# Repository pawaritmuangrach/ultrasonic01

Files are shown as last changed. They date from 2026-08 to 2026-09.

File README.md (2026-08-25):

# Ultrasonic 40 kHz TDOA — จากต้นแบบ 1 TX + 2 RX สู่ Array แทน LiDAR

หลักการและที่มาของสูตรทั้งหมดอยู่ใน [`US015_TDOA_Codex_Spec.md`](US015_TDOA_Codex_Spec.md) เอกสารนี้สรุปเฉพาะสิ่งที่จำเป็นต่อการต่อวงจร รัน และตีความผลลัพธ์

หัวข้อ 1-6 คือต้นแบบเริ่มต้น (1 TX + 2 RX บน Arduino Nano) ที่ build/upload/ทดสอบจริงแล้ว — ถ้าต้องการภาพรวม
การออกแบบขั้นสูงขึ้น (Y-array, MIMO, ทำไม phased array ใช้ไม่ได้, เปรียบเทียบ Nano/ESP32) ข้ามไปหัวข้อ
**[7. จากต้นแบบ TDOA สู่การออกแบบ Ultrasonic Array เต็มรูปแบบ](#7-จากต้นแบบ-tdoa-สู่การออกแบบ-ultrasonic-array-เต็มรูปแบบ-y-array--mimo)** ได้เลย

## 1. Wiring

```
US-015 board 1 (มีตัวส่ง T และตัวรับ R1)
  VCC  -> 5V
  GND  -> GND
  TRIG -> Nano A2
  ECHO -> Nano A0

US-015 board 2 (ถอด/ปิดหัวส่ง ใช้เฉพาะตัวรับ R2)
  VCC  -> 5V
  GND  -> GND
  TRIG -> Nano A2   (สาย TRIG ต่อร่วมกับบอร์ด 1)
  ECHO -> Nano A1
```

A0/A1/A2 ถูกใช้เป็นขา **digital** ล้วน (PC0/PC1/PC2) ไม่มีการเรียก `analogRead()` กับ ECHO เพราะ ECHO เป็นสัญญาณ LOW/HIGH ไม่ใช่ waveform 40 kHz จริง

### 1.1 กรณีใช้ทรานสดิวเซอร์ดิบ (ไม่มี comparator ในตัว)

ถ้าฮาร์ดแวร์ของคุณเป็นทรานสดิวเซอร์ดิบต่อตรงเข้า A0/A1 (ไม่ใช่โมดูล US-015/HC-SR04 สำเร็จรูปที่มีวงจรขยาย+comparator ในตัว) **จะใช้งานไม่ได้** เพราะสัญญาณจาก piezo รับเป็น AC ระดับ mV เท่านั้น ขา digital input จะไม่เห็น echo จริง ต้องเพิ่มวงจร analog front-end ต่อหน้า A0/A1 แต่ละช่อง ประกอบด้วย 4 สเตจ (ทรานซิสเตอร์ NPN ทั่วไป 4 ตัว/ช่อง):

1. ขยายสัญญาณ 2 สเตจ (common-emitter amplifier, AC-coupled)
2. Envelope detector (ใช้ขา Base-Emitter ของทรานซิสเตอร์อีกตัวแทนไดโอด + ตัวเก็บประจุ)
3. Threshold switch (ทรานซิสเตอร์อีกตัวทำหน้าที่เทียบระดับแทน comparator IC)

วงจรนี้ **output จะ idle ที่ HIGH แล้วลง LOW เมื่อพบสัญญาณ** (กลับด้านกับโมดูลสำเร็จรูป) โค้ดมี flag `ECHO_ACTIVE_LOW` (ตั้งเป็น 1 ไว้แล้วในไฟล์ .ino) เพื่อรองรับ polarity แบบนี้ — ถ้าเปลี่ยนไปใช้โมดูลสำเร็จรูปจริงในอนาคต ให้ตั้งกลับเป็น 0

แนะนำจัดวางแบบสมมาตรสำหรับ calibrate:

```
R1        T        R2
|---------|---------|
      แผ่นสะท้อนเรียบ 30-50 cm ด้านหน้า
```

## 2. Flash และเปิด Serial

1. เปิด `ultrasonic_tdoa_nano/ultrasonic_tdoa_nano.ino` ด้วย Arduino IDE, เลือกบอร์ด "Arduino Nano" / processor ATmega328P (เก่า ถ้า upload ไม่ผ่านให้ลอง "ATmega328P (Old Bootloader)")
2. Upload
3. เปิด Serial Monitor/Serial Plotter ที่ **115200 baud** — หรือใช้หน้าเว็บ simulation ใน `simulation/index.html` แทน (ดูหัวข้อ 6)

ค่าเริ่มต้นของ output คือ **CSV** (ส่ง `s` ทาง Serial เพื่อสลับเป็น human-readable)

Header ของ CSV:

```
timestamp_ms,r1_pulse_us,r2_pulse_us,r1_cm,r2_cm,raw_dt_us,calibrated_dt_us,path_diff_cm,angle_deg,confidence,status,cycle_shift
```

ตัวอย่างบรรทัดข้อมูล:

```
1250,212.5,230.5,3.64,3.95,18.0,18.0,0.617,7.10,91,VALID,0
```

Human-readable (หลังส่ง `s`):

```
R1=212.5us 3.64cm | R2=230.5us 3.95cm | raw_dt=18.0us | calibrated_dt=18.0us | path=0.617cm | angle=7.10deg | confidence=91 | status=VALID | cycle_shift=0
```

## 3. Serial Commands

| คำสั่ง | ผลลัพธ์ |
|---|---|
| `c` | เริ่ม calibration (เก็บ ~200 samples แล้วหา median offset ของ raw dt) — **ต้องวางอุปกรณ์สมมาตรตามรูปด้านบนก่อนส่งคำสั่งนี้** |
| `p` | พิมพ์ parameters ปัจจุบัน (sound speed, spacing, offset, output mode) |
| `r` | ล้าง median-filter / cycle-slip history |
| `s` | สลับ CSV <-> human-readable |
| `t25` | ตั้งอุณหภูมิ 25 °C แล้วคำนวณความเร็วเสียงใหม่ |
| `d5.0` | ตั้ง receiver spacing เป็น 5.0 cm |

## 4. สมการหลัก

```
pulse_us          = fall_tick - rise_tick   (Timer1, 0.5 us/tick)
distance_cm       = pulse_us * c / 2                      (ระยะแบบ pulse-echo ปกติ)
raw_dt_us         = pulse2_us - pulse1_us
calibrated_dt_us  = raw_dt_us - calibration_offset_us      (+ cycle-slip correction)
path_diff_cm      = calibrated_dt_us * c                   (ไม่หาร 2 เพราะเทียบเส้นทางถึงตัวรับสองตัว)
max_dt_us         = receiver_spacing_cm / c                 (ขอบเขตทางฟิสิกส์)
angle_deg         = asin(path_diff_cm / receiver_spacing_cm) * 180/pi   (เฉพาะเมื่อ status == VALID)
```

`c = 0.0343 cm/us` ที่อุณหภูมิห้อง (ปรับได้ด้วยคำสั่ง `t<celsius>`)

## 5. ข้อจำกัดสำคัญ (อ่านก่อนเชื่อผลลัพธ์)

1. US-015 เป็น black-box — ECHO ที่เห็นคือผลหลัง comparator/threshold ภายในโมดูล ไม่ใช่ raw 40 kHz waveform
2. `raw_dt_us` **ไม่รับประกัน** ว่าเท่ากับส่วนต่างเวลาที่คลื่นมาถึงจริง เพราะแต่ละบอร์ดมี internal delay/threshold ไม่เท่ากัน — ต้อง calibrate (`c`) ก่อนเสมอ
3. Calibration ลบ static offset ได้ แต่ลบ dynamic jitter ไม่ได้ทั้งหมด
4. `cycle_shift != 0` แปลว่าเกิด cycle-slip correction (ค่ากระโดดเป็นทวีคูณของ 25 us) — เป็น heuristic ไม่ใช่การพิสูจน์
5. `angle_deg` ใช้สมมติฐาน far-field / plane-wave ถ้าวัตถุอยู่ใกล้มาก มุมนี้จะไม่แม่น
6. ผลลัพธ์ทั้งหมดควรเรียกว่า **pseudo-TDOA** ไม่ใช่ true TDOA จนกว่าจะเข้าถึง raw receiver signal ได้จริง (ดูหัวข้อ 27 ในสเปก)
7. ไม่ควรใช้ระบบนี้ในงาน safety-critical

## 6. Real-time 2D wave simulation

`simulation/index.html` เป็นหน้าเว็บ (self-contained, ไม่ต้องติดตั้งอะไร) ที่:

- ต่อกับ Arduino ผ่าน **Web Serial API** (Chrome/Edge เท่านั้น) ที่ 115200 baud
- อ่านบรรทัด CSV ทีละแถว แล้ววาดภาพ 2D: ตำแหน่ง T/R1/R2, คลื่นวงกลมที่ขยายตัวออกจาก T ไปกระทบวัตถุ (คำนวณตำแหน่งวัตถุจาก r1_cm และระยะ target->R2 ที่แปลงจาก r2_pulse_us) แล้วมีคลื่นสะท้อนกลับไปหา R1 และ R2 พร้อม timing สัมพัทธ์ตามข้อมูลจริง (สโลว์โมชันเพื่อให้ตามองเห็น)
- มีปุ่ม **Demo mode** สำหรับดูตัวอย่างการทำงานโดยไม่ต้องต่อ Arduino จริง
- **สะสมจุดสะท้อนทุกจุดที่ตรวจพบ** (ไม่ใช่แค่ ping ล่าสุด) เป็นแผนที่จุดสีชมพูบานเย็น (magenta point cloud) คล้าย
  scatter plot ของ SLAM map — จุดที่วัดได้ต่อเนื่องกันและอยู่ใกล้กัน (<15 cm) จะมีเส้นเชื่อมให้ดูเป็นขอบวัตถุ/กำแพงคร่าวๆ
  เอาเมาส์ชี้จุดใดก็ได้เพื่อดูระยะ/มุม/confidence ของจุดนั้น มีปุ่ม "Clear Map" และ "Export Map (CSV)"
  หมายเหตุ: เซนเซอร์ชุดนี้ไม่ได้หมุนสแกนแบบ lidar การจะได้แผนที่ห้องเต็มรูปแบบต้องเลื่อน/หมุนวัตถุหรือตัวเซนเซอร์เอง
  แล้วเก็บผลสะสมไว้ (เหมาะกับ Experiment 4 ในสเปก)

วิธีใช้:

1. อัปโหลดโค้ดลง Arduino Nano และปิด Serial Monitor ใน Arduino IDE ก่อน (พอร์ตใช้ได้ทีละโปรแกรม)
2. เปิด `simulation/index.html` ด้วย **Chrome หรือ Edge** (ดับเบิลคลิกเปิดไฟล์ได้เลย ไม่ต้องมี server)
3. กดปุ่ม "Connect Arduino" แล้วเลือกพอร์ต COM ของ Nano
4. ดูคลื่นวิ่งแบบ real-time ทุกครั้งที่ Arduino ยิงคลื่นออกไป

ถ้าต้องการดูตัวอย่างก่อนต่อฮาร์ดแวร์จริง ให้กด "Demo mode (no hardware)" แทน

---

## 7. จากต้นแบบ TDOA สู่การออกแบบ Ultrasonic Array เต็มรูปแบบ (Y-array + MIMO)

หัวข้อ 1-6 ด้านบนคือต้นแบบเริ่มต้น (1 TX + 2 RX, US-015/front-end แบบ discrete transistor) ต่อมาโปรเจกต์ขยายเป้าหมาย
เป็น **ใช้ ultrasonic array แทน LiDAR** สำหรับ obstacle avoidance ระยะใกล้ (เทรน NN โดยใช้กล้องเป็น ground truth)
หัวข้อนี้สรุปข้อค้นพบและการออกแบบที่ได้จากการสำรวจแนวทางต่างๆ

### 7.1 ทำไมตัวส่งหลายตัว + ตัวรับตัวเดียว (phased array) ใช้ไม่ได้

แนวคิดแรกที่พิจารณาคือใช้ตัวส่งหลายตัวรวมคลื่นเป็นลำแคบแล้วกวาดทิศทาง (transmit beam steering) แต่พบข้อจำกัดทาง
ฟิสิกส์ที่แก้ไม่ได้:

- ที่ 40kHz, c=343 m/s → ความยาวคลื่น **λ ≈ 8.575mm** → ต้องวางตัวส่งห่างกันไม่เกิน **λ/2 ≈ 4.3mm** ถึงจะไม่เกิด
  ลำคลื่นหลอก (grating lobe)
- ทรานสดิวเซอร์ TCT40-16 มีตัวถังจริง **16mm** — ใหญ่กว่าที่ต้องการเกือบ 4 เท่า และไม่มีทางวางให้ใกล้กว่านี้ได้
  เพราะเป็นขนาดจริงของอุปกรณ์ในอากาศ
- ทดสอบด้วยการจำลอง (`simulation/beamforming_compare.html`) ยืนยันว่าที่ระยะ 16mm ยิงพร้อมกันเกิดลำคลื่นแรง
  พร้อมกัน **3 ทิศ** (-32°, 0°, 32°) และถ้าพยายาม steer ไป 20° ด้วยการหน่วงเวลา จะยิ่งแย่ลงเป็น **4 ทิศ**
  (-47°, -11°, 20°, 61°)
- **ปัญหานี้แก้ด้วยซอฟต์แวร์ไม่ได้เลย** เพราะพลังงานเสียงกระจายผิดทิศไปแล้วตั้งแต่ในอากาศ ไม่ใช่ความผิดพลาดของ
  การประมวลผลสัญญาณ

สรุป: ตัวส่งหลายตัวยิงพร้อมกันเพื่อเล็งลำคลื่นไม่ใช่ทางที่ไปได้กับทรานสดิวเซอร์ขนาดนี้

### 7.2 ทางที่เลือกแทน: TDOA (วัดเวลา ไม่ใช่วัดเฟส)

แทนที่จะเล็งลำคลื่นตอนส่ง เปลี่ยนมายิงคลื่นกระจายกว้างครั้งเดียว แล้วใช้ **ตัวรับหลายตัว** ฟังพร้อมกัน คำนวณทิศทาง
จากผลต่างเวลาที่เสียงมาถึงแต่ละตัว (`sinθ = c·Δt/d`) สมการนี้มีคำตอบเดียวเสมอ (วัดเวลา ไม่ใช่เฟสที่วนซ้ำทุกคาบ)
จึง**ไม่มี grating lobe** — เป็นเหตุผลที่ต้นแบบในหัวข้อ 1-6 ใช้สถาปัตยกรรมนี้มาตั้งแต่แรก

กฎของ aperture ก็กลับด้านจาก phased array: ความละเอียดเชิงมุม `θ_res ≈ λ/D` → **ยิ่งตัวรับกระจายกว้าง (D ใหญ่)
ยิ่งแยกมุมได้ละเอียด** ตรงข้ามกับ phased array ที่ต้องการให้ชิดกัน

### 7.3 ขยายเพิ่มด้วย MIMO (coded TX หลายตัว)

ยิงตัวส่งหลายตัว**พร้อมกัน**โดยแต่ละตัวใช้ code ต่างกัน (แยกด้วย matched filter ฝั่งรับ) จะได้เส้นทางข้อมูล
(TX→วัตถุ→RX) แยกกันได้ = จำนวน TX × จำนวน RX (virtual array, ตำแหน่งเสมือน = ตำแหน่ง TXi + RXj) — ได้ข้อมูล
เพิ่มแบบ**ทวีคูณ**จากอุปกรณ์ที่เพิ่มแบบบวก และยังยิงครั้งเดียวจบเหมือนเดิม (ไม่ช้าลง เพราะยิงพร้อมกัน) ต่างจาก
การยิงตัวส่งทีละตัว (reciprocity ให้ข้อมูลเท่ากันแต่ช้ากว่า 6 เท่าและวงจรซับซ้อนกว่า จึงไม่คุ้ม)

### 7.4 ผังที่แนะนำ: Scaled Array — 3 TX + 9 RX (12 อุปกรณ์จริง, 27 เส้นทางเสมือน)

- **TX1-TX3**: กลุ่มสามเหลี่ยมเล็กกึ่งกลางแผง (รัศมี 14mm จากศูนย์กลาง — ห่างพอให้ตัวถัง 16mm ไม่ชนกัน)
- **RX1-RX9**: 3 แขนมุม 120° (แบบเดียวกับผัง VLA radio telescope เพื่อ sampling มุมสม่ำเสมอทุกทิศ) แขนละ 3 ตัว
  ที่ระยะ **40 / 80 / 140mm** (140mm คือตัวขยายใหม่จากเดิม 40/80mm)
- แต่ละแขนให้ทั้งข้อมูล azimuth (ซ้าย-ขวา) และ elevation (บน-ล่าง) พร้อมกัน
- Diminishing returns: ขยายรัศมี 40→60mm ได้ θ_res ดีขึ้น 2.05° แต่ขยาย 140→160mm ได้แค่ 0.22° (จึงหยุดที่ 140mm)
- Circuit BOM เต็มระบบ: TX driver (TC4427A) 3 ชุด, MCP6024 (quad op-amp, 2 RX/ชิป) 5 ชิป, วงจร VREF 2.5V 1 ชุด
  (ใช้ร่วมกันได้ทุกช่อง)

### 7.5 ข้อจำกัดของแพลตฟอร์มควบคุม (Nano / ESP32 / ESP32+ADS1115)

| แพลตฟอร์ม | RX สูงสุดที่ใส่ได้จริง | จับ raw chirp 40kHz ได้ไหม | MIMO coded TX |
|---|---|---|---|
| Arduino Nano | ≤6-7 (จาก 8 ขา A0-A7) | ไม่ได้ (ADC มัลติเพล็กซ์ช้าเกิน) → ใช้ envelope+threshold แทน | ไม่ไหว |
| ESP32 เดี่ยว | 8 (ADC1) | ได้ (DMA ~100-500kS/s) | ได้ 3 ตัวเต็มรูปแบบ |
| ESP32 + ADS1115 | 8 + 4 (I2C) | เฉพาะช่อง ESP32; ADS1115 ช้าเกิน (860 SPS) ใช้ได้แค่ envelope | ได้ 3 ตัว |

**สรุป**: ผัง 3TX+9RX เต็มรูปแบบต้องใช้ ESP32+ADS1115 แบบ hybrid (RX 8 ช่องแรกจับ raw waveform ผ่าน ESP32,
RX "far" 140mm ที่เหลือจับแค่ envelope ผ่าน ADS1115) — Nano ทำได้แค่ 1TX+6RX แบบ envelope เท่านั้น

### 7.6 เครื่องมือ visualization ทั้งหมด (self-contained, เปิดตรงจากไฟล์ได้)

| ไฟล์ | ใช้ทำอะไร |
|---|---|
| `simulation/index.html` | Real-time 2D wave + point-cloud map จากข้อมูล serial จริง (หัวข้อ 6) |
| `simulation/beamforming_compare.html` | เปรียบเทียบ interference pattern 2-TX ที่ระยะห่างต่างกัน (λ/2 vs 16mm vs steered) — ที่มาของข้อสรุปข้อ 7.1 |
| `simulation/sparse_array_layout.html` | ผัง L-shape sparse receiver บนโต๊ะ (สำหรับทดลองเก็บข้อมูล + กล้องเป็น ground truth) |
| `simulation/front_array_plate_layout.html` | ผังหน้าแผง Y-array รุ่นแรก (1 TX + 6 RX) พร้อม difference co-array |
| `simulation/mimo_virtual_array_layout.html` | สาธิต MIMO virtual array (3 TX + 4 RX ตัวอย่าง) เทียบกับผัง 1TX+6RX |
| `simulation/scaled_array_layout.html` | ผังสุดท้าย 3TX+9RX เต็มรูปแบบ + diminishing returns + เทียบ 3 แพลตฟอร์ม (7.4-7.5) |
| `diagnostics/r1_basic_test/r1_basic_test.ino` | สเก็ตช์ทดสอบเปล่า (`pulseIn()`) ใช้แยกว่าปัญหา R1 ค้างที่ 4.6cm เป็นที่ฮาร์ดแวร์ ไม่ใช่เฟิร์มแวร์ |

### 7.7 ข้อจำกัดที่ยังเหลืออยู่

**Cycle slip**: คลื่น 40kHz คาบ 25µs ถ้าวัดเวลาไม่แม่นพอ ระบบอาจสับสนว่าจับคลื่นลูกไหน (ค่ากระโดดเป็นก้อนละ ~25µs
— ปรากฏการณ์เดียวกับที่เจอจริงตอน calibrate ฮาร์ดแวร์ในหัวข้อ 2-3) ต่างจาก grating lobe ตรงที่**แก้ได้** ด้วย:

1. Chirp + Pulse Compression (แผนระยะยาว) — กวาดความถี่แทนโทนเดียว ทำให้วัดเวลาคมขึ้นมาก
2. วางตัวรับแบบ sparse/non-redundant — ความกำกวมของแต่ละคู่ตกคนละมุม ไม่ทับกัน
3. Neural Network + กล้องเป็น ground truth — เรียนรู้ล้างส่วนที่เหลือจากข้อมูลจริง

**ข้อจำกัดที่ต้องยอมรับ**: อัลตราโซนิกในอากาศไม่มีวันเทียบ LiDAR ได้ในเรื่องระยะไกล (สิบ-ร้อยเมตร) และความละเอียด
ระดับ mm — เป้าหมายที่สมจริงคือใช้แทนได้เฉพาะบริบท obstacle avoidance ระยะใกล้ (<5-10m) เท่านั้น

---

## 8. ESP32 build log — Stage 1

บันทึกสิ่งที่**วัดได้จริง**บนฮาร์ดแวร์ ไม่ใช่ค่าออกแบบ ทุกตัวเลขในหัวข้อนี้มาจากการวัดด้วย
`esp32_selftest.ino` + `tools/scope_view.py` บนบอร์ด ESP32-D0WD-V3 rev 301 ที่ COM5

### 8.1 สถานะ

| งาน | สถานะ |
|---|---|
| เครื่องมือ (arduino-cli, Python, scope_view) | ✅ |
| พิสูจน์ ADC ต่อเนื่อง 2 MS/s | ✅ |
| ภาคส่ง TX driver Version A | ✅ |
| **ภาครับ RX front-end 1 ช่อง** | ✅ |
| `esp32_scope.ino` (ยิง burst + เก็บคลื่น) | ✅ |
| เห็น echo หลายก้อนในหนึ่งช็อต | ✅ |
| ระยะเลื่อนตาม `t = 2d/c` เมื่อขยับแผ่นสะท้อน | ⬜ |

### 8.2 ADC ต่อเนื่อง — สมมติฐานที่เสี่ยงที่สุดของโปรเจกต์

ทั้งโครงการตั้งอยู่บนข้อสมมติว่า ESP32 สตรีม ADC1 ได้ระดับ MS/s ผลจริง:

| ขอ | ได้จริง | % |
|---|---|---|
| 1,000,000 S/s | 976,400 | 97.6% |
| 1,500,000 S/s | 1,464,200 | 97.6% |
| 2,000,000 S/s | 1,951,900 | 97.6% |

เปอร์เซ็นต์คงที่ทั้งสามค่า แปลว่าเป็น**ค่าโสหุ้ยคงที่ ไม่ใช่เพดาน** — แผน Stage 3
(6 ช่อง × 325 kS/s) จึงใช้ได้จริง

### 8.3 RX front-end — ผลวัดหลังแก้จนนิ่ง

โครงสร้าง: `TCT40-16R → Cin 100nF → 2 สเตจ non-inverting เกน 10.3/สเตจ → R 2.2k + C 1nF → GPIO34`
ไฟเลี้ยง 3.3V, VREF 1.65V จากตัวแบ่ง 10k/10k + บัฟเฟอร์

| ตัวชี้วัด | ค่าที่วัดได้ |
|---|---|
| จุดปฏิบัติการ DC ที่ขาออก | 1.521-1.523 V นิ่งทุกเฟรม |
| ฮัม 50 Hz ที่ขาออก | 3.5 mV |
| พื้นเสียงรบกวน 30-50 kHz | 3.2 mV ที่ขาออก = **30 µV ที่ขาเข้า** |
| จุดอิ่มตัว | 1167 mV rms = 11 mV ที่ขาเข้า |
| ช่วงไดนามิก | **51 dB** |
| ตัวอย่างที่ชนราง (16,000 ตัวอย่าง) | 0 |

> DC 1.52 V ไม่ใช่ความผิดพลาด — ADC ของ ESP32 อ่านต่ำกว่าจริงราว 7% ที่ช่วงกลางสเกล
> `1.65 × 0.923 = 1.523` ตรงกับที่วัดได้ ต้องคาลิเบรตก่อนใช้ค่าสัมบูรณ์

**ทดสอบตอบสนองอัลตราโซนิก** (เขย่าพวงกุญแจห่าง ~10 cm):

| | พลังงานย่าน 30-50 kHz |
|---|---|
| ห้องเงียบ | 3.2 mV |
| เขย่ากุญแจ | 337.4 mV (**105 เท่า**) |

หลักฐานที่หนักแน่นกว่าความแรงคือ**ความถี่**: กุญแจให้เสียงกว้าง แต่ยอดที่จับได้ทุกเฟรมตกอยู่ที่
36.07 / 37.31 / 37.33 / 37.35 / 38.00 / 38.04 / 38.07 / 40.70 kHz — เกาะกลุ่มในย่านเรโซแนนซ์
ของ TCT40 ทั้งหมด ถ้าเป็นเพียงสัญญาณรบกวน ยอดจะกระจายแบบสุ่มทั่วย่าน

### 8.4 ปัญหาที่เจอจริงและวิธีวินิจฉัย

บันทึกไว้เพราะทั้งสี่ข้อจะกลับมาอีกตอนขยายเป็น 6 ช่อง

| อาการ | สาเหตุจริง | วิธีที่ชี้ตัวได้ |
|---|---|---|
| ขาออกแกว่งเต็มราง 3.3 Vpp ที่ 50 Hz | **รางไฟบนบอร์ดทดลองถูกตัดขาดกลางแผ่น** ครึ่งล่าง (ตัวแบ่ง VREF, C 10µF, Cg, C_out, คาปาบายพาส) ไม่มีทั้งไฟและกราวด์ กลายเป็นเสาอากาศรับไฟบ้าน แล้ว C 10µF ป้อนเข้า VREF ตรงๆ | ย้ายสายวัดไปที่รางกราวด์เอง — อ่านได้ 0.556 V แกว่ง 3.3 Vpp ซึ่งเป็นไปไม่ได้ถ้าต่อถึงกราวด์จริง |
| แยกไม่ออกว่าวงจรเสียหรือสายวัดลอย | — | อ่านขาที่**ไม่ได้ต่ออะไรเลย** (GPIO36/39) เทียบ ได้ 22 mV เทียบกับ 2093 mV จึงยืนยันว่าวงจรสร้างสัญญาณจริง |
| ไม่รู้ว่าเป็นการแกว่งเองหรือรับจากภายนอก | ฮัมจากภายนอก | ดูค่าดิบ: 98.5% ของตัวอย่างเป็น 0 หรือ 4095 เป๊ะ ฮาร์มอนิก 49/146/244/342 Hz อัตราส่วน 1 : ⅓ : ⅕ : ⅐ = คลื่นสี่เหลี่ยมที่ถูกตัดยอด ไม่ใช่การแกว่งของ op-amp |
| ออปแอมป์ตัวที่ 4 ที่ไม่ได้ใช้ | ขา 12 (ขาออก) ต่อลงกราวด์ = ลัดวงจร ส่วนขา 13/14 ลอย | อินพุต CMOS ที่ลอยจะทำตัวเป็นตัวเปรียบเทียบรับไฟบ้าน — **ออปแอมป์ที่ไม่ได้ใช้ต้องต่อเป็นวงจรตามแรงดัน**: ขาออก↔อินพุต− และอินพุต+ ลงกราวด์ |

**บทเรียนที่ใช้ซ้ำได้**: ตอนที่ `Cg` เปลี่ยนเป็น 1nF เกนที่ 50 Hz เหลือ 1.03/สเตจ ทำให้ขาออกของ
สเตจ 1 กับสเตจ 2 ให้ค่า**เท่ากันเป๊ะทุกหลัก** (2093.5 กับ 2093.7 mV) ทั้งที่สเตจ 2 ควรขยาย
สเตจ 1 อีก 10 เท่า — ความผิดปกตินี้เองที่ชี้ว่าปัญหาอยู่**เหนือ**ทางขยายขึ้นไป คือที่ VREF
การเปลี่ยนอะไหล่ครั้งนั้นไม่ได้แค่แก้ฮัม แต่เปลี่ยนวงจรให้กลายเป็นเครื่องมือวินิจฉัยด้วย

### 8.5 คำสั่งที่ใช้วัดซ้ำได้

```bash
python tools/scope_view.py --port COM5 --dc --probe 34 --rate 200000 --samples 8000
```

### 8.6 ผลยิงจริงครั้งแรก — ภาคส่ง + ภาครับ ครบวงจร

เฟิร์มแวร์ `esp32_array/esp32_scope/esp32_scope.ino` ยิง burst 8 รอบที่ 40 kHz ออก GPIO25
แล้วเก็บคลื่นจาก GPIO34 ที่ 500 kS/s หน้าต่าง 48 ms (= ระยะ 8.2 m)

**หนึ่งช็อตเห็นวัตถุ 8 ก้อน** (แปลงเป็นระยะจากผลต่างกับพัลส์ตรง):

| t (ms) | ห่างจากพัลส์ตรง | ระยะ | ยอด |
|---|---|---|---|
| 1.436 | — | พัลส์ตรง (t=0) | 49.0 mV |
| 3.789 | 2.352 ms | 40.3 cm | 74.3 mV |
| 4.394 | 2.957 ms | 50.7 cm | 26.0 mV |
| 6.155 | 4.718 ms | 80.9 cm | 81.9 mV |
| 7.709 | 6.273 ms | 107.6 cm | 35.8 mV |
| 8.300 | 6.864 ms | 117.7 cm | 41.9 mV |
| 8.925 | 7.489 ms | 128.4 cm | 29.3 mV |

**ความถี่พาหะที่วัดได้** (พารามิเตอร์บิน 61 Hz จากการประมาณค่าพาราโบลา): พัลส์ตรง 40.94 kHz,
เอคโค่ 41.03 / 41.83 kHz — อยู่ในกรอบ 40 ±1 kHz ตามเกณฑ์ และบอกด้วยว่า**เรโซแนนซ์จริงของคู่
ทรานสดิวเซอร์นี้อยู่ที่ ~41 kHz ไม่ใช่ 40 kHz พอดี** ลองสั่ง `s 41000` ดูอาจได้แรงขึ้นฟรีๆ

**SNR ของเอคโค่ที่ 40 cm = 29.5 dB** (พื้นหลัง 2.82 mV) เกณฑ์ Stage 1 ต้องการ ≥10 dB ที่ 50 cm

### 8.7 ทำไม t = 0 ต้องอ่านจากพัลส์ตรง ไม่ใช่จากเวลาที่ซอฟต์แวร์สั่งยิง

ยิงซ้ำ 8 ครั้งติดกัน วัดเวลามาถึงของพัลส์ตรง (ระยะทางคงที่ ไม่ควรขยับเลย):

| | ค่า |
|---|---|
| ตำแหน่งที่เฟิร์มแวร์ตั้งใจให้ยิง (`p 200`) | 0.200 ms |
| ตำแหน่งจริงเฉลี่ย | **1.454 ms** |
| ความคลาดเคลื่อนคงที่ | **1.25 ms = ระยะผิด 21 cm** |
| การกระจายรอบค่าเฉลี่ย | 24.3 µs (ช่วง 74 µs) |

ความคลาดเคลื่อนคงที่ 1.25 ms เกิดจาก DMA ของ ADC วิ่งอิสระ — ตอนที่เฟิร์มแวร์ล้างบัฟเฟอร์แล้ว
เริ่มนับ ตัวอย่างแรกที่ได้จริงไม่ได้เกิดขึ้น ณ วินาทีนั้น **ถ้าเชื่อเวลาของซอฟต์แวร์ ทุกระยะจะเพี้ยนไป
21 cm** แต่พอวัดเทียบกับพัลส์ตรงในข้อมูลเอง ความคลาดเคลื่อนนี้หักล้างหมดเกลี้ยง เพราะมันเข้าไป
อยู่ในทั้งสองพจน์เท่ากัน

วัดระยะซ้ำ 8 ครั้งกับวัตถุเดียวกันได้ **40.6 cm ± 7.3 mm**

> ข้อสังเกตที่สำคัญต่อ Stage 2: การกระจายของ**ผลต่าง** (42.4 µs) แย่กว่าการกระจายของ
> **เวลาสัมบูรณ์ของเอคโค่** (37.5 µs) ทั้งที่การลบควรหักสิ่งที่ร่วมกันออก แปลว่าตัวจำกัดความแม่น
> ตอนนี้**ไม่ใช่**การสั่นของทริกเกอร์ แต่เป็นการหายอดของเอนเวโลปซึ่งหยาบเกินไป —
> เอนเวโลปของพัลส์ที่ผ่านทรานสดิวเซอร์ Q สูงกว้างเป็นมิลลิวินาที ยอดจึงเลื่อนไปมาได้เอง
> Stage 2 ที่ใช้ cross-correlation บนเฟสจะแก้ตรงนี้ ไม่ใช่การไปไล่แก้ทริกเกอร์ให้นิ่งขึ้น

### 8.8 โซนบอด — ความยาว burst เปลี่ยนระยะที่อ่านได้

วางแผ่นสะท้อนที่ 20 cm นิ่งๆ แล้วเปลี่ยนเฉพาะความยาว burst อย่างเดียว:

| รอบ | ยอดพัลส์ตรง | เวลาไต่ขึ้น | ระยะที่อ่านได้ | SNR |
|---|---|---|---|---|
| 1 | 676 mV | 43 µs | 5.1 cm | 15.7 dB |
| 2 | 627 mV | 160 µs | 6.0 cm | 22.3 dB |
| 3 | 987 mV | 210 µs | 10.5 cm | 28.7 dB |
| **4** | 907 mV | 229 µs | **19.5 cm** | 29.6 dB |
| 6 | 1373 mV | 295 µs | 22.5 cm | 34.4 dB |
| 8 | 1575 mV | 377 µs | 23.9 cm | 37.7 dB |

**แผ่นไม่ได้ขยับ สิ่งที่ขยับคือหางเสียงของตัวส่ง** TCT40 เป็นเรโซเนเตอร์ Q สูง ยิงยาวขึ้น
หางก็ยาวขึ้น อะไรที่มาถึงใต้หางนั้นจะถูกอ่านช้ากว่าจริงหรือหายไปเลย

นี่คือ **โซนบอด (blind zone)** ซึ่งเป็นข้อจำกัดเชิงกายภาพ ไม่ใช่บั๊ก:

```
โซนบอด ≈ (ความยาว burst + เวลาหางลง) × c / 2
4 รอบ → เคลียร์ที่ ~15 cm     8 รอบ → เคลียร์ที่ ~24 cm
```

แลกกันตรงๆ: **burst สั้น = เห็นของใกล้ได้ · burst ยาว = SNR ดีกว่า ~8 dB**
คำสั่ง `b <cycles>` เปลี่ยนได้ตอนรัน ไม่ต้องแฟลชใหม่

> ข้อนี้กระทบการออกแบบแผงใน Stage 4 โดยตรง: ยิ่งหัวส่งกับหัวรับอยู่ใกล้กันและยึดบนวัสดุแข็ง
> เดียวกัน พัลส์ตรงยิ่งแรงและหางยิ่งยาว โซนบอดก็ยิ่งกว้าง — เป็นเหตุผลเชิงตัวเลขที่ต้องใส่
> ยางรองแยกทรานสดิวเซอร์ออกจากแผง ไม่ใช่แค่ "ทำแล้วดี"

### 8.9 ประกอบใหม่บนผัง ESP32 คร่อมกลางสองบอร์ด — ผลวัดภาครับ

ย้ายจากผังเดิม (ESP32 ต่อด้วยสายจั๊ม ~40 เส้น รางไฟสองฝั่ง) มาเป็น **ESP32 เสียบขาตรงคร่อม
กลางบอร์ดสองอันบนแผ่นฐานเดียว** บอร์ดซ้าย = RX (ฝั่งขา ADC) บอร์ดขวา = TX (ฝั่งดิจิทัล)
ผังต่อสายชุดใหม่อยู่ที่ `hardware/diagrams/rxv2_*.svg` สร้างจาก `hardware/rx_layout_v2.py`

| | บอร์ดเดิม | บอร์ดใหม่ | |
|---|---|---|---|
| ไบแอสขาออก | 1521 mV | **1521.4 mV** | ADC อ่านต่ำกว่าจริง 7.7% จาก 1650 |
| ฮัม 50 Hz | 3.5 mV | **2.11 mV** | ดีขึ้น 40% |
| ตัดยอด | 0 | **0** | |
| พื้นเสียงรบกวน 30-50 kHz | 3.2 mV | **2.84 mV** | ห้องเงียบ |

ฮัมที่ลดลงสอดคล้องกับการที่กราวด์กลายเป็น star ground ที่ตัว DevKit จริงๆ — RX กับ TX
ใช้ขา GND คนละขา กระแสพุ่งของ TX จึงไม่วิ่งผ่านรางกราวด์ของ RX
(เลขที่เกี่ยวข้อง: กระแสพุ่ง TX 53 mA × ความต้านทานรางร่วม ~30 mΩ = 1.6 mV อนุกรมกับ
ขาเข้า RX ซึ่งเสียงสะท้อนที่ 50 cm อยู่ที่ 0.24 mV ที่ขาเข้า — แรงกว่าสัญญาณ 7 เท่า)

**ทดสอบว่าได้ยินจริง** (เขย่าพวงกุญแจ 6 ช็อตติดกัน):

| ย่าน | เงียบ | เขย่ากุญแจ | เท่า |
|---|---|---|---|
| 1-10 kHz | — | 2.15 mV | |
| 10-25 kHz | — | 2.59 mV | |
| **30-50 kHz** | **2.84 mV** | **111.9 mV** | **39×** |
| 50-80 kHz | — | 12.9 mV | |

ยอดเด่นล็อกอยู่ที่ **38.2 / 40.4 / 41.6 kHz** ตรงย่านเรโซแนนซ์ของ TCT40 พอดี และ
**ในย่านแรงกว่านอกย่าน 43 เท่า** — ตัวกรองนี้มาจากตัวทรานสดิวเซอร์เอง ไม่ใช่จากวงจร

> ⚠️ แอมพลิจูดของการเขย่ากุญแจ**ไม่ซ้ำรอย** หกช็อตในการเขย่าครั้งเดียวได้ 48-112 mV
> (ต่างกัน 2.3 เท่า) จึงใช้เทียบ "มี/ไม่มีสัญญาณ" ได้ แต่**ใช้วัดเกนไม่ได้** ตัวเลข 337 mV
> ของบอร์ดเดิมกับ 112 mV ของบอร์ดใหม่ไม่ได้บอกว่าเกนต่างกัน — บอกแค่ว่าเขย่าคนละแรง

### 8.10 Stage 1 ปิดจบ — ภาคส่งบนบอร์ดขวา และการวัดระยะที่ตามสูตรจริง

ผังใหม่: บอร์ดซ้าย = RX · บอร์ดขวา = TX · ESP32 เสียบคร่อมกลาง · ขาขับย้ายไป **GPIO18**
เซ็นเซอร์อยู่บนแผงพิมพ์ 3D: **หัวส่งที่รู A40 หัวรับที่รู A140 ห่างกัน 100 มม.**
(เดิมแผนคือ T1 แต่สายไฟยาวไม่ถึง — ร่องตัดเสียงที่รัศมี 110 มม. เลยอยู่คั่นกลางพอดี)

#### ความผิดพลาดที่ทำให้เสียเวลาไปหนึ่งชั่วโมง

ต่อบอร์ด TX เสร็จแล้ว **ESP32 เงียบสนิท** ไม่ตอบอะไรเลย แม้แต่ข้อความบูตของ ROM

วิธีที่ใช้ไล่: ถอดสายที่เชื่อม ESP32 ออกทั้งหมด → กลับมาทำงาน → เสียบกลับทีละชุด
เจอว่า**สาย 5V คือตัวปัญหา** — ผังภาคส่งเป็นภาพของบอร์ดขวา แต่เขียนกำกับว่า
"5V มาจากบอร์ดซ้าย แถว 60 รู H" ซึ่งอ่านแล้วไปหยิบแถว 60 ของ**บอร์ดที่กำลังดูอยู่**
และแถว 60 ของบอร์ดขวาคือ **CLK — สายนาฬิกาของแฟลชในตัวชิป**

> **บทเรียน**: เลขแถวเดียวกันมีอยู่บนบอร์ดทั้งสองอันและหมายถึงคนละขา ผังที่แสดงบอร์ดเดียว
> จึงห้ามอ้างอิงรูบนอีกบอร์ดด้วยข้อความ — ต้องมีผังที่เห็นทั้งสองบอร์ดพร้อมกัน
> จึงทำ `diagrams/rig_2_esp32_pinmap.svg` ขึ้นมา

อาการ "ศูนย์ไบต์" ยังใช้ตัดสาเหตุได้ด้วย: ถ้า TX0 โดนกดลงกราวด์ ตัวรับจะพ่นไบต์ 0x00 รัวๆ
ไม่ใช่เงียบ — เงียบสนิทแปลว่าสายอยู่ในสถานะพัก คือตัวชิปไม่ทำงานเลย

#### ผลวัด

| | ค่า |
|---|---|
| พื้นเสียงรบกวน | 0.9-1.1 mV |
| ความถี่พาหะของเสียงสะท้อน | **41.72 kHz** |
| พัลส์ตรง TX→RX (100 มม.) | 258 ± 23 µs · 6.4 mV |
| ความเสถียรของขอบขึ้น | **± 6.8 µs = ± 1.2 มม.** |
| SNR ที่ 53 ซม. | **45.6 dB** (เกณฑ์ต้องการ 10 dB) |

**พัลส์ตรงเบากว่าเสียงสะท้อน 59 เท่า และนั่นถูกต้อง** — หัวส่งกับหัวรับหันหน้าไปทางเดียวกัน
เส้นทางตรงจึงอยู่ที่ 90° นอกแกนของทั้งคู่ (≈ −60 dB) ส่วนเสียงสะท้อนอยู่บนแกนทั้งไปและกลับ
เสียแค่การกระจาย 1/r² กับการสะท้อน (≈ −22 dB) ผลต่างที่คำนวณได้ 38 dB = 79 เท่า

#### ระยะเลื่อนตามสูตรจริง

เรขาคณิตเป็นแบบ bistatic (หัวส่ง-หัวรับห่างกัน B = 100 มม.) ระยะทางเดินคือ `√((2d)² + B²)`

| ระยะไม้บรรทัด | ขอบขึ้นที่ควรได้ | วัดได้ | ต่าง |
|---|---|---|---|
| 20 ซม. | 1538 µs | 1522 µs | −2.8 มม. |
| 30 ซม. | 2110 µs | 2036 µs | −12.6 มม. |
| 53 ซม. | 3440 µs | 3531 µs | +15.5 มม. |

`c = 343 m/s` ตายตัว · ค่าคลาดคงที่ **τ₀ = 336 µs** · **rms 11.7 มม. บนช่วง 33 ซม.**

**การทดสอบที่สำคัญที่สุดคือการทำนายล่วงหน้า**: หลังวัดที่ 20 กับ 53 ซม. เสร็จ ล็อกค่า τ₀
แล้วประกาศไว้ก่อนว่าถ้าวางที่ 30 ซม. ขอบขึ้นต้องอยู่ที่ **2093 µs** — วัดจริงได้ **2036 µs**
**พลาดไป 9.8 มม.**

ค่าคลาดเคลื่อน 11.7 มม. ใหญ่กว่าความเสถียร (1.2 มม.) สิบเท่า จึงเป็นความคลาดเชิงระบบ
ไม่ใช่สัญญาณรบกวน — แผ่นสะท้อนยังไม่มีที่ยึด วางแล้วเอียงได้ และวัดด้วยไม้บรรทัดมือถือ
(ผู้ใช้วัดใหม่พบว่าตำแหน่ง "50 ซม." จริงๆ คือ 53 ซม. ตรงกับที่โมเดลทำนายไว้ว่า ~55 ซม.)

> τ₀ = 336 µs มาจากสองส่วน: เวลาไต่ขึ้นของ TCT40 ที่วัดได้เอง 230-240 µs (ระยะจากขอบถึงยอด)
> บวกความคลาดของจังหวะยิงเทียบกับ DMA ที่วิ่งอิสระ ซึ่งเป็นเหตุผลที่หัวไฟล์ `esp32_scope.ino`
> เขียนไว้ตั้งแต่แรกว่า t=0 ที่แท้จริงต้องอ่านจากพัลส์ตรงในข้อมูล ไม่ใช่จากจังหวะที่ซอฟต์แวร์สั่ง

#### เกณฑ์ Stage 1 ครบทั้งสี่ข้อ

| # | เกณฑ์ | ผล |
|---|---|---|
| 1 | เห็นคลื่น 40 kHz ชัด FFT มียอดที่ 40k ±1k | ✅ 41.72 kHz |
| 2 | แยกหางเสียงตัวส่งออกจากเสียงสะท้อนได้ | ✅ พัลส์ตรง 258 µs · สะท้อน 1522+ µs |
| 3 | ขยับแผ่น 20→50 ซม. แล้วตำแหน่งเลื่อนตาม t = 2d/c | ✅ rms 11.7 มม. · ทำนายล่วงหน้าพลาด 9.8 มม. |
| 4 | SNR ที่ 50 ซม. ≥ 10 dB | ✅ 45.6 dB |

### 8.11 ช่องรับที่ 2 — ทำงาน แต่เสียงรบกวนสูงกว่า 3 เท่า

ต่อช่องที่ 2 บนบอร์ดที่สาม ป้อน VREF และกราวด์ข้ามมาจากบอร์ด RX ขาออกเข้า GPIO35

**สิ่งที่ผ่าน**

| | ช่อง 1 (GPIO34) | ช่อง 2 (GPIO35) |
|---|---|---|
| ไบแอส | 1519.9 mV | 1521.5 mV |
| ชนราง | 0 / 0 | 0 / 0 |
| 50 Hz | 0.31 mV | 1.74 mV |
| เห็นเอคโค่ | ใช่ ที่ +2147 µs | ใช่ ที่ +2240 µs |

ไบแอสสองช่องต่างกัน **1.6 mV** พิสูจน์ว่าสาย VREF ข้ามบอร์ดทำงาน และช่องที่ 2 เห็นเอคโค่
ที่เวลาถูกต้อง วงจรใช้ได้

**สิ่งที่ไม่ผ่าน** — วัดเสียงรบกวนของวงจรล้วนๆ (`q` ไม่ยิงเบิร์สต์) ที่ 1 MS/s เฉลี่ย 6 เฟรม

| ย่าน | 10-20k | 30-50k | 60-90k | 90-130k | 130-200k |
|---|---|---|---|---|---|
| ช่อง2/ช่อง1 | 2.95 | 3.61 | 2.64 | 2.88 | 2.76 |

และเอคโค่ของช่อง 2 แรงกว่า **4.04 เท่า** (1359 mV ต่อ 336 mV)

**การวินิจฉัยที่ผิดรอบแรก และวิธีที่จับได้ว่าผิด**

รอบแรกสรุปว่า Rf เป็น 180k แทน 100k เพราะเกนสูงขึ้น 3 เท่า — **ผิด** จับได้ตอนใส่ขั้วของ
ออปแอมป์เข้าไปในโมเดล เกนกับแบนด์วิดท์แลกกันเสมอ ถ้าเกนสูงขึ้น 3 เท่า แบนด์วิดท์ต้องแคบลง
3 เท่า อัตราส่วนจึงต้อง**ตกลงตามความถี่** (โมเดลทำนาย 4.16 ที่ 15 kHz ลงเหลือ 1.22 ที่ 165 kHz)
แต่ที่วัดได้**แบนราบ** ทุกสมมติฐานที่แตะเกนให้ค่าคลาดอย่างน้อย 1.17 ทั้งหมด

> บทเรียน: ฟิตตัวเลขเดียว (อัตราส่วนที่ 40 kHz) ได้คำตอบสวยเสมอ **รูปทรงเทียบความถี่**
> ต่างหากที่แยกสมมติฐานออกจากกัน ถ้ารอบแรกผมพล็อตทั้งแถบก่อนสรุปก็คงไม่พลาด

**คำอธิบายที่เข้ากับข้อมูลทุกตัว: R ไบแอส เป็น 100 kΩ แทนที่จะเป็น 10 kΩ**

| หลักฐาน | R ไบแอส 100k ทำนายว่า | วัดได้ |
|---|---|---|
| เสียงรบกวน | √(100/10) = **3.16 เท่า** | 2.97 เท่า |
| รูปทรงเทียบความถี่ | **แบนราบ** (เสียงความร้อน ไม่เกี่ยวแบนด์วิดท์) | แบนราบ |
| เกน / แบนด์วิดท์ | **ไม่เปลี่ยน** (เกน = 1 + Rf/Zg ไม่มี R ไบแอส) | ไม่เปลี่ยน |
| ความแรงเอคโค่ | **~4 เท่า** ถ้าหัวรับมี Z ราว 50 kΩ | 4.04 เท่า |

หัวรับเป็นแหล่งจ่ายอิมพีแดนซ์สูง R ไบแอสจึงทำตัวเป็นตัวแบ่งแรงดันกับมัน
ค่า 10k ทิ้งสัญญาณไปมาก ค่า 100k ทิ้งน้อยกว่า — สัญญาณแรงขึ้นแต่เสียงรบกวนแรงขึ้นพอกัน
จึงไม่ได้ SNR ดีขึ้นเลย

**โปรเจกต์นี้เคยพลาดตรงนี้มาแล้วครั้งหนึ่ง** — `diagrams/README.md` บันทึกไว้ว่า R ไบแอส
เคยเป็น 100 kΩ แล้วแก้เป็น 10 kΩ ตอนไล่ฮัม 50 Hz ตัว 100k ที่หยิบมาใส่บอร์ดใหม่จึงน่าจะ
เป็นตัวเดิมที่ถอดออกมาแล้ววางปนอยู่

**ต้องแก้ ไม่ใช่คาลิเบรตออก** เพราะเครือข่ายอินพุตที่ต่างกันเปลี่ยน**เฟส**ที่ 40 kHz ด้วย
ไม่ใช่แค่ขนาด และเฟสที่ต่างกันคือ Δt ที่ผิดโดยตรง (1° ที่ 40 kHz = 0.069 µs)

**ผลจริง: R ไบแอสวัดด้วยมัลติมิเตอร์ได้ 10 kΩ — สมมติฐานนี้ก็ผิดอีก**

ตัวจริงอยู่ที่**หัวรับ** ไม่ใช่วงจร จับได้ด้วยการกวาดความถี่พาหะ (`s <hz>` 36-44 kHz)
แล้ววัดยอดเอคโค่ หัวส่งเป็นตัวเดียวกันทั้งสองช่อง ความต่างจึงเป็นของหัวรับล้วนๆ

| ยิงที่ (kHz) | 36 | 38 | 40 | 41 | 42 | 43 | 44 |
|---|---|---|---|---|---|---|---|
| ช่อง 1 (mV) | 63 | 151 | 334 | 380 | 366 | 332 | 263 |
| ช่อง 2 (mV) | 300 | 394 | 930 | 1173 | 1234 | 1200 | 1013 |

**ยอดของช่อง 1 อยู่ที่ 41.27 kHz · ช่อง 2 อยู่ที่ 42.14 kHz · ต่างกัน 874 Hz**

(เป็นค่าต่ำสุดที่เป็นไปได้ เพราะยอดที่วัดคือผลคูณของ TX กับ RX หัวส่งที่ใช้ร่วมกัน
ดึงยอดทั้งสองเข้าหากัน f0 ของหัวรับจริงจึงห่างกันมากกว่านี้)

**ทำไม 874 Hz ถึงเป็นเรื่องใหญ่** กระป๋องพวกนี้ Q สูง เฟสจึงกวาดเร็วรอบเรโซแนนซ์
ที่ Q=20 ความต่าง 874 Hz ให้เฟสต่างกัน 12.9° ที่ 40 kHz = **Δt 0.90 µs = 89% ของงบ Stage 2**
ใหญ่กว่าทุกเรื่องที่เราถกกันมาเรื่องออปแอมป์

**และห้ามย้ายไปยิงที่ความถี่ที่แรงที่สุด**

| ยิงที่ | เฟสต่าง | Δt | ความแรง ช.1 |
|---|---|---|---|
| 38k | −3.2° | 0.22 µs | 151 mV |
| **40k** | −12.9° | **0.89 µs** | 334 mV |
| 41k | −32.6° | **2.26 µs** | 380 mV ← แรงสุด |
| 42k | −42.9° | **2.98 µs** | 366 mV |

**ความถี่ที่ให้สัญญาณแรงที่สุดคือความถี่ที่เฟสเพี้ยนที่สุด** เพราะระหว่างเรโซแนนซ์สองตัว
เฟสของทั้งคู่วิ่งสวนทางกัน ย้ายไป 41.5 kHz เพื่อสัญญาณแรงขึ้น 14% แลกกับ Δt พังไป 2.5 เท่าของงบ
40 kHz ที่ใช้อยู่บังเอิญเป็นจุดที่ดีอยู่แล้ว **ห้ามย้าย**

**ทางแก้: คัดหัวรับ** ไม่ใช่ซ่อมวงจร มี `tools/match_transducers.py` วัด f0 ทีละตัว
บนช่องเดียวกัน บอร์ดเดียวกัน หัวส่งเดียวกัน แล้วจัดชุดที่ f0 ใกล้กันที่สุด

| f0 ต่างกัน | เฟสที่ 40 kHz | Δt |
|---|---|---|
| 874 Hz (ตอนนี้) | 12.9° | 0.90 µs |
| 400 Hz | 7.1° | 0.50 µs |
| 200 Hz | 3.9° | 0.27 µs |

**สามรอบที่เดาผิดติดกัน — Rf, R ไบแอส, แล้วถึงจะเจอหัวรับ** สองรอบแรกเป็นการอนุมาน
ย้อนกลับจากตัวเลขเดียว รอบที่สามเป็นการวัดตัวแปรนั้นตรงๆ ด้วยการกวาดความถี่
บทเรียนคือ เมื่อสมมติฐานเริ่มซับซ้อนขึ้นเรื่อยๆ ให้หยุดอนุมานแล้วไปวัดของจริง

**ยังเทียบเวลาสองช่องไม่ได้** เฟิร์มแวร์อ่านทีละช่อง เวลาที่ต่างกัน 93 µs อยู่ในพิสัย
ความไม่แน่นอนของทริกเกอร์ (±256 µs) ต้องรอเฟิร์มแวร์สองช่องพร้อมกันของ Stage 2

### 8.12 Stage 2 — เฟิร์มแวร์สองช่อง และการวัด Delta-t ครั้งแรก

ขยาย `esp32_scope` ให้อ่านสองช่องพร้อมกัน (`c 34,35`) แทนการเขียนสเก็ตช์ใหม่
เครื่องมือเดิมทุกตัวจึงยังใช้ได้ ผลที่ได้เปิดโปงพฤติกรรมของชิปที่ไม่มีในเอกสาร

**ADC เขียนค่าเดิมซ้ำ เมื่อสั่งเร็วเกินกว่าที่มันแปลงได้**

ดัมพ์คำดิบพร้อมแท็กช่อง (`x`) เห็นชัดว่าที่ 1 MHz ทุกค่าถูกเขียนออกมาสี่ครั้ง
เหมือนกันบิตต่อบิต ที่ 500 kHz สองครั้ง ค่าซ้ำพวกนี้ไม่ใช่ตัวอย่างเพิ่ม

| สั่ง | ซ้ำ | แปลงจริง |
|---|---|---|
| 250 kHz | 1 | 250 kHz |
| 500 kHz | 2 | 250 kHz |
| 1 MHz | 4 | 250 kHz |
| **800 kHz (2 ช่อง)** | **1** | **266 kHz ต่อช่อง** |

**ผลที่วัดมาก่อนหน้านี้ไม่ผิด** การเขียนค่าซ้ำคือ zero-order hold ซึ่งทำให้รูปคลื่น
เป็นขั้นบันได แต่**ไม่เลื่อนแกนเวลา** ระยะและความถี่ที่รายงานไว้ทั้งหมดยังถูกต้อง
สิ่งที่เสียไปคือความละเอียดเชิงเวลา และ `#FRAME` ตอนนี้รายงาน `skew_us` ที่
**วัดจากเวลาจริง** แทนที่จะคำนวณจากอัตราที่สั่ง เพราะชิปไม่ได้ให้ตามที่สั่งเสมอ

ตัวถอดช่องจึงต้องนับ**การเปลี่ยนแท็กช่อง** ไม่ใช่นับคำที่มาถึง และต้องล็อกกับ
ช่องแรกของแพตเทิร์นก่อนเก็บ ไม่งั้นเฟรมที่ DMA ส่งมากลางแพตเทิร์นจะสลับหัวรับ
สองตัวกัน = กลับเครื่องหมายของมุมแบบสุ่ม ซึ่งแย่กว่าพังไปเลย

**ผลวัด Delta-t ครั้งแรก** (`tools/tdoa.py` · 25 ช็อต · 266 kS/s/ช่อง · SNR 44 dB)

| | ค่า |
|---|---|
| Delta-t (เฟส) | 50.4 µs |
| σ ทั้งชุด | 2.52 µs |
| σ ระหว่างช็อตติดกัน | 1.38 µs |
| กระโดดข้ามคาบ | **0 จาก 25** |

**ศูนย์ cycle slip** คือสิ่งที่ต้นแบบ Nano ทำไม่ได้ตลอดทั้งโปรเจกต์ (มี 6 กลุ่ม
ห่างกันกลุ่มละ 25 µs) วิธีสองชั้น - เอนเวโลปหาคาบ เฟสหาตำแหน่งในคาบ - ได้ผล

**ยังไม่ผ่าน 1 µs แต่ตัวจำกัดไม่ใช่วงจร** หลักฐานสามข้อ

1. ค่ามีสหสัมพันธ์กับช็อตถัดไป **0.70** เสียงรบกวนขาวต้องได้ ~0 นี่คือการเลื่อนไหล
2. ระยะที่อ่านได้แกว่ง **10.3 mm** ตลอด 25 ช็อต Delta-t แกว่งตามกันเป็นล็อกสเต็ป
3. ที่ SNR 44 dB เสียงรบกวนความร้อนให้ σ ได้แค่ **0.025 µs** เล็กกว่าที่วัดได้ 100 เท่า

Delta-t ที่แกว่ง 9.1 µs = เป้าขยับข้าง **4.1 mm** ที่ระยะ 32 cm ซึ่งเป็นขนาดที่แผ่น
สะท้อนที่ไม่มีที่ยึดขยับได้สบายๆ **ต้องทำที่ยึดแผ่นสะท้อนก่อนจึงจะวัด σ ได้จริง**

### 8.13 Stage 2 ผ่านเกณฑ์แรก — sigma(Delta-t) = 0.37 us

ยึดแผ่นสะท้อนแล้ววัดใหม่ ผลเปลี่ยนทันที: 26 ใน 30 ช็อตกระจุกอยู่ที่ 7.3-9.1 us
ส่วนอีก 4 ช็อตไปอยู่ที่ -16 us **ห่างกันพอดีหนึ่งคาบพาหะ** การเลื่อนไหลที่เคยเห็น
หายไปหมด เหลือปัญหาเดียวคือ cycle slip

**ที่ยึดแผ่นแก้ปัญหาที่ใหญ่ที่สุดจริง** — สหสัมพันธ์กับช็อตถัดไปหายไป และการแกว่ง
ของระยะที่อ่านได้ยุบลง

**สาเหตุของ cycle slip อยู่ที่ตัวหาค่าหยาบ** เดิมเอาเอนเวโลปของ *สัญญาณ* สองเส้น
มาสหสัมพันธ์กัน ซึ่งแกว่ง sigma 4.5 us เพราะหัวรับสองตัวเรโซแนนซ์ห่างกัน 874 Hz
หางจึงลากไม่เท่ากัน พอค่าหยาบพลาดเกินครึ่งคาบ (12 us) ชั้นละเอียดก็เกาะคาบข้างเคียง
เปลี่ยนมาใช้เอนเวโลปของ **ตัวสหสัมพันธ์** แทน ซึ่งยุบพลังงานทั้งพัลส์มาเป็นยอดเดียว
ความไม่เหมือนกันของหางจึงเฉลี่ยหายแทนที่จะสะสม

**แต่การแก้นั้นยังไม่พอ และเกือบหลอกเราสำเร็จ** ที่หน้าต่าง 600 us ได้ sigma 0.38 us
กับ 0 slip ซึ่งดูเหมือนผ่านสวยงาม — แต่มันเกาะผิดคาบทั้ง 30 ช็อต ค่ากลางอยู่ที่
-16 us แทนที่จะเป็น +7 us

| หน้าต่าง | ค่าหยาบ sigma | ค่ากลาง (ละเอียด) | sigma |
|---|---|---|---|
| 400 us | 13.15 us | -16.47 us | 12.41 us |
| 600 us | - | **-16.10 us (ผิดคาบ)** | **0.38 us** |
| 1000 us | 9.26 us | -16.84 us | 11.70 us |
| **1600 us** | **1.87 us** | **+7.41 us** | **0.37 us** |
| 2400 us | 1.88 us | +6.92 us | 0.37 us |

> **sigma ต่ำไม่ได้แปลว่าถูก** ชุดที่ผิดทั้งชุดก็มี sigma ต่ำได้ สิ่งที่แยกถูกออกจากผิด
> คือการที่คำตอบ**ลู่เข้าหาค่าเดิมเมื่อเปลี่ยนพารามิเตอร์** 1600 กับ 2400 us ให้
> +7.41 และ +6.92 us ตรงกัน และตรงกับกลุ่มใหญ่ของอัลกอริทึมตัวเก่าด้วย

หน้าต่างที่ยาวขึ้นทำให้ค่าหยาบแม่นขึ้นเจ็ดเท่า (sigma 13.15 -> 1.87 us) เพราะจับ
พลังงานของพัลส์ได้ครบ ค่าตั้งต้นของ `tools/tdoa.py` จึงเป็น 1600 us

**ผลสุดท้าย 30 ช็อต ที่ 266 kS/s ต่อช่อง SNR 44 dB**

| | ค่า | เกณฑ์ |
|---|---|---|
| Delta-t | +7.41 us | - |
| **sigma(Delta-t)** | **0.37 us** | **< 1.00 us ผ่าน** |
| cycle slip | **0 จาก 30** | - |
| ความละเอียดเชิงมุมที่ได้ | 0.030 deg | - |

เทียบกับต้นแบบ Nano ที่กระโดดเป็นก้อนละ 25 us หกกลุ่ม ตอนนี้เหลือกลุ่มเดียว
กว้าง 0.37 us **นี่คือจุดที่โปรเจกต์เปลี่ยนจาก pseudo-TDOA เป็น TDOA จริง**

**ยังเหลือในเกณฑ์ Stage 2** ค่าสัมบูรณ์ยังมีออฟเซ็ตของสองช่องปนอยู่ ต้องคาลิเบรต
ด้วยเป้าที่อยู่ตรงหน้าพอดี (Delta-t เชิงเรขาคณิต = 0) แล้วจึงทดสอบซ้าย/กลาง/ขวา
เทียบกับไม้โปรแทรกเตอร์ให้ได้ +-3 deg

### 8.14 คาลิเบรตออฟเซ็ตของสองช่อง — และเหตุผลที่ต้องเลือกคาบจากทั้งชุด

**เป้าที่ลองแล้วไม่ผ่าน** ก่อนจะกลับมาที่แผ่นเรียบ ลองสองอย่างและได้ตัวเลขที่สอนอะไรเยอะ

| เป้า | แอมป์ | SNR | slip | sigma |
|---|---|---|---|---|
| แผ่นเรียบ ~42 cm | 199 mV | 41 dB | 0/30 | **0.38 us** |
| กระดานที่ 69 cm | 165 mV | 39 dB | 5/20 | 12.25 us |
| กระป๋อง d66 ~30 cm | 27 mV | 23.5 dB | 9/20 | 20.14 us |

**กระป๋องอ่อนเกินไป** หน้าตัดสะท้อนกลับของทรงกระบอกน้อยกว่าแผ่นเรียบ 160 เท่าในเชิงกำลัง
ทฤษฎีทำนายว่า 262 mV จะเหลือ 21 mV วัดได้ 18-26 mV ตรงกัน - เป็นการยืนยันสูตร
แต่ก็เป็นการยืนยันว่าคำแนะนำ "ใช้ทรงกระบอกเพราะไม่ต้องเล็ง" นั้นลืมดูงบสัญญาณ

**กระดานที่ 69 cm แรงพอแต่ยังพัง** เพราะมัน**แผ่ยาวในแนวระยะ** 64-80 cm = 930 us
เป้าที่แผ่ยาวทำให้ยอดสหสัมพันธ์กว้าง ค่าหยาบจึงแกว่ง 11 us ชนขอบครึ่งคาบพอดี
**SNR สูงอย่างเดียวไม่พอ เป้าต้องกระชับในแนวระยะด้วย**

จึงเพิ่ม `--gate-cm` เข้า `tools/tdoa.py` เป็นการถาวร ยอดที่แรงที่สุดในบันทึกไม่ใช่เป้าเสมอไป

**ปัญหาที่แท้จริงของ cycle slip: เอนเวโลปกับเฟสวัดคนละอย่าง**

พอกลับมาใช้แผ่นเรียบ SNR 41 dB แต่ยัง slip 11 จาก 30 ค่าหยาบอยู่ที่ 9.4 us
ส่วนค่าละเอียดอยู่ที่ -1.4 กับ +23 us **ค่าหยาบตกกลางระหว่างสองคาบพอดี** จึงโยนเหรียญ

ต้นเหตุคือหัวรับสองตัวที่ f0 ห่างกัน 874 Hz ที่ Q ~20 ยิงที่ 40 kHz

| | ช่อง 1 | ช่อง 2 | ต่างกัน |
|---|---|---|---|
| หน่วงเอนเวโลป (group) | 61.3 us | 29.5 us | **-31.9 us** |
| หน่วงเฟส | 3.54 us | 4.43 us | 0.89 us |

ก่อนหน้านี้เคยสรุปว่า 874 Hz เป็น "แค่ออฟเซ็ตคงที่ calibrate ออกได้" - **จริงสำหรับเฟส
แต่พลาดว่ามันพังการส่งต่อระหว่างชั้นหยาบกับชั้นละเอียด** เพราะ 32 us มากกว่าครึ่งคาบ 12.5 us
วัดจริงได้ 7.5-10.8 us (Q จริงต่ำกว่าที่สมมติ) ซึ่งก็ยังกินขอบเกือบหมด

**ทางแก้: เลือกคาบจากทั้งชุด ไม่ใช่ทีละช็อต** เป้าไม่ขยับระหว่างชุดวัด ทุกช็อตจึงต้อง
ตอบค่าเดียวกัน `resolve()` เริ่มจากค่าหยาบเป็นจุดตั้งต้นแล้ววนให้ทุกช็อตเกาะค่ากลางร่วมกัน
ผลคือ slip 11/30 -> **0/30** และ sigma 11.97 -> **0.38 us**

> ข้อจำกัดที่ต้องรู้: ใช้ได้เมื่อเป้านิ่งกว่าครึ่งคาบ (12.5 us = 7 mm ที่ 42 cm) ตลอดชุด
> ตอนกวาดมุมต้องแยกชุดวัดต่อหนึ่งตำแหน่ง ห้ามขยับกลางชุด

**ตรวจการลู่เข้าก่อนเชื่อ** (บทเรียนจาก 8.13 - sigma ต่ำไม่ได้แปลว่าถูก)

| หน้าต่าง | Delta-t | sigma |
|---|---|---|
| 1200 us | -2.17 us | 0.31 us |
| 1600 us | -1.83 us | 0.21 us |
| 2400 us | -2.31 us | 0.20 us |
| 3200 us | +24.20 us | 0.60 us (หน้าต่างยาวเกินบันทึก เหลือ 9 ช็อต - ทิ้ง) |

**ออฟเซ็ตของคู่ A140/C140 = -2.10 +-0.24 us** เก็บใน `hardware/tdoa_calibration.json`
และ `tools/tdoa.py` โหลดเองอัตโนมัติ ใส่ค่านี้แล้วมุมที่รายงานกับเป้าตรงกลางได้ **-0.03 deg**

ค่านี้รวมทุกอย่างที่ทำให้สองช่องไม่เหมือนกัน และรวมความคลาดของการวางเป้าด้วย
(-2.10 us = 0.17 deg = 1.2 mm ที่ 42 cm ซึ่งเล็กกว่าความแม่นในการวางแผ่นด้วยมือ)
แยกสองอย่างนี้ออกจากกันไม่ได้ที่ระดับนี้ และไม่จำเป็นต้องแยก เพราะเกณฑ์คือ +-3 deg

**สถานะ Stage 2**: เกณฑ์ที่ 1 sigma(Delta-t) < 1 us **ผ่าน** · คาลิเบรตศูนย์ **เสร็จ** ·
เหลือกวาดมุมเทียบไม้โปรแทรกเตอร์ให้ได้ +-3 deg

### 8.15 กล้อง ground truth คือ Orbbec Astra Pro — และมันมองไม่เห็นระยะที่เราวัดอยู่

รายละเอียดกล้องอยู่ในโปรเจกต์พี่น้อง `C:/Users/User/Desktop/claude code/webcam`
(session "ตรวจสอบความลึกกล้อง OpenCV") ซึ่งทำเสร็จไปแล้วและมีของพร้อมใช้

| | |
|---|---|
| ความละเอียด depth | 640x480 @ 30 fps |
| **ช่วงที่ใช้ได้จริง** | **0.6 - 8 m** |
| การเข้าถึง | depth **ไม่ใช่ UVC** (PID_0403) ต้องใช้ไดรเวอร์ + OpenNI2 ของ Orbbec |
| RGB | UVC ปกติ (PID_0501) เปิดด้วย `cv2.VideoCapture` ได้ |
| เครื่องมือที่มีแล้ว | `capture_pairs.py` เก็บคู่ RGB+depth ที่ align แล้ว · `inspect_data.py` |

**ปัญหาที่ต้องแก้ก่อนถึง Stage 7: ช่วงระยะแทบไม่ทับกัน**

ทุกการวัดของโปรเจกต์นี้จนถึงตอนนี้ - 20, 30, 42, 53 cm - **อยู่ในจุดบอดของกล้องทั้งหมด**
structured light อ่านอะไรที่ใกล้กว่า 0.6 m ไม่ได้เลย ได้ค่า 0 เป็นรูโหว่

| ระยะ | SNR อัลตราซาวด์ที่คาด | กล้องเห็นไหม |
|---|---|---|
| 0.42 m | 41 dB | **ไม่เห็น** |
| 0.60 m | 37.5 dB | เห็นพอดีขอบ |
| 1.00 m | 32.1 dB | เห็น |
| 1.50 m | 27.4 dB | เห็น |
| 2.00 m | 23.7 dB | เห็น |

(ประมาณจากแอมป์ ~1/r ของแผ่นเรียบ บวกการดูดกลืนในอากาศ ~1.2 dB/m ที่ 40 kHz ไป-กลับ)

**หน้าต่างที่ทั้งสองระบบเห็นพร้อมกันคือ ~0.6 - 2.0 m** ซึ่งแคบกว่าที่ตั้งใจไว้ใน
เป้าหมายเดิม (obstacle avoidance < 5-10 m) มาก

สิ่งที่ต้องทำก่อนเก็บ dataset

1. ย้ายการทดสอบออกไปที่ 0.6-2 m แล้ววัด SNR จริง ตัวเลขข้างบนเป็นการประมาณ
2. ถ้า SNR ที่ 2 m ไม่ถึง ~30 dB ตัวเลือกคือเพิ่มแรงส่ง (TC4428A ที่ 12V ตาม Stage 6)
   หรือยืดเบิร์สต์ให้ยาวขึ้น ซึ่งแลกกับโซนบอดที่ลึกขึ้น
3. เก็บ dataset เฉพาะช่วงที่ทั้งสองระบบเชื่อถือได้ และใช้ masked loss ข้ามพิกเซลที่
   กล้องอ่านไม่ได้ - บทเรียนนี้โปรเจกต์กล้องเจอมาแล้วและบันทึกไว้

**บทเรียนจากโปรเจกต์กล้องที่ใช้ซ้ำได้เลย**: ฉากที่เก็บมาสามฉากมีโครงสร้างความลึก
เหมือนกันหมด (ใกล้อยู่ซ้าย-ล่าง) โมเดลเลยเรียนทางลัดว่า "ซ้าย = ใกล้" แทนความลึกจริง
ตอนเก็บ dataset อัลตราซาวด์ต้องจงใจสลับตำแหน่งวัตถุให้ทั่ว ไม่งั้นจะเจอปัญหาเดียวกัน

### 8.16 Stage 2 ปิดจบ (ส่วนอิเล็กทรอนิกส์) — และเพดานของการวัดด้วยมือ

หลังคาลิเบรตศูนย์ ทดลองกวาดมุมด้วยการเลื่อนเป้า เจอว่าทุกความคลาดสืบกลับไปที่
**การวางเป้าด้วยมือ ไม่ใช่เซ็นเซอร์**

**บทเรียนใหญ่ที่สุดของ Stage 2: เป้าที่ต้องเล็งวัดมุมไม่ได้** แผ่นเรียบ/โค้งสะท้อนแบบ
กระจก จุดสะท้อนอยู่ที่มุมตกกระทบ = มุมสะท้อน พอเลื่อนแผ่นแล้วเอียงเล็งใหม่ เรากำหนด
จุดสะท้อนเองด้วยการเอียง การเลื่อนจึงไม่มีผล พิสูจน์ด้วยการแก้ย้อน: เลื่อนแผ่นซ้าย 100 mm
จุดสะท้อนจริงขยับแค่ 3 mm ส่วนเลื่อนขวา 100 mm จุดสะท้อนไป 85 mm - ไม่สมมาตรเพราะ
มันตามการเล็ง ทางแก้คือทรงกระบอกตั้งซึ่งสะท้อนรอบตัวจากแกน ไม่ต้องเล็ง เลื่อนแล้ว
จุดสะท้อนไปตามจริง

**แต่ถึงใช้ทรงกระบอก การวางด้วยมือบนโต๊ะก็ยังคลาด** เลื่อน "ขวา 100 mm" ระบบอ่านได้
ว่าข้าง 66 mm + ถอย 30 mm เพราะแกนโต๊ะไม่ตั้งฉากแนวมองพอดี ความคลาดนี้ ~2-3°
เทียบเท่างบทั้งงบ

| | ความแม่น |
|---|---|
| เซ็นเซอร์ (พิสูจน์ซ้ำ 5+ ครั้ง) | 0.05° (sigma 0.4-0.6 us) |
| วางเป้าด้วยมือ + ไม้บรรทัด | ~2-3° |

**เกณฑ์ที่ผ่านชัด** sigma(Delta-t) < 1 us (ได้ 0.36-0.63), ไม่มี cycle slip (0/20-0/30),
ทิศของมุมถูกเสมอ, ขนาดสมเหตุผล **ส่วนอิเล็กทรอนิกส์และอัลกอริทึม TDOA เสร็จสมบูรณ์**

**เกณฑ์ที่เลื่อนไปพิสูจน์ทีหลัง** ความแม่นมุมสัมบูรณ์ ±3° เทียบไม้โปรแทรกเตอร์ ติดที่
การวางเป้าด้วยมือ ไม่ใช่เซ็นเซอร์ - ควรพิสูจน์ด้วยกล้อง Astra (ground truth ระดับ mm)
ซึ่งเป็นเหตุผลที่แผนมีกล้องอยู่แต่แรก ไม่ใช่ด้วยไม้บรรทัด

พัลส์ตรงใช้เป็นศูนย์ไม่ได้ - อ่อนเกิน (SNR 14 dB) และปนเสียงที่เดินผ่านเนื้อ PLA
(เร็วกว่าอากาศ 6 เท่า เส้นทางในแขนสองข้างไม่เท่ากัน) ได้ 67 us แทนที่จะเป็น ~0

### 8.17 Stage 3 — ADC หลายช่องบน ESP32 ยุบแรงมาก แผนเดิมใช้ไม่ได้

ก่อนสร้างฮาร์ดแวร์ 6 ช่อง วัดอัตราแปลงจริงที่ตั้งได้หลายช่อง (ขาไม่ต่อก็สุ่มได้)

| ช่อง | อัตราแปลงรวมจริง | ต่อช่อง | ตัวอย่าง/คาบ 40 kHz |
|---|---|---|---|
| 1 | 1988 kHz | 1988 kHz | 49.7 |
| 2 | 533 kHz | 266 kHz | 6.66 |
| 3 | 267 kHz | 89 kHz | 2.22 |
| 4 | 267 kHz | 67 kHz | 1.67 |
| **6** | **267 kHz** | **44 kHz** | **1.11** |

**อัตรารวมยุบจาก ~2 MHz (1 ช่อง) เหลือ ~267 kHz (ตั้งแต่ 3 ช่อง)** เป็นข้อจำกัดของ
`adc_continuous` บน ESP32 - overhead ของการสลับแพตเทิร์นหลายช่องกินอัตราจนหมด
แผนเดิมเขียนว่า "2 MS/s / 6 = 333 kS/s/ช่อง" ซึ่งอิงอัตราที่สั่ง ไม่ใช่ที่ได้จริง
ที่ 6 ช่องได้แค่ 1.1 ตัวอย่างต่อคาบ วิธีเฟสต้องการ 6+ **สถาปัตยกรรม "6 ช่อง raw
บน ESP32 ตัวเดียว" เป็นไปไม่ได้**

ทางเลือกที่เหลือ (รอผู้ใช้ตัดสิน):

1. **จับคู่ตามลำดับ** อ้างอิง ch0 + หมุนช่องที่สอง ยิงเบิร์สต์ซ้ำต่อคู่ ได้ 266 kHz/ช่อง
   ที่พิสูจน์แล้ว 6 ช่อง = 5 คู่ x 25 ms = 125 ms/เฟรม (8 fps) · 9 ช่อง = 200 ms (5 fps)
   ต้องการฉากนิ่งช่วง 125-200 ms - ดีสำหรับเก็บ dataset วัตถุนิ่ง แต่วัตถุเคลื่อนที่จะเบลอ
2. **หลาย ESP32** 2 ช่อง/ตัว ที่ 266 kHz พร้อมกัน ซิงก์ด้วยสาย TX ร่วม มี ESP32 2 ตัว
   = 4 ช่องพร้อมกัน ครบ 6-9 ต้องซื้อเพิ่ม
3. **ADC ภายนอกแบบ simultaneous-sampling** เปลี่ยนฮาร์ดแวร์เยอะ

การจับคู่ตามลำดับ (ข้อ 1) ใช้ไปป์ไลน์ 2 ช่องที่พิสูจน์แล้วซ้ำได้เลย และเหมาะกับ
งานเก็บ dataset ที่ฉากนิ่ง จึงน่าจะเป็นก้าวแรกที่คุ้มที่สุดก่อนตัดสินใจซื้อ ESP32 เพิ่ม

### 8.18 Stage B — 4 ช่องทำงาน และ "มุม" เรียนได้เป็นครั้งแรก

จาก §8.17 เลือกทางที่ 1 (**จับคู่ตามลำดับ**) — ต่อ RX 4 ตัวเข้า ESP32 ตัวเดียว แล้วยิงสองครั้ง
อ่านทีละคู่ ได้ 266 kHz/ช่องที่พิสูจน์แล้ว โดยไม่ต้องซื้อ ESP32 เพิ่ม ใช้ได้เพราะฉากนิ่งตอนเก็บ
dataset (master/slave อ่านพร้อมกันจริง เลื่อนไปตอนรถวิ่ง)

| คู่ | หัวรับ | GPIO | เบสไลน์ |
|---|---|---|---|
| 1 | A140 / C140 | 35 / 34 | **242 mm** |
| 2 | A80 / C80 | 32 / 33 | **139 mm** |

ช่อง 3-4 ต่อบน MCP6004 ตัวที่สอง บนบอร์ดทดลองอีกแผ่น **ยืมไฟ 3.3V, GND และ VREF
(ที่บัฟเฟอร์แล้ว) ข้ามมาจากบอร์ดเดิม** ไม่ทำตัวแบ่ง VREF ใหม่ — ดู `hardware/rx_frontend.md` §4.2

#### ช่องหนึ่งอ่อนกว่าเพื่อน 3 เท่า — และวิธีไล่หาที่ชี้ตัวการได้จริง

วัดด้วย `collect.py --track` (อ่านระยะ+ความแรงเอคโค่สดทุกช่อง) เจอ g34 ให้ amp 17 ขณะที่
g35 ให้ 50 กับเป้าตัวเดียวกัน **แต่ระยะอ่านถูก (85 vs 82 cm) = สายไม่ขาด**

ไล่ผิดสองรอบก่อนเจอ: เดาว่าเป็นหัวรับ (เรโซแนนซ์ต่างกัน 874 Hz ตาม §8.11) —
**ลองเปลี่ยนหัว 3 ตัว amp ค้างที่ 17 เท่าเดิมทุกตัว** ถ้าเป็นหัวจริง amp ต้องเปลี่ยนตามหัว
จึงตัดออกได้ว่าเป็นวงจร

วิธีที่ชี้ตัวการได้ คือ **ฉีดสัญญาณรู้ค่าแล้ววัดทีละสเตจ** (ESP32 เป็นทั้งเครื่องกำเนิดและสโคป):

```
GPIO26 (DAC, คำสั่ง d 40000) --[100k]--+--> อินพุตช่อง g34   (ถอดหัวรับออกก่อน)
                                       |
                                     [1k]
                                       |
                                      GND          หัววัด = GPIO36 (ขา SP)
```

```bash
python tools/scope_view.py --port COM5 --probe 36 --tone 40000 --no-fire
```

| จุดวัด | ได้จริง | ควรได้ | สรุป |
|---|---|---|---|
| ขา 1 (ออกสเตจ 1) | 116 mVpp | ~116 | ✅ เกน ×11 ปกติ |
| ขา 7 (ออกสเตจ 2) | 262 mVpp | ~1270 | ❌ **เกน ×2.3 ควรเป็น ×11** |

ตัวการคือ **Rf2 เสียบผิดรู** แก้แล้วขา 7 ได้ 1271 mVpp และ **g34 amp 17 → 81**

> **บทเรียน**: อาการ "ช่องอ่อน" มีผู้ต้องสงสัยสามราย (หัวรับ / วงจร / สาย) การเดาแล้วเปลี่ยน
> ของเสียเวลาและเคยพาไปผิดทางสองรอบ **การฉีดสัญญาณที่รู้ค่าแล้ววัดทีละสเตจ ตัดผู้ต้องสงสัย
> ได้ทีละราย** และบอกตำแหน่งที่เกนหายได้ตรงๆ — เพิ่ม `--tone`/`--no-fire` ใน `scope_view.py`
> ไว้ทำซ้ำได้

#### สภาพแวดล้อมการวัด — สองเรื่องที่เปลี่ยนผลมากกว่าวงจร

1. **พื้นกระเบื้องคือกระจกสะท้อน 40 kHz** วางอาเรย์บนพื้นแล้วยิงเฉียดพื้น เอคโค่เป้าจมกับ
   เสียงเด้งพื้น (ยอดที่แรงสุดกระโดดมั่ว SD 34-50 cm ไม่ตามเป้าเลย) → **ยกอาเรย์และเป้า
   พ้นพื้น ~50 cm**
2. **เป้าแบนต้องเล็งทุกครั้ง เป้ากลมไม่ต้อง** ผิวเรียบสะท้อนแบบกระจก (มุมตกกระทบ =
   มุมสะท้อน) เลื่อนไปข้างแล้วไม่หันหน้าเข้าอาเรย์ = เสียงเด้งหลุด ไม่กลับมา ส่วน**ทรงกระบอก
   ตั้ง (ท่อ PVC) สะท้อนกลับได้จากทุกมุมแนวนอน** เลื่อนไปตำแหน่งไหนก็ผลักตรงๆ ได้ ไม่ต้องเล็ง

#### มุมเรียนได้ — และเบสไลน์ยาวคือตัวทำงาน

เก็บ dataset กวาดมุมด้วยท่อ PVC แล้วเทรน (แบ่ง train/val ตามฉาก คนละรอบเก็บ):

| ชุด | เบสไลน์ที่ใช้ | มุม MAE | เทียบ baseline |
|---|---|---|---|
| 2 ช่อง (ang80a/b) | 139 mm | 9.4° | **ชนะ 30%** |
| 4 ช่อง (ang4_a/b) | 139 + 242 mm | **7.3°** | **ชนะ 51%** |

ยืนยันว่าเป็นฟิสิกส์จริง ไม่ใช่บังเอิญ — TDOA เทียบมุมจากกล้อง:

| มุมกล้อง | −26° | −13° | **0°** | +13° | +26° |
|---|---|---|---|---|---|
| lag เบสไลน์ 242 mm | −129 µs | −175 µs | **−14 µs** | +63 µs | +206 µs |

กลาง ≈ 0 · ซ้ายลบ ขวาบวก · โตตามมุม **corr(มุม, TDOA) = +0.64 สำหรับ 242 mm แต่
−0.09 สำหรับ 139 mm** และ corr(มุม, อัตราส่วนแอมป์) = 0.02 → **มุมมาจากเวลาล้วน ไม่ใช่ความแรง**

> **เบสไลน์ยาวชนะขาด และไม่มีข้อเสียที่กลัวไว้** แผนเดิมคิดว่าต้องมีเบสไลน์สั้นมาแก้ความ
> กำกวมข้ามคาบ (coarse-to-fine) **แต่เราหา TDOA จากเอนเวโลป ไม่ใช่เฟสพาหะ จึงไม่มีคาบ
> ให้กำกวมตั้งแต่แรก** เบสไลน์ยาวให้ lag ต่อองศาใหญ่กว่า (±206 vs ±80 µs) = SNR เชิงมุมดีกว่าล้วน
> เบสไลน์สั้นจะมีประโยชน์ก็ต่อเมื่อเปลี่ยนไปใช้เฟสพาหะเพื่อความละเอียดระดับ sub-µs

#### T0 ผิดไป 785 µs — ตัวแก้ที่ให้ผลมากที่สุดของ "ระยะ"

เทียบระยะที่ US อ่านได้กับกล้อง 454 ตัวอย่าง 3 ระยะ พบ **bias คงที่ +13 cm ทุกระยะ**
(ไม่ใช่การกระจาย — เป็นค่าคงที่) แปลว่าเวลาศูนย์ที่ใช้อยู่ (435 µs) น้อยไป

| T0 | ตรงกับกล้อง ±20 cm | MAE |
|---|---|---|
| 435 µs (เดิม) | 78% | 20.0 cm |
| **1220 µs (คาลิเบรตแล้ว)** | **93%** | **9.7 cm** |

1220 µs = เวลาเบิร์สต์ (16 รอบ = 400 µs) + หน่วงเอนเวโลป/ฟิลเตอร์ + ออฟเซ็ตทริกเกอร์
**แยกวัดทีละส่วนยาก แต่คาลิเบรตกับ ground truth ได้ตรงๆ ในขั้นตอนเดียว**

เพิ่ม **range gate 40-250 cm** ตอนหายอดเอคโค่ด้วย — เพราะบางเฟรม argmax ไปเกาะเสียง
สะท้อนใกล้ (เคยอ่านได้ 26 cm ทั้งที่เป้าอยู่ 130 cm) **และมันทำให้มุมพังไปด้วย** เพราะ
หน้าต่างหา TDOA อิงตำแหน่งยอดนี้ ยอดผิด = หน้าต่างผิด

#### ข้อสรุปเชิงออกแบบ: ระยะคำนวณ มุมเรียน

| | ฟิสิกส์ตรงๆ | โมเดลที่เทรน |
|---|---|---|
| **ระยะ** | **9.7 cm** | 16.7 cm |
| **มุม** | (ต้องรวมหลายช่อง) | **7.3°** |

ระยะมาจากเวลาเอคโค่ตรงๆ คาลิเบรตครั้งเดียวจบ — เทรนแล้วแย่กว่าเพราะต้องเดาข้ามระยะ
ที่ไม่เคยเห็น **ML จึงควรมีไว้ทำสิ่งที่คำนวณตรงๆ ไม่ได้ คือมุมและการแยกวัตถุ**

บทเรียนโมเดลที่แลกมาด้วยผลติดลบ: feature 518 มิติ (เอนเวโลปเต็ม 128 จุด × 4 ช่อง)
ทำให้ทำนายแย่กว่าเดาค่าเฉลี่ย **−134%** แก้ด้วย **แยก feature ตามเป้า** (ระยะใช้เวลาเอคโค่
8 มิติ · มุมใช้ TDOA 6 มิติ) เพราะปนกันแล้วต่างฝ่ายกลายเป็น noise ของอีกฝ่าย

รายละเอียดเฟสรถและ dataset อยู่ที่ [`CAR_PLAN.md`](CAR_PLAN.md) และ [`car/README.md`](car/README.md)

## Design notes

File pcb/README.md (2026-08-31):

# pcb — ข้อมูลและลายสำหรับสั่งทำ PCB

ทั้ง TX และ RX สร้างจากวงจรที่ **ต่อบนแผ่นไข่ปลาแล้วใช้งานได้จริง**
ไม่ได้ออกแบบวงจรใหม่ ที่มา: [`../hardware/rx_frontend.md`](../hardware/rx_frontend.md) ·
[`../hardware/tx_driver.md`](../hardware/tx_driver.md) และผังไข่ปลาใน `../hardware/diagrams/`

```bash
python pcb/build.py       # สร้างไฟล์ทั้งหมดใหม่
python pcb/check_out.py   # ตรวจไฟล์ที่จะส่งโรงงาน
```

---

## บอร์ดทั้งสาม

| บอร์ด | ขนาด | ทำอะไร | สั่งกี่แผ่น |
|---|---|---|---|
| **`tx3`** | 66.8 × 38.3 mm | ภาคส่ง 3 หัว จาก 74HCT04 ตัวเดียว | 1 |
| **`rx2`** | 86.8 × 73.8 mm | ภาครับ 2 ช่อง จาก MCP6004 ตัวเดียว | **5** (ได้ 10 ช่อง ใช้ 9) |
| **`vref`** | 68.8 × 51.9 mm | สร้าง 1.65V ครั้งเดียว แจกทุกบอร์ด | 1 |

### ทำไมแยก VREF ออกมาเป็นบอร์ดที่สาม

MCP6004 มี 4 section พอดีกับ 2 ช่องรับ (ช่องละ 2 สเตจ) **ไม่เหลือให้ทำบัฟเฟอร์ VREF**
ผังไข่ปลาเดิมแก้ด้วยการให้ชิปแรกทำแค่ 1 ช่อง แล้วเอา section ที่เหลือไปทำ VREF
ซึ่งทำให้บอร์ดสองแบบไม่เหมือนกัน สั่งทำแล้วยุ่ง

แยกออกมาได้บอร์ดรับที่ **เหมือนกันทุกแผ่น ปั๊มซ้ำได้** และได้ผลพลอยได้ที่สำคัญกว่า:
VREF เป็นจุดเดียวกันจริงทั้งระบบ ถ้าแต่ละบอร์ดสร้างเอง ค่าจะต่างกันตามความคลาด
ของตัวต้านทาน แล้วช่องต่าง ๆ จะมีจุดศูนย์ไม่ตรงกัน — เวลาเทียบความแรงระหว่างช่อง
(ซึ่งคือที่มาของมุม) จะเพี้ยน

---

## ไฟล์ในแต่ละโฟลเดอร์ `out/<บอร์ด>/`

| ไฟล์ | คืออะไร |
|---|---|
| `*-F_Cu.gbr` `*-B_Cu.gbr` | ลายทองแดงด้านบน / ด้านล่าง |
| `*-F_Mask.gbr` `*-B_Mask.gbr` | หน้ากากประสาน (เปิดเฉพาะตรงแป้น) |
| `*-F_Silkscreen.gbr` | ตัวหนังสือและกรอบชิ้นส่วนด้านบน |
| `*-Edge_Cuts.gbr` | เส้นตัดขอบบอร์ด |
| `*.drl` | ตำแหน่งและขนาดรูเจาะ |
| `preview.png` | ภาพตรวจด้วยตา — ม่วง/เขียวเข้ม = แผ่นกราวด์ · เขียวสด = ลายด้านล่าง |
| `assembly.png` | **ผังลงชิ้นส่วน ถือไว้ตอนบัดกรี** |
| `BOM.md` | รายการชิ้นส่วนของบอร์ดนั้น |
| `nets.md` | ตารางว่าขาไหนต้องปี๊บถึงขาไหน ไว้ไล่วัดด้วยมิเตอร์ |

---

## สั่งทำยังไง

zip ไฟล์ `.gbr` กับ `.drl` ของบอร์ดหนึ่งรวมกัน แล้วอัปโหลดที่ JLCPCB / PCBWay / Elecrow

ตั้งค่า: **2 ชั้น · หนา 1.6 mm · ทองแดง 1 oz** — ค่าเริ่มต้นของทุกเจ้าใช้ได้หมด
ไม่มีอะไรพิเศษ ราคาปกติ 5 แผ่นแรกไม่กี่สิบบาท

**ก่อนจ่ายเงิน ให้เปิดดูในตัวดู Gerber ของเว็บนั้นก่อนเสมอ** แล้วเทียบกับ `preview.png`
ถ้าสองภาพไม่เหมือนกัน อย่าสั่ง

### กติกาที่ใช้ออกแบบ (เผื่อไว้เยอะกว่าที่โรงงานทำได้)

| | ค่าที่ใช้ | โรงงานทั่วไปทำได้ |
|---|---|---|
| ลายสัญญาณ | 0.4 mm | 0.13 mm |
| ลายไฟ | 0.8 mm | |
| ระยะห่างขั้นต่ำ | 0.4 mm | 0.13 mm |
| รูเล็กสุด | 0.9 mm | 0.3 mm |
| ทองแดงรอบรู | 0.4 mm | 0.13 mm |

เผื่อเยอะขนาดนี้เพราะสองเหตุผล: สั่งเจ้าไหนก็ผ่านแน่ และถ้าจะกัดเองที่บ้านก็ยังทำได้

---

## ถ้าจะทำเอง (รีดลายลงแผ่นทองแดง)

`tx3` และ `vref` เดินลายอยู่ **ด้านล่างล้วน** (ลายด้านบน 0 เส้น) ทำหน้าเดียวได้เลย
`rx2` มีลายด้านบน 6 เส้น ต้องแทนด้วยสายจัมป์ 6 เส้นบนด้านชิ้นส่วน

พิมพ์ `*-B_Cu.gbr` แบบ **กลับซ้ายขวา** ที่ 1:1 (เปิดด้วย gerbv หรือ KiCad ฟรี)
ข้อแลกเปลี่ยน: ทำเองจะไม่มีแผ่นกราวด์ด้านบน ซึ่งเป็นตัวที่ช่วยเรื่อง noise มากที่สุด

---

## แผ่นกราวด์ — จุดที่ตั้งใจทำเป็นพิเศษ

กราวด์ไม่ได้ลากเป็นเส้น แต่**เททองแดงเต็มทั้งสองด้าน**

วงจรรับขยาย 34 เท่าสองสเตจ = **1,156 เท่า** กระแสกลับของช่องหนึ่งที่วิ่งผ่าน
ลายกราวด์ยาว ๆ จะสร้างแรงดันตกคร่อมที่ช่องอื่นอ่านเป็นสัญญาณ = ครอสทอล์ก
แผ่นกราวด์ให้กระแสกลับวิ่งใต้ลายสัญญาณตรง ๆ วงจึงเล็กที่สุดเท่าที่เป็นไปได้

โปรเจกต์นี้เคยวัดแล้วว่า**เพิ่มสายกราวด์สั้นเส้นเดียวลด noise ได้ 3.3 เท่า** —
นี่คือเหตุผลที่ยอมออกแบบให้ยากขึ้นเพื่อได้แผ่นกราวด์

รอบขากราวด์ทุกขาเว้น **คูกันความร้อน** เหลือซี่เชื่อมสี่ทิศ ถ้าเชื่อมเต็มหน้า
แผ่นทองแดงจะดูดความร้อนจนหัวแร้งธรรมดาบัดกรีขาไม่ติด

---

## การต่อระหว่างบอร์ด

```
        ESP32                      vref
     GPIO18/19/21 ──┐         ┌── 3V3 ──┐
          GND ──────┼─→ tx3   │         ├─→ rx2 (5 แผ่น) J1: 3V3 · GND · VREF
                    │         └── GND ──┘
        +5V ────────┴─→ tx3 JP          rx2 J2: OUT1 · OUT2 · GND ─→ ADC ของ ESP32
```

**ห้ามต่อขาออกของ 74HCT04 (5V) กลับเข้า GPIO ของ ESP32** — พังถาวร ทิศทางมีทางเดียว
ESP32 (3.3V) → อินพุตชิป เท่านั้น

ขา ADC ที่ใช้ได้มีแค่ **ADC1**: GPIO 32, 33, 34, 35, 36, 39 (6 ขา)
ครบ 9 ช่องต้องมัลติเพล็กซ์หรือเพิ่ม ADC ภายนอก — **ยังไม่ได้แก้ในบอร์ดชุดนี้**

---

## วิธีตรวจ

มีตัวตรวจสองชั้น คนละหน้าที่ เพราะพลาดกันคนละแบบ:

1. **`router.verify`** ดู *ลายที่คิดได้* — ขาของเน็ตเดียวกันต่อถึงกันจริงไหม
   และทองแดงคนละเน็ตเข้าใกล้กันเกิน 0.4 mm ไหม โดยอ่านจากทองแดงที่ได้จริง
   ไม่ใช่จากที่ตั้งใจเดิน

2. **`check_out.py`** ดู *ไฟล์ที่จะส่งโรงงาน* — ครบไฟล์ไหม ไวยากรณ์ถูกไหม
   ของอยู่ในขอบบอร์ดไหม

ชั้นที่สองไม่ใช่ของเกิน — **เคยพลาดจริง** ตอนแรกแผ่นกราวด์ถูกต้องในหน่วยความจำ
และตัวตรวจชั้นแรกบอกว่าผ่าน แต่ยังไม่ได้เขียนลงไฟล์ Gerber เลย
บอร์ดที่ผลิตจะไม่มีกราวด์ทั้งที่ทุกอย่าง "ผ่าน"

---

## ข้อจำกัดที่ต้องรู้ก่อนสั่ง

- **ยังไม่เคยผลิตจริง** ไฟล์ผ่านตัวตรวจที่ผมเขียนเอง ยังไม่เคยผ่านโรงงาน
  หรือโปรแกรมดู Gerber ของคนอื่น **เปิดดูในเว็บโรงงานก่อนจ่ายเงินเสมอ**
- **ระยะขาชิ้นส่วนเป็นค่ามาตรฐาน ไม่ได้วัดจากของจริงที่คุณมี**
  โดยเฉพาะคาปาอิเล็กโทรไลต์ 10µF (ใช้ 2.54 mm) และหัวต่อทรานสดิวเซอร์
  ควรวัดของจริงเทียบก่อน
- **ไม่มีผังวงจรแบบรูปวาด** ในโฟลเดอร์นี้ — ผังวงจรอยู่ที่ `hardware/rx_frontend.md`
  และ `hardware/tx_driver.md` ส่วนที่นี่มี `nets.md` (ตารางการต่อ ตรงไปตรงมากว่า)
  กับ `assembly.png` (ผังลงชิ้นส่วน)
- **หัวรับ/หัวส่งต่อผ่านหัวต่อ 2 ขา** ไม่ได้บัดกรีลงบอร์ดตรง ๆ
  เพราะทรานสดิวเซอร์ต้องไปติดบนแผ่นหน้า (`plate_mini`) ไม่ได้อยู่บนบอร์ด
- **ยังไม่แก้เรื่อง ADC ไม่พอ** — ESP32 มี ADC1 แค่ 6 ขา แต่แผนคือ 9 ช่องรับ

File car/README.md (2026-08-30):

# car/ — เก็บ dataset และเทรน

## ระบบปัจจุบัน (ส.ค. 2026)

```
4 ช่องพร้อมกันในการยิงครั้งเดียว · 66 kHz/ช่อง (bandpass sampling)
ระยะ 200 cm · คาบคงที่ 50 ms = 20 fps · เฟรมเสีย 0
กล้อง depth 320x240 · เก็บ 15 fps · ความเหลื่อมกับเซ็นเซอร์ 33 ms
ไม่กรองอะไรตอนเก็บ — บันทึกทุกเฟรมพร้อมค่าคุณภาพติดไปในไฟล์
```

| ใช้เมื่อไหร่ | คำสั่ง |
|---|---|
| **ตรวจระบบก่อนอัด** | `python car/check.py --port COM5` |
| **วัดความเร็ว/คุณภาพเซ็นเซอร์อย่างเดียว** | `python car/sync4.py --port COM5` |
| **อัด dataset ทีละช่วง** | `python car/record.py --port COM5 --name walk --sections 1 --start 1 --minutes 5` |
| **เทรน** | `python car/train_sections.py --name walk --keep-multi` |
| **กฎ rule base (ไม่ใช้ ML)** | `python car/rules.py --name walk --test 1` |
| **โมเดล ML ล้วนจากคลื่นดิบ** | `python car/train_nn.py --test 1` |
| **รันไขว้ทุกช่วง** | `python car/cv_nn.py` |
| **ยืนทดสอบผลสด ๆ (กฎ)** | `python car/predict.py --port COM5` |
| **ยืนทดสอบผลสด ๆ (โมเดล ML)** | `python car/predict.py --port COM5 --model nn` |
| **เล่นย้อน (กฎ)** | `python car/replay.py --section 1` |
| **เล่นย้อน (โมเดล ML)** | `python car/replay.py --section 5 --model nn` |
| **สร้างแคชภาพ depth (ทำครั้งเดียว)** | `python car/mapdata.py` |
| **เทรนโมเดลภาพ depth** | `python car/train_map.py --test 1` |
| **ตรวจว่าโมเดลภาพ depth เห็นอะไรจริง** | `python car/check_map.py` |
| **ดูภาพ depth จากเสียงสด ๆ** | `python car/live_map.py --port COM5` |
| **ดูภาพ depth เล่นย้อน** | `python car/live_map.py --name walk2 --section 1` |
| **แผนที่เรดาร์สด 13 ช่อง (PolarScan)** — อธิบายการเทรนที่ [`explain_polar_model.md`](../explain_polar_model.md) | `python car/live_polar.py --port COM5` |
| **แผนที่เรดาร์ จากข้อมูลที่อัดไว้** | `python car/live_polar.py --replay walk_s5` |
| **อัดเป็นวิดีโอ** | `python car/replay.py --section 1 --save out.mp4` |
| **ดูสด (แผนที่ 2D)** | `python car/live.py --port COM5` |
| **ดูสด (กลุ่มจุดทุกเอคโค่)** | `python car/live2.py --port COM5` |

> **พอร์ตอนุกรมเปิดซ้อนกันไม่ได้** ปิด `check.py` ก่อนรันตัวอื่นเสมอ

### สิ่งที่บันทึกต่อเฟรม

| ไฟล์ | เนื้อหา |
|---|---|
| `us_NNNNNN.npz` | `counts[4 x ~870]` ดิบ 0-4095 · `rate` · `skew_us` · `pins` · `t` · `sync_ms` · **`cam_near_cm`** · **`depth_valid`** |
| `depth_NNNNNN.png` | uint16 มิลลิเมตร 320x240 (0 = อ่านไม่ได้) |

`cam_near_cm` กับ `depth_valid` มีไว้ **คัดกรองตอนเทรน** — ตอนเก็บไม่กรองอะไรเลย
เพราะคัดตอนเก็บคือทิ้งแล้วทิ้งเลย ส่วนคัดตอนเทรนเปลี่ยนใจได้ตลอด

---

## สถานะ (อัปเดตล่าสุด)

| | สถานะ |
|---|---|
| ไปป์ไลน์ เก็บ→feature→เทรน→วัดผล | ✅ ครบเส้น |
| **ระยะ** | ✅ **7.3 cm** จากฟิสิกส์ตรงๆ (T0 คาลิเบรต + ยอดร่วม) — แม่นกว่าเทรน (13.6 cm) |
| **ทิศ (rule base, walk 5 ช่วง)** | ✅ **MAE 4.5-6.2 องศา · ทายโซนถูก 73-88% · ไม่เคยสลับซ้ายเป็นขวา** |
| **ระยะบนชุด walk** | ⏳ ประเมินไม่ได้ — ยืนระยะเดียวตลอด (sd 5.8 cm) ต้องเก็บชุดคาลิเบรตระยะแยก |
| **มุม (TDOA)** | ✅ **11.8°** เฉลี่ยทุกระยะ (baseline 14.8°) · **8.1° ที่ 53 cm** แย่ลงตามระยะเป็น 13.8° ที่ 154 cm |
| **Stage B** (4 ช่อง) | ✅ **ครบ 4 ช่องแข็งแรง** (g34 81·g35 50·g32 89·g33 107) · แก้ 2 เหตุแล้ว: พื้นกระเบื้องสะท้อน (ยกพ้นพื้น+ท่อ PVC) และ g34 เกนตก (**Rf2 เสียบผิดรู** — ไม่ใช่หัวรับ) · เบสไลน์ 242mm+139mm พร้อมเก็บ dataset เต็ม |

**4 ช่องที่ต่อ** — สองบอร์ด สอง MCP6004 (บอร์ดที่สองยืมไฟ+VREF ข้ามมา ดู
`../hardware/rx_frontend.md` §4.2 · ผัง `../hardware/diagrams/rx34_*.svg`):

| GPIO | หัวรับ | บอร์ด | เบสไลน์ |
|---|---|---|---|
| 35 | A140 | 1 | คู่ 1 = **242 mm** ← ตัวทำงานหลักของมุม (corr +0.64) |
| 34 | C140 | 1 | |
| 32 | A80 | 2 | คู่ 2 = **139 mm** (corr −0.09 ในชุดล่าสุด) |
| 33 | C80 | 2 | |

> mapping นี้ไล่สายจริงแล้ว (**GPIO34 = C140 ไม่ใช่ A140** ตามที่เคยจดไว้)

## ไฟล์

| ไฟล์ | หน้าที่ |
|---|---|
| `ultrasonic.py` | เปิด ESP32 ยิงปิงคืนคลื่นดิบ — 2 ช่อง (คู่เดียว) หรือ 4 ช่อง (ยิงสองครั้งทีละคู่) |
| `astra.py` | เปิดกล้อง Astra คืนความลึก (+ ภาพสีถ้าขอ) ยกจาก `../../webcam/` |
| `collect.py` | จับคู่คลื่น+ความลึก เก็บลง `data/<scene>/` |
| `labels.py` | แปลงความลึก → โปรไฟล์เชิงมุม ("อะไรอยู่ตรงไหนข้างหน้า") |
| `features.py` | คลื่นดิบ → เวกเตอร์ feature (เอนเวโลปย่อ + TDOA/อัตราส่วนต่อคู่เบสไลน์) |
| `inspect_data.py` | ตรวจ dataset ก่อนเทรน — สัญญาณระยะ/มุมมีจริงไหม |
| `train.py` | เทรน + เทียบ baseline · แบ่ง train/val ตามฉาก (ซื่อสัตย์) |

## ก่อนเริ่ม

- เสียบ ESP32 (พอร์ต COM) และกล้อง Astra **ตรงเข้าคอม ไม่ผ่านฮับ** (กล้องกินแบนด์วิดท์เยอะ)
- ปิด Serial Monitor / โปรแกรมกล้องอื่นที่จับพอร์ตค้างไว้
- ต้องมี `primesense`, `cv2`, และ redist ของ OpenNI ในโปรเจกต์ `../../webcam` (มีแล้ว)

## ใช้ยังไง

**1. เช็คเซ็นเซอร์** (ไม่เขียนไฟล์):

```bash
python car/collect.py --check --pins 34,35,32,33
```

**2. เช็คว่าวัตถุเป็นเสียงเด่น** (สำคัญ — us range ต้องตรงกับกล้อง ไม่งั้นไปล็อกผนัง):

```bash
python car/collect.py --track --pins 34,35,32,33
```

ต้องขึ้น "ตรง ✓" ถ้า "ผิด ✗ ล็อกฉากหลัง" ให้เล็งอาเรย์ไปที่โล่ง วัตถุหน้าแบนหันเข้า

**3. เก็บ** (โหมด `--shots` ไม่มีหน้าต่าง กันปัญหา GUI ทั้งหมด):

```bash
python car/collect.py --scene c4_d80 --pins 34,35,32,33 --shots 40
```

- `--shots N` เก็บ N ตัวอย่างแล้วออก · `--period 2` วินาทีต่อภาพ (ให้เวลากวาดวัตถุ)
- จอบอก "กวาดไป: ซ้าย/กลาง/ขวา" — เริ่มกล่องซ้ายสุด เลื่อนไปขวาให้พอดีหมดเวลา
- **ภาพสีปิดโดยปริยาย** (DSHOW มักค้าง เราใช้ depth เป็น label) เติม `--rgb` ถ้าอยากได้

**ถ้าต้องเดินไปขยับวัตถุเอง — ใช้ `--auto-still` (แนะนำ เก็บชุดใหญ่)** ไม่ต้องกดปุ่มเลย:

```bash
python car/collect.py --scene d90 --pins 34,35,32,33 --auto-still --expect-cm 90 --min-valid 0.1
```

ไหลงาน: **ขยับวัตถุ → เดินออกจากเฟรม → ยืนนิ่ง 1-2 วิ → มันเก็บเอง → ขยับต่อ** วนไปเรื่อยๆ
(Ctrl-C หยุด · ใส่ `--shots N` ให้หยุดเองเมื่อครบ)

- ตรวจ "ฉากนิ่งหลังมีการขยับ" จาก depth — จึงไม่เก็บตอนคุณยังอยู่ในเฟรม และไม่เก็บ
  ตำแหน่งเดิมซ้ำ (ต้องเห็นการขยับก่อนถึงเก็บรูปถัดไป)
- `--expect-cm 90` = รับเฉพาะเฟรมที่กล้องเห็นของใกล้สุดราว 90±30 cm — กันเฟรมที่ติดคน
  หรือกล้องไปล็อกฉากหลัง (`--tol-cm` ปรับความกว้างได้) · ในข้อมูลเก่ามีเฟรมแบบนี้ 7-9%

**ทุกครั้งที่เก็บ มันบอกตำแหน่งวัตถุ + ความครอบคลุม** เพื่อให้กวาดครบทุกทิศ ไม่กระจุกด้านเดียว:

```
  ✓ [23]   -19° ซ้าย     88cm   ซ้ายสุด:5 ซ้าย:6 กลาง:7 ขวา:3 ขวาสุด:2  ← ขาด ขวาสุด
  ✗ นอกระยะ: กล้องเห็น 197 cm (ซ้ายสุด) — ต้องการ 90±30 cm
```

- ตัวเลขหลังชื่อโซน = เก็บโซนนั้นไปกี่รูป · **`← ขาด` ชี้โซนที่ยังน้อยสุด ให้ย้ายท่อไปตรงนั้น**
- **ซ้าย/ขวาที่แสดง = มุมมองของคุณ (คนวางของ ยืนหน้ากล้อง)** ไม่ใช่มุมกล้อง — กลับด้านให้แล้ว
  เพราะยืนหน้ากล้องเห็นเป็นมิเรอร์ · โซน: ซ้ายสุด >18° · ซ้าย 7..18° · กลาง ±7° · ขวา -7..-18° · ขวาสุด <-18°
  (label ที่เทรนยังเป็นมุมกล้องจริง ไม่แตะ — กลับแค่ข้อความบนจอ)
- ขึ้น `✗ นอกระยะ` = กล้องไม่เห็นวัตถุที่ระยะที่ตั้งใจ (ไปล็อกฉากหลัง หรือคุณยังอยู่ในเฟรม)
  ไม่เก็บให้ ปรับตำแหน่งแล้วขยับใหม่

**หรือกดเองทีละรูปด้วย `--manual` (นิ่งสุด แนะนำถ้า auto-still ล้ม)**:

```bash
python car/collect.py --scene e80 --pins 34,35,32,33 --manual --expect-cm 80 --min-valid 0.1
```

ขยับวัตถุ → **เดินออกจากแนวเซนเซอร์ (ขาด้วย)** → กด ENTER (พิมพ์ q = ออก) · กด ENTER แล้ว
มันเช็คและบอกสถานะทันที:

```
  ✓ [12] ซ้ายสุด -26° 78cm   ซ้ายสุด:3 ซ้าย:2 กลาง:4 ขวา:1 ขวาสุด:2  ← ขาด ขวา
  ✗ นอกระยะ: ขวาสุด 45cm — ต้องการ 80±30 cm · ไม่เก็บ
  ✗ ติดขา/ของใกล้ 2 จุด (กลาง) — เดินออกให้พ้นแล้วกดใหม่
```

`--expect-cm 80` ทำให้เกิดสถานะ "นอกระยะ" (ถ้าไม่ใส่ จะบอกแค่โซน ไม่เช็คระยะ) · ทั้งสองโหมด
(manual/auto-still) จำเป็นเพราะ `--shots` อัตโนมัติตามเวลาจะจับ "ตัวคนเก็บ" = label เพี้ยน

> โหมดหน้าต่าง (SPACE เก็บ) ยังมี (`--scene X` เฉยๆ) แต่ **cv2 บน Windows ล้มบ่อย** (native crash)
> — แนะนำ `--manual` หรือ `--shots` แทน

**4. ตรวจก่อนเทรน · เทรน:**

```bash
python car/inspect_data.py --scene c4_d80
python car/train.py --scenes c4_d80 c4_d110 c4_d140
```

`train.py` แบ่ง val เป็นฉากระยะกลาง (interpolation ยุติธรรม) เมื่อมี ≥3 ระยะ

## รูปแบบไฟล์

- `us_000000.npz` — `counts[ch][sample]` (uint16 0..4095), `rate`, `skew_us`, `pins`, `t`
  (4 ช่อง: ch0,1 = คู่ 34,35 · ch2,3 = คู่ 32,33 — วัด TDOA ภายในคู่เท่านั้น)
- `depth_000000.png` — uint16 มิลลิเมตร, 0 = อ่านไม่ได้
- `meta.json` — สรุปฉาก

## กฎการเก็บที่ต้องจำ (บทเรียนสะสม)

1. **แบ่ง train/val ตามโฟลเดอร์ ไม่ใช่ตามเฟรม** เฟรมติดกันเกือบซ้ำ สุ่มแบ่งจะรั่ว
2. **จงใจสลับตำแหน่ง/ระยะ/ชนิดวัตถุ** ไม่งั้น NN เรียนทางลัด ("ซ้าย=ใกล้")
3. **หลายระยะ = หลายโฟลเดอร์** (d80/d110/d140) ไม่งั้นระยะไม่มีตัวแปรให้เรียน
4. **กวาดมุมให้ครบ ซ้าย-กลาง-ขวา** ในแต่ละระยะ (เคยพลาดเก็บแต่ซ้าย)
5. **วัตถุต้องเป็นเสียงเด่น** เช็ค `--track` ก่อน — อัลตราซาวด์เห็น "เสียงดังสุด" ไม่ใช่
   "ใกล้สุด" ผนังเรียบไกลดังกว่ากล่องเล็กใกล้ ต้องเก็บในที่โล่ง วัตถุหน้าแบน
6. **อาเรย์กับกล้องยึดติดกันแน่น ไม่ขยับระหว่างเก็บทั้งฉาก** ไม่งั้น label เลื่อน
7. **วัตถุต้องเป็นของใกล้จุดเดียว — เดินออกให้พ้น (ขาด้วย!)** ถ้าขาคุณอยู่ในเฟรมที่ระยะ
   พอๆ กับท่อ กล้องจะเลเบล "ขา" แทน "ท่อ" · `--auto-still`/`--manual` เช็ค `near_object_count`
   แล้ว ข้ามเฟรมที่มีของใกล้ 2 จุด และ `train.py` ก็กรองซ้ำอีกชั้น

## บทเรียนฮาร์ดแวร์/ซอฟต์แวร์ที่เจอจริง

**หัวรับหลุด → ช่องดังขึ้น ไม่ใช่เงียบลง** อินพุตออปแอมป์ลอยกลายเป็นเสาอากาศ รับคลื่น
จากตัวส่งแล้วถูกขยาย เห็นเป็นพัลส์ใหญ่ตรงจังหวะยิง แต่ไม่มีเอคโค่ตาม แยกด้วยการเพิ่ม
ความยาวเบิร์สต์ (`b 16`→`b 32`): เสียงจริงแรงขึ้น ไฟฟ้าเหนี่ยวนำนิ่งสนิท · ป้องกันด้วย
strain relief ทุกสายหัวรับ

**อัลตราซาวด์ล็อกฉากหลัง** วัตถุอ่อน (ขวด/ถังโค้ง) แพ้ผนังเรียบไกล → เพิ่มโหมด `--track`

**ขาคนเก็บติดเฟรม = label กำกวม** ถ้าขาอยู่ที่ระยะพอๆ กับเป้า `--expect-cm` (กรองแค่ระยะ)
จับไม่ได้ · เจอ e60 ติด 32% d130 ติด 27% (แต่ d70/d100 ที่เดินออกสุดติดแค่ 1-2%) → เพิ่ม
`near_object_count` นับ 'ก้อนของใกล้ที่แยกกัน' >1 = ข้าม (ทั้งตอนเก็บและตอนเทรน)

**พื้นกระเบื้อง = กระจกสะท้อน 40kHz** วางอาเรย์บนพื้นแล้วยิงเฉียดพื้น เอคโค่เป้าจมกับเสียง
เด้งพื้น (เอคโค่แรงสุดกระโดดมั่ว ไม่ตามเป้า) → **ยกอาเรย์+เป้าพ้นพื้น ~50 cm** และใช้
**ท่อ/ทรงกระบอกตั้ง** เป็นเป้า (สะท้อนกลับทุกมุมแนวนอน ผลักตรงๆ ได้ ไม่ต้องเอียงหาเซนเซอร์
แบบแผ่นเรียบที่เด้งหลุดถ้าไม่ตั้งฉากเป๊ะ)

**ช่องอ่อน: แยก "หัว" กับ "วงจร" ด้วยการลองหัวหลายตัว** เจอช่อง g34 amp ต่ำกว่า g35 ~3 เท่า
ตอนแรกสรุปผิดว่าเป็นหัว/เรโซแนนซ์ (จาก swap test ที่ไม่สะอาด) พอ**ลองหัว 3 ตัว amp ค้าง 17
เท่าเดิมทั้งหมด = ไม่ใช่หัว เป็นวงจรช่องเกนต่ำ** (ถ้าเป็นหัว amp ต้องเปลี่ยนตามหัว) · **อย่าด่วน
โทษหัว ลองหัวหลายตัวก่อน** · ปิดเคส: **ยิงโทน 40kHz (GPIO26 DAC → ÷100 → อินพุต) แล้ววัดทีละ
สเตจด้วย GPIO36** — สเตจ1 ×11 ดี แต่สเตจ2 ×2.3 (ควร ×11) → **ตัวการคือ Rf2 เสียบผิดรู** g34 amp
17→81 · วิธีไล่วัดทีละสเตจนี้ชี้ตัวการได้แม่นกว่าเดา (ดู `tools/scope_view.py --tone --probe`)

**calibrate ซอฟต์แวร์แก้ SNR ไม่ได้** ไม่ว่าต้นเหตุเป็นหัวหรือวงจร การคูณ gain ชดเชยขยาย
noise ขึ้นเท่ากัน SNR เท่าเดิม เอคโค่ที่จมอยู่ก็ยังจม → ต้องแก้ฮาร์ดแวร์ที่ต้นเหตุจริง

**คาลิเบรต T0 กับกล้อง = ตัวแก้ที่ให้ผลมากที่สุดของระยะ** ค่าเดิม 435 µs ทำให้ US อ่านเกินจริง
**+13 cm ทุกระยะ** (bias คงที่ เห็นชัดเมื่อเทียบกับกล้อง 3 ระยะ) แก้เป็น **1220 µs** แล้ว US ตรงกับ
กล้องภายใน 20 cm จาก **78% → 93%** · MAE **20 → 9.7 cm** — ค่านี้คือเวลายิง (เบิร์สต์ 400 µs) +
หน่วงเอนเวโลป/ฟิลเตอร์ + ออฟเซ็ตทริกเกอร์ วัดเองยาก **แต่คาลิเบรตกับ ground truth ได้ตรงๆ**

**range gate ช่วย "มุม" ด้วย ไม่ใช่แค่ระยะ** บางเฟรม argmax ไปเกาะเสียงสะท้อนใกล้ (เคยอ่านได้
26 cm ทั้งที่เป้าอยู่ 130) พอยอดผิด **หน้าต่างหา TDOA ก็ผิดตาม = มุมพัง** จำกัดช่วงค้นหาเป็น
40-250 cm แล้วทั้งระยะและมุมดีขึ้น (18% / 16%)

**ฟิสิกส์ตรงๆ แม่นกว่าโมเดลสำหรับ "ระยะ"** (9.7 cm เทียบโมเดล 16.7 cm ตอนข้ามระยะ) →
ระยะควรคำนวณจากเวลาเอคโค่ ไม่ใช่เรียน · **มุมคือเป้าหมายจริงของ ML** (ต้องรวมหลายช่อง)

**แยก feature ตามเป้า** ระยะใช้เวลาเอคโค่ (8 มิติ) · มุมใช้ TDOA (6 มิติ) — เดิมรวมกัน 518 มิติ
overfit หนัก (−134%) เพราะ envelope เต็มเป็น noise ของมุม และ direction feature กวนระยะ

**`--track` แครช native ตอนอ่านกล้องสด** live `cam.read()` ในลูปเร็วๆ ล้มระดับ native
(try/except Python จับไม่ได้ เด้งกลับ prompt เงียบ) → track ตัดกล้องออก ใช้ US อย่างเดียว
เทียบระยะกับที่วางเป้าจริงเอา (คนรู้อยู่แล้วว่าวางกี่ cm)

**สายจั๊มยาวไม่กระทบ Δt** สัญญาณไฟฟ้าช้าลง ~1 ns/20cm เทียบ Δt เสียงเป็น µs = 1000 เท่า

**กล้องสี DSHOW ค้าง/หลุดเงียบ** → ปิดภาพสีโดยปริยาย ใช้แค่ depth (ซึ่งเป็น label จริง)

**OpenMP ซ้อนกัน (cv2+numpy+OpenNI) crash เงียบบน Windows** → ตั้ง `KMP_DUPLICATE_LIB_OK=TRUE`
ที่หัวไฟล์ก่อน import

**การ import โมดูลกลางคันขณะ OpenNI ทำงาน = ล้ม native** อาการ: กด ENTER แล้วโปรแกรมปิดเอง
· **`faulthandler.enable()` ชี้จุดตายได้ทันที** (ใส่ไว้ที่หัว `collect.py` แล้ว) เจอสองรอบ
คนละโมดูล: `np.percentile` ลาก **`numpy.ma`** มา · `np.savez_compressed` ลาก **`zipfile`** มา
ทั้งคู่ตายที่ `_compile_bytecode` (heap พัง `0xc0000374`)

**ไล่ปิดทีละโมดูลไม่จบ → ใช้ `_warmup()` แทน**: ซ้อมรันเส้นทางจริง (save_sample +
scene_position + near_object_count) ด้วยข้อมูลปลอมหนึ่งรอบ **ก่อนเปิดกล้อง** เพื่อให้ lazy
import ทุกตัวเกิดตอนที่ยังปลอดภัย · วัดแล้วดึงมา 22 โมดูล (zipfile, lzma, bz2, tempfile,
shutil, threading, ...) และหลังจากนั้น **เส้นทางเก็บจริงไม่โหลดโมดูลใหม่อีกเลย** ตามด้วย
`gc.freeze()` ลดงาน GC · เสริมด้วย `labels._percentile5` ที่ใช้ `np.partition` แทน
`np.percentile` (ค่าตรงเป๊ะ — ยืนยันกับ label จริง 211 ช่อง ต่าง 0.0)

> **หลักที่ได้: โค้ดที่รันคู่กับไลบรารี native ต้องโหลดโมดูลให้ครบก่อนเริ่มงานจริง**
> อย่าเชื่อว่า import ครบแล้วเพราะ numpy/cv2 มี lazy import ซ่อนอยู่เยอะ — **ซ้อมรัน
> เส้นทางจริงหนึ่งรอบ** ชัวร์กว่าไล่เดาชื่อโมดูล

**Ctrl-C ระหว่างเก็บ = กล้องค้าง** ถ้าออกโดยไม่ปิดกล้อง รอบหน้าจะล้มเป็น `access violation`
ตอน `create_depth_stream` (ต้องถอด-เสียบสาย USB ถึงหาย) → `main()` ห่อด้วย `try/finally`
ปิด ESP32+กล้องเสมอ และ manual mode จับ `KeyboardInterrupt` แล้ว

**GUI ปุ่ม a/q ไม่ทำงานกับคีย์บอร์ดไทย** (keycode เพี้ยน) → ใช้โหมด `--shots` ไม่มีหน้าต่าง

## อัดต่อเนื่อง (record.py) — วิธีเก็บ dataset แบบใหม่

`collect.py` เก็บทีละช็อตตอนกดปุ่ม (ฉากต้องนิ่ง) · `record.py` **อัดไม่หยุด** คนเลื่อนวัตถุ
ไปมาได้ตลอด กล้อง depth เป็นเฉลยทุกเฟรม แบ่งเก็บเป็นช่วง ๆ เพื่อใช้แบ่ง train/test

```
python car/record.py --port COM5 --name rec       # 4 ช่วง ช่วงละ 5 นาที
python car/train_sections.py --name rec           # เทรน 3 ช่วง ทดสอบ 1 ช่วง
```

### ความเร็วจริง (วัด ส.ค. 2026 — อย่าเชื่อตัวเลขที่คาดเดา)

| ตั้งค่า | 921600 baud | **2 Mbaud (ตอนนี้)** |
|---|---|---|
| 4 ช่อง · 4000 ตัวอย่าง (258 cm) | 2.6 | **5.1** |
| 2 ช่อง · 4000 ตัวอย่าง | 5.2 | **10.3** |
| 4 ช่อง · 2600 ตัวอย่าง (168 cm) | 4.0 | ~7.8 |

**คอขวดคือเวลาส่งข้อมูล ไม่ใช่เซ็นเซอร์**: คลื่นดิบ 4000 ตัวอย่าง x 4 ช่อง x 2 ไบต์ = 16 KB
เฟรมส่งเป็นไบนารีอยู่แล้ว (ไม่ได้เสียกับข้อความ) จึงเหลือทางเดียวคือเพิ่มความเร็วสาย

**แก้แล้ว ส.ค. 2026: เปลี่ยน `Serial.begin` จาก 921600 เป็น 2000000** ในเฟิร์มแวร์
`esp32_scope.ino` และตั้ง `car/ultrasonic.py: BAUD` ให้ตรงกัน -> เร็วขึ้น ~2 เท่า
**โดยเฟรมเสีย 0 เฟรม** และข้อมูลเหมือนเดิมทุกอย่าง (ตรวจแล้ว: อัตราสุ่ม 266 kHz/ช่องเท่าเดิม,
skew 1.877 us เท่าเดิม, ค่าเฉลี่ยดิบ ~1890 counts เท่าเดิม — เทียบกับ npz ที่อัดก่อนเปลี่ยน)
ไฟล์เดิมสำรองไว้ที่ `esp32_array/esp32_scope/esp32_scope.ino.bak921600`

**สองค่านี้ต้องตรงกันเสมอ** ถ้าแฟลชเฟิร์มแวร์เก่ากลับ ต้องแก้ `BAUD` กลับด้วย ไม่งั้นอ่านไม่ออก
ถ้าเจอเฟรมเสียบ่อยให้ลดทั้งคู่เป็น 1500000

เร็วกว่านี้ต้องให้ ESP32 คำนวณเอนเวโลปเองแล้วส่งเฉพาะผลลัพธ์ (~200 จุดแทน 4000)
ซึ่งจะเสียคลื่นดิบไปวิเคราะห์ย้อนหลังไม่ได้ จึงยังไม่ทำ

**ดีเลย์ที่ตัดทิ้งได้ฟรี**: เดิมหน่วง 0.2 วิหลังสั่ง ADC สลับคู่ช่อง วัดที่ 0.20/0.08/0.03/0.00
ได้ 1.3/1.8/2.2/**2.6** fps โดย**เฟรมเสีย 0 ทุกค่า** -> ตั้ง `SWITCH_SETTLE = 0.0` แล้ว

### กล้อง depth
รองรับ **160x120 / 320x240 / 640x480 ที่ 30 fps** และ 1280x1024 ที่ 7 fps เท่านั้น
**ไม่มีโหมด 15 fps** — `--cam-fps 15` จึงเป็นการอ่าน 30 fps แล้วเก็บเว้นเฟรม
depth อ่านในเธรดแยกตลอดเวลา ทุกปิงจึงได้เฟรมสด ๆ (วัดจริง: เหลื่อมเวลาเฉลี่ย **33 ms**)

### ทำไมต้องแบ่ง train/test ตาม "ช่วง" ไม่ใช่สุ่มทีละเฟรม
เฟรมที่ติดกันในเวลาแทบเหมือนกันทุกอย่าง ถ้าสุ่มแบ่ง เฟรมข้างเคียงของเฟรมทดสอบจะไปอยู่ใน
ชุดเทรน = โมเดลเคยเห็นคำตอบมาแล้ว ตัวเลขจะสวยเกินจริง (เคยเจอมาแล้วตอน baseline 1.4 cm)

### เป้าที่ **เคลื่อนที่** (เช่นคนเดิน) — ต้องระวังเรื่องยิงสองรอบ

4 ช่องอ่านพร้อมกันไม่ได้ ต้องยิงสองรอบห่างกัน ~190 ms ซึ่งออกแบบไว้ตอน "ฉากนิ่ง"
ถ้าเป้าเดินอยู่ ระหว่างสองรอบมันขยับไปแล้ว:

| ความเร็ว | ขยับระหว่างสองรอบ | ผล |
|---|---|---|
| 0.25 m/s | 4.7 cm | พอไหว |
| 0.5 m/s (เดินปกติ) | 9.5 cm | **เกินหน้าต่างวิเคราะห์ (±5 cm) -> คู่ที่สองพลาดเอคโค่** |

แก้ด้วย `features.PER_PAIR = True` หรือ `angle_features(..., per_pair=True)` ให้แต่ละคู่
หายอดของตัวเอง (ภายในคู่ ADC สุ่มพร้อมกัน ห่างแค่ 1.25 us จึงไม่มีปัญหาเรื่องเวลาเลย)
`train_sections.py` เทียบทั้งสองโหมดให้อัตโนมัติ จะได้ตัดสินจากข้อมูลจริง ไม่ใช่เดา

`--keep-multi` ปิดตัวกรอง "มีของใกล้หลายจุด" — ตัวกรองนั้นทำไว้ตอนเป้าเป็นท่อ PVC
แล้วขาคนเก็บติดเข้ามาในภาพ ถ้า**คนคือเป้าเอง** ไม่ต้องกรอง

## โหมดใหม่: 4 ช่องพร้อมกัน (`car/sync4.py`) — ใช้ตั้งแต่ ส.ค. 2026

`ultrasonic.Ultrasonic` ยิง 2 รอบ อ่านทีละคู่ · `sync4.Sync4` ยิง **รอบเดียวได้ครบ 4 ช่อง**

| | ยิง 2 รอบ (เดิม) | **4 ช่องพร้อมกัน (ใหม่)** |
|---|---|---|
| ระยะที่เก็บ | 258 cm | **150 cm** |
| อัตราสุ่ม | 266 kHz/ช่อง | 66 kHz/ช่อง |
| ตัวอย่าง/ช่อง | 4000 | **677** |
| ข้อมูล/ปิง | 16 KB | **5.4 KB** |
| **fps (วัดจริง)** | 2.6 -> 5.1 | **23-24** |
| คู่เบสไลน์ที่ใช้ได้ | 2 | **6** |
| เป้าเคลื่อนที่ | คู่ที่สองเพี้ยน | ไม่มีปัญหา |

### ทำไม 66 kHz ถึงใช้ได้ทั้งที่ต่ำกว่า Nyquist ของ 40 kHz
ADC ของ ESP32 มีตัวแปลงตัวเดียว อัตรารวมตันที่ ~266 kHz **ไม่ว่าจะขอเท่าไหร่**
(วัดแล้วที่ f = 500k/800k/1M/1.2M/1.6M/2M ได้ 62-66 kHz/ช่องเท่ากันหมด)
-> ใช้ **bandpass sampling**: 40 kHz พับลงมาที่ 26.4 kHz ซึ่งอยู่ใต้ Nyquist 33.2 kHz
สัญญาณเราเป็นแถบแคบ การพับจึงเป็นแค่การเลื่อนย่าน **เปลือกคลื่นและ TDOA ยังอยู่ครบ**
`features.signal_band(rate)` เลือกย่านกรองให้อัตโนมัติ (ถ้ายังกรอง 25-60 kHz จะได้แต่ศูนย์)

ราคาที่จ่าย: ความละเอียดเวลา 3.76 -> 15 us (~2.1 องศา ซึ่งยังต่ำกว่าความผิดพลาดจริง 11.8 องศา)

### จังหวะยิงคงที่
`Sync4.ping()` **รอให้ครบคาบเสมอ** แม้รอบก่อนเสร็จเร็ว คาบคำนวณจาก
`max(เวลาเสียงไปกลับ x 1.3, เวลาเก็บ + เวลาส่ง) + 3 ms` = **40.3 ms ที่ 150 cm**
เพื่อรับประกันว่าเอคโค่รอบเก่าตายสนิทก่อนรอบใหม่ (ถ้าทับกัน เอคโค่เก่าจะโผล่เป็น
"วัตถุใกล้ปลอม" ตามสูตร ระยะที่ไม่กำกวม = c x คาบ / 2)

### กรองเฉลยที่อยู่นอกระยะ
`record.py` **ข้ามเฟรมที่กล้องเห็นวัตถุใกล้สุดนอกช่วง 40-150 cm** เพราะคลื่นไม่มีข้อมูล
ระยะนั้นเลย (เช่นกล้องเห็นผนังที่ 230 cm) การเก็บไว้เท่ากับสอนโมเดลด้วยคำตอบที่ไม่มีอยู่จริง

## กฎแบบเขียนมือ (`car/rules.py`) — บอกทิศโดยไม่ใช้ ML

ใช้กับข้อมูลที่ **เดินกวาดซ้าย-กลาง-ขวาในช่วงเดียวกัน** เฉลยมาจากกล้องทีละเฟรม
ไม่ใช่จากชื่อช่วง จึงไม่ต้องยืนนิ่งทีละตำแหน่ง

```
python car/record.py --port COM5 --name walk --sections 1 --start 1 --minutes 1   # x5
python car/rules.py --name walk
```

**หลักการ**: `asym = (ฝั่งหนึ่ง - อีกฝั่ง) / (ผลรวม)` จากความแรงเอคโค่ที่ยอดเดียวกัน
หารด้วยผลรวมเพื่อให้ค่าไม่ขึ้นกับระยะ

**ใช้ความแรง ไม่ใช่ TDOA** เพราะที่ 66 kHz ความละเอียดเวลา 15 us และ TDOA พังเมื่อ
หายอดไม่ตรงกัน ส่วนความแรงใช้ได้แม้ยอดเบลอ

**ไม่ล็อกทิศทางไว้ล่วงหน้า** — เครื่องหมายของ asym เทียบกับมุมกล้องหาจากข้อมูลเอง
และรายงาน "ช่องที่แรงสุดในแต่ละโซนมุม" ให้ตรวจว่าสายต่อถูกด้าน ถ้าสลับจะเห็นทันที

ให้ผลสองแบบ: **กฎ 1** แปลง asym เป็นองศาด้วยเส้นตรง · **กฎ 2** แบ่งเป็น 5 โซน
แบ่ง train/test ตามช่วง (กันช่วงสุดท้ายไว้ทดสอบ)

> **หมายเหตุเรื่องเครื่องหมาย** (วัดแล้ว): `cam_deg` เป็น **บวกเมื่อวัตถุอยู่ครึ่งซ้ายของภาพกล้อง**
> อย่าเดาเอง — ให้ดูตาราง "ช่องที่แรงสุดแยกตามโซน" ที่ `rules.py` พิมพ์ออกมาเสมอ

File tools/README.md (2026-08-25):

# เครื่องมือวัดฝั่งคอมพิวเตอร์

ทุกตัวคุยกับเฟิร์มแวร์ `esp32_array/esp32_scope/` ผ่านสายอนุกรม 921600 บอด
**ห้ามเปิด Serial Monitor ของ Arduino IDE ค้างไว้** เพราะมันจับพอร์ตไว้คนเดียว
สคริปต์จะเปิดไม่ได้ทันที

ติดตั้งครั้งแรก:

```bash
pip install -r tools/requirements.txt
```

หาว่าพอร์ตชื่ออะไร:

```bash
python -c "from serial.tools import list_ports; [print(p.device, p.description) for p in list_ports.comports()]"
```

## สคริปต์ทั้งสี่ตัว ใช้ตอนไหน

| ตัว | ยิงคลื่นไหม | ตอบคำถามว่า |
|---|---|---|
| `rx_check.py` | ไม่ | วงจรภาครับปกติดีไหม ไบแอสถูกไหม มีฮัมไหม |
| `echo_profile.py` | ยิง | เสียงสะท้อนกลับมาตอนไหนบ้าง มีกี่ก้อน |
| `echo_range.py` | ยิง | ระยะเท่าไหร่กันแน่ แม่นแค่ไหน |
| `scope_view.py` | ยิง | ขอดูรูปคลื่นจริงๆ เป็นกราฟ (ต้องมีจอ) |

### 1. `rx_check.py` — เช็ควงจรก่อน ไม่ยิงคลื่น

```bash
python tools/rx_check.py --port COM5
```

ตัวแรกที่ควรรันทุกครั้งหลังต่อวงจรเสร็จ ดูสามอย่าง

| บรรทัด | ค่าที่ดี | ถ้าผิดแปลว่า |
|---|---|---|
| ไฟตรง (ไบแอส) | ~1520-1650 mV | ต่ำหรือสูงกว่านี้มาก = VREF หรือ R ไบแอสต่อผิด |
| 50 Hz | < 10 mV | เป็นร้อย mV = กราวด์ขาด หรือ Cg ค่าผิด |
| ชนราง ล่าง/บน | 0 / 0 | ไม่ใช่ 0 = สัญญาณล้น ตัดยอดไปแล้ว |

เช็คช่องที่ 2 ก็เปลี่ยนขา:

```bash
python tools/rx_check.py --port COM5 --pin 35
```

### 2. `echo_profile.py` — ดูภาพรวมว่าเอคโค่อยู่ตรงไหน

```bash
python tools/echo_profile.py --port COM5 --expect-cm 20
```

ยิง 5 ครั้ง เฉลี่ย แล้ววาดกราฟแท่งตามระยะ ผลจะออกมาหน้าตาแบบนี้

```
 ระยะ (cm)   t (µs)        mV  โปรไฟล์
       0.0        0    112.34  ##############################################
       1.7      100     48.21  ####################
      ...
      19.8     1156     11.87  #####
```

แท่งแรกคือ**พัลส์ตรง** ที่วิ่งลัดจากหัวส่งไปหัวรับบนแผ่นเดียวกัน ไม่ใช่เอคโค่
แท่งที่โผล่ขึ้นมาอีกทีตรงระยะที่วางแผ่นสะท้อนไว้ นั่นแหละคือเอคโค่

ท้ายผลจะมี "ยอดเฉพาะที่แรงสุด 5 อันดับ" พร้อม SNR เป็น dB ให้ด้วย

### 3. `echo_range.py` — เอาตัวเลขระยะจริงๆ

```bash
python tools/echo_range.py --port COM5 --expect-cm 20
```

ตัวนี้แหละที่ให้ตัวเลข "วัดได้ 20 cm" ยิง 10 ครั้ง แต่ละครั้งได้ระยะหนึ่งค่า
แล้วรายงานค่าเฉลี่ยกับค่ากระจาย

```
  ยิงที่  1: หน่วงเวลา   1198.3 µs = ระยะ   20.55 cm
  ...
ระยะเฉลี่ย  20.41 cm
กระจาย     1.20 mm  (เวลา 0.07 µs)
```

**"กระจาย" คือตัวเลขที่สำคัญที่สุด** มันบอกว่าถ้ายิงซ้ำโดยไม่ขยับอะไรเลย
คำตอบจะเด้งไปมาเท่าไหร่ ถ้ากระจายไม่กี่ mm แต่ค่าเฉลี่ยเพี้ยนไปเป็น cm
แปลว่าไม่ใช่ปัญหาสัญญาณรบกวน แต่เป็นความคลาดเคลื่อนเชิงระบบ (เช่นแผ่นเอียง)

ถ้าวัดระยะไกลกว่า 40 cm ให้เลื่อนจุดเริ่มค้นหาขึ้นด้วย ไม่งั้นมันอาจไปเจอ
หางของพัลส์ตรง:

```bash
python tools/echo_range.py --port COM5 --shots 20 --min-cm 40 --expect-cm 53
```

### 4. `scope_view.py` — ดูรูปคลื่นเป็นกราฟ

```bash
python tools/scope_view.py --port COM5
```

เปิดหน้าต่าง matplotlib สามแผง: รูปคลื่นดิบ / เอนเวโลป / FFT
ถ้าไม่มี ESP32 อยู่ตรงหน้าก็ลองของปลอมได้:

```bash
python tools/scope_view.py --simulate --distance-cm 30
```

## คำสั่งที่ส่งให้เฟิร์มแวร์ตรงๆ ได้

```bash
python tools/esp32_cmd.py --port COM5 i
```

| คำสั่ง | ทำอะไร |
|---|---|
| `i` | พิมพ์ค่าตั้งทั้งหมดที่ใช้อยู่ |
| `?` | รายการคำสั่ง |
| `r` | ยิงเบิร์สต์แล้วส่งข้อมูลกลับ |
| `q` | เก็บข้อมูลเงียบๆ ไม่ยิง |
| `f 500000` | ตั้งอัตราสุ่มเป็น 500 kS/s |
| `n 24000` | ตั้งจำนวนแซมเปิล |
| `b 8` | ตั้งความยาวเบิร์สต์เป็น 8 รอบ |
| `c 34` | เลือกขา ADC |
| `d 40000` | ปล่อยโทน 40 kHz ออก DAC (GPIO26) ไว้ทดสอบเกน |

## หมายเหตุเรื่อง t = 0

ทั้ง `echo_profile.py` และ `echo_range.py` **ไม่ได้นับเวลาจากตอนสั่งยิง**
แต่นับจากพัลส์ตรงที่อยู่ในข้อมูลเอง

เพราะ ADC ทำงานแบบวิ่งอิสระ (DMA) เฟรมที่ได้จึงเริ่มที่ไหนก็ได้ภายในหนึ่งบล็อก
256 แซมเปิล = คลาดได้ถึง ~256 µs = **4.4 cm** ถ้าใช้เวลาที่สั่งยิงเป็น t=0
ระยะจะเพี้ยนขนาดนั้นทุกครั้งแบบสุ่ม

และเหตุผลที่จัด **ยอดกับยอด** ไม่ใช่ขอบกับยอด: ทั้งพัลส์ตรงและเอคโค่ผ่าน
ทรานสดิวเซอร์ตัวเดียวกัน เวลาไต่ขึ้นราว 230-240 µs จึงเท่ากันทั้งคู่และหักล้าง
กันหมดในผลต่าง ถ้าจับขอบเทียบยอด ระยะจะเกินไปประมาณ 4 cm ทุกครั้ง

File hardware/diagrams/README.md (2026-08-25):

# ผังต่อวงจรบนบอร์ดทดลอง

> ⚠️ **มีผังภาครับสองชุด** ชุด `rxv2_*` คือชุดที่ใช้กับผัง ESP32 เสียบคร่อมกลางสองบอร์ด
> **ให้ยึดชุด `rxv2_*` เป็นหลัก** ส่วนชุด `rx_1..rx_4` เก็บไว้เป็นบันทึกของวงจรที่วัดผลไว้
> ใน README §8.3 — ค่าอุปกรณ์เหมือนกันทุกตัว ต่างกันแค่เลขแถวและตำแหน่งราง

ไฟล์ในโฟลเดอร์นี้คือผังการต่อสายจริงของภาครับ 1 ช่องและภาคส่ง ที่**วัดแล้วว่าทำงานได้**
(ผลวัดอยู่ใน [`../../README.md`](../../README.md) หัวข้อ 8.3) เหตุผลเชิงวงจรว่าทำไมถึงเลือก
ค่าแต่ละตัว อยู่ใน [`../rx_frontend.md`](../rx_frontend.md)

## ไฟล์

| ไฟล์ | ครอบคลุม |
|---|---|
| `rx_1_power_chip_vref.svg` | ไฟเลี้ยงเข้าชิป · สายเชื่อมรางซ้าย-ขวา · ตัวแบ่ง VREF 10k/10k ที่แถว 44 · บัฟเฟอร์ VREF · การจัดการออปแอมป์ตัวที่ไม่ได้ใช้ |
| `rx_2_input_stage1.svg` | ทรานสดิวเซอร์ · Cin · R ไบแอส · สเตจขยายที่ 1 (Rf1 / Rg1 / Cg1) |
| `rx_3_stage2_output.svg` | สเตจขยายที่ 2 (Rf2 / Rg2 / Cg2) · R 2.2k + C 1nF · ขาออกไป GPIO34 |
| `rx_4_rail_bridges.svg` | สะพานข้ามช่องว่างกลางราง — สิ่งที่ผังสามแผ่นแรกไม่ได้แสดง และเป็นต้นเหตุของฮัม 50 Hz |
| `rxv2_1_power_chip_vref.svg` | **เวอร์ชันใหม่** ไฟเลี้ยง · ชิปแถว 12-18 · VREF แถว 9 |
| `rxv2_2_input_stage1.svg` | **เวอร์ชันใหม่** ทรานสดิวเซอร์แถว 5 · Cin · R ไบแอส · สเตจ 1 |
| `rxv2_3a_stage2.svg` | **เวอร์ชันใหม่** สเตจขยายที่ 2 |
| `rxv2_3b_output.svg` | **เวอร์ชันใหม่** R_out · C_out · สายไป GPIO34 แถว 46 |
| `rx2ch_1_power_chip.svg` | **ช่องรับที่ 2** ไฟเลี้ยง · MCP6004 ตัวที่สอง · ออปแอมป์ที่ไม่ใช้ |
| `rx2ch_2_input_stage1.svg` | **ช่องรับที่ 2** อินพุต · สเตจ 1 · VREF ที่รับมาจากบอร์ด RX |
| `rx2ch_3a_stage2.svg` | **ช่องรับที่ 2** สเตจ 2 |
| `rx2ch_3b_output.svg` | **ช่องรับที่ 2** ขาออกไป GPIO35 |
| `rig_2_esp32_pinmap.svg` | **ขา ESP32 ทั้ง 19 คู่ บนบอร์ดทั้งสองอัน** — รูไหนต่อได้ รูไหนห้ามแตะ และสาย 5V ที่ข้ามบอร์ด |
| `rig_1_baseplate_layout.svg` | **ผังจัดวางบนแผ่นฐาน** — ESP32 เสียบคร่อมกลางสองบอร์ด บอร์ด RX ฝั่ง ADC บอร์ด TX ฝั่งดิจิทัล |

### เมื่อย้ายมาเสียบ ESP32 คร่อมกลาง — ผังเดิมยังใช้ได้ แต่เปลี่ยน 4 อย่าง

วงจรไม่เปลี่ยนเลย ค่า R/C ทุกตัวและลำดับการต่อเหมือนเดิมทั้งหมด **สิ่งที่เปลี่ยนคือตำแหน่ง**

| เรื่อง | เดิม | เมื่อเสียบคร่อม |
|---|---|---|
| ขาขับ TX | GPIO25 | **GPIO18** — ย้ายไปหัวต่ออีกฝั่งให้ห่างขา ADC (แก้ใน `esp32_scope.ino` แล้ว) |
| แถวที่ใช้ | RX 14→45 · TX 20→32 | ESP32 กิน 19 แถวติดกันที่ปลายบอร์ด **เลื่อนทั้งวงจรเป็นก้อน** ระยะระหว่างแถวคงเดิม |
| คำว่า "ราง +/−" | มีสองฝั่งให้เลือก | เหลือ**รางขอบนอก**ฝั่งเดียวต่อบอร์ด สายยาวขึ้น แต่ 100nF บายพาสยังต้องอยู่ติดขาชิป |
| กราวด์ | รวมที่จุดเดียว | ใช้ขา GND **คนละขา**สำหรับ RX และ TX — จุดรวมย้ายไปอยู่ในทองแดงของ DevKit |

ไฟ 5V ของบอร์ด TX ยังต้องข้ามมาจากขา 5V ซึ่งอยู่บนหัวต่อฝั่ง ADC — ยอมรับได้เพราะเป็นไฟ DC
และมี 100µF + 100nF รับอยู่ที่ตัว 74HCT04 ปลายทางแล้ว

### แผงอาเรย์

| ไฟล์ | ครอบคลุม |
|---|---|
| `plate_2_mount_section.svg` | รูยึดเซ็นเซอร์แบบแยกการสั่นสะเทือน — โอริง 2 วงในรู ⌀19.5 |
| `plate_3_joint_section.svg` | ข้อต่อดุม–แขน — รูผ่านไม่มีเกลียว สกรู M3 + นอต |
| `plate_5_sensor_map.svg` | **ใส่เซ็นเซอร์ตัวไหนลงรูไหน** — ผังด้านบนพร้อมชื่อรูทุกรู ตัวส่ง/ตัวรับ ทิศ +Y และคู่ที่ต่อสายอยู่ตอนนี้ |
| `print_settings_explained.svg` | ความหมายของ ชั้น 0.2 มม. / ผนัง 4 เส้น / อินฟิล 25% gyroid |

`plate_5_sensor_map.svg` ไม่ได้วาดมือ — `python hardware/plate_sensor_map.py` อ่าน
`plate_coords.csv` ไฟล์เดียวกับที่โค้ดวิเคราะห์ใช้ ภาพกับพิกัดจึงเพี้ยนกันไม่ได้

ผังด้านบนของแผงไม่ได้วาดมือ แต่**เรนเดอร์จาก STL ตัวที่จะพิมพ์จริง** อยู่ที่
[`../cad/plate_preview.png`](../cad/plate_preview.png) สร้างใหม่ทุกครั้งที่รัน
`python hardware/plate_model.py` จึงไม่มีทางไม่ตรงกับไฟล์ที่ส่งไปพิมพ์

### ภาคส่ง

| ไฟล์ | ครอบคลุม |
|---|---|
| `txv2_1_power_chip.svg` | **เวอร์ชันใหม่** ไฟเลี้ยง 5V · 74HCT04 แถว 28-34 · ขาอินพุตที่ไม่ใช้ |
| `txv2_2_gates.svg` | **เวอร์ชันใหม่** GPIO18 → ขา 1 · เกต 3 ตัวต่อขนาน |
| `txv2_3_output.svg` | **เวอร์ชันใหม่** R 47Ω × 2 อนุกรม · หัวส่ง TCT40-16T |
| `tx_1_driver_version_a.svg` | SN74HCT04N แถว 20-26 · เกต 4 ตัวต่อขนาน · ขาที่ไม่ใช้ลงกราวด์ · R อนุกรม · TCT40-16T |

ผังใช้ **R 47Ω สองตัวต่ออนุกรม** (`26i → 29i` และ `29j → 32j`, หัวส่งที่ `32i`) ถ้ามี R 100Ω
ตัวเดียวให้ใช้แทนได้เลยที่ `26i → 30i` แล้วหัวส่งไปที่ `30j`

> ⚠️ ห้ามต่อ 47Ω **ขนาน** (ได้ 23.5Ω) — กระแสพุ่งจะเป็น 130 mA เกินพิกัดของ 74HCT04
> ที่รับได้ 50 mA ต่อตัวถัง เหตุผลเต็มอยู่ใน [`../tx_driver.md`](../tx_driver.md)

> ⚠️ ผังภาคส่งใช้ถึงแถว 32 ซึ่งอยู่ใต้ช่องว่างกลางรางของบอร์ด 60 แถว ถ้าย้ายไปบอร์ดใหม่
> ต้องต่อสะพานข้ามช่องว่างเหมือน `rx_4_rail_bridges.svg` ด้วย

เปิดด้วยเบราว์เซอร์ได้ทันที เป็น SVG จึงซูมได้ไม่แตกและสั่งพิมพ์ขนาดเท่าไหร่ก็คมชัด

## ผังชุดนี้เป็นเวอร์ชันหลังแก้แล้ว

ระหว่างต่อจริงเจอปัญหา 4 จุด ผังในโฟลเดอร์นี้แก้ครบแล้วทั้งหมด ถ้าเทียบกับผังที่เคยส่งใน
บทสนทนาช่วงแรกจะไม่ตรงกัน — **ให้ยึดไฟล์ในโฟลเดอร์นี้เป็นหลัก**

| จุดที่แก้ | เดิม | ปัจจุบัน |
|---|---|---|
| R ไบแอส (`18c → 14c`) | 100 kΩ | **10 kΩ** |
| Cg1 (`31d → 33d`) | 100 nF | **1 nF** |
| Cg2 (`43a → 45a`) | 100 nF | **1 nF** |
| ออปแอมป์ตัวที่ 4 ที่ไม่ได้ใช้ | จัมเปอร์ `20j → 21j` และสาย `22j → ราง −` ทำให้ขา 12 ซึ่งเป็น**ขาออก**ลัดลงกราวด์ | สาย `20j → ราง −` และจัมเปอร์ `21i → 22i` (ขาออกต่อกลับเข้าอินพุต− = วงจรตามแรงดัน) |

สามข้อแรกลดฮัม 50 Hz ที่ขาออกจาก 2093 mV เหลือ 3.5 mV ข้อสุดท้ายกันไม่ให้อินพุต CMOS
ที่ลอยทำตัวเป็นตัวเปรียบเทียบรับไฟบ้าน และกันไม่ให้ชิปกินกระแสลัดวงจรตลอดเวลา

## จุดที่พลาดง่ายที่สุด

**แถว 43 มีของสองตัวคนละคอลัมน์** — `43a` คือ Cg2 (1 nF) ส่วน `43e` คือ Rg2 (10 kΩ) คนละตัวกัน

**รางไฟบนบอร์ด 60 แถวถูกตัดขาดกลางแผ่น** — ผังสามแผ่นแรกวาดรางเป็นแถบยาวต่อเนื่อง ซึ่งไม่ตรงกับ
บอร์ดจริง ต้องดู `rx_4_rail_bridges.svg` ประกอบเสมอ ไม่งั้นของทุกชิ้นที่อยู่ใต้แถว 30
(ตัวแบ่ง VREF, C 10µF, Cg1, Cg2, C_out, คาปาบายพาส) จะไม่มีทั้งไฟและกราวด์

## ภาคส่งบนแผ่นไข่ปลา (3 TX จาก 74HCT04 ตัวเดียว)

| ไฟล์ | เนื้อหา |
|---|---|
| `perf_tx_1_power_chip.svg` | บัส +5V/GND · ซ็อกเก็ต DIP-14 · คาปาบายพาส · TB1 ไฟเข้า |
| `perf_tx_2_gates.svg` | หัวต่อ GPIO · สายเข้าชิป · เชื่อมเกตสองชั้น 3 ชุด |
| `perf_tx_3_outputs.svg` | R อนุกรม 100Ω ×3 · TB2/TB3/TB4 หัวส่ง |

สร้างจาก `hardware/perf_tx_layout.py` · ตรวจวงจรด้วย `hardware/check_tx_netlist.py`
**แผ่นนี้ใช้ไฟ 5V** ต่างจากแผ่นภาครับที่ใช้ 3V3 — ติดป้ายที่ TB1 ให้ชัด

### หมายเหตุ: ช่อง 1 กับช่อง 2 ต่างกันหนึ่งจุด (ส.ค. 2026)

| | ช่อง 1 (`perf_3`) | ช่อง 2 เป็นต้นไป (`perf_6`) |
|---|---|---|
| ขา Cin ด้านหัวรับ | **รู F44 เดียวกับขาสกรู KF301** | **แยก** — โดดสาย F44 → H44 แล้ว Cin ลงคอลัมน์ H |
| โหนด IN | F42-F41 | H42-H41 |
| Rb ไบแอส | F41 → I41 | H41 → K41 |

ช่อง 1 บัดกรีไปแล้วแบบรูรวม (พันขา Cin กับขาสกรูเข้าด้วยกันก่อนเสียบ) **ผังจึงคงไว้
ตามแผ่นจริง** ไม่แก้ย้อนหลัง — ผังที่ไม่ตรงกับแผ่นอันตรายกว่าผังที่ไม่สวย

ช่องใหม่ใช้แบบแยกรู เพราะรูเดียวรับสองขาทำให้รอยบัดกรีนูนจนตัวเทอร์มินอลวางไม่สนิท
และถอดเทอร์มินอลทีต้องรื้อ Cin ด้วย · ทางเดินไฟฟ้าทั้งสองแบบ**เหมือนกันทุกประการ**
(ตรวจแล้วด้วยการไล่โหนด)

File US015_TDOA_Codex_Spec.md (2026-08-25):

# ข้อกำหนดสำหรับพัฒนาโค้ด Arduino Nano: ระบบ Ultrasonic 40 kHz แบบ 1 Transmitter + 2 Receivers ด้วย US-015

## 1. วัตถุประสงค์ของโปรเจกต์

ต้องการทดลองใช้โมดูลอัลตราโซนิก US-015 จำนวน 2 บอร์ด เพื่อสร้างระบบที่มี:

- ตัวส่งคลื่นอัลตราโซนิก 40 kHz จำนวน 1 ตัว
- ตัวรับคลื่นอัลตราโซนิกจำนวน 2 ตัว
- Arduino Nano รุ่นคลาสสิกที่ใช้ ATmega328P
- ใช้ความต่างของเวลาที่ตัวรับทั้งสองตรวจพบสัญญาณ เพื่อประมาณความต่างของเส้นทางเสียง และอาจต่อยอดไปสู่การประมาณทิศทางของแหล่งสะท้อนหรือ TDOA

โครงการนี้เป็นการทดลองดัดแปลง US-015 ซึ่งเดิมถูกออกแบบให้แต่ละบอร์ดทำงานเป็นเซนเซอร์วัดระยะอิสระ ไม่ได้ออกแบบมาเป็นระบบ TDOA หลายตัวรับโดยตรง ดังนั้นโค้ดต้องแยกให้ชัดเจนระหว่าง:

1. ค่าที่วัดได้จริงจากโมดูล
2. ค่าที่อนุมานจากโมดูล
3. ข้อจำกัดที่ทำให้ค่าดังกล่าวยังไม่ใช่ TDOA บริสุทธิ์

---

## 2. ฮาร์ดแวร์และการต่อปัจจุบัน

สมมติการต่อดังนี้:

```text
US-015 บอร์ด 1
- VCC  -> 5V
- GND  -> GND
- TRIG -> A2
- ECHO -> A0
- มีหัวส่ง T
- มีหัวรับ R1

US-015 บอร์ด 2
- VCC  -> 5V
- GND  -> GND
- TRIG -> A2
- ECHO -> A1
- ถอดหรือไม่ใช้งานหัวส่ง T
- ใช้หัวรับ R2
```

ขา Analog ของ Arduino Nano ถูกใช้เป็นขา Digital:

```cpp
A0 = ECHO1
A1 = ECHO2
A2 = TRIG
```

แม้สายจะต่อเข้าขาที่มีชื่อ A0, A1 และ A2 แต่ในงานนี้ไม่ควรใช้ `analogRead()` กับ ECHO เนื่องจาก ECHO ของ US-015 เป็นสัญญาณดิจิทัล LOW/HIGH ไม่ใช่แรงดัน Analog ที่แสดงรูปคลื่น 40 kHz

---

## 3. ทฤษฎีของคลื่นอัลตราโซนิก 40 kHz

### 3.1 ความถี่และคาบ

ความถี่ของทรานสดิวเซอร์:

\[
f = 40{,}000\ \text{Hz}
\]

คาบของคลื่น:

\[
T = \frac{1}{f}
\]

ดังนั้น:

\[
T = \frac{1}{40{,}000} = 25\ \mu s
\]

ความหมายสำคัญคือ หากวงจรตรวจจับพลาดคลื่นไปหนึ่งรอบ เวลาที่วัดอาจกระโดดประมาณ 25 ไมโครวินาที หากพลาดสองหรือสามรอบ อาจกระโดดประมาณ 50 หรือ 75 ไมโครวินาที

ค่าที่พบจาก Serial Monitor มีการกระโดดเป็นกลุ่มใกล้เคียงกับหลายเท่าของ 25 ไมโครวินาที เช่น:

```text
+19 us
-56 us
-77 us
0 us
+55 us
+75 us
```

จึงมีความเป็นไปได้ว่าระบบตรวจพบคนละ cycle หรือคนละ echo path ในแต่ละรอบ

### 3.2 ความเร็วเสียง

ที่อุณหภูมิห้องโดยประมาณ สามารถใช้:

\[
c \approx 343\ \text{m/s}
\]

หรือ:

\[
c \approx 0.0343\ \text{cm}/\mu s
\]

ค่าความเร็วเสียงเปลี่ยนตามอุณหภูมิ โดยประมาณ:

\[
c \approx 331.3 + 0.606T
\]

เมื่อ \(T\) คืออุณหภูมิอากาศหน่วยองศาเซลเซียส

ตัวอย่าง:

```text
ที่ 20 °C -> c ≈ 343.4 m/s
ที่ 30 °C -> c ≈ 349.5 m/s
```

สำหรับการทดลองระยะสั้น อาจใช้ 343 m/s ได้ก่อน แต่ถ้าต้องการความแม่นยำ ควรรับค่าอุณหภูมิเป็นตัวแปรและปรับความเร็วเสียงตามอุณหภูมิ

### 3.3 ความยาวคลื่น

\[
\lambda = \frac{c}{f}
\]

เมื่อ:

```text
c = 343 m/s
f = 40,000 Hz
```

จะได้:

\[
\lambda \approx 8.575\ \text{mm}
\]

ดังนั้นการเปลี่ยนตำแหน่งทรานสดิวเซอร์เพียงไม่กี่มิลลิเมตรก็อาจเปลี่ยนเฟสและรูปแบบการแทรกสอดได้อย่างมีนัยสำคัญ

---

## 4. ความแตกต่างระหว่าง Distance Measurement และ TDOA

### 4.1 การวัดระยะด้วย pulse width

โมดูลอัลตราโซนิกทั่วไปส่งพัลส์ ECHO ซึ่งความกว้างแทนเวลาที่คลื่นเดินทาง:

```text
ตัวส่ง -> วัตถุ -> ตัวรับ
```

ระยะทางไปยังวัตถุจึงคำนวณโดย:

\[
d = \frac{ct}{2}
\]

ต้องหาร 2 เพราะเสียงเดินทางไปและกลับ

ในโค้ดปัจจุบัน:

```cpp
distanceCm = pulseWidthUs * 0.0343 / 2.0;
```

สูตรนี้เหมาะกับการวัดระยะจากตัวส่งไปวัตถุแล้วสะท้อนกลับมายังตัวรับ

### 4.2 การวัดความต่างเส้นทางด้วย TDOA

กรณีตัวรับสองตัวรับคลื่นเดียวกัน:

\[
\Delta t = t_2 - t_1
\]

ความต่างของเส้นทางเสียงคือ:

\[
\Delta L = c\Delta t
\]

กรณีนี้ไม่หาร 2 เพราะกำลังเปรียบเทียบเส้นทางที่คลื่นไปถึงตัวรับสองตัว ไม่ได้คำนวณการเดินทางไป-กลับของวัตถุหนึ่งจุดโดยตรง

ตัวอย่าง:

```text
Δt = 18 us
c = 0.0343 cm/us
```

จะได้:

\[
\Delta L = 18 \times 0.0343 = 0.6174\ \text{cm}
\]

ประมาณ 0.62 cm

---

## 5. ทำไม `analogRead()` ไม่เหมาะกับงานนี้

Arduino Nano รุ่น ATmega328P มี ADC เพียงชุดเดียว แล้วใช้ Multiplexer สลับอ่าน A0, A1 และ A2 ทีละช่อง

โดยค่าเริ่มต้นของ Arduino:

```text
CPU clock       = 16 MHz
ADC prescaler   = 128
ADC clock       = 125 kHz
1 conversion    ≈ 13 ADC clocks
เวลาอ่านหนึ่งครั้ง ≈ 104 us
```

แต่คลื่น 40 kHz มีคาบเพียง 25 us

ดังนั้นระหว่างการอ่าน A0 และ A1 คลื่นอาจผ่านไปแล้วประมาณ 4 รอบ และระหว่าง A0 ถึง A2 อาจผ่านไปประมาณ 8 รอบ

ปัญหาหลักไม่ใช่แค่ว่า ADC ช้า แต่คือ `analogRead()` คืนค่าแรงดัน ณ เวลาหนึ่ง ไม่ได้คืน timestamp ที่สัญญาณเริ่มมาถึง

ยิ่งไปกว่านั้น ขา ECHO ของ US-015 เป็นสัญญาณดิจิทัล:

```text
LOW  ≈ 0 V
HIGH ≈ 5 V
```

ดังนั้น `analogRead()` จะได้เพียงค่าประมาณ:

```text
LOW  -> 0
HIGH -> 1023
```

จึงไม่มีประโยชน์ในการอ่านรูปคลื่น 40 kHz จริง

วิธีที่เหมาะกว่าคือใช้:

- Digital input
- Pin Change Interrupt
- Timer1
- จับขอบ LOW -> HIGH และ HIGH -> LOW
- บันทึก timestamp ด้วยความละเอียดระดับไมโครวินาทีหรือต่ำกว่า

---

## 6. Timer1 และความละเอียดเวลา

Arduino Nano ใช้ clock 16 MHz

หากตั้ง Timer1 prescaler = 8:

\[
f_{timer} = \frac{16\text{ MHz}}{8} = 2\text{ MHz}
\]

ดังนั้นหนึ่ง tick เท่ากับ:

\[
\frac{1}{2\text{ MHz}} = 0.5\ \mu s
\]

ค่าความละเอียด 0.5 us เทียบเป็นความต่างเส้นทางได้:

\[
0.5 \times 0.0343 = 0.01715\ \text{cm}
\]

หรือประมาณ 0.1715 mm ในเชิง resolution ของ timer

อย่างไรก็ตาม resolution ของ timer ไม่เท่ากับ accuracy ของระบบจริง เพราะยังมีความผิดพลาดจาก:

- ความหน่วงภายในโมดูล
- Comparator threshold
- jitter
- interrupt latency
- crosstalk
- ringing
- multipath
- cycle ambiguity
- ความคลาดเคลื่อนของทรานสดิวเซอร์
- อุณหภูมิ
- การวางตำแหน่งทางกล

ดังนั้นแม้ timer จะละเอียด 0.5 us แต่ความแม่นยำจริงอาจแย่กว่ามาก

---

## 7. Pin Change Interrupt

A0 และ A1 อยู่บน Port C ของ ATmega328P:

```text
A0 = PC0 = PCINT8
A1 = PC1 = PCINT9
```

ทั้งสองขาสามารถใช้ Pin Change Interrupt กลุ่มเดียวกันได้

เมื่อ A0 หรือ A1 เปลี่ยนสถานะ ISR เดียวจะทำงาน แล้วอ่านค่า `PINC` เพื่อดูว่าขาใดเปลี่ยน

แนวคิด:

```cpp
currentPort = PINC;
changed = currentPort ^ previousPort;
```

หาก bit ของ PC0 เปลี่ยน:

```text
LOW -> HIGH = บันทึก rise timestamp ของ R1
HIGH -> LOW = บันทึก fall timestamp ของ R1
```

หาก bit ของ PC1 เปลี่ยน:

```text
LOW -> HIGH = บันทึก rise timestamp ของ R2
HIGH -> LOW = บันทึก fall timestamp ของ R2
```

ข้อดี:

- ตรวจทั้งสองช่องใน interrupt group เดียว
- ไม่ต้อง polling แบบช้า
- ลดความคลาดเคลื่อนจากการเรียกฟังก์ชันทีละช่อง
- เก็บ timestamp ด้วย Timer1 เดียวกัน

---

## 8. สิ่งที่โค้ดปัจจุบันวัดได้จริง

โค้ดปัจจุบันคำนวณ:

```cpp
pulse1Us = fall1 - rise1;
pulse2Us = fall2 - rise2;
deltaTimeUs = pulse2Us - pulse1Us;
```

ความหมายจริงคือ:

```text
deltaTimeUs = ความต่างของความกว้างพัลส์ ECHO ระหว่าง US-015 สองบอร์ด
```

มันยังไม่สามารถรับประกันได้ว่าเป็น:

```text
เวลาที่คลื่นมาถึง Receiver 2 - เวลาที่คลื่นมาถึง Receiver 1
```

เพราะ US-015 แต่ละบอร์ดมีวงจรภายในอิสระ เช่น:

- วงจรสร้าง burst
- blanking time หลังส่ง
- automatic gain หรือ gain profile
- amplifier
- envelope detector
- comparator
- threshold
- logic timing
- pulse generation

หากวงจรภายในของสองบอร์ดไม่เท่ากัน ความกว้าง ECHO จะมี offset และ jitter ที่ไม่เกี่ยวกับ propagation time

ดังนั้นต้องเรียกผลปัจจุบันว่า:

```text
pseudo-TDOA
หรือ
difference of module-reported echo pulse widths
```

ไม่ควรเรียกว่า true TDOA จนกว่าจะพิสูจน์ด้วยการ calibrate และทดสอบซ้ำ

---

## 9. ปัญหาที่เห็นจากข้อมูลจริง

ตัวอย่างข้อมูล:

```text
R1: 212.5 us | R2: 230.5 us | dt: +18.0 us
R1: 287.5 us | R2: 231.0 us | dt: -56.5 us
R1: 308.5 us | R2: 231.0 us | dt: -77.5 us
R1: 250.0 us | R2: 250.0 us | dt: 0.0 us
R1: 193.5 us | R2: 268.5 us | dt: +75.0 us
```

หากตำแหน่งอุปกรณ์และวัตถุไม่ขยับ ค่า dt ควรเกาะกลุ่มใกล้ค่าเดียวกัน แต่ข้อมูลนี้แบ่งเป็นหลายกลุ่ม:

```text
ประมาณ +19 us
ประมาณ -56 us
ประมาณ -77 us
ประมาณ 0 us
ประมาณ +55 us
ประมาณ +75 us
```

ความต่างระหว่างหลายกลุ่มใกล้เคียงกับ:

```text
25 us
50 us
75 us
```

ซึ่งสัมพันธ์กับคาบของ 40 kHz

จึงมีสมมติฐานสำคัญว่าเกิด cycle slip หรือ cycle ambiguity:

```text
บอร์ดหนึ่งจับ cycle แรก
อีกบอร์ดจับ cycle ที่สองหรือสาม
```

นอกจากนี้ระยะที่รายงานเพียงประมาณ 3-5 cm ใกล้กับบริเวณที่อาจได้รับผลจาก:

- direct acoustic coupling
- transmitter ringing
- mechanical vibration
- board crosstalk
- dead zone
- near-field pattern
- reflection จากโต๊ะหรือโครงยึด

---

## 10. ขอบเขตทางกายภาพของ TDOA

หาก Receiver สองตัวห่างกัน \(D\):

\[
|\Delta L| \le D
\]

เพราะความต่างของระยะทางไปยังตัวรับสองตัวไม่สามารถมากกว่าระยะห่างระหว่างตัวรับได้

ดังนั้น:

\[
|\Delta t| \le \frac{D}{c}
\]

ตัวอย่าง Receiver ห่างกัน 2 cm:

\[
|\Delta t|_{\max} = \frac{2}{0.0343}
\]

\[
|\Delta t|_{\max} \approx 58.3\ \mu s
\]

ดังนั้นค่า dt = 75 us จะเป็นไปไม่ได้ทางเรขาคณิต หาก Receiver ห่างกันเพียง 2 cm

โค้ดควรมี plausibility gate:

```cpp
maxDtUs = receiverSpacingCm / soundSpeedCmPerUs;

if (abs(deltaTimeUs) > maxDtUs) {
    rejectMeasurement();
}
```

---

## 11. ทฤษฎีการประมาณมุมด้วย Receiver สองตัว

สมมติ Receiver สองตัววางเป็นเส้นตรง ระยะห่าง \(D\) และแหล่งกำเนิดอยู่ไกลพอจนคลื่นประมาณเป็น plane wave

\[
\Delta L = D\sin\theta
\]

ดังนั้น:

\[
\theta = \sin^{-1}\left(\frac{c\Delta t}{D}\right)
\]

โดย:

- \(\theta = 0^\circ\) หมายถึงคลื่นมาจากด้านหน้าตรงกลาง
- ค่าเป็นบวกหรือลบขึ้นกับนิยามว่า R1 หรือ R2 อยู่ด้านใด
- ต้องกำหนด sign convention ให้ชัดเจน

ตัวอย่าง:

```text
Receiver spacing D = 5 cm
Δt = 50 us
c = 0.0343 cm/us
```

\[
\Delta L = 50 \times 0.0343 = 1.715\ \text{cm}
\]

\[
\theta = \sin^{-1}(1.715/5)
\]

\[
\theta \approx 20.1^\circ
\]

ข้อจำกัด:

- สูตรนี้เหมาะกับ far-field หรือ plane-wave approximation
- หากวัตถุอยู่ใกล้มาก geometry จะเป็น hyperbolic ไม่ใช่เส้นตรงง่าย ๆ
- สำหรับระบบสะท้อนแบบ monostatic/bistatic ความสัมพันธ์จะซับซ้อนกว่ากรณีแหล่งเสียงตรง
- หากใช้ transmitter อยู่ระหว่าง receivers ต้องพิจารณาเส้นทาง TX -> target -> RX1 และ TX -> target -> RX2

---

## 12. Near-field และ Far-field

ทรานสดิวเซอร์อัลตราโซนิกมีขนาด aperture จำกัด และเกิด near-field interference pattern

ความยาว near-field โดยประมาณของ circular transducer:

\[
N \approx \frac{a^2}{\lambda}
\]

หรือบางนิยามใช้:

\[
N \approx \frac{D_t^2}{4\lambda}
\]

เมื่อ:

- \(a\) คือรัศมีของทรานสดิวเซอร์
- \(D_t\) คือเส้นผ่านศูนย์กลางของทรานสดิวเซอร์
- \(\lambda\) คือความยาวคลื่น

ใน near field ความดันเสียงอาจมีจุดสูงและต่ำหลายตำแหน่ง ทำให้ Receiver สองตัวที่อยู่ใกล้กันรับ amplitude และ phase ต่างกันมาก แม้ว่าวัตถุจะอยู่ตรงกลาง

ดังนั้นการทดสอบควรเริ่มที่ระยะประมาณ 20-50 cm กับแผ่นสะท้อนขนาดใหญ่และผิวเรียบ ก่อนทดสอบระยะใกล้

---

## 13. Ringing และ Blanking Time

หลังส่ง burst 40 kHz ตัวส่งจะยังสั่นต่อช่วงหนึ่ง เรียกว่า ringing

ผลของ ringing:

- ตัวรับที่อยู่ใกล้อาจรับคลื่นตรงทันที
- โครงสร้างบอร์ดหรือฐานยึดอาจส่งแรงสั่นทางกล
- วงจรรับอาจ saturate
- Comparator อาจ trigger ก่อน echo จริง
- โมดูลต้องใช้ blanking interval เพื่อไม่รับสัญญาณช่วงแรก

US-015 แต่ละบอร์ดอาจมี blanking time ไม่เท่ากันเล็กน้อย ทำให้สองบอร์ดเริ่มรับจริงคนละเวลา

โค้ดควรมี minimum valid time:

```cpp
if (pulseWidthUs < MIN_VALID_US) {
    reject as ringing or direct coupling;
}
```

แต่ต้องระวังว่า pulse width ไม่เท่ากับ absolute time of arrival หากใช้ output ECHO ของโมดูล

---

## 14. Threshold Walk

Comparator ตรวจพบสัญญาณเมื่อ amplitude ข้าม threshold

หากสัญญาณแรง:

```text
ข้าม threshold เร็ว
```

หากสัญญาณอ่อน:

```text
ข้าม threshold ช้า
```

ปรากฏการณ์นี้เรียกว่า threshold walk หรือ time walk

ดังนั้น Receiver ที่รับคลื่นแรงกว่าอาจดูเหมือนรับก่อน แม้เวลาที่ wavefront มาถึงจริงเท่ากัน

วิธีลดผลกระทบ:

- ใช้ constant fraction discriminator
- ใช้ matched filtering
- บันทึกรูปคลื่น analog แล้วทำ cross-correlation
- ใช้ threshold หลายระดับ
- calibrate amplitude-time relation
- ใช้ comparator และ gain ที่เหมือนกันทุกช่อง
- ใช้ front-end ร่วม clock และ supply เดียวกัน

US-015 แบบ black box ไม่เปิดโอกาสให้ควบคุมองค์ประกอบเหล่านี้ได้เต็มที่

---

## 15. Multipath

คลื่นอัลตราโซนิกอาจสะท้อนจาก:

- โต๊ะ
- ผนัง
- มือ
- สายไฟ
- ฐานยึด
- ขอบวัตถุ
- ตัวบอร์ดเอง

Receiver อาจตรวจพบเส้นทางที่ไม่ใช่เส้นทางตรง เช่น:

```text
TX -> โต๊ะ -> R1
TX -> วัตถุ -> R2
```

หรือ:

```text
TX -> วัตถุหลัก -> R1
TX -> ผนัง -> R2
```

ทำให้ dt เปลี่ยนเครื่องหมายหรือกระโดดเป็นหลายกลุ่ม

ควรทดสอบในพื้นที่โล่งและใช้วัสดุดูดซับเสียงรอบด้านที่ไม่ต้องการสะท้อน หากทำได้

---

## 16. แนวทางซอฟต์แวร์ที่ Codex ต้องพัฒนา

### 16.1 เป้าหมายหลัก

สร้าง Arduino sketch ที่:

1. ใช้ Arduino Nano ATmega328P
2. ใช้ A0 และ A1 เป็น digital input
3. ใช้ A2 เป็น trigger output
4. ใช้ Timer1 prescaler 8
5. ใช้ Pin Change Interrupt ของ Port C
6. จับ rise และ fall timestamps ของ ECHO ทั้งสองช่อง
7. ไม่ใช้ `pulseIn()`
8. ไม่ใช้ `analogRead()`
9. มี timeout
10. มี calibration offset
11. มี physical plausibility filter
12. มี median filter
13. มี cycle-slip detection
14. มี confidence score
15. ส่งออกข้อมูลผ่าน Serial ที่ 115200 baud
16. โค้ดต้อง compile บน Arduino Nano ATmega328P

### 16.2 State machine ที่แนะนำ

สถานะ:

```text
IDLE
ARMED
WAITING_FOR_RISE
WAITING_FOR_FALL
COMPLETE
TIMEOUT
```

แต่ละ channel มีสถานะย่อย:

```text
NOT_STARTED
RISE_SEEN
FALL_SEEN
INVALID
```

ลำดับการวัด:

```text
1. reset timestamps
2. clear interrupt flags
3. reset Timer1
4. wait guard interval
5. send 10 us trigger
6. wait for both ECHO channels
7. timeout after defined limit
8. copy volatile variables atomically
9. calculate pulse widths
10. apply calibration
11. validate
12. filter
13. print result
```

### 16.3 ตัวแปรสำคัญ

```cpp
const float SOUND_SPEED_CM_PER_US = 0.0343f;
const float RECEIVER_SPACING_CM = ...;
const float CALIBRATION_OFFSET_US = ...;
const uint32_t MEASUREMENT_TIMEOUT_US = ...;
const float MIN_DISTANCE_CM = ...;
const float MAX_DISTANCE_CM = ...;
const size_t FILTER_WINDOW = 5 or 7;
```

### 16.4 Timestamp

ใช้หน่วย timer ticks ภายใน ISR

```cpp
volatile uint32_t echo1RiseTicks;
volatile uint32_t echo1FallTicks;
volatile uint32_t echo2RiseTicks;
volatile uint32_t echo2FallTicks;
```

แปลงเป็นไมโครวินาทีภายนอก ISR:

```cpp
float ticksToUs(uint32_t ticks) {
    return ticks * 0.5f;
}
```

ห้ามใช้ floating-point ภายใน ISR

---

## 17. การคำนวณที่ควรแยกออกจากกัน

ต้องแสดงค่าต่อไปนี้แยกกัน:

### 17.1 Pulse width ของแต่ละโมดูล

```cpp
pulse1Us = fall1Us - rise1Us;
pulse2Us = fall2Us - rise2Us;
```

### 17.2 ระยะตาม output ของแต่ละโมดูล

```cpp
distance1Cm = pulse1Us * c / 2;
distance2Cm = pulse2Us * c / 2;
```

### 17.3 Raw pseudo-TDOA

```cpp
rawDeltaUs = pulse2Us - pulse1Us;
```

### 17.4 Calibrated pseudo-TDOA

```cpp
calibratedDeltaUs = rawDeltaUs - calibrationOffsetUs;
```

### 17.5 Path difference

```cpp
pathDifferenceCm = calibratedDeltaUs * c;
```

### 17.6 Angle estimate

เฉพาะเมื่อค่าผ่าน physical gate:

```cpp
ratio = pathDifferenceCm / receiverSpacingCm;
angleDeg = asin(ratio) * 180.0 / PI;
```

ต้อง clamp ratio ให้อยู่ในช่วง [-1, 1] หลังจากตรวจ validity แล้ว

---

## 18. Calibration

### 18.1 Static offset calibration

จัดอุปกรณ์แบบสมมาตร:

```text
R1        T        R2
|---------|---------|

แผ่นสะท้อนเรียบอยู่ตรงกลางด้านหน้า
```

เงื่อนไข:

- R1 และ R2 ห่างจาก T เท่ากัน
- ทรานสดิวเซอร์อยู่ระดับเดียวกัน
- หันหน้าไปทิศเดียวกัน
- แผ่นสะท้อนอยู่ห่าง 30-50 cm
- ไม่ขยับอุปกรณ์
- เก็บอย่างน้อย 100-500 measurements

คำนวณ median ของ raw delta:

```cpp
calibrationOffsetUs = median(rawDeltaUs samples);
```

ไม่ควรใช้ค่าเฉลี่ยธรรมดาอย่างเดียว เพราะ outlier จำนวนมากอาจดึงค่าเฉลี่ยผิด

### 18.2 Jitter characterization

คำนวณ:

- median
- mean
- minimum
- maximum
- standard deviation
- median absolute deviation
- percentage of rejected samples
- histogram หรือกลุ่มค่าที่พบบ่อย

หากพบหลาย cluster ห่างกันประมาณ 25 us ให้รายงาน cycle ambiguity

---

## 19. Median Filter

ใช้ window จำนวนคี่ เช่น 5 หรือ 7 ค่า

ตัวอย่าง:

```text
raw dt:
19, -56, 18, 20, 19
```

median คือ 19 us ซึ่งทนต่อ outlier -56 us ได้ดีกว่าค่าเฉลี่ย

แต่ถ้าค่ากระโดดเป็น cluster และ cluster ผิดมีจำนวนมาก median อาจยังผิดได้ จึงต้องใช้ร่วมกับ:

- plausibility gate
- cycle-slip correction
- confidence score
- temporal continuity

---

## 20. Cycle-slip Detection

เนื่องจากคาบ 40 kHz เท่ากับ 25 us สามารถตรวจว่าค่าปัจจุบันอยู่ห่างจากค่าก่อนหน้าใกล้เคียงจำนวนเต็มเท่าของ 25 us หรือไม่

แนวคิด:

```cpp
differenceFromPrevious = currentDeltaUs - previousFilteredDeltaUs;
cycleCount = round(differenceFromPrevious / 25.0f);
residual = differenceFromPrevious - cycleCount * 25.0f;
```

หาก:

```text
abs(residual) < tolerance
และ
abs(cycleCount) >= 1
```

อาจเป็น cycle slip

ตัวอย่าง tolerance:

```text
2-5 us
```

แนวทาง correction เชิงทดลอง:

```cpp
correctedDeltaUs = currentDeltaUs - cycleCount * 25.0f;
```

แต่ต้องทำเฉพาะเมื่อ:

- corrected value อยู่ใน physical bound
- corrected value ใกล้ median ของ history
- confidence เพียงพอ
- ไม่ใช้ correction เพื่อบังคับให้ทุกค่าดูดี

ต้องพิมพ์ flag ว่าเกิด correction หรือไม่:

```text
cycle_slip=1
cycle_shift=-2
```

หมายถึงลบสอง cycle หรือ 50 us

---

## 21. Confidence Score

สร้างคะแนน 0-100 จากปัจจัย:

- ผ่าน physical bound
- pulse width ของทั้งสองช่องอยู่ในช่วงสมเหตุสมผล
- ค่าใกล้ median history
- ไม่เกิด timeout
- ไม่เกิด cycle slip หรือ correction น้อย
- spread ของ filter window ต่ำ
- ทั้งสองช่องตรวจพบครบ
- ค่าไม่อยู่ใกล้ dead zone
- ค่าไม่กระโดดจากครั้งก่อนมากเกินไป

ตัวอย่างแนวคิด:

```text
เริ่ม 100
-40 หาก timeout
-30 หากเกิน physical bound
-20 หาก cycle slip
-15 หาก deviation จาก median สูง
-10 หากอยู่ใกล้ dead zone
```

ผลลัพธ์ควรมี:

```text
confidence=85
status=VALID
```

หรือ:

```text
confidence=25
status=UNRELIABLE
```

---

## 22. Output Format

ต้องรองรับสองโหมด:

### 22.1 Human-readable

```text
R1=212.5us 3.64cm | R2=230.5us 3.95cm | raw_dt=18.0us | calibrated_dt=0.5us | path=0.02cm | angle=0.2deg | confidence=91 | status=VALID
```

### 22.2 CSV

Header:

```text
timestamp_ms,r1_pulse_us,r2_pulse_us,r1_cm,r2_cm,raw_dt_us,calibrated_dt_us,path_diff_cm,angle_deg,confidence,status,cycle_shift
```

ตัวอย่าง:

```text
1250,212.5,230.5,3.64,3.95,18.0,0.5,0.017,0.20,91,VALID,0
```

ควรมี compile-time flag:

```cpp
#define OUTPUT_CSV 1
```

---

## 23. Commands ผ่าน Serial

เพิ่ม command parser แบบง่าย:

```text
c
```

เริ่ม calibration

```text
p
```

พิมพ์ parameters ปัจจุบัน

```text
r
```

reset filter history

```text
s
```

สลับ human-readable กับ CSV

```text
t25
```

ตั้งอุณหภูมิเป็น 25 °C แล้วคำนวณความเร็วเสียงใหม่

```text
d5.0
```

ตั้ง receiver spacing เป็น 5.0 cm

ค่าที่เปลี่ยนได้อาจเก็บไว้ใน RAM ก่อน ไม่จำเป็นต้องเขียน EEPROM ในเวอร์ชันแรก

---

## 24. Acceptance Criteria สำหรับซอฟต์แวร์

โค้ดถือว่าผ่านเมื่อ:

1. Compile บน Arduino Nano ATmega328P ได้
2. Serial Monitor ใช้ 115200 baud
3. ไม่มีการใช้ `pulseIn()`
4. ไม่มีการใช้ `analogRead()` กับ ECHO
5. ใช้ Timer1 และ Pin Change Interrupt
6. จับ ECHO1 และ ECHO2 ได้ใน measurement เดียวกัน
7. มี timeout ที่ไม่ทำให้โปรแกรมค้าง
8. มี calibration offset
9. มี physical bound จาก receiver spacing
10. มี median filter อย่างน้อย 5 ค่า
11. มี cycle-slip detector ที่ใช้ 25 us เป็นคาบอ้างอิง
12. มี confidence score
13. มี human-readable output
14. มี CSV output
15. มี comments อธิบาย register สำคัญ
16. ISR ต้องสั้นและไม่มี Serial หรือ floating-point
17. อ่านตัวแปร volatile แบบ atomic
18. รองรับ Timer1 overflow
19. แสดง status ของ measurement ชัดเจน
20. ไม่รายงาน angle เมื่อข้อมูลไม่ valid

---

## 25. แผนการทดลอง

### Experiment 1: ตรวจการทำงานพื้นฐาน

- วางแผ่นสะท้อนที่ 30 cm
- ยิงทุก 100 ms
- เก็บ 100 ค่า
- ตรวจ timeout
- ตรวจว่า R1 และ R2 มีค่าใกล้เคียงกัน

### Experiment 2: Symmetric calibration

- วาง R1 และ R2 สมมาตรรอบ T
- เก็บ 500 ค่า
- คำนวณ median offset
- ตรวจ distribution ของ raw dt
- ตรวจว่ามีกี่ cluster

### Experiment 3: Receiver spacing

ทดลอง spacing:

```text
2 cm
5 cm
10 cm
```

ตรวจว่า physical max dt เปลี่ยนตาม:

\[
\Delta t_{\max} = D/c
\]

### Experiment 4: Move reflector left-right

เลื่อนแผ่นสะท้อนทีละตำแหน่ง:

```text
ซ้ายมาก
ซ้าย
กลาง
ขวา
ขวามาก
```

ตรวจว่า sign ของ calibrated dt เปลี่ยนตามทิศอย่างสม่ำเสมอหรือไม่

### Experiment 5: Repeatability

ที่ตำแหน่งเดิม:

- เก็บ 1,000 ค่า
- คำนวณ valid rate
- คำนวณ standard deviation
- คำนวณ cycle-slip rate
- ตรวจ drift ตามเวลา

### Experiment 6: Distance sweep

ทดลองระยะ:

```text
10, 20, 30, 40, 50, 75, 100 cm
```

ตรวจว่าระยะใดมีค่าคงที่ที่สุด และระยะใดเกิด dead zone หรือ multipath มาก

---

## 26. ข้อจำกัดสำคัญที่ต้องเขียนไว้ใน README และ Serial Output

1. ระบบนี้ใช้ US-015 สองบอร์ดเป็น black-box receiver
2. output ECHO เป็นผลหลังผ่านวงจรประมวลผลภายใน ไม่ใช่ raw 40 kHz waveform
3. ความต่างของ pulse width ไม่รับประกันว่าเป็น true arrival-time difference
4. calibration ช่วยลบ static offset แต่ลบ dynamic jitter ไม่ได้ทั้งหมด
5. cycle-slip correction เป็น heuristic
6. angle estimate ใช้ได้เฉพาะเมื่อ physical assumptions ถูกต้อง
7. ผลลัพธ์ควรถือเป็น prototype และ qualitative direction estimate ก่อน
8. ไม่ควรใช้ในงาน safety-critical
9. หากต้องการ true TDOA ควรเข้าถึงสัญญาณก่อน comparator หรือออกแบบ receiver front-end แยกเอง
10. การวัดด้วยสอง receivers ให้มุมได้หนึ่งแกนและอาจมี ambiguity
11. การวัด position 2D/3D ต้องเพิ่มจำนวน receivers และใช้ geometry เพิ่มเติม

---

## 27. แนวทางฮาร์ดแวร์ที่แม่นกว่าระยะยาว

หากต้องการ true TDOA ควรเปลี่ยนจาก US-015 black-box เป็น architecture:

```text
RX1 -> Band-pass amplifier 40 kHz -> Comparator -> Digital timestamp
RX2 -> Band-pass amplifier 40 kHz -> Comparator -> Digital timestamp
```

หรือ:

```text
RX1 -> ADC channel 1
RX2 -> ADC channel 2
```

โดย ADC ต้อง:

- sampling เร็วกว่าความถี่ 40 kHz อย่างมี margin
- ควรอย่างน้อย 200-500 kS/s ต่อ channel
- หากต้องการ phase/TDOA แม่น ควร simultaneous sampling
- ใช้ clock เดียวกัน
- ทำ cross-correlation หรือ matched filtering

แนวทาง DSP:

1. บันทึก waveform ของ RX1 และ RX2
2. band-pass รอบ 40 kHz
3. normalize amplitude
4. cross-correlate
5. หา lag ที่ correlation สูงสุด
6. interpolation รอบ peak เพื่อเพิ่ม sub-sample precision
7. แปลง lag เป็น dt
8. แปลง dt เป็น path difference และ angle

สูตร cross-correlation:

\[
R_{xy}[k] = \sum_n x[n]y[n+k]
\]

ค่า \(k\) ที่ทำให้ \(R_{xy}[k]\) สูงสุดคือ sample delay โดยประมาณ

\[
\Delta t = \frac{k}{f_s}
\]

---

## 28. สิ่งที่ต้องการให้ Codex ส่งมอบ

ให้ Codex สร้างไฟล์:

```text
ultrasonic_tdoa_nano.ino
README.md
```

### เนื้อหาใน `ultrasonic_tdoa_nano.ino`

- Pin definitions
- Timer1 setup
- PCINT setup
- overflow handling
- atomic snapshot
- measurement state machine
- trigger generation
- timeout
- pulse width calculation
- calibration
- physical validation
- median filter
- cycle-slip detector
- confidence score
- human-readable output
- CSV output
- serial commands
- comments ภาษาไทยหรืออังกฤษที่เข้าใจง่าย

### เนื้อหาใน `README.md`

- wiring
- assumptions
- equations
- calibration instructions
- limitations
- experiment procedure
- interpretation of sign
- troubleshooting
- expected Serial output

---

## 29. Prompt สำหรับส่งให้ Codex โดยตรง

```text
พัฒนา Arduino sketch สำหรับ Arduino Nano ATmega328P ตาม specification ในเอกสารนี้

ข้อกำหนดบังคับ:
- A0 = ECHO1
- A1 = ECHO2
- A2 = TRIG ร่วมของ US-015 สองบอร์ด
- Serial 115200
- ใช้ Timer1 prescaler 8
- ใช้ Pin Change Interrupt ของ Port C
- ห้ามใช้ pulseIn()
- ห้ามใช้ analogRead() กับ ECHO
- ISR ต้องสั้น ไม่มี Serial และไม่มี floating-point
- ต้องรองรับ Timer1 overflow
- ต้อง snapshot volatile variables แบบ atomic
- ต้องมี timeout
- ต้องมี calibration offset
- ต้องมี physical plausibility gate จาก receiver spacing
- ต้องมี median filter window 5 หรือ 7
- ต้องมี cycle-slip detector โดยอ้างอิงคาบ 25 us ของ 40 kHz
- ต้องมี confidence score
- ต้องมี output แบบ human-readable และ CSV
- ต้องไม่คำนวณหรือแสดง angle หาก measurement invalid
- ต้อง compile ได้บน Arduino Nano classic/ATmega328P

กรุณาสร้าง:
1. ultrasonic_tdoa_nano.ino
2. README.md

ให้อธิบาย architecture, register setup, timing, equations, limitations และวิธี calibrate อย่างละเอียด
```

---

## 30. สรุปหลักการสำคัญ

- A0 และ A1 ใช้เป็น digital input ได้
- ECHO ของ US-015 ไม่ใช่ raw analog waveform
- `analogRead()` ไม่เหมาะกับ TDOA
- Timer1 ที่ prescaler 8 ให้ resolution 0.5 us
- 40 kHz มีคาบ 25 us
- ค่ากระโดดประมาณ 25, 50, 75 us อาจเกิด cycle slip
- ความต่าง path สำหรับ TDOA ใช้ \(c\Delta t\) ไม่หาร 2
- ระยะ pulse-echo ใช้ \(ct/2\)
- \(|\Delta t|\) ต้องไม่เกิน \(D/c\)
- US-015 สองบอร์ดมี internal delay ต่างกัน จึงต้อง calibrate
- แม้ calibrate แล้ว ผลยังเป็น pseudo-TDOA ไม่ใช่ true TDOA ที่รับประกัน
- หากต้องการความแม่นยำจริง ควรเข้าถึง raw receiver signal แล้วใช้ comparator ร่วมกันหรือ simultaneous ADC + cross-correlation

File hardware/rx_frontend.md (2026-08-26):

# RX Front-End — วงจรภาครับ 40 kHz

วงจรขยายสัญญาณจากทรานสดิวเซอร์ TCT40-16R ให้ ESP32 อ่านได้
**เอกสารนี้คือ 1 ช่อง** ช่องที่ 2-9 คือวงจรเดียวกันซ้ำ ห้ามต่างกันแม้แต่นิดเดียว
เพราะความต่างระหว่างช่องจะกลายเป็น error ของ Δt โดยตรง

> ⚠️ **นี่คือ stage ที่เสี่ยงที่สุดของทั้งโปรเจกต์** ถ้าวงจรนี้ไม่ให้คลื่น 40 kHz ที่สะอาด
> อย่างอื่นไม่มีความหมายเลย ต่อให้เสร็จแล้วอย่าเพิ่งไปต่อ — ทดสอบตามหัวข้อ 7 ให้ผ่านก่อน

---

## 1. สเปกที่ต้องได้

| รายการ | ค่าเป้าหมาย | เหตุผล |
|---|---|---|
| ไฟเลี้ยง | **3.3V เดี่ยว** | ต่อ ADC ของ ESP32 ตรงๆ ไม่มีทางที่แรงดันจะเกิน 3.3V ไปทำขา ADC พัง |
| VREF (จุดกึ่งกลาง) | **1.65V** | กึ่งกลางของ 3.3V — สัญญาณ AC แกว่งรอบจุดนี้ |
| เกนรวม | **121 → 2300** (ปรับได้) | ปรับตามความแรงจริงที่วัดได้ |
| แบนด์วิดท์ | **1.6 kHz – 159 kHz** | กว้างกว่าที่ต้องการมาก — ดูเหตุผลข้อ 2.3 |
| เอาต์พุต | **1.65V ± 1.5V** | ใช้ช่วง ADC ได้เต็มโดยไม่ตัดยอด |
| อิมพีแดนซ์ขาออก | **1 kΩ + 1nF** | ป้อน ADC ที่มัลติเพล็กซ์ได้แม่นยำ (ข้อ 2.5) |

---

## 2. หลักการออกแบบ — ทำไมถึงเป็นแบบนี้

### 2.1 ทำไมต้องเป็น non-inverting และ AC-coupled gain

ทรานสดิวเซอร์ที่ 40 kHz มีอิมพีแดนซ์ราว **2 kΩ** (`Xc = 1/(2π×40k×2.4nF) ≈ 1.66 kΩ`)
ถ้าใช้วงจร inverting อินพุตอิมพีแดนซ์จะเท่ากับ R อินพุตซึ่งจะไปโหลดทรานสดิวเซอร์ทิ้ง
**non-inverting** มีอินพุตอิมพีแดนซ์สูงมาก (MCP6024 กระแสไบแอส ~1 pA) จึงไม่แตะสัญญาณเลย

จุดสำคัญคือ **ขาล่างของเครือข่ายเกนต่อผ่านคาปาลงกราวด์**:

```
เกน DC  = 1        (คาปากั้น ไม่มีกระแสผ่าน Rg)
เกน AC  = 1 + Rf/Rg
```

ผลคือ **ออฟเซ็ตของ op-amp ไม่ถูกขยาย** เอาต์พุตนิ่งอยู่ที่ 1.65V เสมอ
และเพราะเกน DC ของทั้งสองสเตจเป็น 1 จึง**ต่อสเตจ 1 เข้าสเตจ 2 ตรงๆ ได้เลย
ไม่ต้องมีคาปาคั่นกลาง** — ประหยัด 2 ชิ้นต่อช่อง (18 ชิ้นเมื่อครบ 9 ช่อง) และตัดโพลทิ้งไป 1 ตัว
ซึ่งดีต่อความแม่นของเวลา (ข้อ 2.3)

### 2.2 ทำไมต้อง rail-to-rail และห้ามใช้ LM324

ที่ไฟเลี้ยง 3.3V สัญญาณต้องแกว่งรอบ 1.65V ให้ได้ ±1.5V คือเข้าใกล้รางทั้งสองข้าง
**LM324/LM358 เอาต์พุตขึ้นได้สูงสุดแค่ VDD−1.5V = 1.8V** แกว่งขึ้นได้แค่ 0.15V จากจุดกึ่งกลาง
คือใช้ไม่ได้เลย ไม่ใช่แค่ "ด้อยกว่า"

### 2.3 ทำไมแบนด์วิดท์ต้องกว้าง ไม่ใช่แคบ

สัญชาตญาณบอกว่า "สัญญาณอยู่ที่ 40 kHz ก็ทำฟิลเตอร์แคบๆ รอบ 40 kHz สิ" — **ผิด**

ฟิลเตอร์ทุกตัวมี **group delay** และ delay นั้นขึ้นกับค่า R/C ที่มีค่าคลาดเคลื่อน
ตัวต้านทาน ±5% คาปา ±10% แปลว่า**แต่ละช่องจะมี delay ไม่เท่ากัน** ซึ่งกลายเป็น error ของ Δt ตรงๆ

คำนวณจริงที่ 40 kHz สำหรับโพลเดี่ยวที่ความถี่ตัด fc:

| fc | group delay ที่ 40 kHz | คลาดเคลื่อนเมื่อ C ผิด ±10% |
|---|---|---|
| 60 kHz (ฟิลเตอร์แคบ) | 1.84 µs | **±0.18 µs** ต่อสเตจ |
| **159 kHz (ที่เลือก)** | **0.94 µs** | **±0.094 µs** ต่อสเตจ |
| 300 kHz | 0.52 µs | ±0.05 µs |

งบความคลาดเคลื่อนของเราคือ **σ(Δt) < 1 µs** ทั้งระบบ ฟิลเตอร์แคบกินงบไปเยอะเกินไปโดยไม่จำเป็น

**และเราไม่ต้องการฟิลเตอร์แคบอยู่แล้ว เพราะ:**
1. **ทรานสดิวเซอร์เองคือฟิลเตอร์ที่แคบที่สุดในระบบ** — Q สูง แบนด์วิดท์แค่ ~2 kHz
   มันกรองทุกอย่างนอก 39-41 kHz ทิ้งไปแล้วก่อนถึง op-amp ด้วยซ้ำ
2. การกรองที่เหลือทำใน Python ได้ฟรี และ**เป็น zero-phase** (ไม่มี group delay เลย)

> **บทเรียน: อย่ากรองด้วยอนาล็อกสิ่งที่กรองด้วยดิจิทัลได้ ถ้างานนั้นวัดเวลา**

### 2.4 ทำไม VREF ต้องบัฟเฟอร์

ตัวแบ่งแรงดัน 10k/10k มีอิมพีแดนซ์ขาออก **5 kΩ** ถ้าเอา VREF นั้นไปเลี้ยง 9 ช่องตรงๆ
กระแสที่ช่องหนึ่งดึงจะไปกระเพื่อม VREF ซึ่งเป็นจุดอ้างอิงของอีก 8 ช่อง
= **crosstalk ระหว่างช่อง** ซึ่งเป็นสิ่งที่อาร์เรย์กลัวที่สุด

บัฟเฟอร์ด้วย op-amp 1 section ทำให้อิมพีแดนซ์เหลือ <1 Ω ตัดปัญหาทิ้งทั้งหมด
**op-amp 1 ตัวนี้คุ้มที่สุดในวงจร**

### 2.5 ทำไมต้องมี 1 kΩ + 1 nF ที่ขาออก — เหตุผลที่ไม่ใช่ anti-alias

`fc = 1/(2π × 1k × 1n) = 159 kHz` ซึ่งอยู่ใต้ Nyquist (166 kHz ที่ 333 kS/s ต่อช่อง) พอดี
นั่นคือเหตุผลข้อแรก แต่**เหตุผลที่สำคัญกว่าคือคาปาตัวนี้เป็นถังเก็บประจุให้ ADC**

ESP32 อ่าน 6 ช่องแบบ**สลับกันทีละช่อง** วงจร sample-and-hold ข้างในมีคาปา ~2 pF
ที่ยังค้างแรงดันของ*ช่องก่อนหน้า*อยู่ พอสลับมาช่องเรา มันจะแบ่งประจุกัน:

```
ความผิดพลาด = C_sh / (C_sh + C_out) = 2pF / (2pF + 1nF) = 0.2%
```

ถ้าไม่มีคาปา 1nF ตัวนี้ ความผิดพลาดจะขึ้นอยู่กับว่าช่องข้างๆ มีแรงดันเท่าไหร่
= **ช่องหนึ่งไปกวนอีกช่องหนึ่งผ่านตัว ADC เอง** ซึ่งไล่บั๊กยากมาก

### 2.6 ต้านทานหน่วง (damping) ที่ทรานสดิวเซอร์ — ไม่ต้องใส่ตอนแรก

หลายคนจะแนะนำให้ใส่ R คร่อมทรานสดิวเซอร์เพื่อลดการสั่นค้าง แต่ดูตัวเลขก่อน:
ที่ 40 kHz ทรานสดิวเซอร์มี |Z| ≈ 1.66 kΩ ดังนั้น **R 100k ไม่ทำอะไรเลย**
ต้องลงมาถึง ~2-5 kΩ ถึงจะหน่วงจริง ซึ่งแลกมาด้วยการเสียแอมพลิจูดครึ่งหนึ่ง

**และการสั่นค้างของตัวรับไม่ใช่ปัญหาหลัก — ตัวส่งต่างหาก** ตัวส่งคือตัวที่ดังจนบังทุกอย่าง
เริ่มโดยไม่ใส่ R หน่วงก่อน ถ้า Stage 2 พบว่า echo ยืดจนแยกไม่ออกค่อยลอง 4.7 kΩ

---

## 3. วงจร

```
                             ┌──────────── 3.3V ราง (บน แดง) ────────────┐
                             │                                            │
     TCT40-16R               │        MCP6024 / MCP6004 (DIP-14)          │
      ┌─────┐                │   ┌────────────────┐                       │
   ┌──┤  R  ├──┐             └───┤4  VDD          │                       │
   │  └─────┘  │      Cin        │                │                       │
   │           └───┤├────┬───────┤3  +INA     OUTA├─1──┬──────────────────┼─→ ไปสเตจ 2
   │              10nF   │       │                │    │                  │
   │                     │       │             -INA├─2─┤                  │
  GND                  R_bias    └────────────────┘    │                  │
                        1M                             │                  │
                         │        ┌───── Rf1 33k ──────┘                  │
                         │        │                                       │
                         └────────┼───→ ราง VREF (ล่าง แดง)               │
                                  │                                       │
                            pin2 ─┴─ Rg1 1k ─── Cg1 100nF ─── GND         │
                                                                          │
    ┌─────────────────────────────────────────────────────────────────────┘
    │  (ต่อตรง ไม่ต้องมีคาปาคั่น — เพราะเกน DC ของสเตจ 1 = 1)
    │
    └─5──┤+INB      OUTB├─7──┬── R_out 1k ──┬──→ GPIO34 (ADC1_CH6)
         │              │    │              │
      6──┤-INB          │    │            C_out
         └──────────────┘    │             1nF
              │              │              │
              └── Rf2 33k ───┘             GND
              │
            Rg2 1k ─── Cg2 100nF ─── GND

    ═══ วงจรสร้าง VREF (ทำครั้งเดียว เลี้ยงได้ทั้ง 9 ช่อง) ═══

    3.3V ──┬── R 10k ──┬── R 10k ── GND
           │           │
           │        ┌──┴──┐
           │        │ 10  │  +INC  ┐
           │        │     │        ├── MCP6024 section C = ตัวตาม (buffer)
           │      9─┤-INC │        │
           │        │   8 ├─ OUTC ─┴──┬──→ ราง VREF (ล่าง แดง)
           │        └──┬──┘           │
           │           └──────────────┘  (ป้อนกลับ pin8 → pin9)
           │
        C 10µF ─┬─ C 100nF ─── GND     ← คร่อมจุดกึ่งกลางตัวแบ่ง
                │
               GND
```

---

## 4. รายการอุปกรณ์ต่อ 1 ช่อง

| ตัว | ค่า | ชนิด | หน้าที่ |
|---|---|---|---|
| Cin | **100 nF** | เซรามิก | กั้น DC จากทรานสดิวเซอร์ (`fc = 1/(2π×10k×100n) = 159 Hz`) |
| R_bias | **10 kΩ** | 1/4W | ดึงขาอินพุตไปที่ 1.65V (ดูข้อ 4.1) |
| Rf1, Rf2 | **100 kΩ** | 1/4W | กำหนดเกน — ดูตารางข้อ 5 |
| Rg1, Rg2 | **10 kΩ** | 1/4W | ขาล่างของเครือข่ายเกน |
| Cg1, Cg2 | **1 nF** | เซรามิก | ทำให้เกน DC = 1 + ตัดฮัม (ดูข้อ 4.1) |
| R_out | **2.2 kΩ** | 1/4W | จำกัดแบนด์วิดท์ + ป้องกันขา ADC (`fc = 72 kHz`) |
| C_out | **1 nF** | เซรามิก | anti-alias + ถังประจุให้ ADC (ข้อ 2.5) |

> **ค่าชุดนี้เลือกจากของที่มีจริงในกล่อง** (1M / 100k / 10k / 2.2k / 100Ω และ
> 470µF / 100µF / 10µF / 100nF / 1nF) — ให้ผลเทียบเท่าค่าออกแบบเดิมทุกประการ
> เพราะเกนขึ้นกับ**อัตราส่วน** Rf/Rg เท่านั้น: `100k/10k = 10k/1k`
>
> ข้อดีที่ได้เพิ่มมาโดยบังเอิญ: Rg 10kΩ กินกระแสจากขาออก op-amp น้อยกว่า 1kΩ ถึง 10 เท่า
> ซึ่งช่วยให้ MCP6004 (ขับกระแสได้จำกัด) แกว่งได้ใกล้รางมากขึ้น

**ต่อ 1 ชิป (4 ช่อง หรือ 2 ช่อง + VREF):**

| ตัว | ค่า | หน้าที่ |
|---|---|---|
| C_dec | 100 nF เซรามิก | **คร่อมขา 4 กับ 11 โดยตรง ห่างไม่เกิน 1 cm** |
| C_bulk | 10 µF อิเล็กโทรไลต์ | รางไฟใกล้ชิป |
| R_ref1, R_ref2 | 10 kΩ | ตัวแบ่ง VREF (ทำครั้งเดียวทั้งบอร์ด) |
| C_ref1 | 10 µF | กรอง VREF |
| C_ref2 | 100 nF | กรอง VREF ความถี่สูง |

---

> **ผังต่อสายจริงบนบอร์ดทดลอง**: ดู [`diagrams/`](diagrams/) — SVG 4 แผ่น
> (ไฟเลี้ยง+VREF / อินพุต+สเตจ 1 / สเตจ 2+ขาออก / สะพานข้ามช่องว่างกลางราง)
> เป็นเวอร์ชันหลังแก้ปัญหาทั้งหมดแล้ว

### 4.1 แก้ปัญหาฮัม 50 Hz — ทำไม R_bias และ Cg ถึงเปลี่ยนค่า

วงจรรุ่นแรกใช้ `R_bias = 1 MΩ` (ต่อมาลดเป็น 100 kΩ) กับ `Cg = 100 nF` ต่อบอร์ดทดลองจริง
แล้ววัดด้วย ADC ของ ESP32 ได้ผลดังนี้ — **จุดปฏิบัติการ DC ถูกต้องทุกจุด** (สเตจ 1 = 1.572 V,
สเตจ 2 = 1.575 V เทียบกับ VREF 1.65 V) แต่ทั้งสองสเตจ **แกว่งเต็มราง 3.3 Vpp ที่ 50 Hz**
(1037 mV และ 1059 mV) คือไฟบ้านเข้ามาทางโหนดอินพุต ไม่ใช่วงจรกวนตัวเอง

ที่มาของฮัม: โหนดอินพุตมีอิมพีแดนซ์ต่อกราวด์ประมาณ `R_bias` เพราะที่ 50 Hz ทรานสดิวเซอร์
(2.4 nF) เป็นอิมพีแดนซ์ 1.3 MΩ แทบเปิดวงจร ประจุเหนี่ยวนำจากสายไฟบ้านผ่านความจุจรจร
ราว 10 pF ให้กระแส ~0.66 µA ตกคร่อม 100 kΩ = 66 mV ซึ่งถูกขยายจนอิ่มตัว

การแก้ใช้สองทางพร้อมกัน:

| เปลี่ยน | ผลต่อ 50 Hz | ผลต่อ 40 kHz |
|---|---|---|
| `R_bias` 100 kΩ → **10 kΩ** | แรงดันฮัมที่เกิดขึ้นลดลง 10 เท่า และความถี่ตัดล่างของ `Cin`/`R_bias` ขยับจาก 16 Hz → 159 Hz ทอน 50 Hz เพิ่มอีก 3.3 เท่า | โหลดทรานสดิวเซอร์ (Zs ≈ 1.66 kΩ) เสียสัญญาณ 14% |
| `Cg1, Cg2` 100 nF → **1 nF** | เกนต่อสเตจที่ 50 Hz ลดจาก 4.0 → 1.03 สองสเตจรวมลด 16 เท่า | เกนต่อสเตจลดจาก 11 → 10.3 เท่านั้น |

รวมแล้วทอน 50 Hz ลงราว **500 เท่า** (1059 mV → ~2 mV) ขณะที่เกนที่ 40 kHz ลดจาก 121 → 106
และเหลือ ~91 หลังคิดการโหลดทรานสดิวเซอร์ ซึ่งยังเกินพอ

> **หลักที่ได้จากเรื่องนี้**: `Cg` ไม่ได้มีหน้าที่แค่ "ทำให้เกน DC = 1" อย่างที่มักอธิบายกัน
> มันคือ **ตัวกำหนดรูปร่างของเกนเทียบความถี่** เลือก `fc = 1/(2π·Rg·Cg)` ให้อยู่ใต้ 40 kHz
> ไม่มากนัก (ที่ 1 nF/10 kΩ ได้ 15.9 kHz) จะได้ทั้งเกนเต็มที่ย่านใช้งานและกดย่านต่ำทิ้งไปด้วย

**ตำแหน่งบนบอร์ดทดลอง** (ผังชุด 3 แผ่น): R_bias อยู่ที่ `18c → 14c`,
Cg1 อยู่ที่ `31d → 33d`, Cg2 อยู่ที่ `43a → 45a` — ระวังสับสนกับ Rg2 10 kΩ ที่ `39e → 43e`
ซึ่งอยู่แถวเดียวกันแต่คนละคอลัมน์

---

## 4.2 สถานะจริง: ภาครับ 4 ช่อง บนสองบอร์ด + ทำไมช่องถึงแมตช์ (ส.ค. 2026)

ตอนนี้ต่อครบ 4 ช่องบน **สองบอร์ดทดลอง** โดยบอร์ดใหม่ยืมไฟและ VREF จากบอร์ดเก่า:

```
      บอร์ด 1 (เก่า)                          บอร์ด 2 (ใหม่)
 ┌──────────────────────────┐           ┌──────────────────────────┐
 │  MCP6004 #1              │  3.3V ───▶ │  MCP6004 #2              │
 │   g35 (A140) ──────▶IO35 │  GND  ───▶ │   g32 (A80) ───────▶IO32 │
 │   g34 (C140) ──────▶IO34 │  VREF ───▶ │   g33 (C80) ───────▶IO33 │
 │                          │ (1.65V     │                          │
 │  ตัวแบ่ง VREF 10k/10k     │  บัฟเฟอร์   │  ★ ไม่มีตัวแบ่ง/บัฟเฟอร์  │
 │   + บัฟเฟอร์ (ทำที่นี่)   │  แล้ว)     │    ของตัวเอง — ยืมมาทั้งเส้น│
 └──────────────────────────┘           └──────────────────────────┘
   สายข้ามบอร์ด 3 เส้น: 3.3V · GND · VREF(บัฟเฟอร์แล้ว)
```

> หมายเหตุ mapping: ไล่สายจริงแล้ว **IO34 = หัว C140, IO35 = หัว A140** (สลับจากที่เคยจดไว้)

**ข้อสังเกตที่วัดได้จริง (โหมด `--track`):**

| คู่ (ชิปเดียวกัน) | amp | แมตช์ไหม |
|---|---|---|
| g32 / g33 (บอร์ด 2, A80/C80) | 89 / 107 | ✅ ~1.2 เท่า |
| g34 / g35 (บอร์ด 1, C140/A140) | 15 / 62 | ❌ ~4 เท่า |

ทั้งสองคู่ใช้ **ชิปเดียว · ค่า R เท่ากัน · VREF/ไฟเส้นเดียวกัน** แต่คู่บอร์ด 2 แมตช์ คู่บอร์ด 1 ไม่แมตช์

> **[แก้ 2026-08-19]** สาเหตุที่ g34 เบา = **วงจรช่อง g34 เกนต่ำเอง ไม่ใช่หัวรับ** — ลองหัวรับ
> 3 ตัว amp ค้างที่ 17 เท่าเดิมทั้งหมด (ถ้าเป็นหัว amp ต้องเปลี่ยนตามหัว) g34 อ่านระยะถูก (85≈82)
> แต่เกนต่ำ ~3 เท่าตายตัว ต้องหาที่วงจร: Rf ผิดค่า / จุดบัดกรีต้านทานสูง / สเตจใดสเตจหนึ่งเกนตก
> — เช็ค DC ขาออก OUTA/OUTB (ต้อง 1.65V) + วัดค่า Rf ทั้งสองสเตจเทียบ g35 หรือทดสอบเกนด้วย
> DAC ตาม §7 ขั้น 3 · (ครั้งแรกสรุปผิดว่าเป็นหัว/เรโซแนนซ์ จาก swap test ที่ไม่สะอาด)

**หลักการแมตช์ช่อง — จำไว้ตอนขยายเป็น 9 ช่อง:**

> ให้ช่องแมตช์กันต้องได้ **ครบสองอย่าง**: (1) **วงจรสร้างเหมือนกันจริง** — ชิปรุ่นเดียว + R
> ค่าเท่ากัน (วัดยืนยัน ไม่ใช่แค่หยิบมาเสียบ) + VREF/ไฟเส้นเดียวกัน และ (2) **หัวรับเข้าคู่กัน**
> (คัดด้วย `tools/match_transducers.py` ตาม f0) · g32/g33 แมตช์เพราะได้ครบ · **g34/g35 พังเพราะ
> ข้อ (1) ไม่จริง — วงจรช่อง g34 เกนต่ำเอง (ลอง 3 หัว amp เท่าเดิม) แม้อยู่ชิป/VREF เดียวกับ g35**
> = แต่ละช่องต้องวัดยืนยันทีละช่อง อย่าเชื่อว่า "ต่อเหมือนกันแล้วต้องเท่ากัน"

> เกร็ด (ต่อยอดข้อสังเกตเรื่อง VREF ร่วม): VREF ที่ใช้ร่วมกันคุม **จุดไบแอส DC** ให้เท่ากัน —
> สำคัญเรื่อง headroom และกัน crosstalk ตาม §2.4 · ส่วน **ความแรง AC** ของเอคโค่มาจาก
> อัตราส่วน Rf/Rg + GBW ของชิป + ความไวหัวรับ การที่ g32/g33 แรงใกล้กันจึงมาจาก "สร้าง
> เหมือนกันทุกอย่าง" (ซึ่ง VREF/ไฟร่วมเป็นส่วนหนึ่ง) บวกกับหัวที่บังเอิญเข้าคู่กัน

---

## 5. ตารางเลือกเกน — **เริ่มที่ 121 เสมอ**

`เกนต่อสเตจ = 1 + Rf/Rg` โดย Rg = 1 kΩ ตายตัว เปลี่ยนแค่ Rf

| Rf | Rg | เกน/สเตจ | เกนรวม 2 สเตจ | รับอินพุตได้สูงสุด | BW กับ MCP6004 |
|---|---|---|---|---|---|
| **100 kΩ** | **10 kΩ** | **11** | **121** | **25 mVpp** | 91 kHz ✅ |
| 100 kΩ | 2.2 kΩ | 46.5 | 2160 | 1.4 mVpp | 21 kHz ❌ |
| 10 kΩ | 2.2 kΩ | 5.5 | 30 | 100 mVpp | 182 kHz ✅ |

**ถ้าเกน 121 ยังน้อยไป อย่าเพิ่ม Rf** — MCP6004 มี GBW แค่ 1 MHz เกินกว่านี้แบนด์วิดท์
จะตกต่ำกว่า 40 kHz ให้**เพิ่มสเตจที่ 3 ด้วย section D (ขา 12-13-14 ที่ยังว่าง)**
ใช้ 100k/10k เหมือนเดิม → เกนรวม 11³ = **1331** โดยแบนด์วิดท์ยังเป็น 91 kHz

> **เริ่มที่ Rf = 10k เสมอ** เพราะถ้าเกนสูงเกินไป เอาต์พุตจะตัดยอดจนดูไม่ออกว่าเกิดอะไรขึ้น
> แต่ถ้าเกนต่ำไป คุณแค่เห็นสัญญาณเล็ก — ซึ่ง**วินิจฉัยได้ง่ายกว่ามาก**
> ค่อยๆ เพิ่มขึ้นทีละขั้นจนเห็น echo ชัดโดยไม่ตัดยอด

⚠️ **ช่อง BW ที่ขึ้น ❌ คือกรณีที่แบนด์วิดท์ลงมาต่ำกว่า 40 kHz แล้ว** สัญญาณจะถูกลดทอน
และ group delay จะพุ่ง — **ห้ามใช้ MCP6004 กับ Rf เกิน 22k**
ถ้าต้องการเกินกว่านั้นระหว่างรอ MCP6024 ให้**ซอยเป็น 3 สเตจ × 11 = 1331** แทน (BW ยังเป็น 91 kHz)

---

## 6. ผังต่อบน breadboard — ทีละแถว

### เวอร์ชันนี้ใช้กับผัง ESP32 เสียบคร่อมกลางสองบอร์ด

ผังเดิม (ESP32 ต่อด้วยสายจั๊ม รางไฟสองฝั่ง) ถูกแทนที่แล้ว **ยึดสี่ไฟล์นี้เป็นหลัก**

| ผัง | ครอบคลุม |
|---|---|
| [`diagrams/rxv2_1_power_chip_vref.svg`](diagrams/rxv2_1_power_chip_vref.svg) | ไฟเลี้ยง · ชิป · VREF |
| [`diagrams/rxv2_2_input_stage1.svg`](diagrams/rxv2_2_input_stage1.svg) | ทรานสดิวเซอร์ · Cin · R ไบแอส · สเตจ 1 |
| [`diagrams/rxv2_3a_stage2.svg`](diagrams/rxv2_3a_stage2.svg) | สเตจ 2 |
| [`diagrams/rxv2_3b_output.svg`](diagrams/rxv2_3b_output.svg) | R_out · C_out · สายไป GPIO34 |

ทั้งสี่ผังเรนเดอร์จาก [`rx_layout_v2.py`](rx_layout_v2.py) ซึ่งเก็บรายการต่อสายไว้ชุดเดียว
รันใหม่ด้วย `python hardware/rx_layout_v2.py` ภาพกับรายการจึงขัดกันเองไม่ได้

### เลขแถวในผังชุดนี้หมายถึงอะไร

**แถว 60 = ปลายบอร์ดฝั่งที่มีช่อง USB ของ ESP32 · แถว 1 = ปลายไกล**
ขาทั้ง 19 ของ DevKit ลงคอลัมน์ J แถว 42-60 เหลือแถว 1-41 ให้วงจร

| แถว | ขา ESP32 | | แถว | ขา ESP32 |
|---|---|---|---|---|
| 42 | 3V3 | | 51 | IO26 |
| 43 | EN | | 52 | IO27 |
| 44 | SVP (IO36) | | 53 | IO14 |
| 45 | SVN (IO39) | | 54 | IO12 |
| 46 | **IO34** | | 55 | **GND** |
| 47 | IO35 | | 56 | IO13 |
| 48 | IO32 | | 57 | SD2 |
| 49 | IO33 | | 58 | SD3 |
| 50 | IO25 | | 59 | CMD |
| | | | 60 | 5V |

**ถ้าเลขบนบอร์ดคุณกลับทาง** ให้ใช้เลขจากขอบที่ทำให้ปลาย USB เป็นแถว 60 บอร์ดพิมพ์เลข
สองขอบวิ่งคนละทาง เลือกขอบเดียวแล้วยึดตลอด แล้วเช็คว่า **ขา IO34 ตรงกับแถว 46**

### ทิศทางของสัญญาณ — ข้อนี้ไม่ใช่ความสวยงาม

อินพุตอยู่ปลายไกล (แถว 5) ขาออกอยู่ใกล้ ESP32 (แถว 34 → 46) **ห้ามสลับ** ถ้าอินพุตอยู่ใกล้
ESP32 สายขาออกจะต้องวิ่งย้อนกลับผ่านโหนดอินพุต ที่เกน 121 เท่า ความจุแฝงไม่กี่ pF
ก็กลายเป็นการป้อนกลับเชิงบวก ไม่ใช่แค่ความไม่เป็นระเบียบ

### ตำแหน่งชิป

วาง MCP6004 คร่อมร่องกลาง **ขา 1 อยู่แถว 12** ขาลงคอลัมน์ E (ขา 1-7) และ F (ขา 8-14)

| ขา | ชื่อ | แถว | ฝั่ง |
|---|---|---|---|
| 1 | OUTA | 12 | E |
| 2 | −INA | 13 | E |
| 3 | +INA | 14 | E |
| 4 | **VDD** | 15 | E |
| 5 | +INB | 16 | E |
| 6 | −INB | 17 | E |
| 7 | OUTB | 18 | E |
| 8 | OUTC | 18 | F |
| 9 | −INC | 17 | F |
| 10 | +INC | 16 | F |
| 11 | **VSS** | 15 | F |
| 12 | +IND | 14 | F |
| 13 | −IND | 13 | F |
| 14 | **OUTD** | 12 | F |

> **ขา 12 กับ 14 เคยสลับกันในตารางนี้** (แก้ 26 ส.ค. 2026) โค้ดวาดผังใช้ค่าที่ถูกมาตลอด
> (`rx_ch34_layout.py` บรรทัด 17 · `perf_rx_layout.py` บรรทัด 500) ผังที่บัดกรีจึงไม่ได้รับผลกระทบ
> แต่ถ้าใครยึดตารางนี้จะต่อสัญญาณเข้า OUTD แล้วดึงออกจากอินพุต — วงจรไม่ทำงาน

### กฎจำง่าย: ขา n คู่กับขา (15 − n)

ควอดออปแอมป์ DIP-14 สมมาตรแบบหมุน 180° ทุกคู่ทำหน้าที่เดียวกัน **ยกเว้นคู่เดียว**

| ซ้าย | ขวา | หน้าที่ |
|---|---|---|
| 1 OUTA | 14 OUTD | ขาออกทั้งคู่ |
| 2 −INA | 13 −IND | อินพุตลบ |
| 3 +INA | 12 +IND | อินพุตบวก |
| **4 VDD** | **11 VSS** | ⚠️ **ไฟบวก กับ กราวด์ — ตรงข้ามกัน** |
| 5 +INB | 10 +INC | อินพุตบวก |
| 6 −INB | 9 −INC | อินพุตลบ |
| 7 OUTB | 8 OUTC | ขาออก |

**ขา 4 กับ 11 คือกับดักของกฎนี้** — สะท้อนผังทั้งดุ้นเมื่อไหร่จะจ่าย 3V3 เข้าขา 11
และ GND เข้าขา 4 = ชิปพังทันที ต้องเดินสายไฟเลี้ยงสองขานี้แยกกันเสมอ

### ใช้คาปาตัวไหนตรงไหน — ระยะขาเป็นตัวบังคับ

ฟิล์ม WIMA MKS2 0.1µF ระยะขา **5 มม. = 2 รูพอดี** (2 × 2.54 = 5.08)
**ผังชุดนี้ออกแบบให้ทุกจุดเว้น 2 แถว** จึงใช้ WIMA ได้หมดโดยไม่ต้องดัดขา

| จุด | ระยะ | ใช้ตัวไหน | เหตุผล |
|---|---|---|---|
| Cin `5C→7C` | 5.1 มม. | **ฟิล์ม WIMA** | อยู่ในทางเดินสัญญาณ เซรามิก X7R เป็นพีโซอิเล็กทริก มันสั่นแล้วสร้างสัญญาณเอง ซึ่งเป็นสิ่งเดียวกับที่โอริงบนแผงพยายามกันอยู่ |
| บายพาสชิป `19D→21D` | 5.1 มม. | **ฟิล์ม WIMA** | ดูหัวข้อถัดไปว่าทำไมถึงย้ายมาไว้ตรงนี้ |
| คาปาที่ราง | ~5 มม. | ฟิล์มหรือเซรามิกก็ได้ | |
| Cg1 Cg2 C_out 1nF | 5.1 มม. | เซรามิก | ไม่มีตัวเลือกอื่นที่ค่านี้ |

### คาปามีขั้ว — 10µF สองตัวเท่านั้น

ในวงจรนี้มีคาปาที่ใส่กลับด้านไม่ได้อยู่ **2 ตัว** คือ 10µF ทั้งคู่ ที่เหลือ (ฟิล์ม เซรามิก) ไม่มีขั้ว
สลับได้อิสระ

| ตัว | ขา **+** ไปที่ | ขา **−** ไปที่ |
|---|---|---|
| 10µF ที่ราง | ราง **แดง** (3.3V) | ราง **น้ำเงิน** |
| 10µF กรอง VREF | `9D` (โหนด 1.65V) | `11D` (ต่อลงรางน้ำเงิน) |

**ดูขั้วบนตัวมันยังไง** — อิเล็กโทรไลต์ทรงกระป๋องมีสองอย่างบอกเสมอ

1. **แถบสีขาวหรือเทาคาดข้างกระป๋อง มีเครื่องหมาย −** พิมพ์อยู่ → ขาฝั่งนั้นคือขาลบ
2. **ขายาว = +, ขาสั้น = −** (ถ้ายังไม่ตัดขา)

ในผังใช้สีบอก: **จุดแดง = ขา + · จุดดำ = ขา −** และตัวคาปาในผังมีแถบเข้มอยู่ครึ่งฝั่งลบ

> ⚠️ **เสียบกลับขั้วแล้วมันระเบิด** ไม่ใช่สำนวน — อิเล็กโทรไลต์ที่โดนไบแอสกลับจะเกิดแก๊สข้างใน
> แล้วดันฝาด้านบนแตก มีของเหลวกระเด็น ที่ 3.3V อาจใช้เวลาหลายนาทีถึงจะเกิด แต่มันเกิดแน่
> ถ้าเสียบผิดแล้วรู้ตัว **ถอดออกแล้วทิ้งเลย** อย่าเอากลับมาใช้ ค่าความจุมันเสียไปแล้ว

### ทำไมบายพาสถึงย้ายจาก `15D→15G` ไป `19D→21D`

ขา 4 (VDD) กับขา 11 (VSS) อยู่คนละฝั่งของร่องกลาง รูที่ใกล้ที่สุดซึ่งไม่ใช่ตัวขาชิปเอง
คือ D กับ G = **12.7 มม.** ซึ่งไกลเกินระยะขาของคาปาฟิล์ม แถวแบบเดิมจึงบังคับให้ต้องใช้
เซรามิกแผ่นกลมที่ขาบางถ่างง่ายอย่างเดียว

ทางออกคือ**สร้างคู่โหนด VDD/GND ขึ้นมาใหม่ให้ห่างกัน 2 แถว** — จัมเปอร์ลาก VDD จาก `15A`
ลงมาที่แถว 19 และเดินสายจากแถว 21 ลงรางลบ คาปาจึงเสียบระหว่างแถว 19 กับ 21 ได้พอดีขา

**ผลทางไฟฟ้าของการย้ายห่างจากขาชิป ~10 มม. เป็นศูนย์ในทางปฏิบัติ** ตัวเลขที่ 40 kHz:

```
คาปา 100nF   1/(2π × 40k × 100n)  =  40 Ω
คาปา 10µF    1/(2π × 40k × 10µ)   = 0.4 Ω   ← ตัวนี้คุมอิมพีแดนซ์ไฟเลี้ยงอยู่
สายเพิ่ม 5 ซม.  2π × 40k × 50n     = 0.013 Ω = 3% ของ 0.4 Ω
```

ที่ความถี่ของเรา **ตัวที่ทำงานจริงคือ 10µF ไม่ใช่ 100nF** ส่วน 100nF รับย่านความถี่สูงกว่านั้นมาก
ซึ่งวงจรนี้ไม่มีสัญญาณอยู่แล้ว กฎ "คาปาบายพาสต้องติดขาชิป" มาจากวงจรดิจิทัลที่กระแสเปลี่ยน
ระดับแอมป์ในเวลานาโนวินาที — MCP6004 กินกระแส 100 µA ต่อออปแอมป์ และไม่มีขอบสัญญาณแบบนั้น

ถ้าคุณมีเซรามิก 104 อยู่แล้วและอยากทำตามตำรา เสียบคร่อม `15D→15G` แทนได้ ผลเท่ากัน

### ลำดับการต่อ — ต่อทีละบล็อก แล้ววัดทุกบล็อก

**บล็อก 1: ไฟเลี้ยง** *(ยังไม่ต้องเสียบชิป)*

| # | ต่อ | จาก | ไป |
|---|---|---|---|
| 1 | สาย | `42H` | ราง **+** |
| 2 | สาย | `55H` | ราง **−** |
| 3 | สะพาน | ราง + ครึ่งบน | ราง + ครึ่งล่าง |
| 4 | สะพาน | ราง − ครึ่งบน | ราง − ครึ่งล่าง |
| 5 | C 10µF | ราง + | ราง − (ขา + ไปแดง) |
| 6 | C 100nF | ราง + | ราง − |

> 🔍 **วัด**: ราง + ↔ ราง − ต้องได้ **3.30V ± 0.1V** และต้องได้เท่ากันทั้งครึ่งบนและครึ่งล่าง

**บล็อก 2: เสียบชิป + ไฟเลี้ยงชิป**

| # | ต่อ | จาก | ไป |
|---|---|---|---|
| 7 | MCP6004 | ขา 1 ที่แถว 12 | คร่อมร่องกลาง |
| 8 | สาย | `15B` | ราง **+** |
| 9 | สาย | `15H` | ราง **−** |
| 10a | จัมเปอร์ | `15A` | `19A` — ลาก VDD ลงมา |
| 10b | **C 100nF** | `19D` | `21D` — เว้น 2 แถว |
| 10c | สาย | `21C` | ราง **−** — ทำ GND ท้องถิ่น |
| 11 | จัมเปอร์ | `12J` | `15J` — ขา 14 ลงกราวด์ |
| 12 | จัมเปอร์ | `13G` | `14G` — ขา 13 ต่อขา 12 |

**บล็อก 3: VREF**

| # | ต่อ | จาก | ไป |
|---|---|---|---|
| 13 | R 10k | ราง **+** | `9B` |
| 14 | R 10k | `9C` | ราง **−** |
| 15 | C 10µF | `9D` | `11D` (ขา + ไปแถว 9) |
| 16 | สาย | `11C` | ราง **−** |
| 17 | จัมเปอร์ | `9E` | `16G` — เข้าขา 10 |
| 18 | จัมเปอร์ | `17G` | `18G` — ขา 9 ต่อขา 8 |
| 19 | จัมเปอร์ | `18H` | `2B` — VREF ที่บัฟเฟอร์แล้ว |

> 🔍 **วัด**: `9B` ↔ GND ต้องได้ **1.65V ± 0.05V** และ `2B` ต้องได้เท่ากัน
> ถ้าแถว 9 ได้ 1.65V แต่แถว 2 ไม่ได้ แปลว่าบัฟเฟอร์ไม่ทำงาน อย่าไปต่อ

**บล็อก 4: อินพุตและสเตจ 1**

| # | อุปกรณ์ | จาก | ไป |
|---|---|---|---|
| 20 | ทรานสดิวเซอร์ ขั้ว 1 | — | `5B` |
| 21 | ทรานสดิวเซอร์ ขั้ว 2 | — | ราง **−** |
| 22 | Cin 100nF | `5C` | `7C` |
| 23 | R_bias 10k | `7D` | `2D` |
| 24 | จัมเปอร์ | `7A` | `14A` — เข้าขา 3 |
| 25 | Rf1 100k | `12B` | `22B` |
| 26 | จัมเปอร์ | `13D` | `22D` — ขา 2 |
| 27 | Rg1 10k | `22A` | `25A` |
| 28 | Cg1 1nF | `25B` | `27B` |
| 29 | สาย | `27C` | ราง **−** |

> 🔍 **วัด**: `12B` ↔ GND ต้องได้ **1.65V ± 0.05V** ถ้าได้ 0V หรือ 3.3V คืออิ่มตัว
> ให้ย้อนไปตรวจข้อ 23-24 ก่อนอย่างอื่น

**บล็อก 5: สเตจ 2**

| # | อุปกรณ์ | จาก | ไป |
|---|---|---|---|
| 30 | จัมเปอร์ | `12C` | `16C` — ขา 1 เข้าขา 5 |
| 31 | จัมเปอร์ | `18B` | `30A` |
| 32 | Rf2 100k | `30B` | `34B` |
| 33 | จัมเปอร์ | `17D` | `34D` — ขา 6 |
| 34 | Rg2 10k | `34A` | `37A` |
| 35 | Cg2 1nF | `37B` | `39B` |
| 36 | สาย | `39C` | ราง **−** |

**บล็อก 6: ขาออก**

| # | อุปกรณ์ | จาก | ไป |
|---|---|---|---|
| 37 | จัมเปอร์ | `18D` | `30G` |
| 38 | R_out 2.2k | `30H` | `34H` |
| 39 | C_out 1nF | `34G` | `36G` |
| 40 | สาย | `36F` | ราง **−** |
| 41 | สาย | `34I` | `46H` = **GPIO34** |

> 🔍 **วัด**: `18E` (ขา 7) และ `34H` ต้องได้ **1.65V ± 0.1V** ทั้งคู่

---

## 7. การทดสอบ — 4 ขั้น ห้ามข้าม

### ขั้น 1 — ไฟนิ่ง (ใช้แค่มัลติมิเตอร์)

| จุดวัด | ค่าที่ต้องได้ |
|---|---|
| รางบนแดง | 3.30V ± 0.1V |
| แถว 6 (ก่อนบัฟเฟอร์) | 1.65V ± 0.05V |
| รางล่างแดง (VREF) | 1.65V ± 0.05V |
| ขา 1 (ออกสเตจ 1) | 1.65V ± 0.05V |
| ขา 7 (ออกสเตจ 2) | 1.65V ± 0.1V |

**ถ้าขา 1 หรือ 7 ไม่ได้ 1.65V ให้หยุด** วงจรอิ่มตัว ไปต่อไม่ได้

### ขั้น 2 — ทดสอบชีพจร (นิ้วมือ)

แตะนิ้วที่แถว 14 (ขาอินพุต) แล้วดูเอาต์พุตด้วย `esp32_selftest`
ร่างกายคุณรับไฟบ้าน 50 Hz อยู่ **เอาต์พุตต้องกระเพื่อมชัดเจน**

ถ้าไม่กระเพื่อมเลย = วงจรไม่ขยาย ให้กลับไปดูบล็อก 5-6
(50 Hz ต่ำกว่าย่านผ่านของเรา แต่ที่เกน 121 มันแรงพอจะเห็นอยู่ดี)

### ขั้น 3 — วัดเกนจริงด้วยตัวเลข ⭐ **ขั้นที่สำคัญที่สุด**

ใช้ DAC ของ ESP32 เป็นเครื่องกำเนิดสัญญาณ ผ่านตัวลดทอน ÷1000:

```
GPIO26 ──[ R 100kΩ ]──┬──→ แถว 14 (อินพุตวงจร)   ← ถอดทรานสดิวเซอร์ออกก่อน
                      │
                  [ R 100Ω ]
                      │
                     GND
```

> ใช้ **GPIO26 (DAC2)** ไม่ใช่ GPIO25 เพราะ GPIO25 ถูกใช้ขับ 74HCT04 ของภาคส่งไปแล้ว
> สั่งเปิดด้วย `python tools/esp32_cmd.py --port COM5 "d 40000"` (สั่ง `d 0` เพื่อปิด)

DAC ให้ ~0.8 Vpp → ผ่านตัวลดทอนเหลือ **0.80 mVpp** ที่อินพุต

| เกนที่ตั้ง | เอาต์พุตที่ควรวัดได้ |
|---|---|
| 121 (Rf=10k) | **0.097 Vpp** |
| 529 (Rf=22k) | **0.42 Vpp** |
| 1156 (Rf=33k) | **0.92 Vpp** |

รันแล้วดูค่า `Vpp` ที่ `scope_view.py` พิมพ์ออกมา **ถ้าตรงตามตาราง ±20% แปลว่าวงจรถูกต้องสมบูรณ์**
และ FFT ต้องขึ้นยอดที่ 40 kHz

> นี่คือการทดสอบเชิงปริมาณที่ไม่ต้องพึ่งเสียงเลย — แยกปัญหา "วงจรผิด" ออกจาก
> "เสียงไม่มา" ได้เด็ดขาด **ผ่านขั้นนี้ก่อนค่อยไปยุ่งกับทรานสดิวเซอร์**

### ขั้น 4 — ทดสอบเสียงจริง (ยังไม่ต้องมีภาคส่ง)

ต่อทรานสดิวเซอร์กลับเข้าไป แล้วทำเสียงที่มีย่านอัลตราโซนิก **ห่างจากหัวรับ ~10 cm**:

- **เขย่าพวงกุญแจ** ← ได้ผลดีที่สุด
- ขยำกระดาษฟอยล์
- เป่าลมผ่านซี่หวี

เอาต์พุตต้องกระโดดชัดเจน และ FFT ต้องมีพลังงานแถว 40 kHz
**ถ้าขั้น 3 ผ่านแต่ขั้น 4 ไม่ผ่าน = ทรานสดิวเซอร์เสีย หรือต่อสลับ T กับ R**

---

## 8. ตารางแก้ปัญหา

| อาการ | สาเหตุที่พบบ่อยที่สุด | วิธีตรวจ |
|---|---|---|
| ขาออกติดที่ 0V หรือ 3.3V | ลืม R_bias หรือ Rg/Cg ต่อผิด | วัดขา 3 ต้องได้ 1.65V |
| VREF ไม่ใช่ 1.65V | รางไฟขาดกลางบอร์ด | continuity ทดสอบราง |
| เอาต์พุตหอนเอง มีคลื่นตลอดเวลา | เอาต์พุตสเตจ 2 อยู่ใกล้อินพุตสเตจ 1 | ย้ายให้ห่าง ≥5 cm จัดสายให้ไหลทางเดียว |
| มีคลื่น 50/100 Hz แรงมาก | สายอินพุตยาวเกิน | ใช้สายแข็งสั้น <3 cm หรือใช้สายตีเกลียวกับ GND |
| Vpp ได้ครึ่งเดียวของตาราง | Rf ผิดค่า หรือ MCP6004 แบนด์วิดท์ตก | เช็คแถบสี Rf / ลด Rf ลง |
| ขั้น 3 ผ่าน ขั้น 4 ไม่ผ่าน | ใช้หัว T (ส่ง) แทนหัว R (รับ) | สลับหัวลอง |
| สัญญาณดี แต่ ADC อ่านได้แต่ 0 หรือ 4095 | ต่อ GPIO ผิดขา หรือลืม R_out | วัดแถว 38 ต้อง 1.65V |
| ช่องหนึ่งกระเพื่อมตามอีกช่อง | ลืมบัฟเฟอร์ VREF | ดูข้อ 2.4 |

---

## 8.5 ย้ายลงแผ่นไข่ปลา — และจังหวะที่ควรสลับไป MCP6024

**ทำไมย้าย (ส.ค. 2026)**: ช่องบนบอร์ดทดลองแผ่นที่สองมีพื้นเสียงรบกวนสูงกว่าแผ่นแรก ~3 เท่า
ไล่หาสาเหตุจนตัดออกหมด — สายจั๊มยาว (เปลี่ยนสั้นแล้วเท่าเดิม), คลื่นจากตัวส่ง (ปิดยิงแล้วเท่าเดิม),
EMI เฉพาะความถี่ (สเปกตรัมแบนเรียบทุกย่าน), หัวรับ (ถอดแล้ว noise สูงขึ้น = อินพุตลอย),
ไฟ/VREF ที่ยืมข้ามบอร์ด (noise สองช่องไม่สัมพันธ์กัน corr −0.009), ขา ADC (สลับสายแล้ว noise
ตามวงจรไป ไม่ตามขา), ตัวชิป (เปลี่ยนตัวใหม่เท่าเดิม), และค่าตัวต้านทาน (วัดครบตรงหมด)

**เมื่อทุกชิ้นส่วนถูกหมดแต่ยังมี noise เหลือผู้ต้องสงสัยเดียวคือตัวบอร์ดทดลองเอง** —
หน้าสัมผัสสปริงที่ต้านทานไม่คงที่ และความจุแฝงระหว่างรางที่อยู่ติดกัน ซึ่งเปลี่ยนอะไหล่แก้ไม่ได้
เครื่องมือวัดซ้ำได้: `tools/noise_check.py` (มีรายการที่ตัดออกไปแล้วในหัวไฟล์ กันไล่ซ้ำ)

**ผังบัดกรี**: `hardware/perf_rx_layout.py` -> `diagrams/perf_1..4_*.svg`
(บัสไฟ+ซ็อกเก็ต · วงจร VREF · อินพุต+สเตจ 1 · สเตจ 2+ขาออก) วาดตรงกับแผ่นจริงที่
คอลัมน์ A อยู่ขวาและเลขแถว 048 อยู่บน · **ทุกรูบนแผ่นแยกอิสระ** วัดยืนยันแล้ว

### จังหวะสลับ MCP6004 -> MCP6024

**ใช้ซ็อกเก็ต DIP-14 ทุกตัว ทำให้เปลี่ยนรุ่นทีหลังไม่มีต้นทุน** จึงแยกสองตัวแปรได้:

| ขั้น | ใช้ชิป | เหตุผล |
|---|---|---|
| ช่องแรกบนไข่ปลา (ทดสอบ) | **MCP6004** | ให้เทียบกับบอร์ดทดลองได้สะอาด — เปลี่ยนแค่ "ชนิดบอร์ด" อย่างเดียว ถ้า noise ลง แปลว่าบอร์ดทดลองคือต้นเหตุจริง |
| ช่องที่เหลือ + ถอดเปลี่ยนช่องแรก | **MCP6024 ทั้งหมด** | ทำครั้งเดียวพร้อมกัน ไม่ผสมรุ่น · มี 6 ตัว ใช้ 5 พอดี (เหลือสำรอง 1) |

**ทำไม MCP6024 ดีกว่าสำหรับอาเรย์** (ไม่ใช่แค่ "เร็วกว่า"): ที่เกน 11 ต่อสเตจ MCP6004
(GBW 1 MHz) ได้แบนด์วิดท์ 91 kHz ซึ่ง 40 kHz อยู่ที่ ~0.44 ของความถี่ตัด **จึงมีการเลื่อนเฟส
ที่ขึ้นกับ GBW ของชิปแต่ละตัว** ชิปคนละตัวเลื่อนไม่เท่ากัน = error ของ Δt ระหว่างช่อง
ส่วน MCP6024 (GBW 10 MHz) ได้ 909 kHz -> 40 kHz อยู่ที่ 0.044 เท่านั้น เฟสแทบไม่เลื่อน
และความต่างระหว่างชิปเล็กลงมาก **ซึ่งคือสิ่งที่อาเรย์วัดมุมต้องการโดยตรง**

---

## 9. เมื่อ MCP6024 มาถึงจาก DigiKey

| สิ่งที่ต้องทำ | เหตุผล |
|---|---|
| เปลี่ยนชิปได้เลย ขาเหมือนกันทุกประการ | MCP6004/6024 เป็น pinout มาตรฐาน quad op-amp |
| **เพิ่ม Rf ได้ถึง 47k** | GBW 10 MHz ทำให้ BW ยังเหลือ 208 kHz |
| ถ้าเคยซอยเป็น 3 สเตจ ให้กลับมาเป็น 2 สเตจ | โพลน้อยลง = group delay แปรปรวนน้อยลง |
| **ทำใหม่ทั้ง 9 ช่องด้วยชิปรุ่นเดียวกัน** | ห้ามผสม MCP6004 กับ MCP6024 ในอาร์เรย์เดียวกันเด็ดขาด — delay ต่างกันคนละโลก |

---

## 10. ช่อง far (Stage 5) — **ยังไม่ต้องสร้าง** อ่านไว้เฉยๆ

3 ช่องนอกสุด (รัศมี 140 mm) ไม่ใช้ ADC เพราะ ESP32 มีแค่ 6 ช่อง
ใช้ **envelope + comparator** แทน ให้ความแม่นเวลา ±2-5 µs ซึ่งบน baseline 280 mm
คิดเป็นความคลาดเคลื่อนเชิงมุมเพียง **0.35°**

```
ออกจากสเตจ 2 ──┤▶├── 1N4148 ──┬──────────┬────→ +IN ของ LM393
                              │          │
                            R 10k     C 10nF        (τ = 100 µs)
                              │          │
                             GND        GND

   VREF ── trimpot 10k ─────────────────────────→ −IN ของ LM393
                                                    │
                              LM393 out ──┬─────────┴──→ GPIO (ขาดิจิทัล)
                                          │
                                       R 10k
                                          │
                                        3.3V        ← LM393 เป็น open-collector ต้องมี pull-up
```

⚠️ **LM393 ต้องมี pull-up เสมอ** เอาต์พุตเป็น open-collector ถ้าลืมจะไม่มีสัญญาณขาขึ้นเลย

การทดลองที่ควรทำตอนนั้น: ต่อ ADS1115 ขนานกับช่องนี้ แล้ววัดพร้อมกัน
จะได้เห็นด้วยตัวเลขจริงว่า ADS1115 ให้ ~4.6 ms/ตัวอย่าง เทียบกับ LM393 ที่ ~3 µs
(**เร็วกว่ากัน ~1500 เท่า**) — เก็บผลไว้เขียนลง README เป็นข้อสรุปที่พิสูจน์แล้ว

---

**ต่อไป**: [tx_driver.md](tx_driver.md) — วงจรภาคส่ง

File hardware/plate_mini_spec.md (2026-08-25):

# แผงทดลอง 150×150 มม. — RX 4 + TX 1 (สเปกสำหรับพิมพ์ 3D)

แผงเล็กสำหรับ**ลองของจริงก่อน** โดยไม่ต้องรอบัดกรีครบ 12 ช่องของแผงเต็ม
โมเดลสร้างจากโค้ด: [`plate_mini_model.py`](plate_mini_model.py) → รัน
`python hardware/plate_mini_model.py` จะได้ STEP + STL + ภาพตัวอย่างใน `cad/`
และเขียน [`plate_mini_coords.csv`](plate_mini_coords.csv) ใหม่จากตัวเลขชุดเดียวกัน

ไฟล์ที่เอาไปพิมพ์: **`cad/plate_mini.stl`**

---

## 1. ทำไมมีแผงนี้ ทั้งที่มีแผงเต็มอยู่แล้ว

แผงเต็ม (3 TX + 9 RX) ต้องบัดกรี 12 ช่องก่อนจะได้ลองอะไรเลย ตอนนี้วงจรบนแผ่นไข่ปลา
รองรับได้ **RX 4 ช่อง + TX 1 ตัว** พอดี แผงนี้จึงใช้ของที่มีอยู่แล้วได้ทันที

| | แผงเต็ม | **แผงนี้** |
|---|---|---|
| เซ็นเซอร์ | 3 TX + 9 RX | **1 TX + 4 RX** |
| ขนาดประกอบ | 298 × 262 มม. | **150 × 150 มม.** |
| ชิ้นที่ต้องพิมพ์ | ดุม 1 + แขน 3 | **ชิ้นเดียว** |
| เนื้อพลาสติก | 57.5 cm³ | 86.9 cm³ (~55 g PETG ที่อินฟิล 25%) |

> แผงนี้ใช้เนื้อ **มากกว่า** แผงเต็ม เพราะเป็นแผ่นตันทั้งผืน ส่วนแผงเต็มเป็นดุม+แขนซึ่ง
> ตัดเนื้อว่างทิ้งไปเยอะ ถ้าอยากประหยัด ลด `T` จาก 4.0 เหลือ 3.0 มม. ได้ (เสียความแข็งไปบ้าง)

---

## 2. พิกัดทุกตำแหน่ง (มม. จุดกำเนิด = กึ่งกลางแผง)

| id | x | y | GPIO | หน้าที่ |
|---|---|---|---|---|
| RX_TL | −55.0 | +55.0 | **IO34** | ตัวรับ ซ้ายบน |
| RX_BL | −55.0 | −55.0 | **IO33** | ตัวรับ ซ้ายล่าง |
| RX_BR | +55.0 | −55.0 | **IO32** | ตัวรับ ขวาล่าง |
| RX_TR | +55.0 | +55.0 | **IO35** | ตัวรับ ขวาบน |
| TX1 | 0.0 | 0.0 | **IO18** | ตัวส่ง |
| M0 / M90 / M180 / M270 | ±62 / 0 | 0 / ±62 | — | รูยึด ⌀4.5 + จุดอ้างอิงกล้อง |

**เบสไลน์ RX = 110 มม. ทั้งแนวนอนและแนวตั้ง**

### ทำไมจับคู่ GPIO แบบนี้

กฎที่เทรนไว้แล้วใน `car/rules.py` ใช้

```
log4 = ln( (a34 + a33 + 1) / (a32 + a35 + 1) )
```

ซึ่งคือ **ผลรวมฝั่งซ้าย เทียบ ผลรวมฝั่งขวา** ตราบใดที่ (34, 33) อยู่ซ้ายและ (32, 35)
อยู่ขวา สูตรเดิมใช้ต่อได้ทันที ไม่ต้องแก้โค้ด — ฟิตใหม่แค่ค่าความชันกับจุดตัด 2 ตัว
เพราะเบสไลน์เปลี่ยนจากของเดิม

### ของแถมที่อาเรย์เส้นตรงเดิมทำไม่ได้

วาง RX เป็นสี่เหลี่ยมทำให้ได้ **ทิศแนวตั้ง** มาฟรี ๆ:

```
log4_v = ln( (a34 + a35 + 1) / (a33 + a32 + 1) )      บน เทียบ ล่าง
```

บอกได้ว่าเป้าอยู่สูงหรือต่ำกว่าแนวแผง ซึ่งอาเรย์เส้นตรงบอกไม่ได้เลย
สำหรับรถ นี่คือความต่างระหว่าง "มีอะไรอยู่ข้างหน้า" กับ "พื้นลาดขึ้น / มีอะไรห้อยอยู่"

---

## 3. รูเซ็นเซอร์ — โตขึ้น 1 มม. จากแบบเดิม

| รายการ | แบบเดิม | **แผงนี้** |
|---|---|---|
| เส้นผ่านศูนย์กลางรู | ⌀19.5 มม. | **⌀20.5 มม.** |
| ตัวเซ็นเซอร์ TCT40-16 | ⌀16.0 มม. | ⌀16.0 มม. |
| ช่องว่างรอบตัว | 1.75 มม. | **2.25 มม.** |
| บอสรอบรู | ⌀23 สูง 10 | **⌀24 สูง 10** (ผนัง 1.75 มม. เท่าเดิม) |

**ทำไมโตขึ้นแล้วดีกว่า ไม่ใช่แค่ใส่ง่ายขึ้น**: โอริงที่ถูกอัดจนแบนจะนำเสียงได้มากขึ้น
ซึ่งผิดวัตถุประสงค์ของมัน (มันมีไว้ *กั้น* เสียงไม่ให้ลัดผ่านเนื้อพลาสติก) การให้โอริง
บีบพอประมาณจึงแยกเสียงได้ดีกว่าการอัดแน่น

ยังใช้โอริงเบอร์เดิมได้: **ID 15 หน้าตัด 2.0 มม. 2 วงต่อเซ็นเซอร์** (วงบน + วงล่าง
ทำให้เซ็นเซอร์ตั้งฉากและเข้าศูนย์เอง)

> **ห้ามทากาว ห้ามกดอัดจนแน่น** — จุดสัมผัสแข็งจุดเดียวก็ทำลายการแยกเสียงทั้งหมด

---

## 4. ร่องตัดเสียง

ร่อง **กว้าง 3 มม. ยาว 30 มม.** 4 ร่อง วางขวางแนว TX→RX ที่มุม 45° / 135° / 225° / 315°
รัศมี 33 มม. เว้นสะพานไว้ที่ 0° / 90° / 180° / 270° ซึ่งไม่มี RX อยู่

**ทุกเส้นทาง TX→RX จึงโดนร่องคั่นหมด** ต่างจากแผงเต็มที่ร่องช่วยได้เฉพาะตัวรับไกล

ระยะ TX→RX = 55√2 = **77.8 มม.** เทียบเวลาเดินทาง:

```
ผ่านเนื้อพลาสติก  77.8 mm / 2200 m/s =  35 µs
ผ่านอากาศ         77.8 mm /  343 m/s = 227 µs
```

ทั้งคู่ยังอยู่ในช่วง blanking `T0 = 1220 µs` จึงไม่โผล่มาเป็นเป้าปลอม แต่ร่องยังจำเป็น
เพราะพลังงานที่ลัดผ่านเนื้อแผงทำให้ภาครับ **อิ่มตัวและกริ่งยาว** ซึ่งกินเข้ามาในช่วงที่
เอคโค่จริงกำลังจะมาถึง

---

## 5. รายละเอียดอื่น

- **รูเคเบิลไทร์ ⌀3.5 คู่ละ 2 รู** อยู่ด้านในของทุกบอส (ห่างขอบบอส 8 มม.) รัดสายไม่ให้
  ดึงตัวเซ็นเซอร์ — สายที่ถูกดึงคือจุดสัมผัสแข็งที่ทำลายการแยกเสียงพอ ๆ กับกาว
- **ตัวอักษรจม 0.6 มม.** บอกชื่อรูและ GPIO ทุกจุด (`TL / IO34` เป็นต้น) ตรวจแล้วว่าไม่
  ทับรู บอส ร่อง หรือขอบแผ่น
- **`+Y` จมไว้ที่ขอบบน** กันประกอบกลับด้าน
- **รูยึด ⌀4.5 สี่รูกลางด้าน** ที่ r=62 ยึดขาตั้ง/ตัวรถได้ และใช้เป็นจุดอ้างอิงกล้องได้
  (4 จุดพอทำ homography พอดี)
- **มุมแผ่นลบ R12** กันมุมแหลมงอหลุดตอนพิมพ์

---

## 6. ค่าพิมพ์ที่แนะนำ

| | ค่า | เหตุผล |
|---|---|---|
| วัสดุ | **PETG** (PLA ก็ได้) | หน่วงการสั่นดีกว่า ไม่เปราะเท่า PLA |
| ความสูงชั้น | 0.2 มม. | |
| ผนัง | **4 เส้น** | ผนังบอส 1.75 มม. → 4 × 0.4 = 1.6 มม. เต็มพอดี ถ้าตั้ง 3 เส้นบอสจะพรุน |
| อินฟิล | **25% gyroid** | อินฟิลสูง = แข็ง = นำเสียง · gyroid ไม่มีเส้นตรงยาวให้คลื่นวิ่ง |
| ซัพพอร์ต | **ไม่ต้อง** | บอสพิมพ์ขึ้นด้านบน ไม่มีส่วนยื่น |
| ทิศวาง | แผ่นนอนราบ **บอสหงายขึ้น** | ผิวรูเรียบที่สุด |

---

## 7. ตรวจก่อนพิมพ์ (ทำไปแล้วในโค้ด)

รัน `python hardware/plate_mini_model.py` แล้ววัดจาก STL ที่ได้:

```
เมชปิดสนิท (ทุกขอบใช้ 2 ครั้ง)  ✅
ขอบเขต 150.0 × 150.0 × 14.0 มม.  ✅
รูเซ็นเซอร์ทั้ง 5 รู  ⌀20.50 · บอส ⌀24.00 · ทะลุถึง z=0.00  ✅
รูยึดทั้ง 4 รู  ⌀4.50  ✅
ตัวอักษรทุกป้ายไม่ชนรู/บอส/ร่อง/ขอบแผ่น  ✅
```

> **บทเรียนจากรอบนี้**: ฉบับแรกลืมเรียก `bore()` — บอสออกมาตันทั้ง 5 ตัว ผังดูถูกต้อง
> ทุกอย่างและภาพตัวอย่างก็ดูปกติ จับได้เพราะไปวัดเส้นผ่านศูนย์กลางจากไฟล์ STL จริง
> **อย่าเชื่อค่าคงที่ในโค้ด ให้วัดจากไฟล์ที่จะพิมพ์จริงเสมอ**

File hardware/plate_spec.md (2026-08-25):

# แบบแผงอาเรย์ 3 TX + 9 RX — สเปกสำหรับพิมพ์ 3D

> **อยากลองก่อนโดยไม่บัดกรี 12 ช่อง?** มีแผงเล็ก 150×150 มม. (RX 4 + TX 1) พิมพ์ชิ้นเดียว
> ที่ [`plate_mini_spec.md`](plate_mini_spec.md) — ใช้กับวงจรไข่ปลาที่มีอยู่ตอนนี้ได้เลย

แผงเดียวใช้ได้ตั้งแต่ Stage 1 ถึง Stage 7 ไม่ต้องพิมพ์ซ้ำ พิกัดในเอกสารนี้เป็น**ค่าจริงที่โค้ด
วิเคราะห์จะใช้** ([`plate_coords.csv`](plate_coords.csv) เป็นไฟล์เดียวกันในรูปแบบที่อ่านด้วย
โปรแกรมได้) **โมเดลสร้างจากโค้ด**: [`plate_model.py`](plate_model.py) → รัน `python hardware/plate_model.py`
จะได้ STEP + STL + ภาพตัวอย่าง ใน `cad/` และเขียน `plate_coords.csv` ใหม่จากตัวเลขชุดเดียวกัน
ภาพตัดขวางของรูยึด: [`diagrams/plate_2_mount_section.svg`](diagrams/plate_2_mount_section.svg)

## 1. ทำไมต้องออกแบบใหม่ ไม่ใช้ของเดิม

แบบเดิมเจาะรูพอดีตัวเซ็นเซอร์ ซึ่งทำให้โลหะแตะพลาสติกโดยตรง — เสียงเดินทางในพลาสติกที่
~2200 m/s เทียบกับอากาศ 343 m/s ที่ระยะแขน 140 มม. หมายความว่า

```
ผ่านเนื้อแผง   140 mm / 2200 m/s =  64 µs
ผ่านอากาศ      140 mm /  343 m/s = 408 µs
```

พัลส์ที่ลัดผ่านเนื้อแผงจะมาถึงก่อน 344 µs และเป็นพัลส์ที่ตัวตรวจจับจะไปเกาะแทนพัลส์จริง
สำหรับ TDOA ที่ต้องการความแม่นระดับต่ำกว่า 1 µs นี่คือความผิดพลาดขนาด 400 เท่าของงบประมาณ

## 2. พิกัดทุกตำแหน่ง (มม. จุดกำเนิด = กึ่งกลางแผง)

| id | x | y | รัศมี | มุม | หน้าที่ |
|---|---|---|---|---|---|
| T1 | +17.32 | +10.00 | 20 | 30° | ตัวส่ง |
| T2 | −17.32 | +10.00 | 20 | 150° | ตัวส่ง |
| T3 | 0.00 | −20.00 | 20 | 270° | ตัวส่ง |
| A40 | 0.00 | +40.00 | 40 | 90° | ตัวรับ ใกล้ |
| A80 | 0.00 | +80.00 | 80 | 90° | ตัวรับ กลาง |
| A140 | 0.00 | +140.00 | 140 | 90° | ตัวรับ ไกล |
| B40 | −34.64 | −20.00 | 40 | 210° | ตัวรับ ใกล้ |
| B80 | −69.28 | −40.00 | 80 | 210° | ตัวรับ กลาง |
| B140 | −121.24 | −70.00 | 140 | 210° | ตัวรับ ไกล |
| C40 | +34.64 | −20.00 | 40 | 330° | ตัวรับ ใกล้ |
| C80 | +69.28 | −40.00 | 80 | 330° | ตัวรับ กลาง |
| C140 | +121.24 | −70.00 | 140 | 330° | ตัวรับ ไกล |
| MA | 0.00 | +160.00 | 160 | 90° | รูยึด ⌀4.5 + จุดอ้างอิงกล้อง |
| MB | −138.56 | −80.00 | 160 | 210° | รูยึด ⌀4.5 + จุดอ้างอิงกล้อง |
| MC | +138.56 | −80.00 | 160 | 330° | รูยึด ⌀4.5 + จุดอ้างอิงกล้อง |
| — | 0.00 | 0.00 | 0 | — | รูกลาง ⌀6.5 สำหรับสกรูขาตั้ง 1/4"-20 |

**เปลี่ยนจากแบบในแผนเดิม 2 จุด และนี่คือเหตุผล:**

1. **ตัวส่งขยับจาก r=14 เป็น r=20 และย้ายไปอยู่ระหว่างแขน (30/150/270°)** — ที่ r=14 ระยะห่าง
   ระหว่างตัวส่งเป็น 24.25 มม. ซึ่งบอสรอบรู ⌀26 จะชนกันพอดี ที่ r=20 ได้ระยะ 34.64 มม.
   เหลือช่องว่าง 8.6 มม. และการวางไว้ระหว่างแขนทำให้ตัวส่งอยู่ห่างจากตัวรับที่ใกล้ที่สุด
   34.64 มม. แทนที่จะเป็น 26 มม. — พัลส์ตรงเบาลง โซนบอดแคบลง
2. **ไม่มีรูตรงกลาง** ตัวส่งเดี่ยวสำหรับ Stage 1-5 ให้ใช้ **T1** ไปเลย พอถึง Stage 6 ที่ใช้ครบ
   3 ตัวก็ไม่ต้องคาลิเบรตเรขาคณิตใหม่

## 3. รูยึดเซ็นเซอร์ — จุดที่สำคัญที่สุดของแบบนี้

| รายการ | ค่า |
|---|---|
| เส้นผ่านศูนย์กลางรูเจาะ | **⌀19.5 มม.** |
| ตัวเซ็นเซอร์ TCT40-16 | ⌀16.0 มม. |
| ช่องว่างรอบตัว | 1.75 มม. |
| บอสรอบรู | ⌀23 มม. สูง 10 มม. จากผิวแผ่น (ผนัง 1.75 มม.) |
| ตัวคั่น (แนะนำ) | โอริง ID 15 หน้าตัด 2.0 มม. **2 วงต่อเซ็นเซอร์** |
| ตัวคั่น (สำรอง) | โฟมเทปสองหน้าหนา 1.5–1.75 มม. พันหนึ่งรอบ |
| รูเคเบิลไทร์ | ⌀3.5 มม. ห่างจากขอบบอส 6 มม. |

โอริงสองวง (วงบนกับวงล่าง) ทำให้เซ็นเซอร์ตั้งฉากและเข้าศูนย์เอง — จำเป็นเพราะ TDOA
ต้องรู้พิกัดจริงในระดับ 1 มม. ถ้าเซ็นเซอร์เอียง 5° ที่ความสูง 12 มม. ปลายจะเยื้องไป 1 มม. ทันที

**ห้ามทากาว ห้ามกดอัดจนแน่น** — จุดสัมผัสแข็งจุดเดียวก็ทำลายการแยกทั้งหมด

## 4. ร่องตัดเสียง — และข้อจำกัดที่ต้องรู้

ร่อง **กว้าง 3 มม. ยาว 20 มม.** เจาะขวางแขนที่ **รัศมี 110 มม.** บังคับให้เสียงที่วิ่งใน
เนื้อแผงต้องอ้อมปลายร่อง

**ร่องนี้ป้องกันได้เฉพาะตัวรับที่ r=140** ตัวรับที่ r=40 และ 80 ไม่มีร่องคั่น เพราะเมื่อบอส
⌀23 อยู่ที่รัศมี 20 / 40 / 80 ช่องว่างที่เหลือระหว่างบอสไม่พอจะเจาะร่องโดยไม่ตัดเข้าเนื้อบอส

จึงต้องพูดให้ชัด: **โอริงคือด่านหลัก ร่องเป็นของแถม** เหตุผลที่โอริงเอาอยู่คือความต่างของ
อิมพีแดนซ์เชิงเสียง — ยางกับโลหะ และยางกับพลาสติก ต่างกันมากจนพลังงานส่วนใหญ่สะท้อนกลับ
ไม่ผ่านไป ต่างจากโลหะแตะพลาสติกโดยตรงที่ผ่านได้เกือบหมด

ถ้าวัดแล้วยังเห็นพัลส์ลัดที่ตัวรับใกล้ ทางแก้คือแก้ `SLOT_R` / `HUB_DISC_R` ใน
`plate_model.py` แล้วพิมพ์ดุมใหม่ใบเดียว ไม่ต้องพิมพ์ทั้งแผง

## 5. แบ่งพิมพ์เป็น 4 ชิ้น

| ชิ้น | ขนาดจริงจากโมเดล | ปริมาตร | จำนวน |
|---|---|---|---|
| ดุมกลาง | 131.8 × 114.1 × 14.0 มม. | 23.3 cm³ | 1 |
| แขน | 28.0 × 117.0 × 14.0 มม. | 11.4 cm³ | 3 |
| **ประกอบแล้ว** | **298.2 × 262.0 × 16.0 มม.** | 57.5 cm³ (~72 g PETG) | |

**ดุมถือ TX ทั้ง 3 ตัว และ RX วงใน (r=40) ทั้ง 3 ตัว** ส่วนแขนถือ RX ที่ r=80 และ 140

นี่ไม่ใช่แค่เรื่องขนาดเตียงพิมพ์ — สามเหลี่ยมที่ไวต่อความคลาดเคลื่อนที่สุดคือ TX กับ RX วงใน
(เบสไลน์สั้นที่สุด ความคลาดเคลื่อนเชิงมุม ∝ 1/D) การให้ทั้งหกตัวอยู่บนชิ้นเดียวกันแปลว่า
**ระยะระหว่างกันไม่มีความคลาดเคลื่อนจากข้อต่อเลย**

**ข้อต่อ**: ปลายในของแขนบางลงเหลือ 2 มม. ยาว 15 มม. (r=53…68) หย่อนลงในเบ้าที่เซาะจาก
ผิวบนของดุม รวมกันได้ 4 มม. เท่าเนื้อแผ่น ยึดด้วย **สกรู M3 × 12 มม. + น็อต M3 สองชุดต่อแขน**
ผ่านรู ⌀3.4 ที่ r=56 และ r=65 (รวม 6 ชุดทั้งแผง) ผนังเบ้ากว้าง 28 มม. เป็นตัวกันหมุนและกำหนด
ตำแหน่ง สกรูแค่บีบให้แน่น ดูภาพตัด [`diagrams/plate_3_joint_section.svg`](diagrams/plate_3_joint_section.svg)

## 6. รายละเอียดที่ควรใส่ตอนโมเดล

ทั้งหมดนี้อยู่ในโมเดลแล้ว:

- **ตัวอักษรจม 0.6 มม.** ชื่อรูทุกรู (T1 T2 T3 · A40 B40 C40 บนดุม · 80 และ 140 บนแขน)
  เลือกจมแทนนูนเพราะพิมพ์โดยหงายบอสขึ้น ตัวนูนบนผิวบนจะไม่มีปัญหา แต่ตัวจมทนการขูดขีด
  ระหว่างประกอบได้ดีกว่า และไม่กินเนื้อที่เพิ่ม
- **"+Y" จมบนดุม** กันประกอบกลับด้าน
- **รูยึดปลายแขน ⌀4.5 ที่ r=160** ยึดขาตั้งได้ และเป็น**จุดอ้างอิงให้กล้อง** ใน Stage 7 —
  3 จุด + รูกลางอีก 1 = 4 จุด พอทำ homography พอดี
- **แขนทั้งสามเหมือนกันทุกประการ** พิมพ์ไฟล์เดียว 3 ครั้ง ชื่อ A/B/C มาจากเบ้าที่ขันเข้าไป
- **ไม่มีรูเคเบิลไทร์** เพราะแขนกว้าง 28 หนา 4 มม. คล้องเคเบิลไทร์รอบตัวแขนได้เลย
  ง่ายกว่าและไม่ไปแย่งที่กับบอส

## 7. ค่าพิมพ์ที่แนะนำ

| | ค่า | เหตุผล |
|---|---|---|
| วัสดุ | **PETG** (PLA ก็ได้) | หน่วงการสั่นดีกว่าและไม่เปราะเท่า PLA |
| ความสูงชั้น | 0.2 มม. | |
| ผนัง | **4 เส้น** | ผนังบอสหนา 1.75 มม. → 4 × 0.4 = 1.6 มม. เต็มพอดี ถ้าตั้ง 3 เส้นจะเหลือ 0.55 มม. ให้อินฟิลเบาบางไปเติม บอสจะพรุน
| อินฟิล | **25% แบบ gyroid** | อินฟิลสูงยิ่งแข็งยิ่งนำเสียง — ต้องการแค่พอไม่บิดงอ gyroid ไม่มีเส้นตรงยาวต่อเนื่องให้คลื่นเสียงวิ่ง ต่างจากลายตาราง |
| ซัพพอร์ต | ไม่ต้อง | บอสพิมพ์ขึ้นด้านบน ไม่มีส่วนยื่น |
| ทิศวาง | แผ่นนอนราบ บอสหงายขึ้น | ผิวรูเรียบที่สุด |
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

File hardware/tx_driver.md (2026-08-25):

# TX Driver — วงจรภาคส่ง 40 kHz

ขับ TCT40-16**T** ให้ยิงคลื่น 40 kHz แรงที่สุดเท่าที่ทำได้จากขา GPIO ของ ESP32

เอกสารนี้มี **3 เวอร์ชัน** สร้างตามลำดับ อย่าข้ามไปเวอร์ชันหลัง:

| เวอร์ชัน | แรงดันขับ | ใช้ตอน | ความยาก |
|---|---|---|---|
| **A — single-ended** | 5 Vpp | **Stage 1** | ง่าย ต่อ 15 นาที |
| **B — push-pull** | 10 Vpp | Stage 2-5 | ปานกลาง ต้องเขียนเฟิร์มแวร์เพิ่ม |
| C — TC4428A @ 12V | 24 Vpp | Stage 6 | ยังไม่ต้องอ่าน |

---

## 0. เช็คก่อนเริ่ม — 2 อย่างที่พังทั้งวงจรถ้าผิด

### ⚠️ ต้องเป็น 74**HCT**04 ไม่ใช่ 74**HC**04

อ่านตัวอักษรบนชิปให้ชัด **ต้องมีตัว T**

| ชิป | VIH ที่ไฟเลี้ยง 5V | ESP32 ให้ 3.3V |
|---|---|---|
| 74**HC**04 | ต้องการ **3.5V** | ❌ **ไม่ทำงาน** หรือทำงานแบบสุ่ม |
| 74**HCT**04 | ต้องการ **2.0V** | ✅ เหลือระยะขอบ 1.3V |

HCT ย่อมาจาก "HC with **T**TL input levels" — ออกแบบมาเพื่อรับลอจิกแรงดันต่ำโดยเฉพาะ
ถ้าเผลอซื้อ HC มา อาการที่จะเจอคือ "บางครั้งก็ยิง บางครั้งก็ไม่ยิง" ซึ่งไล่บั๊กยากมาก

### ⚠️ ห้ามต่อขาออกของ 74HCT04 (5V) เข้า GPIO ของ ESP32 เด็ดขาด

ทิศทางที่ถูกต้องมีทางเดียว: **ESP32 (3.3V) → อินพุต 74HCT04** เท่านั้น
ขาออกของ 74HCT04 เป็น 5V ซึ่งจะทำ GPIO ของ ESP32 พังถาวร
ถ้าอยากดูสัญญาณขาออก ให้ใช้ logic analyzer ไม่ใช่ ESP32

---
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

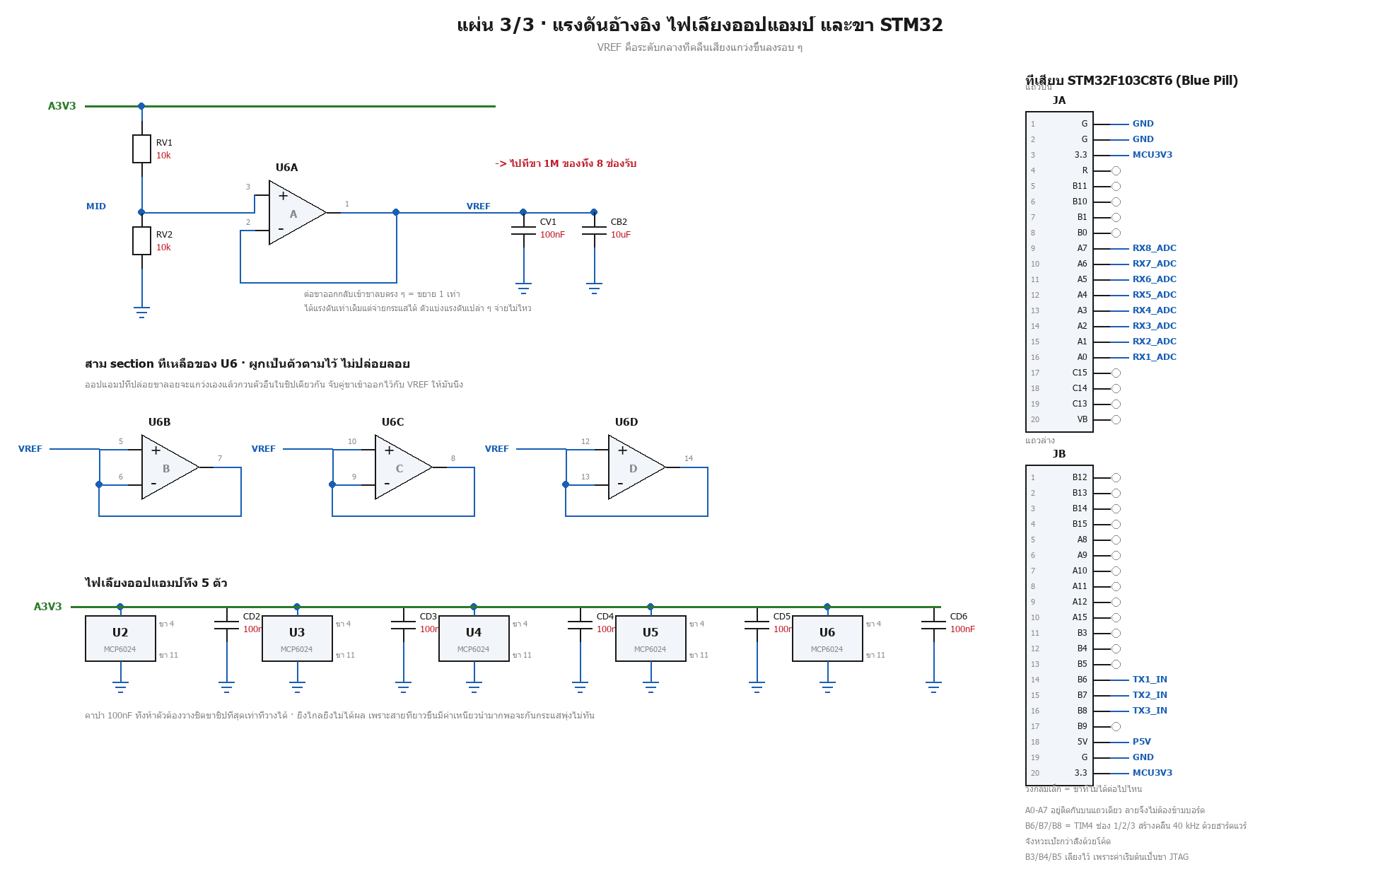
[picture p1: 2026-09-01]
pcb/out/main8/schematic-3-vref-mcu.png

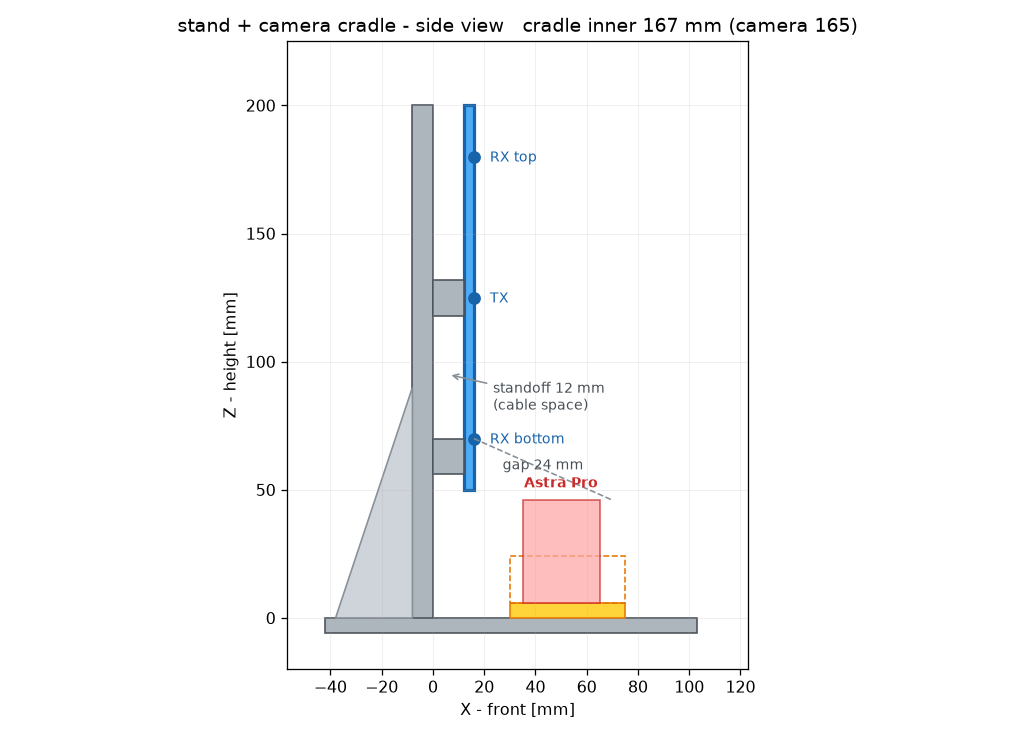
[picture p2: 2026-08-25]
hardware/cad/stand_preview.png

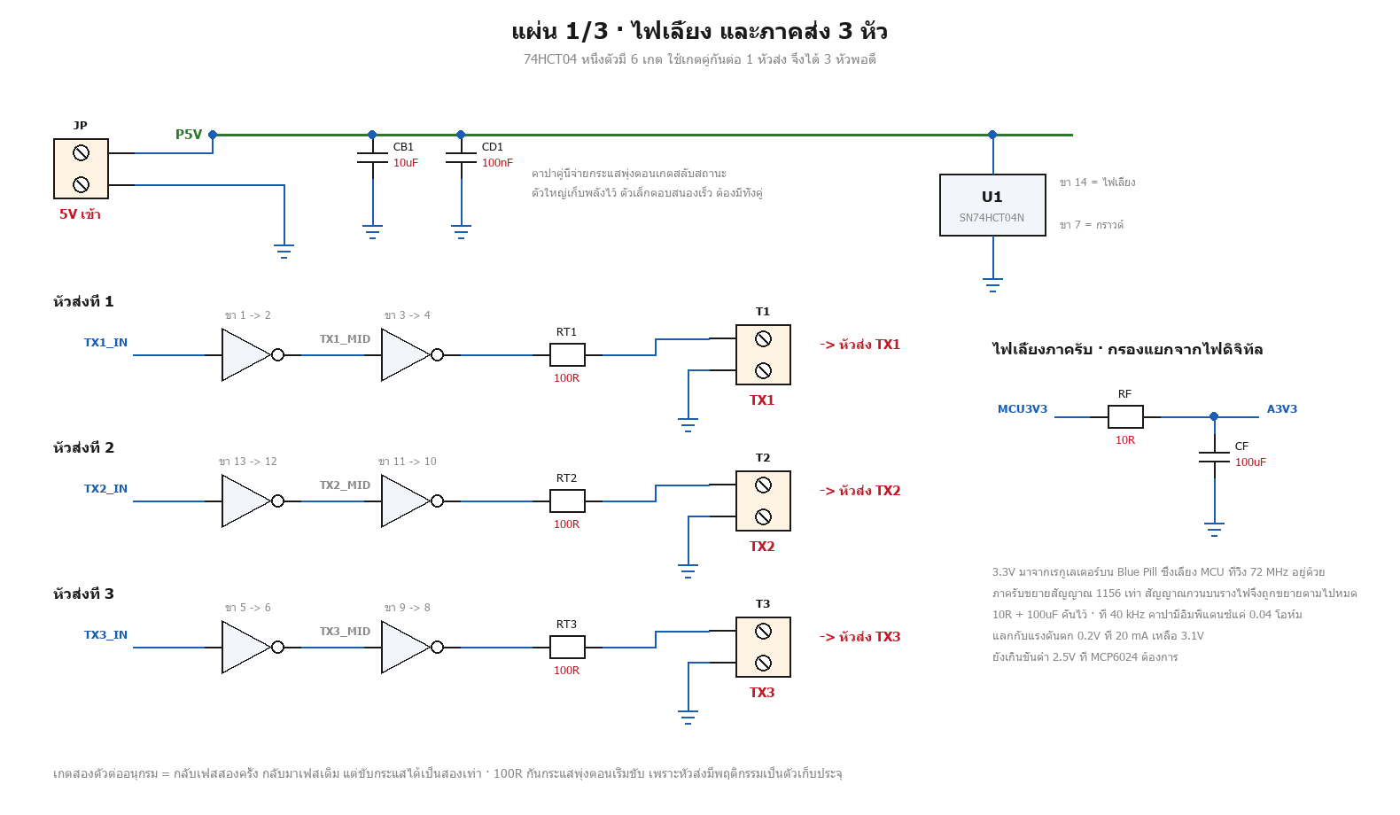
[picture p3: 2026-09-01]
pcb/out/main8/schematic-1-power-tx.png

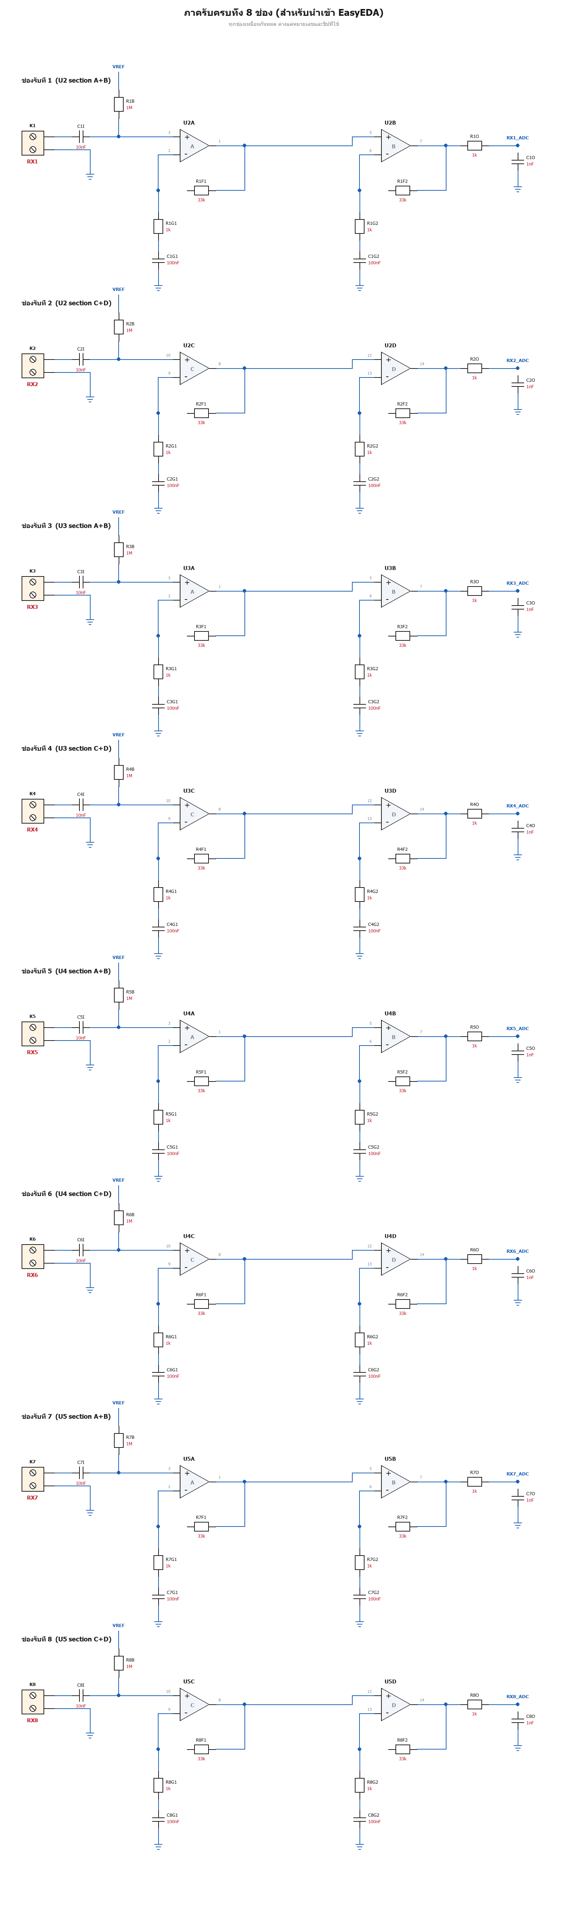
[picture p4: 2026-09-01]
pcb/out/main8/schematic-4-rx-all.png

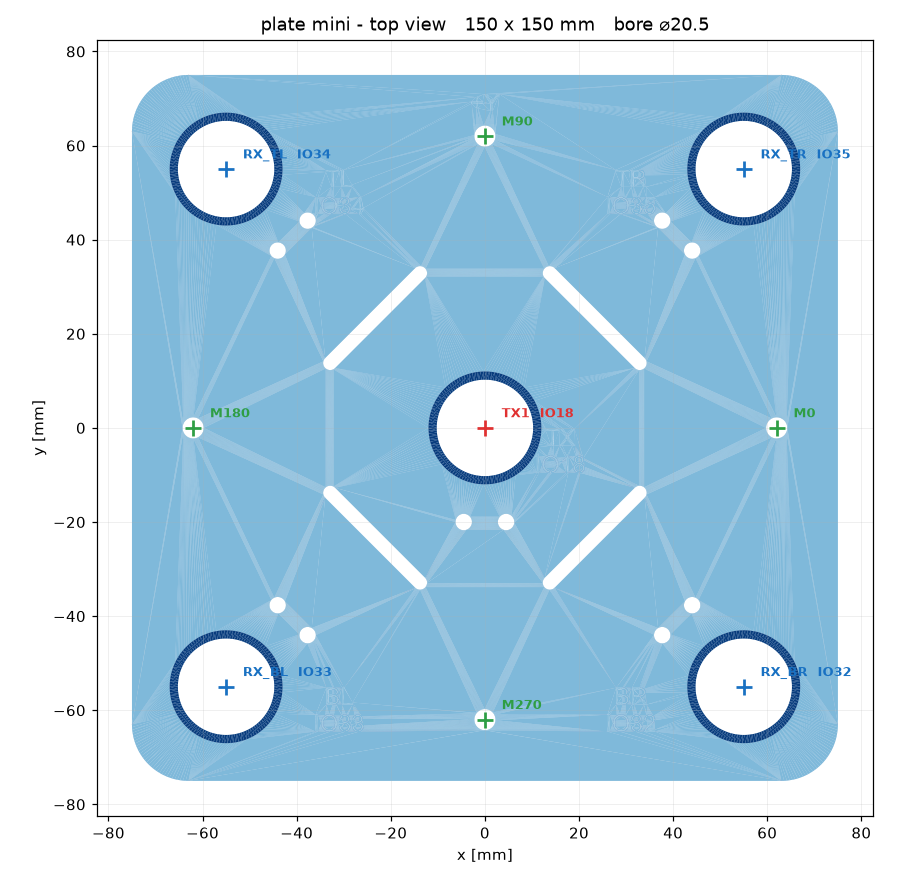
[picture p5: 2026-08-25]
hardware/cad/plate_mini_preview.png

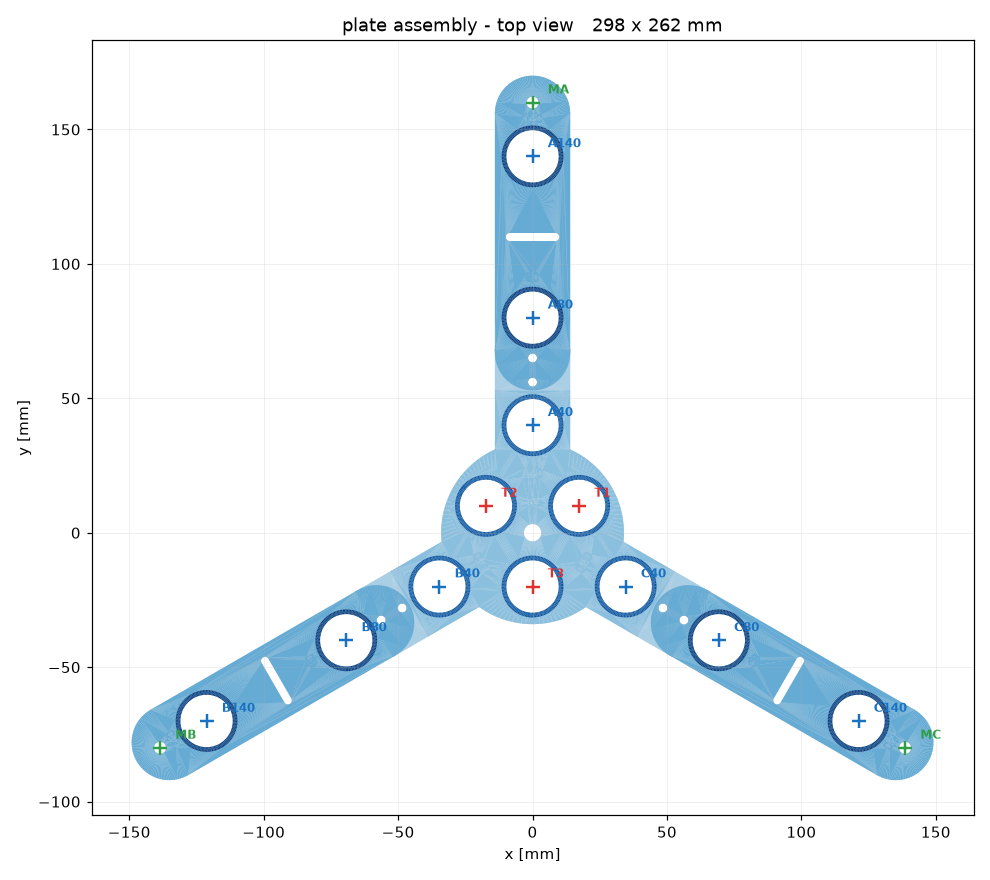
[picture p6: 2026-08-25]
hardware/cad/plate_preview.png

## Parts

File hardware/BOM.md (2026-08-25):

# รายการซื้อ (BOM) — Ultrasonic Array 40 kHz บน ESP32

> พิมพ์หน้านี้ติดตัวไปร้านได้เลย
> ช่อง ☐ ไว้ติ๊ก — **ของที่มี ⭐ คือขาดไม่ได้ ถ้าไม่ได้ตัวนี้ Stage 1 เริ่มไม่ได้**

สารบัญ: [ซื้อวันนี้](#a-ซื้อที่ร้านวันนี้) · [สั่งออนไลน์คืนนี้](#b-สั่งออนไลน์คืนนี้-ก่อนไปร้าน) · [วิธีเช็คของหน้าร้าน](#c-วิธีเช็คของหน้าร้าน) · [ถ้าหาไม่ได้ทำไง](#d-แผนสำรองถ้าหาของไม่ได้)

---

## A. ซื้อที่ร้านวันนี้

### A1. เครื่องมือ (คุณยังไม่มีอะไรเลย — ส่วนนี้สำคัญที่สุด)

| ☐ | รายการ | จำนวน | ~ราคา | ทำไมต้องมี |
|---|---|---|---|---|
| ☐ | ⭐ **มัลติมิเตอร์ดิจิทัล** | 1 | 250฿ | เช็คไฟเลี้ยง 3.3V/5V, เช็ค VREF = 1.65V, หาขาลัด **ถ้าไม่มีตัวนี้จะดีบักไม่ได้เลยสักอย่าง** รุ่นถูกสุดก็พอ ขอแค่วัด DC volt กับ continuity (มีเสียงปี๊บ) ได้ |
| ☐ | **USB Logic Analyzer 8ch 24MHz** | 1 | 200฿ | ตัว clone พลาสติกสีน้ำเงิน ใช้กับโปรแกรม PulseView (ฟรี) — ดูสัญญาณ TX / comparator / timing ได้ **คุ้มค่าเงินที่สุดในลิสต์นี้** |
| ☐ | หัวแร้ง 60W ปรับอุณหภูมิ + ตะกั่ว + ฟองน้ำ + ที่ดูดตะกั่ว | 1 ชุด | 350฿ | Stage 1-3 ยังไม่ใช้ (ต่อบน breadboard ล้วน) แต่ Stage 4 ต้องบัดกรีทรานสดิวเซอร์ลงแผง **ถ้างบตึงตัดออกก่อนได้** |
| ☐ | ⭐ **สาย USB micro-B** | 2 | 100฿ | **ต้องเป็นสายรับส่งข้อมูล ไม่ใช่สายชาร์จอย่างเดียว** — สายชาร์จมีแค่เส้นไฟ คอมจะมองไม่เห็นบอร์ด นี่คือปัญหาที่คนเจอบ่อยที่สุดตอนเริ่มต้น ซื้อ 2 เส้นเผื่อเส้นหนึ่งเป็นสายชาร์จ |

> **ไม่ต้องซื้อออสซิลโลสโคป** — Stage 1 เราจะเขียนเฟิร์มแวร์ `esp32_scope` ที่ทำให้ ESP32
> กลายเป็นสโคป 1 MS/s (ดูสัญญาณถึง ~400 kHz ได้) ซึ่งเกินพอสำหรับ 40 kHz
> และมันคือโค้ดชุดเดียวกับที่โปรเจกต์ต้องใช้อยู่แล้ว — **ได้เครื่องมือวัดฟรีจากงานที่ต้องทำอยู่แล้ว**

### A2. บอร์ดและทรานสดิวเซอร์

| ☐ | รายการ | จำนวน | ~ราคา | หมายเหตุ |
|---|---|---|---|---|
| ☐ | ⭐ **ESP32 DevKit V1 (WROOM-32, 30 หรือ 38 ขา)** | **2** | 300฿ | ซื้อ 2 เผื่อพัง **ต้องเป็น ESP32 รุ่นแรกเท่านั้น** ห้ามเป็น ESP32-**S3** / **C3** / **S2** — S3 จับ ADC ต่อเนื่องได้แค่ 83 kS/s ช้ากว่าที่ต้องการ 24 เท่า ใช้ไม่ได้เลย ดูที่โลหะบนโมดูลต้องเขียน `ESP32-WROOM-32` |
| ☐ | ⭐ **TCT40-16 คู่ส่ง+รับ 40 kHz** | **12 คู่** | 300฿ | โปรเจกต์ใช้จริง 3 ส่ง + 9 รับ = 12 ตัว ซื้อ 12 คู่ได้ 12T + 12R เผื่อพัง (บัดกรีนานเกินไปทรานสดิวเซอร์เสียได้ง่าย) **ถ้าร้านขายแยกตัว: ขอ 4 ตัว T + 12 ตัว R** |

**เรื่องทรานสดิวเซอร์ที่ต้องระวัง** — ตัวส่งกับตัวรับหน้าตาเหมือนกันเป๊ะ แต่**เป็นคนละเบอร์**:
- ที่กระป๋องจะมีตัวอักษร `T` (Transmitter) หรือ `R` (Receiver) ปั๊มไว้
- บางยี่ห้อใช้สีของตาข่ายหน้าแทน หรือทำเครื่องหมายที่ขา
- **ถามคนขายให้ชัดว่าอันไหนส่งอันไหนรับ แล้วแยกถุงคนละถุงตั้งแต่ที่ร้าน** — กลับบ้านมาแล้วแยกไม่ออก จะเสียเวลาเป็นวัน
- ถ้าร้านมีแบบ "ใช้ได้ทั้งส่งและรับ" (dual-use / TR) ก็ซื้อได้ ใช้ได้ทั้งคู่

### A3. IC

| ☐ | รายการ | จำนวน | ~ราคา | ใช้ทำอะไร |
|---|---|---|---|---|
| ☐ | ⭐ **MCP6004-I/P** (quad op-amp, DIP-14) | 4 | 80฿ | **ตัวสำรองสำหรับเริ่ม Stage 1 วันนี้** ระหว่างรอ MCP6024 จากออนไลน์ (ดูส่วน B) ร้านไทยมักมีตัวนี้ |
| ☐ | **LM393** (dual comparator, DIP-8) | 4 | 40฿ | ช่อง RX "far" 3 ตัวใน Stage 5 (ใช้ 2 ชิป) + สำรอง |
| ☐ | ⭐ **74HCT04** (hex inverter, DIP-14) | 4 | 60฿ | ภาคขับตัวส่ง **ต้องเป็น HC*T*04 ไม่ใช่ HC04** — ดูเหตุผลใน `tx_driver.md` (สรุปสั้นๆ: 74HC04 ที่ไฟ 5V ต้องการสัญญาณ input สูงกว่า 3.5V แต่ ESP32 ให้ได้แค่ 3.3V → มันจะไม่ทำงาน ส่วน HCT ต้องการแค่ 2.0V) |
| ☐ | ADS1115 module (16-bit ADC I2C) | 1 | 80฿ | ตามที่คุณเลือกไว้ว่าจะเอามาลอง — Stage 5 เราจะวัดเทียบกับ LM393 ให้เห็นตัวเลขจริงว่าช้ากว่ากันแค่ไหน |

### A4. Passive และเบ็ดเตล็ด

| ☐ | รายการ | จำนวน | ~ราคา | หมายเหตุ |
|---|---|---|---|---|
| ☐ | ⭐ Breadboard 830 จุด (แบบมีรางไฟ) | 3 | 150฿ | 1 อัน = ภาคส่ง, 2 อัน = ภาครับ (ต้องขยายเป็น 6 ช่อง) |
| ☐ | ⭐ สายจัมพ์ M-M / M-F / F-F | อย่างละ 1 ชุด | 150฿ | |
| ☐ | ⭐ **ชุดตัวต้านทาน 1/4W แบบกล่องรวมค่า** | 1 กล่อง | 120฿ | คุ้มกว่าซื้อทีละค่ามาก ขอให้มีค่าเหล่านี้: **100Ω, 47Ω, 2.2k, 9.1k(หรือ10k), 10k, 100k, 1M** |
| ☐ | ⭐ **ชุดคาปาซิเตอร์เซรามิก** (10pF – 100nF) | 1 กล่อง | 120฿ | ขอให้มี: **15pF, 22pF, 1nF, 2.2nF, 10nF, 100nF** |
| ☐ | ตัวเก็บประจุอิเล็กโทรไลต์ 16V: 10µF / 100µF / 470µF | อย่างละ 10 | 80฿ | |
| ☐ | ไดโอด **1N4148** | 20 | 20฿ | Envelope detector ของช่อง far |
| ☐ | Trimpot (VR ปรับค่า) 10k | 5 | 50฿ | ปรับ threshold ของ comparator |
| ☐ | IC socket DIP-8 และ DIP-14 | อย่างละ 10 | 50฿ | **อย่าเสียบ IC ลง breadboard ตรงๆ ซ้ำๆ** ขาจะงอ/หัก ใส่ socket แล้วเสียบ socket ลง breadboard |
| ☐ | แผ่นสะท้อนเรียบ (แผ่นอะคริลิก/กระเบื้อง/ปกแฟ้มแข็ง ~20×20cm) | 1 | 50฿ | เป้าทดสอบ ต้องเรียบและแข็ง |
| ☐ | ตลับเมตร หรือ ไม้บรรทัดเหล็ก 50cm | 1 | 60฿ | วัดระยะเป้าเพื่อเทียบกับที่ระบบคำนวณได้ |

**รวมส่วน A ประมาณ 2,100 – 2,400฿** (ตัดหัวแร้ง 350฿ ออกได้ ถ้ายังไม่ถึง Stage 4 → เหลือ ~1,800฿)

---

## B. สั่งออนไลน์คืนนี้ (ก่อนไปร้าน)

ของกลุ่มนี้ร้านหน้าร้านในไทยมักไม่มี แต่ Shopee/Lazada มี ส่ง 2-5 วัน
**สั่งคืนนี้เลย** ระหว่างรอก็ทำ Stage 1 ด้วย MCP6004 ที่ซื้อวันนี้ไปก่อนได้

| ☐ | รายการ | จำนวน | ทำไม |
|---|---|---|---|
| ☐ | ⭐ **MCP6024-I/P** หรือ **MCP6294-I/P** (quad op-amp DIP-14) | 6 | **นี่คือ op-amp ตัวจริงของโปรเจกต์** GBW 10 MHz ทำให้ขยาย 46 เท่าแล้วยังมีแบนด์วิดท์เหลือ 215 kHz (MCP6004 มีแค่ 1 MHz ได้แบนด์วิดท์ 83 kHz ต่อสเตจ ต้องซอยเป็น 3 สเตจ) |
| ☐ | TC4428A (dual MOSFET driver DIP-8) | 3 | อัปเกรดภาคส่งใน Stage 6 ให้แรงขึ้น (ขับที่ 12V) — ยังไม่ต้องใช้ตอนนี้ |

**คำค้นที่ใช้ได้**: `MCP6024 DIP`, `MCP6294 DIP`, `quad opamp rail to rail 10MHz`

**สเปกที่ต้องได้ ถ้าจะเลือกเบอร์อื่นเอง** — เอาไว้เทียบเวลาเจอเบอร์แปลกๆ:
- Quad (4 ตัวใน 1 ชิป), แพ็กเกจ **DIP-14** (ไม่ใช่ SOIC — SMD เสียบ breadboard ไม่ได้)
- **Rail-to-rail input **และ** output (RRIO)** ← ข้อนี้สำคัญที่สุด เพราะเราเลี้ยงไฟแค่ 3.3V
- **GBW ≥ 8 MHz**
- ไฟเลี้ยงต่ำสุด ≤ 2.7V (เราจะใช้ 3.3V)

เบอร์อื่นที่ใช้ได้: `TLV9064`, `OPA4340PA`, `TLV2374IN` (5.1 MHz — พอไหว), `MCP6294`

---

## C. วิธีเช็คของหน้าร้าน

**ESP32** — พลิกดูโลหะบนโมดูล ต้องอ่านได้ว่า `ESP32-WROOM-32` (หรือ `-32D`, `-32E`, `-32U` ก็ได้)
ถ้าเขียน `ESP32-S3`, `ESP32-C3`, `ESP32-S2`, `ESP32-C6` → **คนละตัว ใช้ไม่ได้** เอาคืน

**Op-amp / IC** — อ่านตัวหนังสือบนตัวชิป ต้องตรงเบอร์ ระวัง:
- `MCP6004` ≠ `MCP6002` (6002 มีแค่ 2 ตัวในชิป, DIP-8)
- `74HCT04` ≠ `74HC04` (ต่างกันแค่ตัว T แต่ผลต่างกันสิ้นเชิง)
- `LM393` ≠ `LM339` (339 มี 4 ตัว DIP-14 — ใช้ได้เหมือนกัน ถ้าเจอ 339 ก็เอาได้ ซื้อ 2 ชิปพอ)

**สายUSB** — บอกคนขายว่า "**ขอสายที่ใช้กับ Arduino ได้ ต้องส่งข้อมูลได้ด้วย**"
ถ้าซื้อมาแล้วไม่แน่ใจ: เสียบ ESP32 แล้วดูใน Device Manager ของ Windows
ถ้าขึ้น `Silicon Labs CP210x` หรือ `CH340` แปลว่าสายใช้ได้ ถ้าไม่ขึ้นอะไรเลย = เป็นสายชาร์จ

**ทรานสดิวเซอร์** — **แยกถุง T กับ R ตั้งแต่ที่ร้าน แล้วเขียนกำกับ** (ย้ำอีกรอบเพราะสำคัญจริง)

---

## D. แผนสำรองถ้าหาของไม่ได้

| หาไม่ได้ | ใช้อะไรแทน | ผลกระทบ |
|---|---|---|
| MCP6004 (op-amp) | `MCP6002` (dual) 8 ตัว — ก็ได้ แค่กินพื้นที่ breadboard มากกว่า | ไม่มี |
| **LM324 / LM358 / TL074** | **ห้ามใช้แทน** — LM324/LM358 ที่ไฟ 3.3V สัญญาณออกได้แค่ 0–1.8V แต่เราตั้ง VREF ไว้ที่ 1.65V แปลว่าแทบไม่มีที่ให้สัญญาณสวิงขึ้นเลย ส่วน TL074 ต้องการไฟอย่างน้อย 7V | ใช้ไม่ได้ |
| 74HCT04 | `74HCT14` (Schmitt trigger) ใช้แทนได้เลย, หรือ `74HCT245` | ไม่มี |
| LM393 | `LM339` (quad) | ไม่มี |
| Logic analyzer | ข้ามไปก่อนได้ — `esp32_scope` ครอบคลุมงานส่วนใหญ่แล้ว | ดีบัก timing ยากขึ้นเล็กน้อย |
| ทรานสดิวเซอร์ TCT40-16 | เบอร์อื่นที่เป็น **40 kHz ตัวถัง 16mm** ก็ได้ เช่น `HC-SR04` แกะเอาหัวมา, `MA40S4S/R` | ถ้าตัวถังไม่ใช่ 16mm ต้องแก้พิกัดเจาะรูของแผงใน Stage 4 |

---

## E. สิ่งที่ **ยังไม่ต้องซื้อ** ตอนนี้

เก็บเงินไว้ก่อน ค่อยซื้อเมื่อถึง stage นั้นจริงๆ:

| รายการ | รอถึง Stage ไหน | เพราะอะไร |
|---|---|---|
| แผงอะคริลิก / ค่าตัดเลเซอร์ | Stage 4 | ต้องยืนยันก่อนว่าวงจร 6 ช่องทำงานจริงบน breadboard ค่อยลงทุนตัดแผง (~250฿) ไม่งั้นเสี่ยงตัดแล้วต้องตัดใหม่ |
| TC4428A + ไฟเลี้ยง 12V | Stage 6 | 74HCT04 ที่ 5V ยิงได้ไกลพอสำหรับทดสอบบนโต๊ะ (30–100 cm) แล้ว |
| กล้อง / Orbbec depth camera | Stage 7 | อีกไกล |
| PCB สั่งทำ | หลัง Stage 6 | ต่อ breadboard ให้ผ่านก่อน |

---

## ลำดับหลังได้ของ

1. เสียบ ESP32 เข้าคอม ลง Arduino IDE + **ESP32 board package เวอร์ชัน 3.x** (สำคัญ: ต้อง 3.x ขึ้นไป) → อัปโหลด Blink ให้ผ่านก่อน
2. อ่าน `hardware/tx_driver.md` → ต่อภาคส่ง → ยิงคลื่นให้ได้
3. อ่าน `hardware/rx_frontend.md` → ต่อภาครับ 1 ช่อง
4. อัปโหลด `esp32_array/esp32_scope/esp32_scope.ino` → รัน `tools/scope_view.py` → **ต้องเห็นคลื่น 40 kHz**

ถ้าติดตรงไหน ถ่ายรูปวงจรที่ต่อกับผลที่เห็นมาถามได้เลยครับ

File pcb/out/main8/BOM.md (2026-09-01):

# main8 — รายการชิ้นส่วน

**บอร์ดนี้ให้ร้านบัดกรีให้ ไม่ต้องซื้อซ็อกเก็ต IC**
ชิปบัดกรีลงบอร์ดตรง ๆ ทั้ง 6 ตัว

**เรื่องที่ต้องถามร้านก่อนสั่ง — ชิ้นส่วนทั้งบอร์ดเป็นแบบขาเสียบทะลุ (through-hole)
ทั้งหมด 340 ขา** ร้านรับประกอบส่วนใหญ่คิดราคางานขาเสียบทะลุแพงกว่างานติดผิวหน้า
(SMD) มาก เพราะต้องบัดกรีทีละขาด้วยคน ไม่ใช่เครื่องหยิบวาง
ให้ขอใบเสนอราคาการประกอบมาดูก่อน ถ้าราคาสูงเกินไปมีสองทางเลือก
  ก. ให้ร้านบัดกรีเฉพาะ 6 ชิป (84 ขา) ที่เหลือบัดกรีเอง — ชิปคือส่วนที่พลาดแล้วเจ็บสุด
  ข. ออกแบบใหม่เป็นแบบติดผิวหน้า ซึ่งเป็นงานรื้อบอร์ดใหม่ ไม่ใช่แก้เล็กน้อย

**สิ่งที่ต้องส่งให้ร้านนอกจากไฟล์ Gerber**
  BOM.md นี้ (มีเบอร์ชิ้นส่วนครบ)  ·  assembly.png (บอกตำแหน่งและทิศของทุกตัว)
  ย้ำกับร้านเรื่องทิศของชิปทั้ง 6 ตัวและคาปาอิเล็กโทรไลต์ CB1 CB2 CF
  ทั้งสองอย่างนี้ใส่กลับด้านแล้วพังทันที ที่เหลือใส่กลับด้านได้ไม่เป็นไร

**JA กับ JB ใช้เฮดเดอร์ตัวเมีย 1x20 ระยะขา 2.54 มม.** สองแถวห่างกัน 17.78 มม.
เป็นที่เสียบ STM32F103C8T6 (Blue Pill) ไม่บัดกรีบอร์ด STM32 ลงไปตรง ๆ
จะได้ถอดไปแฟลชด้วย ST-Link ได้ และเปลี่ยนตัวได้ถ้าเสีย

**เทอร์มินอลขันสกรู KF301 ระยะขา 5.08 มม. 12 ตัว** สำหรับ TX1-3 · RX1-8 · ไฟ 5V เข้า

**ตัวต้านทาน 1/4W ระยะขา 7.62 มม.**

| ค่า | ตัวถัง | จำนวน | อ้างอิง |
|---|---|---|---|
| **100uF** | C_BULK | 1 | CF |
| **100nF** | C_DISC | 23 | C1G1 C1G2 C2G1 C2G2 C3G1 C3G2 C4G1 C4G2 C5G1 C5G2 C6G1 C6G2 C7G1 C7G2 C8G1 C8G2 CD1 CD2 CD3 CD4 CD5 CD6 CV1 |
| **10nF** | C_DISC | 8 | C1I C2I C3I C4I C5I C6I C7I C8I |
| **1nF** | C_DISC | 8 | C1O C2O C3O C4O C5O C6O C7O C8O |
| **10uF** | C_ELEC | 2 | CB1 CB2 |
| **MCP6024-I/P** | DIP14 | 5 | U2 U3 U4 U5 U6 |
| **SN74HCT04N** | DIP14 | 1 | U1 |
| **1x20 female hdr** | HDR20 | 2 | JA JB |
| **100R** | R_AXIAL | 3 | RT1 RT2 RT3 |
| **10R** | R_AXIAL | 1 | RF |
| **10k** | R_AXIAL | 2 | RV1 RV2 |
| **1M** | R_AXIAL | 8 | R1B R2B R3B R4B R5B R6B R7B R8B |
| **1k** | R_AXIAL | 24 | R1G1 R1G2 R1O R2G1 R2G2 R2O R3G1 R3G2 R3O R4G1 R4G2 R4O R5G1 R5G2 R5O R6G1 R6G2 R6O R7G1 R7G2 R7O R8G1 R8G2 R8O |
| **33k** | R_AXIAL | 16 | R1F1 R1F2 R2F1 R2F2 R3F1 R3F2 R4F1 R4F2 R5F1 R5F2 R6F1 R6F2 R7F1 R7F2 R8F1 R8F2 |
| **5V IN** | TERM2 | 1 | JP |
| **RX1** | TERM2 | 1 | K1 |
| **RX2** | TERM2 | 1 | K2 |
| **RX3** | TERM2 | 1 | K3 |
| **RX4** | TERM2 | 1 | K4 |
| **RX5** | TERM2 | 1 | K5 |
| **RX6** | TERM2 | 1 | K6 |
| **RX7** | TERM2 | 1 | K7 |
| **RX8** | TERM2 | 1 | K8 |
| **TX1** | TERM2 | 1 | T1 |
| **TX2** | TERM2 | 1 | T2 |
| **TX3** | TERM2 | 1 | T3 |

รวม 116 ชิ้น

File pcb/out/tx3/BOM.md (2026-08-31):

# tx3 — รายการชิ้นส่วน

| ค่า | ตัวถัง | จำนวน | อ้างอิง |
|---|---|---|---|
| **100nF** | C_DISC | 1 | C1 |
| **10uF** | C_ELEC | 1 | C2 |
| **74HCT04** | DIP14 | 1 | U1 |
| **PWR** | HDR2 | 1 | JP |
| **TCT40-16T** | HDR2 | 3 | T1 T2 T3 |
| **ESP32** | HDR4 | 1 | J1 |
| **100R** | R_AXIAL | 3 | R1 R2 R3 |

รวม 11 ชิ้น

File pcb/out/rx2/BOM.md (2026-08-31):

# rx2 — รายการชิ้นส่วน

| ค่า | ตัวถัง | จำนวน | อ้างอิง |
|---|---|---|---|
| **100nF** | C_DISC | 5 | C1 C1G1 C1G2 C2G1 C2G2 |
| **10nF** | C_DISC | 2 | C11 C21 |
| **1nF** | C_DISC | 2 | C1O C2O |
| **10uF** | C_ELEC | 1 | C2 |
| **MCP6004** | DIP14 | 1 | U1 |
| **TCT40-16R** | HDR2 | 2 | K1 K2 |
| **ADC OUT** | HDR3 | 1 | J2 |
| **PWR+VREF** | HDR3 | 1 | J1 |
| **1M** | R_AXIAL | 2 | R1B R2B |
| **1k** | R_AXIAL | 6 | R1G1 R1G2 R1O R2G1 R2G2 R2O |
| **33k** | R_AXIAL | 4 | R1F1 R1F2 R2F1 R2F2 |

รวม 27 ชิ้น

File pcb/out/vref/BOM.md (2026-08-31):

# vref — รายการชิ้นส่วน

| ค่า | ตัวถัง | จำนวน | อ้างอิง |
|---|---|---|---|
| **100nF** | C_DISC | 2 | C1 C3 |
| **10uF** | C_ELEC | 2 | C2 C4 |
| **MCP6004** | DIP14 | 1 | U1 |
| **3V3 IN** | HDR2 | 1 | J1 |
| **OUT A** | HDR3 | 1 | J2 |
| **OUT B** | HDR3 | 1 | J3 |
| **OUT C** | HDR3 | 1 | J4 |
| **OUT D** | HDR3 | 1 | J5 |
| **10k** | R_AXIAL | 2 | R1 R2 |

รวม 12 ชิ้น

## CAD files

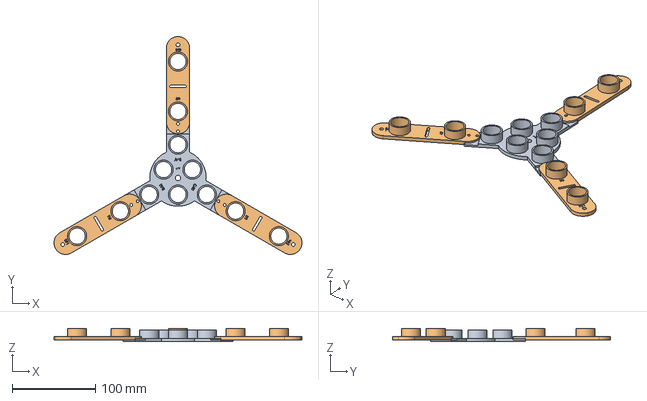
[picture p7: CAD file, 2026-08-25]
hardware/cad/plate_assembly.step
298.2 x 262.0 x 16.0 mm

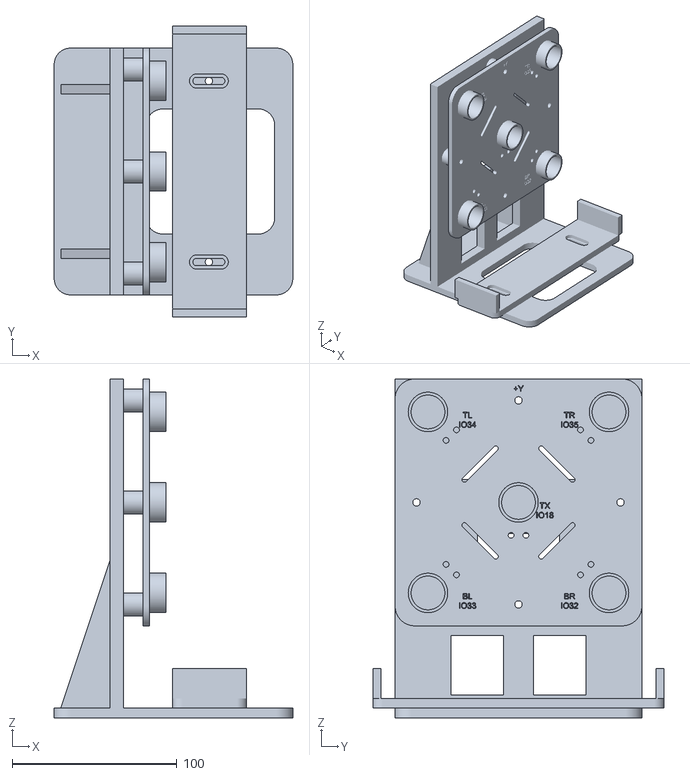
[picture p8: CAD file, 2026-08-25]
hardware/cad/stand_assembly.stl
145.0 x 177.0 x 206.0

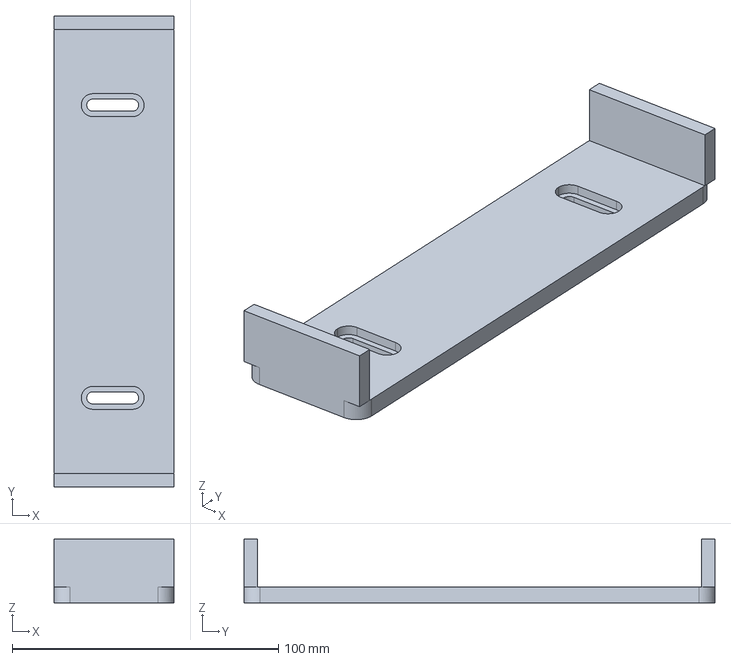
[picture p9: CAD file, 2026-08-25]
hardware/cad/cam_cradle.step
45.0 x 177.0 x 24.0 mm

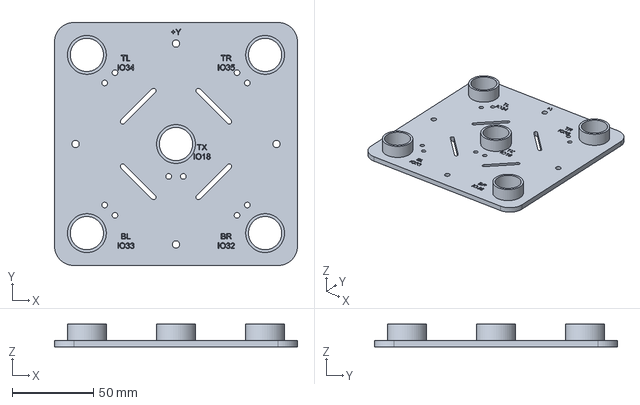
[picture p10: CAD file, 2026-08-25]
hardware/cad/plate_mini.step
150.0 x 150.0 x 14.0 mm

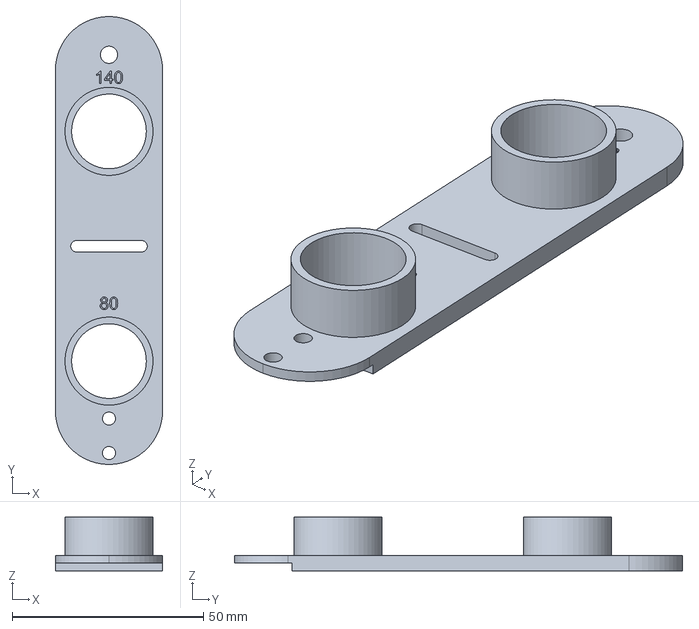
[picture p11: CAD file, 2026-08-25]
hardware/cad/plate_arm.step
28.0 x 117.0 x 14.0 mm

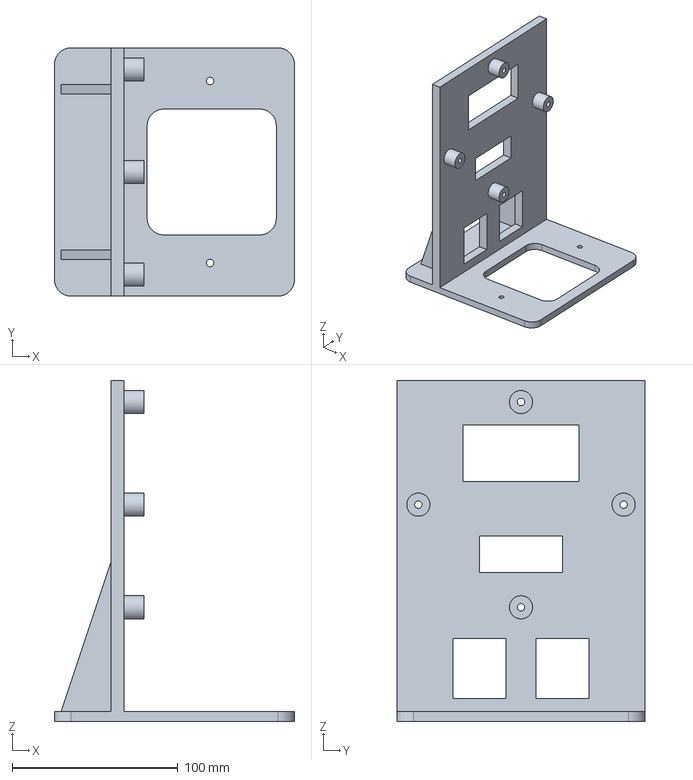
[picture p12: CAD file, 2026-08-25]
hardware/cad/stand_base.step
145.0 x 150.0 x 206.0 mm

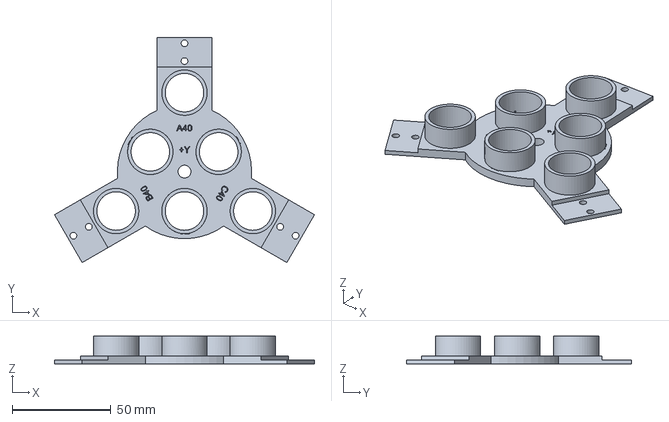
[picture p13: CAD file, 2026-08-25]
hardware/cad/plate_hub.step
131.8 x 114.1 x 14.0 mm

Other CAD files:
hardware/cad/cam_cradle.stl
hardware/cad/plate_arm.stl
hardware/cad/plate_assembly.stl
hardware/cad/plate_hub.stl
hardware/cad/plate_mini.stl
hardware/cad/stand_base.stl

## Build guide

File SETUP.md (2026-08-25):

# SETUP — ติดตั้งเครื่องมือ (ทำได้เลย ไม่ต้องมีอุปกรณ์)

ทุกอย่างในไฟล์นี้ทำได้โดยไม่ต้องมีฮาร์ดแวร์เลย ยกเว้นข้อ 5 ที่ต้องมี ESP32 + สายจัมป์ 1 เส้น

---

## 1. Arduino IDE + ESP32 core **3.x**

1. ติดตั้ง [Arduino IDE 2.x](https://www.arduino.cc/en/software)
2. `File → Preferences → Additional boards manager URLs` ใส่:
   ```
   https://espressif.github.io/arduino-esp32/package_esp32_index.json
   ```
3. `Tools → Board → Boards Manager` ค้น `esp32` → ติดตั้ง **esp32 by Espressif Systems เวอร์ชัน 3.x**

> ✅ **ขั้นตอนที่ 3 ทำให้แล้ว** — ติดตั้ง `esp32:esp32@3.3.11` ผ่าน arduino-cli ไว้ที่
> `C:\Users\User\AppData\Local\Arduino15` ซึ่งเป็นโฟลเดอร์เดียวกับที่ Arduino IDE ใช้
> **เปิด IDE ขึ้นมาจะเห็นบอร์ด ESP32 อยู่แล้ว ไม่ต้องโหลดซ้ำ**
>
> คอมไพล์จากบรรทัดคำสั่งได้ด้วย:
> ```
> arduino-cli compile --fqbn esp32:esp32:esp32 esp32_array/esp32_selftest
> arduino-cli upload  --fqbn esp32:esp32:esp32 -p COM3 esp32_array/esp32_selftest
> ```

> ⚠️ **ต้องเป็น 3.x เท่านั้น** — core 2.x สร้างบน ESP-IDF 4.x ซึ่งไม่มี API
> `esp_adc/adc_continuous.h` ที่โปรเจกต์นี้ใช้ทั้งหมด ถ้าเผลอติดตั้ง 2.x โค้ดจะคอมไพล์ไม่ผ่าน
> ด้วย error ประมาณ `esp_adc/adc_continuous.h: No such file or directory`

**ตั้งค่าบอร์ด** (`Tools`):

| ช่อง | ค่า |
|---|---|
| Board | ESP32 Dev Module |
| Upload Speed | 921600 |
| CPU Frequency | 240 MHz |
| Flash Frequency | 80 MHz |
| Partition Scheme | Default 4MB with spiffs |

---

## 2. ไดรเวอร์ USB-Serial (Windows)

ESP32 DevKit ใช้ชิปแปลง USB 2 แบบ **ดูที่ชิปเล็กๆ ใกล้พอร์ต USB บนบอร์ด**:

| ชิปบนบอร์ด | ไดรเวอร์ |
|---|---|
| **CH340 / CH9102** | [WCH CH341SER](https://www.wch-ic.com/downloads/CH341SER_EXE.html) |
| **CP2102 / CP2104** | [Silicon Labs CP210x VCP](https://www.silabs.com/developers/usb-to-uart-bridge-vcp-drivers) |

**วิธีเช็คว่าสำเร็จ**: เสียบ ESP32 → เปิด Device Manager → ต้องเห็น `USB-SERIAL CH340 (COM3)`
หรือ `Silicon Labs CP210x (COM3)` ใต้ `Ports (COM & LPT)`

**ถ้าไม่เห็นอะไรเลย** ให้สงสัยสาย USB ก่อนเสมอ — สาย micro-USB จำนวนมาก
**ต่อแค่ไฟ ไม่ต่อเส้นข้อมูล** เอาไว้ชาร์จอย่างเดียว นี่คือปัญหาอันดับหนึ่งของมือใหม่
ลองเปลี่ยนสายก่อนจะสงสัยว่าบอร์ดพัง

---

## 3. Python + ไลบรารี

ติดตั้ง [Python 3.10+](https://www.python.org/downloads/) — ตอนติดตั้ง **ติ๊ก "Add python.exe to PATH"**

```bash
pip install -r tools/requirements.txt
```

---

## 4. รัน scope ในโหมดจำลอง — ทำได้เดี๋ยวนี้เลย

```bash
python tools/scope_view.py --simulate
```

จะได้กราฟ 3 แผงที่แสดง **สิ่งที่วงจรที่ทำงานถูกต้องควรให้** ดูให้คุ้นก่อนที่จะได้เห็นของจริง
เพราะเวลาต่อวงจรจริงแล้วผิด คุณจะรู้ทันทีว่ามันผิดตรงไหนเมื่อเทียบกับภาพนี้

**สิ่งที่ต้องสังเกตให้เป็นในภาพจำลอง**

| แผง | สิ่งที่ต้องเห็น | ความหมาย |
|---|---|---|
| บน (raw) | ก้อนใหญ่ตอน t=0 แล้วค่อยๆ ซาลง | **ringing ของตัวส่ง** ไม่ใช่ echo — ตัวส่ง Q สูงจะสั่นต่ออีก ~0.4 ms หลังหยุดขับ ช่วงนี้มองอะไรไม่เห็น = **โซนบอด ~7 cm แรก** |
| กลาง (envelope) | ก้อนเล็กๆ ก้อนที่สอง มีลูกศร ▼ ชี้ | **นี่คือ echo จริง** ตำแหน่งตรงกับเส้นประแดง |
| ล่าง (FFT) | ยอดแหลมยอดเดียวที่ 40 kHz | ถ้าเห็นยอดที่ 50 Hz หรือ 100 Hz ด้วย = สายอินพุตยาวเกินไป รับไฟบ้าน |
| บน (แถบส้ม) | ช่วงที่เอาไปทำ FFT | ต้องคร่อม echo ไม่ใช่คร่อม ringing |

ลองเปลี่ยนระยะดูว่า echo ขยับตามสูตร `t = 2d/c` จริงไหม:

```bash
python tools/scope_view.py --simulate --distance-cm 50
```

**ผลที่ทดสอบแล้วว่าได้จริง:**

| ตั้งไว้ | echo ที่ควรอยู่ | ที่โปรแกรมวัดได้ | SNR |
|---|---|---|---|
| 20 cm | 1.166 ms | 23.5 cm | 29 dB |
| 30 cm | 1.749 ms | 33.2 cm | 30 dB |
| 50 cm | 2.915 ms | 53.2 cm | 30 dB |
| 100 cm | 5.831 ms | 102.8 cm | 28 dB |
| 300 cm | 17.493 ms | 303.2 cm | 11 dB |

> **สังเกตว่ามันเกินไป +3.2 cm ทุกระยะเท่ากันเป๊ะ — นี่ไม่ใช่บั๊ก**
> envelope ขึ้นยอดตอน**จบ**ชุดคลื่น 8 ลูก ไม่ใช่ตอนเริ่ม
> `8 รอบ / 40 kHz = 200 µs → 200µs × 343/2 = 3.43 cm` ตรงกับที่วัดได้
> **ค่าคงที่แบบนี้คือสิ่งที่การคาลิเบรตหักออกได้หมด** และ Stage 2 ที่ใช้
> cross-correlation กับ template จะไม่มีอคตินี้ตั้งแต่แรก
> — เจอ error คงที่ให้ดีใจ เจอ error ที่กระโดดไปมาถึงค่อยกังวล

**เกร็ดที่ฝังอยู่ในโค้ด**: ตัวหา echo ใช้ **CFAR** (เทียบแต่ละจุดกับพื้นหลังรอบข้าง)
ไม่ใช่ "หายอดที่สูงที่สุด" เพราะหางเสียงของตัวส่งจะสูงกว่า echo ไกลๆ เสมอ
สิ่งที่แยกสองอย่างนี้ออกจากกันคือ**รูปร่าง** ไม่ใช่ขนาด — หางเสียงลดลงเรื่อยๆ
ส่วน echo เป็นก้อนนูนที่โผล่ขึ้นมาเหนือเพื่อนบ้านของมันเอง

---

## 5. Self-test: พิสูจน์ว่า ESP32 สตรีม ADC ได้เร็วจริง

**ต้องมี**: ESP32 1 ตัว + สายจัมป์ตัวผู้-ตัวผู้ **1 เส้น** เท่านั้น

```
GPIO25  ────────►  GPIO34
```

GPIO34 เป็นขา input-only ต่อกลับด้านก็ไม่พัง

1. เปิด `esp32_array/esp32_selftest/esp32_selftest.ino` ใน Arduino IDE → อัปโหลด
2. เปิด Serial Monitor ที่ **921600 baud** → ควรเห็นข้อมูลชิปและ `# ready`
3. ปิด Serial Monitor (ไม่งั้นพอร์ตจะถูกจอง) แล้วรัน:

```bash
python tools/scope_view.py --port COM3
```

### เกณฑ์ผ่าน

| ข้อ | ต้องได้ |
|---|---|
| 1 | บรรทัด `# requested 1000.0 kS/s, achieved ___ kS/s` แสดง **≥ 95%** |
| 2 | FFT มียอดชัดที่ **~40 kHz** |
| 3 | ไม่มีข้อความ `!! channel mask mismatch` |
| 4 | สั่ง `f 2000000` ใน Serial Monitor แล้ววัดใหม่ → ดูว่า 2 MS/s ยังผ่านไหม |

### ✅ ผลจริงที่วัดได้แล้วบนบอร์ดของคุณ (ESP32-D0WD-V3 rev 301, COM5)

| ขอ | ได้จริง | % | bin ของ FFT | ความถี่ที่วัดได้ |
|---|---|---|---|---|
| 1,000 kS/s | **976.4** | 97.6% | 953 Hz | 39.02 kHz |
| 1,500 kS/s | **1,464.2** | 97.6% | 1,430 Hz | 39.04 kHz |
| **2,000 kS/s** | **1,951.9** | **97.6%** | 1,906 Hz | 39.03 kHz |

**ผ่านทุกข้อ** — และ 97.6% เท่ากันเป๊ะทั้งสามอัตรา แปลว่าส่วนที่หายไปคือ
**ค่าโสหุ้ยคงที่** (ก้อนแรกที่ทิ้งตอน DMA เริ่มทำงาน) ไม่ใช่เพดานของฮาร์ดแวร์
ถ้าเป็นเพดานจริง เปอร์เซ็นต์จะตกลงเมื่อขออัตราสูงขึ้น

**แผน Stage 3 เดินตามเดิมได้**: 1,951.9 ÷ 6 ช่อง = **325 kS/s ต่อช่อง = 8.1 จุดต่อคาบ 40 kHz**

> ความถี่ที่วัดได้ 39.0 kHz ไม่ใช่ 40.0 เพราะ**ตัวสร้างคลื่นของ DAC ปัดความถี่เป็นขั้น**
> ไม่ใช่ความผิดพลาดของการวัด — สังเกตว่าทั้งสามอัตราให้ตัวเลขตรงกันภายใน **±10 Hz**
> ทั้งที่ bin กว้างถึง 1,906 Hz ซึ่งเป็นผลของ **parabolic interpolation** ที่หาค่ายอดได้
> ละเอียดกว่า bin ประมาณ 100 เท่า — **เทคนิคเดียวกับที่ Stage 2 จะใช้หา Δt ระดับ sub-sample**

> **ตรวจจากไฟล์ของชิปแล้ว** (`soc_caps.h` ของ ESP32 ใน core 3.3.11):
> ```
> SOC_ADC_SAMPLE_FREQ_THRES_HIGH  = 2,000,000   ← 2 MS/s คือ "เพดานสูงสุด" ไม่ใช่ค่าที่สบาย
> SOC_ADC_SAMPLE_FREQ_THRES_LOW   =    20,000
> ```
> แปลว่าแผนที่วางไว้ (6 ช่อง × 333 kS/s) วิ่งอยู่ที่**ขีดสุดของฮาร์ดแวร์พอดี ไม่มีระยะเผื่อเลย**
> ข้อ 4 จึงสำคัญมาก — ถ้าได้จริงต่ำกว่า 2 MS/s ต้องปรับแผน Stage 3

**ข้อ 4 คือคำถามที่แพงที่สุดในโปรเจกต์นี้** — แผนทั้งหมดตั้งอยู่บนสมมติฐานว่า
ADC ทำ 2 MS/s ได้ ถ้าทำได้จริง → 6 ช่อง × 333 kS/s ตามแผน
ถ้าทำได้แค่ 1 MS/s → 6 ช่องเหลือ 167 kS/s/ช่อง = 4.2 sample ต่อคาบ 40 kHz
ซึ่งยังพอทำ cross-correlation ได้แต่ต้องพึ่ง interpolation หนักขึ้น
**รู้ตอนนี้ดีกว่ารู้ตอนบัดกรีเสร็จ 9 ช่องแล้ว**

### ถ้าไม่ผ่าน

| อาการ | สาเหตุที่น่าจะเป็น |
|---|---|
| `adc_continuous.h: No such file` | core เป็น 2.x → กลับไปข้อ 1 |
| `!! this is not an original ESP32` | ได้บอร์ด S3/C3 มา → ต้องเปลี่ยนบอร์ด |
| achieved ต่ำกว่า 90% | ลด `f` ลง แล้วหาเพดานจริงของบอร์ดคุณ |
| FFT ไม่มียอดที่ 40k แต่ raw เป็นเส้นตรง ~1.65 V | สายจัมป์ไม่แน่น หรือเสียบผิดขา |
| `!! bad magic` / `checksum` บ่อย | ลดบอดเป็น 460800 ทั้งใน .ino และ `--baud` |

---

## 6. PulseView สำหรับ Logic Analyzer

1. ติดตั้ง [PulseView (sigrok)](https://sigrok.org/wiki/Downloads)
2. เสียบ logic analyzer → **Windows จะยังไม่รู้จัก** ต้องใช้ [Zadig](https://zadig.akeo.ie/)
   เลือกอุปกรณ์ที่ขึ้นมา → เลือกไดรเวอร์ **WinUSB** → กด Replace Driver
3. เปิด PulseView → เลือก device `fx2lafw`

**ทดสอบว่าใช้ได้**: ต่อคีบ CH0 เข้า GPIO25 ของ ESP32 (ที่กำลังออกคลื่น 40 kHz จาก
self-test) และคีบ GND เข้า GND → กด Run ต้องเห็นคลื่นสี่เหลี่ยม 40 kHz

> ⚠️ **logic analyzer ตัวถูกทนแรงดันแค่ 5V และไม่มีการป้องกัน** ห้ามคีบเข้าไฟ 12V เด็ดขาด
> และ**ต้องต่อ GND ร่วมกันเสมอ**ก่อนคีบสัญญาณ

---

## 7. เช็ค breadboard ด้วยมัลติมิเตอร์ (ก่อนเสียบอะไรทั้งสิ้น)

ใช้โหมด continuity (ไอคอนคลื่นเสียง มีเสียงปี๊บ):

1. **รางไฟขาดกลางหรือเปล่า** — จิ้มหัวรางแดงกับท้ายรางแดง ถ้าไม่ปี๊บ = ขาด
   ต้องกระโดดสายเชื่อมเอง ทำทั้งรางแดงและรางน้ำเงิน **ทั้ง 3 บอร์ด**
2. **แถวไหนพังบ้าง** — สุ่มจิ้มรู a กับ e ของแถวเดียวกัน ต้องปี๊บ
3. **รางแดงกับรางน้ำเงินต้องไม่ปี๊บกัน** (ถ้าปี๊บ = บอร์ดลัดวงจร ทิ้งเลย)

ทำครั้งเดียว 5 นาที ประหยัดเวลาไล่บั๊กเป็นชั่วโมง

---

## ลำดับที่แนะนำ

```
วันนี้ (ไม่มีของ)   → ข้อ 1, 2, 3, 4, 6
ESP32 มาถึง        → ข้อ 5   ← สำคัญที่สุด
breadboard มาถึง    → ข้อ 7
ทรานสดิวเซอร์มาถึง  → เริ่ม Stage 1 จริง (hardware/rx_frontend.md)
```

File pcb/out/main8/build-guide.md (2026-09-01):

# main8 — คู่มือซื้อของและประกอบ

สร้างจาก `netlist.py` โดยตรง จำนวนและรายชื่อทุกตัวจึงตรงกับบอร์ดเสมอ

## 1 · รายการที่ต้องซื้อ

| ต้องซื้อ | จำนวน | ค้นในคลัง EasyEDA | ตัวไหนบ้าง |
|---|---|---|---|
| คาปาอิเล็กโทรไลต์ 100uF 16V ระยะขา 5.08 มม. | **1** | `RAD-0.2` · ระยะขา 5.08 มม. | CF |
| คาปาเซรามิก 100nF 50V ระยะขา 5.08 มม. | **23** | `RAD-0.2` · ระยะขา 5.08 มม. | C1G1 C1G2 C2G1 C2G2 C3G1 C3G2 C4G1 C4G2 C5G1 C5G2 C6G1 C6G2 C7G1 C7G2 C8G1 C8G2 CD1 CD2  … |
| คาปาเซรามิก 10nF 50V ระยะขา 5.08 มม. **ถ้าหาชนิด C0G/NP0 ได้ยิ่งดี** | **8** | `RAD-0.2` · ระยะขา 5.08 มม. | C1I C2I C3I C4I C5I C6I C7I C8I |
| คาปาเซรามิก 1nF 50V ระยะขา 5.08 มม. **C0G/NP0 ถ้าหาได้** | **8** | `RAD-0.2` · ระยะขา 5.08 มม. | C1O C2O C3O C4O C5O C6O C7O C8O |
| คาปาอิเล็กโทรไลต์ 10uF 25V ระยะขา 2.54 มม. | **2** | `RAD-0.1` · ระยะขา 2.54 มม. | CB1 CB2 |
| MCP6024-I/P ตัวถัง DIP-14 | **5** | `DIP-14` · ขา 2.54 แถวห่าง 7.62 มม. | U2 U3 U4 U5 U6 |
| SN74HCT04N ตัวถัง DIP-14 | **1** | `DIP-14` · ขา 2.54 แถวห่าง 7.62 มม. | U1 |
| เฮดเดอร์ตัวเมีย 1x20 ขา ระยะ 2.54 มม. (ตัดจากแถบยาวได้) | **2** | `HDR-1X20 ตัวเมีย` · ขา 2.54 มม. | JA JB |
| ตัวต้านทาน 100 โอห์ม 1/4W | **3** | `AXIAL-0.3` · ระยะขา 7.62 มม. | RT1 RT2 RT3 |
| ตัวต้านทาน 10 โอห์ม 1/4W | **1** | `AXIAL-0.3` · ระยะขา 7.62 มม. | RF |
| ตัวต้านทาน 10k โอห์ม 1/4W **ความคลาดเคลื่อน 1%** | **2** | `AXIAL-0.3` · ระยะขา 7.62 มม. | RV1 RV2 |
| ตัวต้านทาน 1M โอห์ม 1/4W | **8** | `AXIAL-0.3` · ระยะขา 7.62 มม. | R1B R2B R3B R4B R5B R6B R7B R8B |
| ตัวต้านทาน 1k โอห์ม 1/4W **ความคลาดเคลื่อน 1%** | **24** | `AXIAL-0.3` · ระยะขา 7.62 มม. | R1G1 R1G2 R1O R2G1 R2G2 R2O R3G1 R3G2 R3O R4G1 R4G2 R4O R5G1 R5G2 R5O R6G1 R6G2 R6O R7G1 … |
| ตัวต้านทาน 33k โอห์ม 1/4W **ความคลาดเคลื่อน 1%** | **16** | `AXIAL-0.3` · ระยะขา 7.62 มม. | R1F1 R1F2 R2F1 R2F2 R3F1 R3F2 R4F1 R4F2 R5F1 R5F2 R6F1 R6F2 R7F1 R7F2 R8F1 R8F2 |
| เทอร์มินอลบล็อกขันสกรู 2 ขา KF301 | **12** | `KF301-5.0-2P` · ระยะขา 5.08 มม. | JP K1 K2 K3 K4 K5 K6 K7 K8 T1 T2 T3 |

**ดูระยะขาเป็นตัวตัดสิน ไม่ใช่ดูชื่อ** ถ้าระยะไม่ตรง รูบนบอร์ดจะไม่ลง

**ซื้อเผื่อไว้ด้วย** ตัวต้านทานกับคาปาเซรามิกขายเป็นแพ็คอยู่แล้ว ซื้อเผื่ออีก 20% ไม่ได้แพงขึ้นเท่าไร แต่ถ้าขาดกลางคันต้องรอของอีกรอบ
ส่วนชิปกับเทอร์มินอลซื้อเผื่ออย่างละ 1-2 ตัวพอ

### นอกเหนือจากบนบอร์ด

| ของ | จำนวน | หมายเหตุ |
|---|---|---|
| บอร์ด STM32F103C8T6 (Blue Pill) | 1 | เสียบลงเฮดเดอร์ JA JB |
| ST-Link V2 | 1 | ใช้แฟลชโปรแกรม · ต่อ 3.3V GND SWDIO=PA13 SWCLK=PA14 และตั้ง BOOT0=0 |
| หัวส่งอัลตราโซนิก 40 kHz | 3 | ต่อที่ TX1 TX2 TX3 |
| หัวรับอัลตราโซนิก 40 kHz | 8 | ต่อที่ RX1 ถึง RX8 |
| ไฟเลี้ยง 5V | 1 | ต่อที่ JP · กินราว 100 mA |

## 2 · เหตุผลของแต่ละตัว และข้อควรระวัง

**คาปาอิเล็กโทรไลต์ 100uF 16V ระยะขา 5.08 มม.**  (1 ตัว)

**มีขั้ว** ตัวนี้อยู่บนราง 3.3V จะใช้ 16V หรือ 25V ก็ได้

**คาปาเซรามิก 100nF 50V ระยะขา 5.08 มม.**  (23 ตัว)

X7R ใช้ได้ · ตัวที่ขึ้นต้น CD คือคาปาประกบชิป **ต้องอยู่ชิดขาชิป**

**คาปาเซรามิก 10nF 50V ระยะขา 5.08 มม. **ถ้าหาชนิด C0G/NP0 ได้ยิ่งดี****  (8 ตัว)

แปดตัวนี้คือทางเข้าของทั้งแปดช่อง ถ้าค่าไม่เท่ากันแต่ละช่องจะตอบสนองความถี่ต่างกันเล็กน้อย C0G นิ่งกว่า X7R มากทั้งเรื่องอุณหภูมิและแรงดัน

**คาปาเซรามิก 1nF 50V ระยะขา 5.08 มม. **C0G/NP0 ถ้าหาได้****  (8 ตัว)

ตัวกรองก่อนเข้า ADC เหตุผลเดียวกับ 10nF

**คาปาอิเล็กโทรไลต์ 10uF 25V ระยะขา 2.54 มม.**  (2 ตัว)

**มีขั้ว ใส่กลับด้านแล้วระเบิด** ขายาว = บวก · บนบอร์ดขา 1 คือบวก

**MCP6024-I/P ตัวถัง DIP-14**  (5 ตัว)

**ต้องมี -I/P ต่อท้าย** ไม่งั้นได้ตัวถังติดผิวหน้ามาเสียบไม่ได้ · ต้องการแบนด์วิดท์ 34 x 40kHz = 1.36 MHz ตัวนี้ให้ 10 MHz เหลือเฟือ

**SN74HCT04N ตัวถัง DIP-14**  (1 ตัว)

**ต้องเป็น HCT ห้ามใช้ HC** เพราะ STM32 ส่งสัญญาณมาที่ 3.3V แต่ชิปตัวนี้กินไฟ 5V · HCT รับระดับสูงตั้งแต่ 2V ขึ้นไปจึงอ่านได้ ส่วน HC ต้องการถึง 3.5V จะอ่านสัญญาณ 3.3V ไม่ออก

**เฮดเดอร์ตัวเมีย 1x20 ขา ระยะ 2.54 มม. (ตัดจากแถบยาวได้)**  (2 ตัว)

สองแถวห่างกัน 17.78 มม. สำหรับเสียบ Blue Pill · **อย่าบัดกรีบอร์ด STM32 ลงไปตรง ๆ** จะถอดไปแฟลชไม่ได้

**ตัวต้านทาน 100 โอห์ม 1/4W**  (3 ตัว)

กันกระแสพุ่งตอนขับหัวส่ง 5% พอ

**ตัวต้านทาน 10 โอห์ม 1/4W**  (1 ตัว)

คั่นไฟแอนะล็อกออกจากไฟดิจิทัล 5% พอ

**ตัวต้านทาน 10k โอห์ม 1/4W **ความคลาดเคลื่อน 1%****  (2 ตัว)

สองตัวนี้แบ่งไฟครึ่งหนึ่งเป็นแรงดันอ้างอิง ถ้าไม่เท่ากันจุดกลางจะเลื่อน แล้วคลื่นจะถูกตัดข้างเดียวก่อนถึงจุดสูงสุด

**ตัวต้านทาน 1M โอห์ม 1/4W**  (8 ตัว)

ค่าคลาดเคลื่อน 5% พอ ตัวนี้แค่ดึงระดับกลาง ไม่ได้กำหนดอัตราขยาย

**ตัวต้านทาน 1k โอห์ม 1/4W **ความคลาดเคลื่อน 1%****  (24 ตัว)

ตัวที่ลงท้าย G1/G2 คู่กับ 33k กำหนดอัตราขยาย · ตัวที่ลงท้าย O เป็นตัวกรองปลายทาง ใช้ 5% ก็ได้ แต่ซื้อ 1% ทั้งหมดง่ายกว่าแยกสองแบบ

**ตัวต้านทาน 33k โอห์ม 1/4W **ความคลาดเคลื่อน 1%****  (16 ตัว)

**คู่นี้กำหนดอัตราขยาย** ถ้าใช้ 5% แต่ละช่องจะขยายไม่เท่ากัน แล้วการเทียบความแรงระหว่างช่องจะเพี้ยน ซึ่งเป็นหัวใจของการหาทิศทาง

## 3 · สามอย่างที่ใส่กลับด้านแล้วพัง

ที่เหลือใส่กลับด้านได้ไม่เป็นไร แต่สามกลุ่มนี้ต้องดูให้ดี

| ตัว | ดูยังไง |
|---|---|
| **ชิปทั้ง 6 ตัว** (U1-U6) | บนบอร์ดมี**จุดวงกลมเล็กพิมพ์ไว้ข้างขา 1** ให้ตรงกับรอยบากหรือจุดบนตัวชิป |
| **คาปาอิเล็กโทรไลต์** (CB1 CB2 CF) | ขายาว = บวก · ข้างตัวมีแถบขาวชี้ขาลบ · บนบอร์ดขา 1 คือบวก |
| **เทอร์มินอล** (T1-T3 K1-K8 JP) | ช่องเสียบสายต้องหันออกนอกบอร์ด ไม่ใช่หันเข้าใน |

## 4 · ลำดับการบัดกรี

บัดกรีจากตัวเตี้ยไปตัวสูง ตัวเตี้ยจะได้ไม่ถูกตัวสูงบัง

1. ตัวต้านทานทั้งหมด (54 ตัว) — เตี้ยที่สุด นอนราบกับบอร์ด
2. ชิป 6 ตัว — **ดูจุดขา 1**
3. คาปาเซรามิก (39 ตัว)
4. คาปาอิเล็กโทรไลต์ 3 ตัว — **ดูขั้ว**
5. เฮดเดอร์ตัวเมีย JA JB — เสียบ Blue Pill ทาบไว้ก่อนบัดกรี จะได้แถวตรงและระยะพอดี
6. เทอร์มินอล 12 ตัว — สูงที่สุด บัดกรีท้ายสุด

## 5 · ตรวจก่อนจ่ายไฟครั้งแรก

**ยังไม่ต้องเสียบ Blue Pill และยังไม่ต้องต่อหัวส่งหัวรับ**

1. ตั้งมัลติมิเตอร์เป็นวัดความต่อเนื่อง วัดระหว่างขา 5V กับ GND ที่ JP
   — **ต้องไม่ต่อถึงกัน** ถ้าร้องแปลว่าลัดวงจร ห้ามจ่ายไฟเด็ดขาด
2. วัดระหว่างขา 4 กับขา 11 ของชิปแต่ละตัว — ต้องไม่ต่อถึงกันเช่นกัน
3. จ่ายไฟ 5V แล้ววัดที่ขา 14 ของ U1 — ต้องได้ราว 5V
4. ยังไม่มี 3.3V ในขั้นนี้ เพราะ 3.3V มาจากเรกูเลเตอร์บน Blue Pill
   ต้องเสียบ Blue Pill ก่อนถึงจะวัดได้

## 6 · หลังเสียบ Blue Pill

1. วัดที่ขา 4 ของ U2 ถึง U6 — ต้องได้ราว **3.1V** (ไม่ใช่ 3.3V เพราะตัวต้านทาน 10R ทำให้ตกไป 0.2V ซึ่งตั้งใจให้เป็นแบบนั้น)
2. วัดที่ขา 1 ของ U6 (แรงดันอ้างอิง VREF) — ต้องได้ราว **1.55V** คือครึ่งหนึ่งของ 3.1V พอดี
   ถ้าไม่ใช่ครึ่ง ให้ดู RV1 RV2 ว่าใส่ค่าถูกและบัดกรีติดจริงไหม
3. วัดที่ขา 1 ของ U2 (ขาออกช่องรับที่ 1 สเตจแรก) ตอนเงียบ ๆ — ต้องได้ใกล้ 1.55V เหมือนกัน
   ถ้าได้ใกล้ 0V หรือใกล้ 3.1V แปลว่าสเตจนั้นอิ่มตัว ให้ดูว่า 1M กับ 10nF ที่ทางเข้าใส่ถูกที่ไหม

## 7 · สิ่งที่ยังไม่มี และต้องมีก่อนบอร์ดจะทำงาน

**โปรแกรมสำหรับ STM32 ยังไม่ได้เขียนเลยแม้แต่บรรทัดเดียว**

บอร์ดนี้ประกอบเสร็จแล้วจะยังทำอะไรไม่ได้ จนกว่าจะมีโปรแกรมที่

- ตั้ง TIM4 ช่อง 1/2/3 (ขา B6 B7 B8) ให้ออกคลื่นสี่เหลี่ยม 40 kHz เป็นชุดสั้น ๆ
- ตั้ง ADC1 กับ ADC2 ให้อ่านขา A0 ถึง A7 พร้อมกันแบบต่อเนื่องผ่าน DMA
- ส่งข้อมูลออกทางพอร์ตอนุกรมด้วยรูปแบบเดียวกับที่ `car/sync4.py` อ่านอยู่ตอนนี้

ของเดิมที่ใช้อยู่เป็น ESP32 อ่านได้ 4 ช่อง โปรแกรมนั้นย้ายมาตรง ๆ ไม่ได้ เพราะเป็นคนละตระกูลชิปกันคนละเรื่อง

**แนะนำให้เขียนและทดสอบโปรแกรมบน Blue Pill เปล่า ๆ กับเซ็นเซอร์ตัวเดียวก่อนสั่งทำบอร์ด** ถ้าเขียนไม่ผ่านจะได้ยังไม่เสียค่าบอร์ด

## 8 · ต่อสายเซ็นเซอร์

เทอร์มินอลทุกตัวมี 2 ขา · ขาบนคือสัญญาณ ขาล่างคือกราวด์
หัวอัลตราโซนิกไม่มีขั้ว สลับสายได้ไม่เป็นไร

| เทอร์มินอล | ต่อกับ | เข้าขา STM32 |
|---|---|---|
| T1 | หัวส่ง TX1 | B6 (TIM4 ช่อง 1) |
| T2 | หัวส่ง TX2 | B7 (TIM4 ช่อง 2) |
| T3 | หัวส่ง TX3 | B8 (TIM4 ช่อง 3) |
| K1 | หัวรับ RX1 | A0 |
| K2 | หัวรับ RX2 | A1 |
| K3 | หัวรับ RX3 | A2 |
| K4 | หัวรับ RX4 | A3 |
| K5 | หัวรับ RX5 | A4 |
| K6 | หัวรับ RX6 | A5 |
| K7 | หัวรับ RX7 | A6 |
| K8 | หัวรับ RX8 | A7 |
| JP | ไฟเลี้ยง 5V | — |

**ตำแหน่งการวางหัวรับสำคัญพอ ๆ กับวงจร** โมเดลที่เทรนไว้เรียนจากตำแหน่งชุดหนึ่งโดยเฉพาะ ถ้าย้ายตำแหน่งต้องเก็บข้อมูลใหม่และเทรนใหม่

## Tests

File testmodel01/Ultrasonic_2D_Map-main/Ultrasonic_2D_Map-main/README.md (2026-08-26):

# Ultrasonic 2D Map — Teaching Ultrasound to "See" Like a Camera

**Give a robot eyes made of sound.**

This project turns a cheap 4-receiver ultrasonic array (the kind of sensor that
normally only tells you "something is 80 cm ahead") into a low-resolution
**camera**: from raw echo waveforms alone, it produces an rviz-style top-down
map of the space in front of the robot — where obstacles are, how far away,
and at what angle.

The trick: during training, a depth camera acts as a **teacher**, labeling every
ultrasonic recording with the true shape of the room. After training, the model
runs on **ultrasound alone** — no camera needed. This matters because depth
cameras fail exactly where ultrasound is strongest:

| Condition | Depth camera (Astra/RealSense) | This ultrasonic array |
|---|---|---|
| Glass / mirrors / glossy surfaces | ❌ blind | ✅ works |
| Transparent plastic | ❌ blind | ✅ works |
| Closer than 0.6 m | ❌ blind (min range) | ✅ works |
| Direct sunlight | ❌ washed out | ✅ works |
| Cost | $$$ | $ |

---

## 1. The hardware this was built for

Built as the next stage of [ultrasonic01](https://github.com/pawaritmuangrach/ultrasonic01) — same hardware, same recorded datasets, better model.

```
                 ▲ T1 (transmitter, fires 40 kHz burst)
    A140 ●───────────● C140      ← outer pair, baseline 242 mm
    A80  ●───────────● C80       ← inner pair, baseline 139 mm

   ESP32 samples all 4 receivers simultaneously @ ~66 kHz/channel
   (bandpass sampling: the 40 kHz echo aliases down to ~26 kHz, intact)
```

- **T1** fires a 16-cycle burst (~400 µs)
- Echoes bounce off obstacles and return; each receiver hears them at slightly
  different times and loudnesses
- **Distance** lives in *when* the echo arrives (time-of-flight, sound = 343 m/s,
  round trip = 58.3 µs per cm)
- **Direction** lives in *differences between channels* (TDOA between receiver
  pairs + amplitude ratios)

## 2. The dataset (not in git — record with ultrasonic01's `car/record.py`)

5 continuous walks (`walk_s1`–`walk_s5`) of ~60 s each, walking through a real
room with people moving. Every ~70 ms, two things were saved simultaneously:

| File | Content |
|---|---|
| `us_XXXXXX.npz` | `counts[4][871]` uint16 raw ADC samples @ ~66 kHz, plus `rate`, `pins`, timestamps, `sync_ms`, quality flags |
| `depth_XXXXXX.png` | 320×240 uint16 depth image in **millimeters** (0 = invalid), from the Astra camera looking the same direction |

Total ≈ 4,300 synchronized (echo, truth) pairs. Split for all experiments:
**s1–s3 train / s4 validation / s5 test** — split by walk session, never by
random frames, because consecutive frames are nearly identical and random
splitting leaks answers into training.

## 3. How the model works (PolarScan v2)

```
raw echoes ──► calibrated DSP ──► features ──► neural net ──► polar map
(4×871)        physics.py         (4,128)+     PolarNet       13 bins × dist
               T0 calibration     6× TDOA                     + nearest obj
               bandpass           amplitudes                  distance + angle
               common peak        SNR                         + validity mask
               GCC-PHAT
```

Step by step:

1. **Envelope extraction** — the raw wave oscillates at 40 kHz; we don't care
   about the wiggles, we care *when it gets loud*. A Hilbert transform extracts
   the loudness-over-time curve ("envelope") per channel.
2. **T0 calibration** — the system has a fixed delay (burst length + filter
   lag). Calibrated against the camera: wrong T0 shifted every reading by
   +13 cm; fixing it cut error from 20 → 9.7 cm.
3. **Range gate** — only look for echoes in the 40–200 cm window, otherwise
   argmax latches onto burst ring-down and reads garbage.
4. **Common peak** — the obstacle is at ONE distance, so all channels should
   peak at the same time. Use the quietest channel (least noise) to define the
   shared window. Worth 20.6 → 7.3 cm on its own.
5. **GCC-PHAT cross-correlation** — for all **6 receiver pairs**, compute the
   precise sub-sample time difference between their envelopes. This is the
   physically correct way to measure angle, replacing hand-tuned features.
6. **Range profiles** — each channel's envelope resampled to 128 distance bins
   (bin i ≈ distance i·1.25 cm). The network sees the full echo SHAPE, not just
   the loudest peak — multipath and echo width carry information.
7. **PolarNet** — small CNN over the profiles, concatenated with TDOA/amplitude/
   SNR/calibrated-physics-distance features, decoded into:
   - **13 angular-bin distances** (a mini radar sweep, ~4.5° per bin)
   - **validity flag** per bin (is anything actually there?)
   - **nearest-object distance & angle** (the number a collision-avoider needs)
8. **Training** — masked loss: only bins where the camera actually saw surface
   AND the bin is inside the sensors' physical coverage contribute. The camera
   labels are built by back-projecting depth pixels through the pinhole model.

### Why it beats ultrasonic01

| | ultrasonic01 | PolarScan v2 (this repo) |
|---|---|---|
| Output | ONE object per ping (single dist + angle) | Full 13-bin scan + object |
| Angle features | amplitude ratio + windowed argmax on 2 pairs | GCC-PHAT on all 6 pairs |
| Range approach | pure physics (argmax), throws away echo shape | physics as input feature, NN learns corrections |
| Nearest-object MAE* | 7.3 cm static / ~27 cm walking | **4.30 cm walking** |
| Angle MAE | 11.8° | **11.0°** |

\* Their 7.3 cm was measured on a static PVC pipe target. On walking-target
footage their own docs report ~27 cm error. Our 4.30 cm test set is continuous
walking footage — a harder setting.

Full write-up: [`output/POLARSCAN_VS_REPO.md`](output/POLARSCAN_VS_REPO.md)

## 4. Second model included: Grid CNN (generation 1)

First attempt: map echoes directly to a 64×48 Cartesian grid (3 m × 2.4 m,
~5 cm cells) via CNN encoder-decoder. Test result: **1.84 cm cell-MAE vs
129 cm for naive ToF painting**. Kept for reference and comparison;
PolarScan supersedes it because polar bins match the array's actual geometry.

## 5. Installation & usage

```bash
# environment (CPU torch is enough — model trains in ~15 min)
uv venv .venv
uv pip install --python .venv/bin/python torch --index-url https://download.pytorch.org/whl/cpu
uv pip install --python .venv/bin/python numpy scipy matplotlib pillow

# put dataset in ./dataset/walk_s1..s5 (see §2)

# train PolarScan v2
.venv/bin/python -m usmap.polar_train
# → output/models/polarscan.pt, prints val metrics each epoch

# train grid CNN (gen 1)
.venv/bin/python -m usmap.train
.venv/bin/python -m usmap.evaluate

# single-frame inference — ultrasound ONLY, no camera
.venv/bin/python infer.py dataset/walk_s5/us_000123.npz
```

## 6. Live web demo (mini-rviz)

```bash
.venv/bin/python webapp_polar.py    # then open http://localhost:8766
```

- Radar-style display: blue wedges = the 13-bin ultrasonic scan, orange dots =
  camera ground truth (toggleable), range rings every 50 cm, ▲ = sensor array
- Pick any walk/frame, hit **▶ Play** to animate like a live radar sweep
- Live stats: nearest object distance+angle, physics-only estimate, MAE vs GT
- Per-bin table comparing model vs camera

Older grid demo: `.venv/bin/python webapp.py` → http://localhost:8765

## 7. Project layout

```
usmap/                    python package
├── config.py             sensor geometry, grid size, splits, hyperparameters
├── physics.py            ★ calibrated DSP: T0=1220µs, gates, common peak,
│                           GCC-PHAT TDOA, range profiles
├── polar_gt.py           depth PNG → 13 true-angle polar labels
├── polar_data.py         dataset assembly for PolarScan
├── polar_model.py        PolarNet architecture + losses + metrics
├── polar_train.py        training loop
├── echo.py               envelope/range-profile utilities (grid model)
├── groundtruth.py        depth PNG → Cartesian GT grid
├── data.py, models.py    grid CNN model
├── train.py, evaluate.py grid CNN train/eval
webapp_polar.py           live radar server (:8766)
webapp.py                 grid demo server (:8765)
webapp/                   frontend HTML
infer.py                  CLI inference on one npz
output/POLARSCAN_VS_REPO.md   benchmark write-up
output/models/            trained weights (gitignored — retrain or ask)
```

## 8. Honest limitations

- **Angular resolution**: 4 receivers fundamentally limits direction accuracy
  (~11°). Recording all 9 RX positions (A/B/C × 40/80/140) drops into the same
  pipeline unchanged — just more input channels.
- **Camera intrinsics assumed**: 58.4° H-FOV (Astra Pro spec). If your exact
  camera differs, labels shift slightly; retraining fixes it.
- **Sync noise**: US↔camera offset ±35 ms smears labels during fast motion.
- **Single-room generalization**: test split is a different recording session
  but the same room. Cross-room transfer is untested.
- **Specular surfaces can still fool everyone**: smooth walls angled away
  reflect sound elsewhere — MIMO (3 TX, planned in ultrasonic01 Stage B+)
  addresses this.

## 9. ROS / rviz (planned)

The 13-bin scan maps directly onto `sensor_msgs/LaserScan`. An export node is
the next step — the web app's radar view is already a stand-in for rviz.

## 10. Credits

Hardware, recording pipeline, calibration lessons (T0, common peak, bandpass
sampling), and datasets: [pawaritmuangrach/ultrasonic01](https://github.com/pawaritmuangrach/ultrasonic01).
Modeling, PolarScan v2, evaluation: this repo.

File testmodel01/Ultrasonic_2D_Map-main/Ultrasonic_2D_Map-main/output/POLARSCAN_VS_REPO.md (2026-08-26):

# PolarScan v2 — comparison vs ultrasonic01 repo

## Task framing difference
Repo predicts ONE object per ping: (distance of loudest echo, angle).
PolarScan v2 predicts a full 13-bin polar scan (nearest surface per ~4.5° bin)
PLUS the repo-style nearest-object (distance, angle) for direct comparison.

## Results — held-out walk_s5 (recorded in a different run than training data)

| Metric | ultrasonic01 best published | PolarScan v2 | improvement |
|---|---|---|---|
| Nearest-object distance MAE | 7.3 cm (physics) / 13.6 cm (their NN) | **4.30 cm** | 41% better than their physics, 68% better than their NN |
| Angle MAE | 11.8 deg (their NN) | **11.00 deg** | slightly better |
| Physics baseline on this data | — | 12.07 cm | model beats physics by 64% |

Validation (walk_s4): near-dist 3.83 cm, angle 10.70 deg.

Note: our test is *harder* than the repo's static-target benchmarks —
this is continuous walking footage with people moving (the repo itself measured
27.4 cm physics error on walking targets vs their 7.3 cm on static PVC pipes).

## What makes v2 better
1. Full polar-scan supervision (13 bins + validity logits) instead of single object —
   richer learning signal per frame, no "which peak is THE object" ambiguity.
2. GCC-PHAT cross-correlation features between ALL 6 receiver pairs
   (repo used amplitude-ratio + windowed argmax on only 2 pairs).
3. Repo's hard-won tricks kept and reused: T0=1220us calibration, common-peak window,
   bandpass sampling band selection, scene-based splits.
4. Hybrid physics+learned: network receives calibrated physics distance as an input
   feature and learns to correct it.

## Files
- usmap/physics.py      — calibrated signal processing (T0, gates, GCC-PHAT)
- usmap/polar_gt.py     — polar labels from depth camera (true-angle bins)
- usmap/polar_data.py   — dataset assembly
- usmap/polar_model.py  — PolarNet + masked losses + metrics
- usmap/polar_train.py  — training loop
- output/models/polarscan.pt — trained weights

Run: .venv/bin/python -m usmap.polar_train

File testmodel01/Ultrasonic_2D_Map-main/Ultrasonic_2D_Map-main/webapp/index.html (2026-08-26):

# ◉ Ultrasonic-as-Camera — live mapping demo

4 receivers (A140·A80 left · C80·C140 right) + T1 transmitter → rviz-style top-down map · depth camera used only as training teacher

## How it works

1. Listen. T1 fires an ultrasonic burst (~66 kHz sampling). Each of the 4 receivers records a raw echo of 871 samples — that's the model's only input.
  inputus_XXXXXX.npz → counts[4][871]
2. Hear shape, not noise. The echo is baseline-corrected and turned into a Hilbert envelope, then resampled to 128 range bins (bin i ≈ distance i·200/128 cm). Physics does half the work: the time axis is distance.
3. Predict. A small 1D-CNN encoder reads the four range profiles (+ ToF & amplitude hints) and decodes a 64×48 top-down grid: 3 m wide × 2.4 m deep, each cell ≈ 5 cm, colored by obstacle distance in cm.
4. How it learned. During training only, a depth camera provided ground-truth maps (back-projected to the same grid). The CNN was trained to imitate them from ultrasound alone — sensor distillation. At runtime no camera is needed.
5. Accuracy. Held-out walk test: mean error ≈ 1.8 cm per cell vs 129 cm for naive ToF ray-painting.

## How you feed it

- Pick any recorded frame from the dropdown on the right, or
- drop / browse your own us_XXXXXX.npz file (format: counts[4][871] uint16, channel order A140, A80, C80, C140).

## Live map

▶ Play Step ▶| Upload npz GT overlay

0cm

250cm top-down · +Y forward · X right

–inference fps

–ToF per ch (cm)

–nearest predicted cell

–vs GT MAE

…or drop a us_*.npz file here

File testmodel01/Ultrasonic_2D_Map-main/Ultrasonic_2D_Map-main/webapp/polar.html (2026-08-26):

# ◉ PolarScan v2 — ultrasonic radar (beats ultrasonic01: 4.3 cm vs 7.3 cm)

4 RX + T1 TX · full 13-bin polar scan per ping · depth camera used only as teacher

▶ Play Step ▶| GT ring

▲ = sensor array · blue wedges = model scan · orange = camera ground truth · range rings every 50 cm

## Live readout

nearest object (model) | –
its angle | –
physics-only estimate | –
vs camera GT (MAE) | –

## Per-bin scan (model vs GT)

## How to read it

- Each blue wedge is one of 13 angular bins (~4.5° each). Its distance from center = nearest surface the ultrasound "hears" in that direction.
- Orange markers are what the depth camera says (teacher data) — shown only when you enable GT ring.
- Model input is only the raw echo waveforms (counts[4][871]) — no camera at inference.
- Test accuracy: 4.30 cm distance / 11.0° angle vs ultrasonic01's 7.3 cm / 11.8°.

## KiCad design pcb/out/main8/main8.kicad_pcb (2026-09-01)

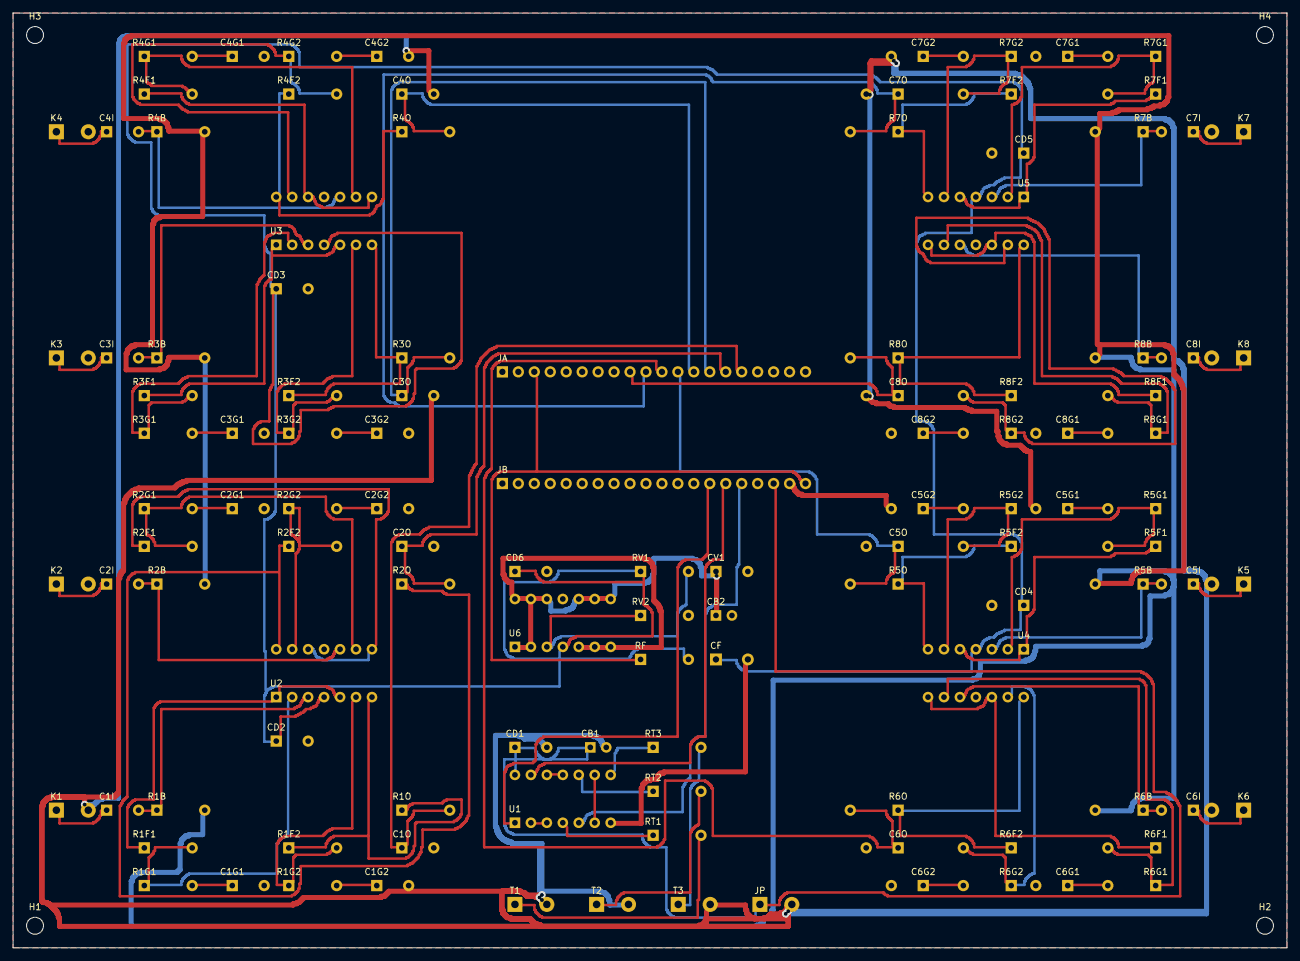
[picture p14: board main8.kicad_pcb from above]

Board: 2 copper layers, 202.8 x 148.8 mm, 120 parts (0 on the bottom side), 90 nets.

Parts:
C1G1, C1G2, C2G1, C2G2, C3G1, C3G2, C4G1, C4G2, C5G1, C5G2, C6G1, C6G2, C7G1, C7G2, C8G1, C8G2: 100nF; C_DISC
C1I, C2I, C3I, C4I, C5I, C6I, C7I, C8I: 10nF; C_DISC
C1O, C2O, C3O, C4O, C5O, C6O, C7O, C8O: 1nF; C_DISC
CB1, CB2: 10uF; C_ELEC
CD1, CD2, CD3, CD4, CD5, CD6: 100nF; C_DISC
CF: 100uF; C_BULK
CV1: 100nF; C_DISC
H1, H2, H3, H4: M2.5; MountingHole
JA: Blue Pill; HDR20
JB: Blue Pill; HDR20
JP: 5V IN; TERM2
K1: RX1; TERM2
K2: RX2; TERM2
K3: RX3; TERM2
K4: RX4; TERM2
K5: RX5; TERM2
K6: RX6; TERM2
K7: RX7; TERM2
K8: RX8; TERM2
R1B, R2B, R3B, R4B, R5B, R6B, R7B, R8B: 1M; R_AXIAL
R1F1, R1F2, R2F1, R2F2, R3F1, R3F2, R4F1, R4F2, R5F1, R5F2, R6F1, R6F2, R7F1, R7F2, R8F1, R8F2: 33k; R_AXIAL
R1G1, R1G2, R1O, R2G1, R2G2, R2O, R3G1, R3G2, R3O, R4G1, R4G2, R4O, R5G1, R5G2, R5O, R6G1, R6G2, R6O, R7G1, R7G2, R7O, R8G1, R8G2, R8O: 1k; R_AXIAL
RF: 10R; R_AXIAL
RT1, RT2, RT3: 100R; R_AXIAL
RV1, RV2: 10k; R_AXIAL
T1: TX1; TERM2
T2: TX2; TERM2
T3: TX3; TERM2
U1: 74HCT04; DIP14
U2, U3, U4, U5, U6: MCP6024; DIP14

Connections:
A3V3: CD2.1, CD3.1, CD4.1, CD5.1, CD6.1, CF.1, RF.2, RV1.1, U2.4, U3.4, U4.4, U5.4, U6.4
GND: C1G1.2, C1G2.2, C1O.2, C2G1.2, C2G2.2, C2O.2, C3G1.2, C3G2.2, C3O.2, C4G1.2, C4G2.2, C4O.2, C5G1.2, C5G2.2, C5O.2, C6G1.2, C6G2.2, C6O.2, C7G1.2, C7G2.2, C7O.2, C8G1.2, C8G2.2, C8O.2, CB1.2, CB2.2, CD1.2, CD2.2, CD3.2, CD4.2, CD5.2, CD6.2, CF.2, CV1.2, JA.1, JA.2, JB.19, JP.2, K1.2, K2.2, K3.2, K4.2, K5.2, K6.2, K7.2, K8.2, RV2.2, T1.2, T2.2, T3.2, U1.7, U2.11, U3.11, U4.11, U5.11, U6.11
MCU3V3: JA.3, JB.20, RF.1
MID: RV1.2, RV2.1, U6.3
P5V: CB1.1, CD1.1, JB.18, JP.1, U1.14
RX1_ADC: C1O.1, JA.16, R1O.2
RX1_G: C1I.2, R1B.1, U2.3
RX1_G1: C1G1.1, R1G1.2
RX1_G2: C1G2.1, R1G2.2
RX1_IN: C1I.1, K1.1
RX1_S1N: R1F1.2, R1G1.1, U2.2
RX1_S1O: R1F1.1, U2.1, U2.5
RX1_S2N: R1F2.2, R1G2.1, U2.6
RX1_S2O: R1F2.1, R1O.1, U2.7
RX2_ADC: C2O.1, JA.15, R2O.2
RX2_G: C2I.2, R2B.1, U2.10
RX2_G1: C2G1.1, R2G1.2
RX2_G2: C2G2.1, R2G2.2
RX2_IN: C2I.1, K2.1
RX2_S1N: R2F1.2, R2G1.1, U2.9
RX2_S1O: R2F1.1, U2.8, U2.12
RX2_S2N: R2F2.2, R2G2.1, U2.13
RX2_S2O: R2F2.1, R2O.1, U2.14
RX3_ADC: C3O.1, JA.14, R3O.2
RX3_G: C3I.2, R3B.1, U3.3
RX3_G1: C3G1.1, R3G1.2
RX3_G2: C3G2.1, R3G2.2
RX3_IN: C3I.1, K3.1
RX3_S1N: R3F1.2, R3G1.1, U3.2
RX3_S1O: R3F1.1, U3.1, U3.5
RX3_S2N: R3F2.2, R3G2.1, U3.6
RX3_S2O: R3F2.1, R3O.1, U3.7
RX4_ADC: C4O.1, JA.13, R4O.2
RX4_G: C4I.2, R4B.1, U3.10
RX4_G1: C4G1.1, R4G1.2
RX4_G2: C4G2.1, R4G2.2
RX4_IN: C4I.1, K4.1
RX4_S1N: R4F1.2, R4G1.1, U3.9
RX4_S1O: R4F1.1, U3.8, U3.12
RX4_S2N: R4F2.2, R4G2.1, U3.13
RX4_S2O: R4F2.1, R4O.1, U3.14
RX5_ADC: C5O.1, JA.12, R5O.2
RX5_G: C5I.2, R5B.1, U4.3
RX5_G1: C5G1.1, R5G1.2
RX5_G2: C5G2.1, R5G2.2
RX5_IN: C5I.1, K5.1
RX5_S1N: R5F1.2, R5G1.1, U4.2
RX5_S1O: R5F1.1, U4.1, U4.5
RX5_S2N: R5F2.2, R5G2.1, U4.6
RX5_S2O: R5F2.1, R5O.1, U4.7
RX6_ADC: C6O.1, JA.11, R6O.2
RX6_G: C6I.2, R6B.1, U4.10
RX6_G1: C6G1.1, R6G1.2
RX6_G2: C6G2.1, R6G2.2
RX6_IN: C6I.1, K6.1
RX6_S1N: R6F1.2, R6G1.1, U4.9
RX6_S1O: R6F1.1, U4.8, U4.12
RX6_S2N: R6F2.2, R6G2.1, U4.13
RX6_S2O: R6F2.1, R6O.1, U4.14
RX7_ADC: C7O.1, JA.10, R7O.2
RX7_G: C7I.2, R7B.1, U5.3
RX7_G1: C7G1.1, R7G1.2
RX7_G2: C7G2.1, R7G2.2
RX7_IN: C7I.1, K7.1
RX7_S1N: R7F1.2, R7G1.1, U5.2
RX7_S1O: R7F1.1, U5.1, U5.5
RX7_S2N: R7F2.2, R7G2.1, U5.6
RX7_S2O: R7F2.1, R7O.1, U5.7
RX8_ADC: C8O.1, JA.9, R8O.2
RX8_G: C8I.2, R8B.1, U5.10
RX8_G1: C8G1.1, R8G1.2
RX8_G2: C8G2.1, R8G2.2
RX8_IN: C8I.1, K8.1
RX8_S1N: R8F1.2, R8G1.1, U5.9
RX8_S1O: R8F1.1, U5.8, U5.12
RX8_S2N: R8F2.2, R8G2.1, U5.13
RX8_S2O: R8F2.1, R8O.1, U5.14
TX1_DRV: RT1.2, T1.1
TX1_IN: JB.14, U1.1
TX1_MID: U1.2, U1.3
TX1_OUT: RT1.1, U1.4
TX2_DRV: RT2.2, T2.1
TX2_IN: JB.15, U1.13
TX2_MID: U1.11, U1.12
TX2_OUT: RT2.1, U1.10
TX3_DRV: RT3.2, T3.1
TX3_IN: JB.16, U1.5
TX3_MID: U1.6, U1.9
TX3_OUT: RT3.1, U1.8
VREF: CB2.1, CV1.1, R1B.2, R2B.2, R3B.2, R4B.2, R5B.2, R6B.2, R7B.2, R8B.2, U6.1, U6.2, U6.5, U6.6, U6.7, U6.8, U6.9, U6.10, U6.12, U6.13, U6.14

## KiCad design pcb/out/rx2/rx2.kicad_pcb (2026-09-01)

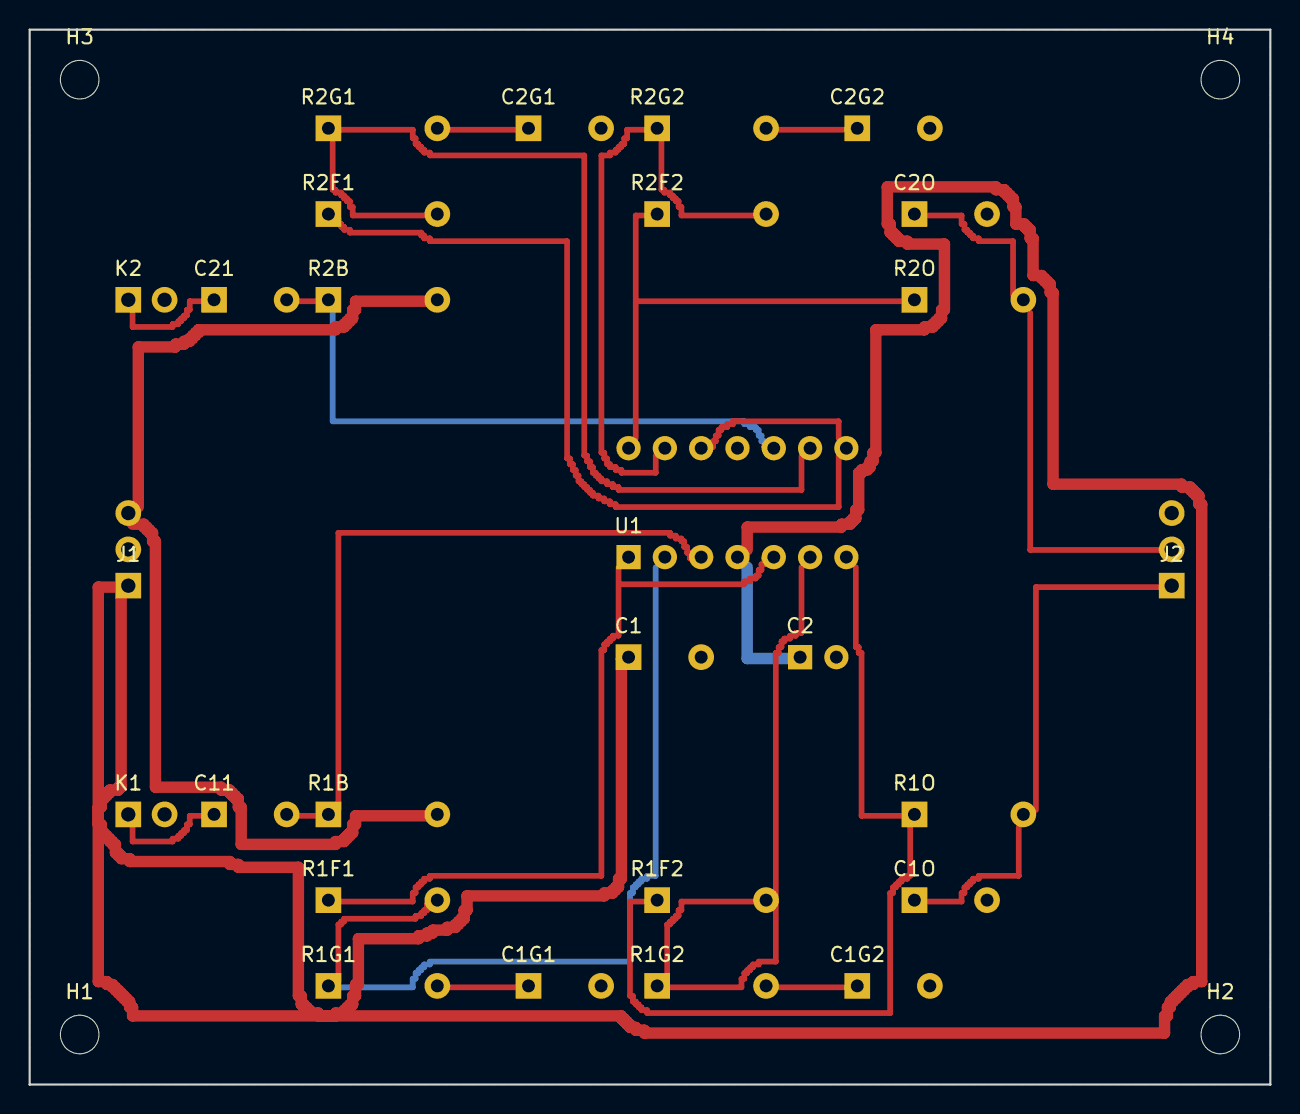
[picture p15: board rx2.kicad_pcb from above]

Board: 2 copper layers, 86.8 x 73.8 mm, 31 parts (0 on the bottom side), 21 nets.

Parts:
C1, C1G1, C1G2, C2G1, C2G2: 100nF; C_DISC
C1O, C2O: 1nF; C_DISC
C2: 10uF; C_ELEC
C11, C21: 10nF; C_DISC
H1, H2, H3, H4: M2.5; MountingHole
J1: PWR+VREF; HDR3
J2: ADC OUT; HDR3
K1, K2: TCT40-16R; HDR2
R1B, R2B: 1M; R_AXIAL
R1F1, R1F2, R2F1, R2F2: 33k; R_AXIAL
R1G1, R1G2, R1O, R2G1, R2G2, R2O: 1k; R_AXIAL
U1: MCP6004; DIP14

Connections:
3V3: C1.1, C2.1, J1.1, U1.4
CH1_G: C11.2, R1B.1, U1.3
CH1_G1: C1G1.1, R1G1.2
CH1_G2: C1G2.1, R1G2.2
CH1_IN: C11.1, K1.1
CH1_OUT: C1O.1, J2.1, R1O.2
CH1_S1N: R1F1.2, R1G1.1, U1.2
CH1_S1O: R1F1.1, U1.1, U1.5
CH1_S2N: R1F2.2, R1G2.1, U1.6
CH1_S2O: R1F2.1, R1O.1, U1.7
CH2_G: C21.2, R2B.1, U1.10
CH2_G1: C2G1.1, R2G1.2
CH2_G2: C2G2.1, R2G2.2
CH2_IN: C21.1, K2.1
CH2_OUT: C2O.1, J2.2, R2O.2
CH2_S1N: R2F1.2, R2G1.1, U1.9
CH2_S1O: R2F1.1, U1.8, U1.12
CH2_S2N: R2F2.2, R2G2.1, U1.13
CH2_S2O: R2F2.1, R2O.1, U1.14
GND: C1.2, C1G1.2, C1G2.2, C1O.2, C2.2, C2G1.2, C2G2.2, C2O.2, J1.2, J2.3, K1.2, K2.2, U1.11
VREF: J1.3, R1B.2, R2B.2

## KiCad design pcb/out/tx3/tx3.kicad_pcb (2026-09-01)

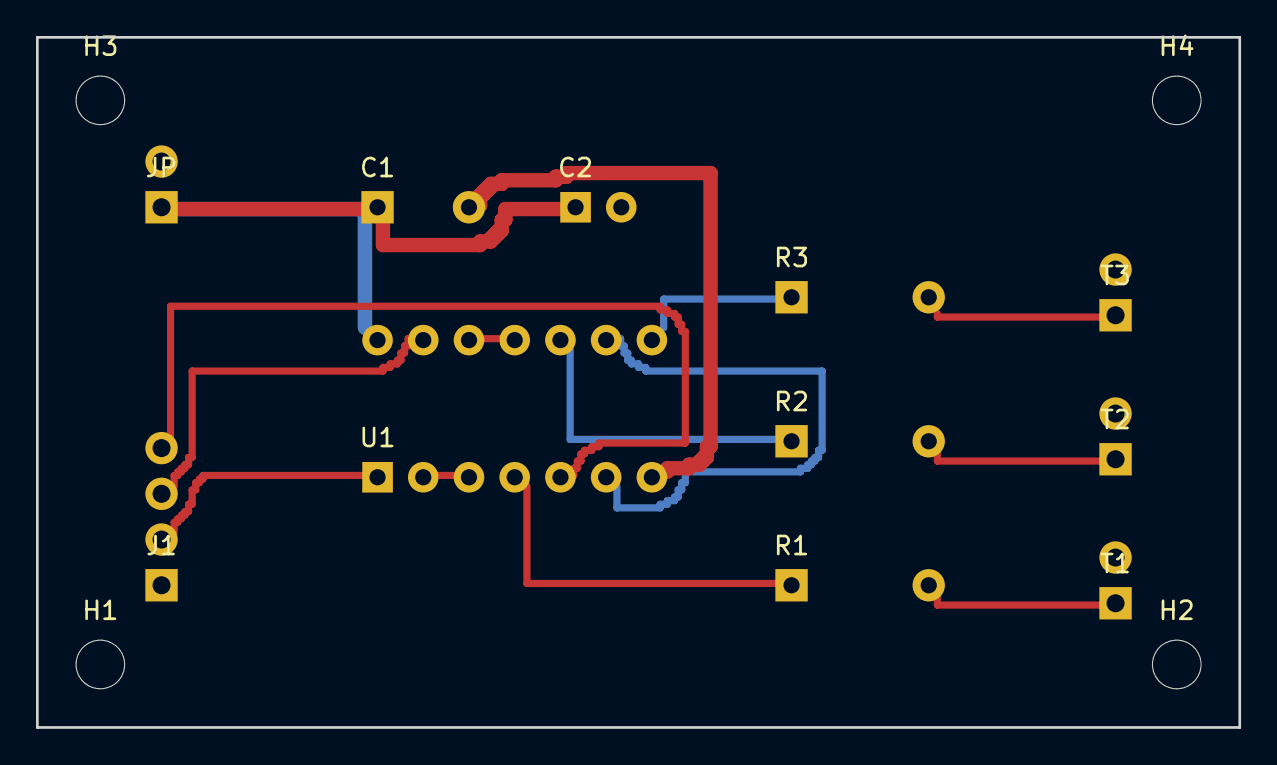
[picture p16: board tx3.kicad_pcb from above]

Board: 2 copper layers, 66.8 x 38.3 mm, 15 parts (0 on the bottom side), 14 nets.

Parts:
C1: 100nF; C_DISC
C2: 10uF; C_ELEC
H1, H2, H3, H4: M2.5; MountingHole
J1: ESP32; HDR4
JP: PWR; HDR2
R1, R2, R3: 100R; R_AXIAL
T1, T2, T3: TCT40-16T; HDR2
U1: 74HCT04; DIP14

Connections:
+5V: C1.1, C2.1, JP.1, U1.14
GND: C1.2, C2.2, J1.1, JP.2, T1.2, T2.2, T3.2, U1.7
TX1_DRV: R1.2, T1.1
TX1_IN: J1.2, U1.1
TX1_MID: U1.2, U1.3
TX1_OUT: R1.1, U1.4
TX2_DRV: R2.2, T2.1
TX2_IN: J1.3, U1.13
TX2_MID: U1.11, U1.12
TX2_OUT: R2.1, U1.10
TX3_DRV: R3.2, T3.1
TX3_IN: J1.4, U1.5
TX3_MID: U1.6, U1.9
TX3_OUT: R3.1, U1.8

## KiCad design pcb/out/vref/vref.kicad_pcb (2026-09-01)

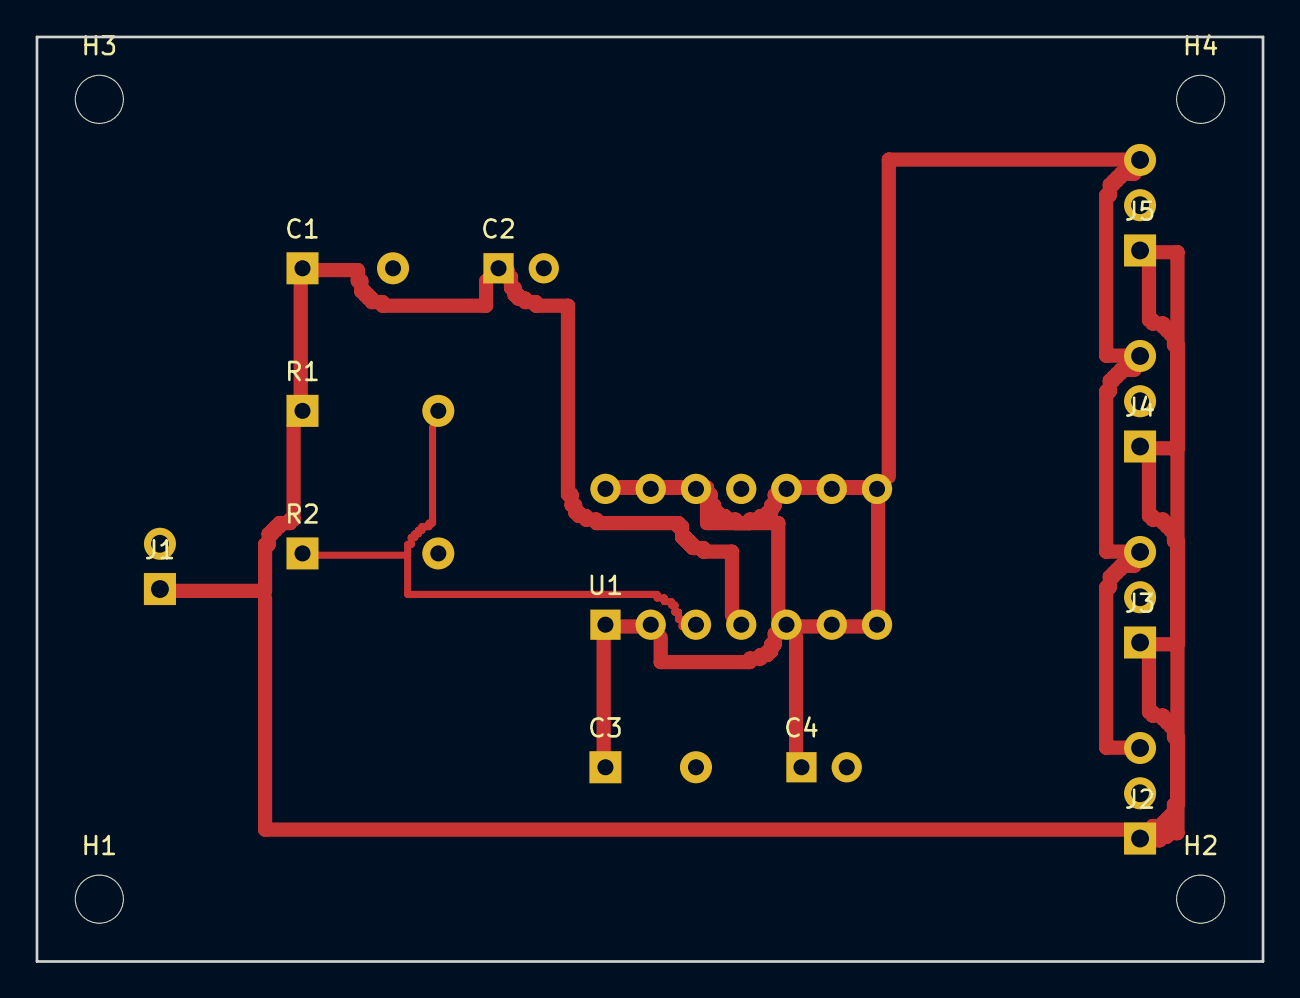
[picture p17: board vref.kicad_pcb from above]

Board: 2 copper layers, 68.8 x 51.9 mm, 16 parts (0 on the bottom side), 4 nets.

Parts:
C1, C3: 100nF; C_DISC
C2, C4: 10uF; C_ELEC
H1, H2, H3, H4: M2.5; MountingHole
J1: 3V3 IN; HDR2
J2: OUT A; HDR3
J3: OUT B; HDR3
J4: OUT C; HDR3
J5: OUT D; HDR3
R1, R2: 10k; R_AXIAL
U1: MCP6004; DIP14

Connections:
3V3: C1.1, C2.1, J1.1, J2.1, J3.1, J4.1, J5.1, R1.1, U1.4
GND: C1.2, C2.2, C3.2, C4.2, J1.2, J2.2, J3.2, J4.2, J5.2, R2.2, U1.11
MID: R1.2, R2.1, U1.3
VREF: C3.1, C4.1, J2.3, J3.3, J4.3, J5.3, U1.1, U1.2, U1.5, U1.6, U1.7, U1.8, U1.9, U1.10, U1.12, U1.13, U1.14

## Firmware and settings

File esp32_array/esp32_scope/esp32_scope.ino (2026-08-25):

/*
 * esp32_scope.ino - pulse-echo scope for the 40 kHz ultrasonic array (Stage 1).
 *
 * WHAT THIS IS FOR
 * esp32_selftest proved the capture chain works. This sketch adds the other
 * half: it fires a short 40 kHz burst out of the TX driver and captures the
 * receive chain across the same window, so one serial command produces one
 * complete pulse-echo record. That record is the raw material for everything
 * later - envelope, cross-correlation, TDOA.
 *
 * WIRING
 *     GPIO18 ---> 74HCT04 pin 1        (see hardware/diagrams/tx_1_driver_version_a.svg)
 *     GPIO34 <--- RX front-end output  (see hardware/diagrams/rx_*.svg)
 *     TX board GND ---> ESP32 GND pin directly, NOT through the RX ground rail.
 *
 * That last line is not a style preference. The burst pulls ~46 mA in steps;
 * if that current shares a ground path with an input being amplified 106x,
 * the voltage drop along the rail lands on top of the echo.
 *
 * WHERE t = 0 REALLY IS
 * The firmware waits `p` microseconds after arming the ADC before it fires,
 * so the burst *should* land at sample p*fs/1e6, and that index is reported
 * as `burst=` in the frame header. Treat it as a hint, not a measurement:
 * the DMA is free-running, so the arm-to-burst gap is only accurate to a
 * fraction of a conv frame.
 *
 * The honest time reference is in the data itself. Every shot contains a
 * large direct pulse - the transmitter heard through the air and the bench
 * over the few centimetres between the transducers - and that pulse is the
 * true t = 0. Range comes from (t_echo - t_direct), which cancels every
 * software latency in this file. Software sync only has to be good enough
 * to put the direct pulse inside the record; the data does the rest.
 *
 * TWO CHANNELS AT ONCE (Stage 2)
 * `c 34,35` puts the ADC on both receivers. They are NOT sampled at the same
 * instant - one ADC walks a pattern - but the gap is one conversion slot,
 * 1/rate, which is fixed and exactly known. A known constant subtracts out;
 * only jitter would be fatal. That is the whole reason a multiplexed ADC can
 * do TDOA at all, and it is why `rate` here means the TOTAL conversion rate:
 * with two channels each one gets rate/2.
 *
 * The demultiplexer keys off the channel tag the ADC stamps into every
 * sample, and refuses to store anything until it has seen the first channel
 * of the pattern. Assuming strict alternation instead would swap the two
 * receivers on any frame the DMA happened to hand over mid-pattern - which
 * inverts the sign of every angle, intermittently, which is far worse than
 * failing outright.
 *
 * IT ALSO HAS TO IGNORE REPEATS. Measured on this chip: the SAR tops out
 * near 250 kHz of real conversions, and asking for more does not fail - the
 * DMA just writes the same conversion out several times. At 1 MHz you get
 * every reading four times over, bit for bit. Those repeats are not extra
 * samples and must not be counted as such, so a new conversion is recognised
 * by the channel tag CHANGING, not by a word arriving.
 *
 * Note this costs nothing in accuracy when it does happen: repeating a value
 * is a zero-order hold, which quantises the waveform in time but does not
 * shift it. What it costs is time resolution, so `rate` is worth choosing to
 * land where no repeating occurs - `i` reports the conversion period the
 * capture actually achieved, which is the number to trust.
 *
 * WHY THERE IS NO AVERAGING HERE
 * Averaging N shots would buy sqrt(N) of SNR, but only if the shots line up
 * to well under one carrier period (25 us at 40 kHz). The trigger jitter in
 * this design is microseconds, so summing raw shots on the ESP32 would smear
 * the carrier away instead of reinforcing it. Averaging belongs in Python,
 * after each shot has been aligned on its own direct pulse.
 *
 * REQUIRES: Arduino-ESP32 core 3.x. Board "ESP32 Dev Module". Original ESP32
 * only - S2/S3/C3 have a much slower continuous ADC and a different channel map.
 *
 * SERIAL COMMANDS (2000000 baud):
 *   ?           help
 *   i           info: chip, config, window length, range covered
 *   r           fire a burst and capture one record   <- the normal shot
 *   q           capture without firing (background / noise reference)
 *   f <hz>      ADC sample rate            (default 500000)
 *   n <count>   samples per capture        (default 24000)
 *   s <hz>      burst carrier frequency    (default 40000)
 *   b <cycles>  burst length in cycles     (default 8)
 *   p <us>      quiet time before the burst(default 200)
 *   c <pin>[,<pin>]  probe pin(s): 34 35 32 33 36 39 - two pins = TDOA mode
 *   d <hz>      test tone on GPIO26, 0 = off (for RX gain checks)
 *   w <0|1>     continuous carrier on GPIO25, for bringing up the TX board
 */

#include <Arduino.h>
#include "esp_adc/adc_continuous.h"
#include "esp_timer.h"
#include "driver/ledc.h"

#if __has_include("driver/dac_cosine.h")
#include "driver/dac_cosine.h"
#define HAVE_DAC_COSINE 1
#endif

// ---------------------------------------------------------------- config --

/* TX drive lives on GPIO18, on the opposite header from the ADC inputs.
 * GPIO25/26 would work electrically, but they sit four pins away from
 * GPIO34/35 on the same header, which puts a 3.3 V 40 kHz square wave with
 * nanosecond edges alongside a high-impedance analog node. Moving it to the
 * far header puts the 25 mm width of the DevKit between them, and lets the
 * TX board sit on its own breadboard with only the 5 V feed crossing over.
 *
 * TEST_GPIO cannot move the same way: it is a DAC output, and GPIO25/26 are
 * the only two DACs on this chip. That is fine - the test tone is injected
 * into the RX front-end, so it belongs on the RX side anyway. */
#define TX_GPIO 18    // -> 74HCT04 input
#define TEST_GPIO 26  // DAC2, independent tone for measuring RX gain

/* 24000 samples at 500 kS/s is a 48 ms window = 16.5 m of travel = 8.2 m of
 * range, and costs 48 KB of the ESP32's 320 KB of DRAM. 500 kS/s is also
 * 12.5 samples per 40 kHz cycle - ample for cross-correlation with
 * sub-sample interpolation, and close to the 333 kS/s per channel that six
 * channels will get in Stage 3, so what is learned here still applies. */
#define MAX_SAMPLES 32000   /* total slots, shared across channels */
#define MAX_CH 8

static uint32_t g_sample_hz = 500000;
static uint32_t g_num_samples = MAX_SAMPLES;   /* per channel */
static uint32_t g_burst_hz = 40000;
/* Burst length trades blind zone against range.
 *
 * Measured on this hardware with a reflector at 20 cm: 8 cycles put the echo
 * 23.9 cm away, 6 cycles 22.5 cm, 4 cycles 19.5 cm. The echo did not move -
 * the transmitter's ring-down did. A TCT40 is a high-Q resonator, so a longer
 * burst leaves a longer tail, and anything arriving under that tail is
 * reported late or not at all. 4 cycles clears the tail by ~15 cm; 8 cycles
 * buys ~8 dB more SNR for targets that are far enough away to care. */
static uint32_t g_burst_cycles = 8;
static uint32_t g_pre_us = 200;
static bool g_cw = false;  // continuous carrier, for TX bring-up only

static adc_channel_t g_ch[MAX_CH] = {ADC_CHANNEL_6};  // GPIO34
static int g_pin[MAX_CH] = {34};
static uint32_t g_nch = 1;

static uint16_t g_samples[MAX_SAMPLES];
static adc_continuous_handle_t g_adc = NULL;
static bool g_adc_running = false;

#ifdef HAVE_DAC_COSINE
static dac_cosine_handle_t g_test = NULL;
#endif
static uint32_t g_test_hz = 0;

// ------------------------------------------------------------ transmitter --

static void tx_attach() {
  ledcDetach(TX_GPIO);
  // 8-bit resolution is plenty: the transducer is a high-Q resonator that
  // turns whatever edges it is given into a sine wave anyway.
  ledcAttach(TX_GPIO, g_burst_hz, 8);
  ledcWrite(TX_GPIO, 0);  // parked low, not floating
}

/* Fire g_burst_cycles cycles of the carrier.
 *
 * Deliberately not wrapped in a critical section. Disabling interrupts here
 * would tighten the burst *length* by a few microseconds, which changes only
 * how much energy is radiated - while the burst *start*, the thing that would
 * matter, is recovered from the direct pulse in the data regardless. Paying
 * for precision that gets thrown away is not a good trade. */
static void tx_burst() {
  if (g_burst_cycles == 0) return;
  const int64_t len_us = (int64_t)g_burst_cycles * 1000000 / g_burst_hz;
  ledcWrite(TX_GPIO, 128);  // 50% duty
  const int64_t stop_at = esp_timer_get_time() + len_us;
  while (esp_timer_get_time() < stop_at) { /* busy-wait; len_us is ~200 us */ }
  ledcWrite(TX_GPIO, 0);
}

static void test_tone(uint32_t hz) {
#ifdef HAVE_DAC_COSINE
  if (g_test) {
    dac_cosine_stop(g_test);
    dac_cosine_del_channel(g_test);
    g_test = NULL;
  }
  g_test_hz = 0;
  if (hz == 0) {
    Serial.println("# test tone: off");
    return;
  }
  dac_cosine_config_t cfg = {};
  cfg.chan_id = DAC_CHAN_1;  // GPIO26
  cfg.freq_hz = hz;
  cfg.clk_src = DAC_COSINE_CLK_SRC_DEFAULT;
  cfg.offset = 0;
  cfg.phase = DAC_COSINE_PHASE_0;
  cfg.atten = DAC_COSINE_ATTEN_DB_6;  // ~0.8 Vpp -> 0.8 mVpp after a 100k/100R divider
  cfg.flags.force_set_freq = true;
  if (dac_cosine_new_channel(&cfg, &g_test) == ESP_OK &&
      dac_cosine_start(g_test) == ESP_OK) {
    g_test_hz = hz;
    Serial.printf("# test tone: %u Hz on GPIO%d (~0.8 Vpp)\n", (unsigned)hz, TEST_GPIO);
  } else {
    Serial.println("!! test tone failed to start");
    g_test = NULL;
  }
#else
  Serial.println("!! dac_cosine not available in this core");
#endif
}

static int pin_to_ch(int pin) {
  switch (pin) {
    case 36: return 0;
    case 39: return 3;
    case 32: return 4;
    case 33: return 5;
    case 34: return 6;
    case 35: return 7;
    default: return -1;
  }
}

/* One buffer is shared by every channel, so the per-channel depth is the
 * total divided by the channel count. */
static uint32_t max_per_channel() { return MAX_SAMPLES / g_nch; }

// ------------------------------------------------------------------- adc --

static void adc_teardown() {
  if (g_adc) {
    if (g_adc_running) {  // stopping a stopped driver logs an error that is not one
      adc_continuous_stop(g_adc);
      g_adc_running = false;
    }
    adc_continuous_deinit(g_adc);
    g_adc = NULL;
  }
}

static bool adc_setup() {
  adc_teardown();

  adc_continuous_handle_cfg_t hcfg = {};
  /* conv_frame_size is 256 bytes = 128 samples rather than the 1024 used by
   * the self-test. The DMA hands over data one frame at a time, so the frame
   * size is also the granularity of "how stale is the data I just drained" -
   * which is exactly the arm-to-burst uncertainty. Smaller frame, tighter
   * sync. 8192 bytes of store buffer still holds 8 ms at 500 kS/s, far more
   * than the burst needs. */
  hcfg.max_store_buf_size = 8192;
  hcfg.conv_frame_size = 256;
  esp_err_t err = adc_continuous_new_handle(&hcfg, &g_adc);
  if (err != ESP_OK) {
    Serial.printf("!! adc_continuous_new_handle failed: %s\n", esp_err_to_name(err));
    return false;
  }

  adc_digi_pattern_config_t pattern[MAX_CH] = {};
  for (uint32_t i = 0; i < g_nch; i++) {
    pattern[i].atten = ADC_ATTEN_DB_12;  // ~0-3.1 V
    pattern[i].channel = g_ch[i] & 0x7;
    pattern[i].unit = ADC_UNIT_1;
    pattern[i].bit_width = ADC_BITWIDTH_12;
  }

  adc_continuous_config_t ccfg = {};
  ccfg.pattern_num = g_nch;
  ccfg.adc_pattern = pattern;
  ccfg.sample_freq_hz = g_sample_hz;
  ccfg.conv_mode = ADC_CONV_SINGLE_UNIT_1;
  ccfg.format = ADC_DIGI_OUTPUT_FORMAT_TYPE1;  // correct for the original ESP32

  err = adc_continuous_config(g_adc, &ccfg);
  if (err != ESP_OK) {
    Serial.printf("!! adc_continuous_config failed at %u Hz: %s\n",
                  (unsigned)g_sample_hz, esp_err_to_name(err));
    adc_teardown();
    return false;
  }
  return true;
}

/* Arm the ADC, wait g_pre_us, optionally fire, then collect g_num_samples.
 * Returns the number of samples collected. */
static uint32_t shoot(bool fire, uint32_t &elapsed_us, uint32_t &burst_index,
                      uint32_t &resyncs) {
  uint8_t rbuf[256];
  uint32_t got = 0;
  uint32_t n = 0;      // complete pattern cycles stored = samples per channel
  uint32_t k = 0;      // position within the pattern
  int prev_ch = -1;    // last channel tag seen, for spotting repeats
  bool locked = false;

  elapsed_us = 0;
  burst_index = 0;
  resyncs = 0;

  if (adc_continuous_start(g_adc) != ESP_OK) {
    Serial.println("!! adc_continuous_start failed");
    return 0;
  }
  g_adc_running = true;

  /* Throw away everything the DMA has already queued. Whatever is in there
   * was converted while the driver was spinning up, and it is also the only
   * thing standing between "now" and the first sample we keep. */
  while (adc_continuous_read(g_adc, rbuf, sizeof(rbuf), &got, 0) == ESP_OK && got > 0) {
  }

  const int64_t t_armed = esp_timer_get_time();
  burst_index = (uint32_t)((uint64_t)g_pre_us * g_sample_hz / 1000000ULL);

  while (esp_timer_get_time() - t_armed < (int64_t)g_pre_us) { /* quiet run-in */ }
  if (fire) tx_burst();

  const int64_t give_up = t_armed + 3000000;  // 3 s ceiling
  while (n < g_num_samples && esp_timer_get_time() < give_up) {
    esp_err_t err = adc_continuous_read(g_adc, rbuf, sizeof(rbuf), &got, 200);
    if (err != ESP_OK || got == 0) continue;
    for (uint32_t i = 0; i + SOC_ADC_DIGI_RESULT_BYTES <= got && n < g_num_samples;
         i += SOC_ADC_DIGI_RESULT_BYTES) {
      adc_digi_output_data_t *p = (adc_digi_output_data_t *)&rbuf[i];
      const uint32_t ch = p->type1.channel;
      /* A repeated tag means the DMA wrote the same conversion again. Only a
       * change of channel marks a genuinely new one. Single-channel captures
       * cannot use this test - every tag is the same - so they keep every
       * word and accept the zero-order-hold staircase. */
      if (g_nch > 1) {
        if ((int)ch == prev_ch) continue;
        prev_ch = (int)ch;
      }
      /* Position alone is not trustworthy - the DMA can hand over a buffer
       * that starts anywhere inside the pattern. Lock on the pattern's first
       * channel, then check every sample against the slot it is filling. */
      if (!locked) {
        if (ch != (uint32_t)(g_ch[0] & 0x7)) continue;
        locked = true;
        k = 0;
      } else if (ch != (uint32_t)(g_ch[k] & 0x7)) {
        resyncs++;                        // a conversion went missing
        k = 0;
        if (ch != (uint32_t)(g_ch[0] & 0x7)) { locked = false; continue; }
      }
      g_samples[n * g_nch + k] = p->type1.data;
      if (++k == g_nch) { k = 0; n++; }
    }
  }

  const int64_t t_last = esp_timer_get_time();
  adc_continuous_stop(g_adc);
  g_adc_running = false;

  if (n > 1) elapsed_us = (uint32_t)(t_last - t_armed);
  return n;
}

static void send_frame(uint32_t n, uint32_t elapsed_us, uint32_t burst_index, bool fired) {
  String order;
  for (uint32_t i = 0; i < g_nch; i++) {
    if (i) order += ",";
    order += String((int)(g_ch[i] & 0x7));
  }
  /* n counts samples PER CHANNEL; the payload is n*ch interleaved samples.
   *
   * skew_us is the gap between neighbouring channels inside one cycle, and it
   * is MEASURED - elapsed time divided by the conversions that actually
   * happened - rather than derived from the requested rate, which the chip
   * does not always deliver. It is a known constant for the host to subtract,
   * not an error term. */
  Serial.printf("#FRAME rate=%u ch=%u n=%u us=%u order=%s burst=%u "
                "cycles=%u f0=%u fired=%d skew_us=%.3f\n",
                (unsigned)g_sample_hz, (unsigned)g_nch, (unsigned)n, (unsigned)elapsed_us,
                order.c_str(), (unsigned)(fired ? burst_index : 0),
                (unsigned)(fired ? g_burst_cycles : 0), (unsigned)g_burst_hz,
                fired ? 1 : 0,
                (n && g_nch > 1) ? (double)elapsed_us / ((double)n * g_nch) : 0.0);
  Serial.flush();

  Serial.write((const uint8_t *)"USC1", 4);

  uint16_t checksum = 0;
  const uint8_t *bytes = (const uint8_t *)g_samples;
  const uint32_t nbytes = n * g_nch * 2;
  for (uint32_t i = 0; i < nbytes; i += 512) {
    const uint32_t chunk = min((uint32_t)512, nbytes - i);
    Serial.write(bytes + i, chunk);
    for (uint32_t k = 0; k < chunk; k++) checksum += bytes[i + k];
  }
  Serial.write((const uint8_t *)&checksum, 2);
  Serial.flush();
}

static void one_shot(bool fire) {
  if (g_cw) {
    Serial.println("!! continuous carrier is on - send 'w 0' first");
    return;
  }
  if (!g_adc && !adc_setup()) return;

  uint32_t elapsed_us = 0, burst_index = 0, resyncs = 0;
  const uint32_t n = shoot(fire, elapsed_us, burst_index, resyncs);
  if (n == 0) {
    Serial.println("!! capture returned nothing");
    return;
  }
  if (n < g_num_samples) {
    Serial.printf("!! short capture: %u of %u samples\n", (unsigned)n,
                  (unsigned)g_num_samples);
  }
  if (g_nch > 1) {
    const double per_ch = n / (elapsed_us * 1e-6);
    Serial.printf("# achieved %.1f kHz per channel, conversion period %.2f us\n",
                  per_ch / 1000.0, 1e6 / (per_ch * g_nch));
  }
  if (resyncs) {
    /* Loud on purpose. A resync means the channel order slipped mid-frame,
     * so some cycles may pair samples that were never neighbours in time. */
    Serial.printf("!! %u pattern resync(s) - Delta-t from this frame is suspect\n",
                  (unsigned)resyncs);
  }
  send_frame(n, elapsed_us, burst_index, fire);
}

/* Print the ADC's own output words, undecoded. When a demultiplexer
 * disagrees with the hardware about what order the channels come in, the
 * only way to settle it is to look at the tags the hardware actually wrote. */
static void raw_dump(uint32_t want) {
  if (!g_adc && !adc_setup()) return;
  uint8_t rbuf[256];
  uint32_t got = 0;
  if (adc_continuous_start(g_adc) != ESP_OK) {
    Serial.println("!! adc_continuous_start failed");
    return;
  }
  g_adc_running = true;
  while (adc_continuous_read(g_adc, rbuf, sizeof(rbuf), &got, 0) == ESP_OK && got > 0) {
  }
  Serial.printf("# raw words, %u channel(s) in pattern, %u Hz total\n",
                (unsigned)g_nch, (unsigned)g_sample_hz);
  uint32_t shown = 0;
  while (shown < want) {
    if (adc_continuous_read(g_adc, rbuf, sizeof(rbuf), &got, 200) != ESP_OK || got == 0) break;
    for (uint32_t i = 0; i + SOC_ADC_DIGI_RESULT_BYTES <= got && shown < want;
         i += SOC_ADC_DIGI_RESULT_BYTES, shown++) {
      adc_digi_output_data_t *d = (adc_digi_output_data_t *)&rbuf[i];
      uint16_t w;
      memcpy(&w, &rbuf[i], 2);
      Serial.printf("%3u word=0x%04X ch=%2u data=%4u\n", (unsigned)shown, w,
                    (unsigned)d->type1.channel, (unsigned)d->type1.data);
    }
  }
  adc_continuous_stop(g_adc);
  g_adc_running = false;
}

// ------------------------------------------------------------------ info --

static void print_info() {
  const double fs = g_sample_hz;
  const double window_s = g_num_samples / (fs / g_nch);
  Serial.println("# --- esp32_scope ---");
  Serial.printf("# chip           : %s rev %d, %d core(s)\n", ESP.getChipModel(),
                ESP.getChipRevision(), ESP.getChipCores());
  Serial.printf("# arduino core   : %s\n", ESP.getSdkVersion());
  Serial.printf("# adc rate       : %u Hz (chip allows %d..%d)\n", (unsigned)g_sample_hz,
                SOC_ADC_SAMPLE_FREQ_THRES_LOW, SOC_ADC_SAMPLE_FREQ_THRES_HIGH);
  for (uint32_t i = 0; i < g_nch; i++) {
    Serial.printf("# probe pin %u    : GPIO%d (ADC1_CH%d)\n", (unsigned)i, g_pin[i],
                  (int)(g_ch[i] & 0x7));
  }
  if (g_nch > 1) {
    Serial.printf("# per channel    : %.0f Hz, skew %.3f us (known constant - subtract it)\n",
                  fs / g_nch, 1e6 / fs);
  }
  Serial.printf("# samples        : %u per channel, %u max\n", (unsigned)g_num_samples,
                (unsigned)max_per_channel());
  Serial.printf("# window         : %.2f ms = %.2f m of travel = %.2f m of range\n",
                window_s * 1000.0, window_s * 343.0, window_s * 343.0 / 2.0);
  Serial.printf("# burst          : %u cycles of %u Hz = %.0f us, on GPIO%d\n",
                (unsigned)g_burst_cycles, (unsigned)g_burst_hz,
                1e6 * g_burst_cycles / (double)g_burst_hz, TX_GPIO);
  Serial.printf("# range blind to : %.2f m (burst length alone)\n",
                343.0 * g_burst_cycles / (double)g_burst_hz / 2.0);
  Serial.printf("# pre-trigger    : %u us = sample %u\n", (unsigned)g_pre_us,
                (unsigned)((uint64_t)g_pre_us * g_sample_hz / g_nch / 1000000ULL));
  Serial.printf("# sample spacing : %.2f us = %.2f mm of range\n",
                1e6 / (fs / g_nch), 343.0 / (fs / g_nch) / 2.0 * 1000.0);
  if (g_test_hz) Serial.printf("# test tone      : %u Hz on GPIO%d\n",
                               (unsigned)g_test_hz, TEST_GPIO);
  if (g_cw) Serial.println("# continuous carrier: ON");
  Serial.printf("# free heap      : %u bytes\n", (unsigned)ESP.getFreeHeap());
}
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
void loop() {
  static String line;
  while (Serial.available()) {
    const char c = Serial.read();
    if (c == '\n' || c == '\r') {
      line.trim();
      if (line.length()) handle(line);
      line = "";
    } else if (line.length() < 32) {
      line += c;
    }
  }
}

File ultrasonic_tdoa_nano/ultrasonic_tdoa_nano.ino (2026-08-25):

/*
 * ultrasonic_tdoa_nano.ino
 *
 * Arduino Nano (ATmega328P) - 1 Transmitter + 2 Receivers (US-015 x2) pseudo-TDOA sketch.
 * See US015_TDOA_Codex_Spec.md in this repo for the full derivation of every
 * formula/threshold used below.
 *
 * Wiring:
 *   A2 (PC2) -> TRIG (shared by both US-015 boards)
 *   A0 (PC0) -> ECHO1 (board 1, has transmitter T + receiver R1)
 *   A1 (PC1) -> ECHO2 (board 2, receiver R2 only)
 *
 * Hard requirements from the spec (section 24):
 *   - No pulseIn(), no analogRead() on ECHO pins
 *   - Timer1 prescaler 8 (0.5 us/tick), Pin Change Interrupt on Port C
 *   - ISR: short, no Serial, no floating point
 *   - Timer1 overflow handled, volatile snapshot read atomically
 *   - timeout, calibration offset, physical plausibility gate, median filter,
 *     cycle-slip detector (25 us period), confidence score
 *   - human-readable AND CSV output, angle only printed when status == VALID
 */

#include <avr/interrupt.h>
#include <math.h>

// ---------------------------------------------------------------------------
// Pin definitions (named per spec; these are the digital pin numbers behind
// the "A0/A1/A2" silkscreen labels -- they are NOT read with analogRead()).
// ---------------------------------------------------------------------------
const uint8_t TRIG_PIN  = A2; // PC2
const uint8_t ECHO1_PIN = A0; // PC0 = PCINT8
const uint8_t ECHO2_PIN = A1; // PC1 = PCINT9

// Set to 1 if using the discrete-transistor analog front-end (gain + envelope
// detector + transistor threshold stage), whose output idles HIGH and pulls
// LOW while a strong-enough signal is present. Set to 0 for a normal
// HC-SR04/US-015-style module whose ECHO idles LOW and goes HIGH during the
// measurement window.
#define ECHO_ACTIVE_LOW 1

// ---------------------------------------------------------------------------
// Tunable parameters (section 16.3). Some are runtime-adjustable via serial
// commands and therefore not `const`.
// ---------------------------------------------------------------------------
float SOUND_SPEED_CM_PER_US = 0.0343f;     // updated by 't<celsius>' command
float RECEIVER_SPACING_CM   = 5.0f;        // updated by 'd<cm>' command
float CALIBRATION_OFFSET_US = 0.0f;        // updated by 'c' calibration routine

const uint32_t MEASUREMENT_TIMEOUT_US = 30000UL; // ~515 cm one-way ceiling
const float    MIN_VALID_US   = 100.0f;          // reject ringing / direct coupling
const float    MAX_DISTANCE_CM = 100.0f;         // sanity ceiling for pulse width
const size_t   FILTER_WINDOW  = 5;               // odd window, median filter
const float    CYCLE_PERIOD_US = 25.0f;          // 1 / 40 kHz
const float    CYCLE_SLIP_TOLERANCE_US = 3.0f;
const uint16_t MEASUREMENT_INTERVAL_MS = 100;    // ~10 Hz ping rate
const uint16_t CALIBRATION_SAMPLES = 200;

// ---------------------------------------------------------------------------
// Timer1: prescaler 8 => 16 MHz / 8 = 2 MHz => 0.5 us per tick.
// We extend the 16-bit hardware counter to 32 bits using the overflow ISR.
// ---------------------------------------------------------------------------
volatile uint32_t timer1OverflowCount = 0;

ISR(TIMER1_OVF_vect) {
  timer1OverflowCount++;
}

// Overflow-safe 32-bit tick read. Must be called with interrupts disabled
// by the caller if a perfectly consistent snapshot with other state is
// required; it disables/restores interrupts internally otherwise.
uint32_t timestampTicks() {
  uint8_t oldSREG = SREG;
  cli();
  uint16_t tcnt = TCNT1;
  uint32_t ovf = timer1OverflowCount;
  // If an overflow happened but the ISR hasn't run yet (flag pending) and
  // TCNT1 already wrapped to a small value, account for it manually.
  if ((TIFR1 & _BV(TOV1)) && tcnt < 0x8000) {
    ovf++;
  }
  SREG = oldSREG;
  return (ovf << 16) | (uint32_t)tcnt;
}

inline float ticksToUs(uint32_t ticks) {
  return (float)ticks * 0.5f;
}

// ---------------------------------------------------------------------------
// Per-channel edge state, updated only inside the PCINT1 ISR.
// ---------------------------------------------------------------------------
enum ChannelState : uint8_t { NOT_STARTED, RISE_SEEN, FALL_SEEN };

volatile ChannelState ch1State = NOT_STARTED;
volatile ChannelState ch2State = NOT_STARTED;
volatile uint32_t echo1RiseTicks = 0;
volatile uint32_t echo1FallTicks = 0;
volatile uint32_t echo2RiseTicks = 0;
volatile uint32_t echo2FallTicks = 0;
volatile uint8_t previousPortC = 0;

// PCINT1 fires on ANY change of PC0..PC7 that is unmasked (we mask PC0, PC1).
// Keep this ISR minimal: no Serial, no float, no long math beyond what is here.
ISR(PCINT1_vect) {
  uint8_t currentPortC = PINC;
  uint8_t changed = currentPortC ^ previousPortC;
  uint32_t nowTicks = timestampTicks();

  if (changed & _BV(PC0)) { // ECHO1 edge
#if ECHO_ACTIVE_LOW
    bool active1 = !(currentPortC & _BV(PC0));
#else
    bool active1 = (currentPortC & _BV(PC0));
#endif
    if (active1) {
      if (ch1State == NOT_STARTED) {
        echo1RiseTicks = nowTicks;
        ch1State = RISE_SEEN;
      }
    } else {
      if (ch1State == RISE_SEEN) {
        echo1FallTicks = nowTicks;
        ch1State = FALL_SEEN;
      }
    }
  }

  if (changed & _BV(PC1)) { // ECHO2 edge
#if ECHO_ACTIVE_LOW
    bool active2 = !(currentPortC & _BV(PC1));
#else
    bool active2 = (currentPortC & _BV(PC1));
#endif
    if (active2) {
      if (ch2State == NOT_STARTED) {
        echo2RiseTicks = nowTicks;
        ch2State = RISE_SEEN;
      }
    } else {
      if (ch2State == RISE_SEEN) {
        echo2FallTicks = nowTicks;
        ch2State = FALL_SEEN;
      }
    }
  }

  previousPortC = currentPortC;
}

// ---------------------------------------------------------------------------
// Measurement state machine (section 16.2)
// ---------------------------------------------------------------------------
enum MeasureState : uint8_t { IDLE, WAITING, COMPLETE, TIMEOUT_STATE };

// History buffers (main-loop side only, no ISR access).
float deltaHistory[FILTER_WINDOW];
size_t deltaHistoryCount = 0;
size_t deltaHistoryIndex = 0;
float previousFilteredDeltaUs = 0.0f;
bool havePreviousFiltered = false;

bool outputCsv = true; // default: CSV, easy to parse for the 2D simulator

// ---------------------------------------------------------------------------
// Small helpers
// ---------------------------------------------------------------------------
float medianOf(float *values, size_t n) {
  // Insertion sort on a small stack copy; n is at most FILTER_WINDOW (<=7).
  float sorted[FILTER_WINDOW];
  for (size_t i = 0; i < n; i++) sorted[i] = values[i];
  for (size_t i = 1; i < n; i++) {
    float key = sorted[i];
    long j = i - 1;
    while (j >= 0 && sorted[j] > key) {
      sorted[j + 1] = sorted[j];
      j--;
    }
    sorted[j + 1] = key;
  }
  return sorted[n / 2];
}
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

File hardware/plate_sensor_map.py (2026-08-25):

"""Draw the top view showing which transducer goes in which hole.

Reads plate_coords.csv - the same file plate_model.py writes and the analysis
code reads - so the picture cannot drift away from the printed part.

Run:  python hardware/plate_sensor_map.py
"""

import csv
import math
import os

HERE = os.path.dirname(os.path.abspath(__file__))
OUT = os.path.join(HERE, "diagrams", "plate_5_sensor_map.svg")

BOSS_OD, BORE = 23.0, 19.5
LEG_W, HUB_R, ARM_R1 = 28.0, 34.0, 170.0
ARM_ANGLES = (90.0, 210.0, 330.0)
JOINT_R0, JOINT_R1 = 53.0, 68.0
SLOT_R, SLOT_L, SLOT_W = 110.0, 20.0, 3.0
MOUNT_D, CENTER_D = 4.5, 6.5

S = 2.0                       # px per mm
X0, X1, Y0, Y1 = -152, 152, -96, 178
MARGIN = 14

W = (X1 - X0) * S + 2 * MARGIN
H = (Y1 - Y0) * S + 2 * MARGIN


def px(x, y):
    return (MARGIN + (x - X0) * S, MARGIN + (Y1 - y) * S)


def polar(r, deg):
    a = math.radians(deg)
    return r * math.cos(a), r * math.sin(a)


o = []
o.append('<svg xmlns="http://www.w3.org/2000/svg" width="%.0f" height="%.0f" '
         'viewBox="0 0 %.0f %.0f" font-family="Tahoma, Segoe UI, sans-serif">'
         % (W, H, W, H))
o.append('<rect width="%.0f" height="%.0f" fill="#ffffff"/>' % (W, H))

# ---- plate body -----------------------------------------------------------
for a in ARM_ANGLES:
    x0, y0 = px(*polar(0, a))
    x1, y1 = px(*polar(ARM_R1 - LEG_W / 2, a))
    o.append('<line x1="%.1f" y1="%.1f" x2="%.1f" y2="%.1f" stroke="#ced4da" '
             'stroke-width="%.1f" stroke-linecap="round"/>'
             % (x0, y0, x1, y1, LEG_W * S + 3))
    o.append('<line x1="%.1f" y1="%.1f" x2="%.1f" y2="%.1f" stroke="#f1f3f5" '
             'stroke-width="%.1f" stroke-linecap="round"/>'
             % (x0, y0, x1, y1, LEG_W * S))
cx, cy = px(0, 0)
o.append('<circle cx="%.1f" cy="%.1f" r="%.1f" fill="#f1f3f5" stroke="#ced4da" '
         'stroke-width="1.5"/>' % (cx, cy, HUB_R * S))

# ---- joint seam and acoustic slot ----------------------------------------
o.append('<g stroke="#868e96" stroke-width="1.2" stroke-dasharray="5 4" fill="none">')
for a in ARM_ANGLES:
    dx, dy = polar(1, a + 90)
    for r in (JOINT_R0, JOINT_R1):
        x, y = polar(r, a)
        p1 = px(x + dx * LEG_W / 2, y + dy * LEG_W / 2)
        p2 = px(x - dx * LEG_W / 2, y - dy * LEG_W / 2)
        o.append('<line x1="%.1f" y1="%.1f" x2="%.1f" y2="%.1f"/>'
                 % (p1[0], p1[1], p2[0], p2[1]))
o.append('</g>')
for a in ARM_ANGLES:
    x, y = px(*polar(SLOT_R, a))
    o.append('<g transform="translate(%.1f,%.1f) rotate(%.1f)">'
             '<rect x="%.1f" y="%.1f" width="%.1f" height="%.1f" rx="%.1f" '
             'fill="#ffffff" stroke="#868e96"/></g>'
             % (x, y, -(a - 90), -SLOT_L * S / 2, -SLOT_W * S / 2,
                SLOT_L * S, SLOT_W * S, SLOT_W * S / 2))

o.append('<circle cx="%.1f" cy="%.1f" r="%.1f" fill="#ffffff" stroke="#868e96"/>'
         % (cx, cy, CENTER_D / 2 * S))

# ---- stage-1 pair: drawn before the bosses so it passes behind them --------
p1, p2 = px(17.32, 10.0), px(0.0, 140.0)
o.append('<line x1="%.1f" y1="%.1f" x2="%.1f" y2="%.1f" stroke="#f08c00" '
         'stroke-width="2.5" stroke-dasharray="7 5"/>' % (p1[0], p1[1], p2[0], p2[1]))

# ---- transducer positions -------------------------------------------------
STYLE = {"TX": ("#e03131", "#ffe3e3", "T"), "RX": ("#1971c2", "#d0ebff", "R")}
with open(os.path.join(HERE, "plate_coords.csv"), encoding="utf-8") as f:
    rows = list(csv.DictReader(f))
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

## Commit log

2026-08-25 ระบบอัลตราซาวด์ TDOA สำหรับรถ: ภาครับ 4 ช่อง + กฎทายทิศ + แบบพิมพ์ 3D
    ภาคเก็บข้อมูล (car/)
    - sync4.py อ่าน ADC 4 ช่องพร้อมกันในการยิงครั้งเดียว 66 kHz/ช่อง ระยะ 200 cm
    - record.py / check.py อัด dataset และตรวจสุขภาพระบบ พร้อมอินเทอร์เฟซแสดงผลสด
    - rules.py กฎทายทิศจากความแรงเอคโค่ ไม่ใช้ ML — ไขว้ 5 ช่วงได้ MAE 4.5-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
    [cam_cradle.step, cam_cradle.stl, plate_arm.step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]
2026-08-26 แก้ตารางขา MCP6004 ใน rx_frontend.md: ขา 12 กับ 14 สลับกัน
    ตารางระบุ ขา 12 = OUTD และ ขา 14 = +IND ซึ่งกลับกันกับดาต้าชีตและกับที่
    โค้ดวาดผังใช้จริง (rx_ch34_layout.py:17 และ perf_rx_layout.py:500 ถูกต้องอยู่แล้ว)
    ผัง SVG จึงไม่ได้รับผลกระทบ — ยืนยันด้วยการเรนเดอร์ใหม่แล้วเทียบ md5 เหมือนเดิมทุกไฟล์
    เพิ่มกฎ "ขา n คู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
2026-08-26 เพิ่ม car/replay.py — เล่นย้อนดูโมเดลทำงานทีละเฟรม ไม่ต้องต่อฮาร์ดแวร์
    ใช้ predict.Predictor กับ predict.render ตัวเดียวกับตอนรันสด ไม่ได้เขียนเส้นทางใหม่
    สิ่งที่เห็นตอนเล่นย้อนจึงผูกกับพฤติกรรมจริงของรถ
    rules.py เก็บสัมประสิทธิ์เพิ่มอีกชุด (holdout_slope/intercept) ที่ฟิตจากชุดเทรนล้วน
    replay.py เลื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
2026-08-26 เพิ่ม car/live_polar.py — แผนที่เรดาร์สด 13 ช่องจากโมเดล PolarScan
    ต่างจาก predict.py ที่ตอบทิศของเป้าตัวเดียว ตัวนี้ตอบทั้งแผนที่ คือระยะพื้นผิว
    ที่ใกล้สุดในทุกช่องมุม ซึ่งเป็นเป้าหมายปลายทางของโปรเจกต์ (mapping จากเสียง)
    --port COM5 ต่อฮาร์ดแวร์จริง (Sync4 + Astra ใช้โครงเดียวกับ predict.py)
    --replay walk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
2026-08-26 เพิ่ม explain_polar_model.md — อธิบายการเทรนโมเดล PolarScan ทีละขั้น
    ครอบคลุม: ขั้น DSP (กรองแบนด์ เปลือกคลื่น ยอดร่วม TDOA โปรไฟล์ระยะ)
    เฉลยจากกล้องผ่านโมเดลรูเข็ม สถาปัตยกรรม 593,628 พารามิเตอร์
    ฟังก์ชันสูญเสียแบบมาสก์ การแบ่งข้อมูลตามช่วงการเดิน และลูปเทรน
    ตัวเลขทุกตัวในเอกสา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
2026-08-28 เพิ่ม car/train_nn.py — โมเดล ML ล้วนจากคลื่นดิบ ไม่ผ่าน DSP ที่เขียนมือ
    ป้อน counts[4x871] เข้า CNN ตรง ๆ เน็ตเรียนกรองแบนด์/เปลือกคลื่น/เทียบช่องเอง
    เก็บ rules.py ไว้เหมือนเดิม ตัวนี้เป็นทางเลือกแยกต่างหาก
    รันไขว้ครบ 5 ช่วง (เฉลยเดียวกับ rules.py จึงเทียบตรง ๆ ได้):
    เดาค่าเฉลี่ย 9.79 องศ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
2026-08-31 เพิ่มโฟลเดอร์ pcb: ลายและข้อมูลสำหรับสั่งทำ PCB ทั้ง TX และ RX
    สามบอร์ด สร้างจากวงจรที่ต่อบนแผ่นไข่ปลาแล้วใช้งานได้จริง ไม่ได้ออกแบบวงจรใหม่
    tx3 66.8 x 38.3 mm ภาคส่ง 3 หัวจาก 74HCT04 ตัวเดียว สั่ง 1 แผ่น
    rx2 86.8 x 73.8 mm ภาครับ 2 ช่องจาก MCP6004 ตัวเดียว สั่ง 5 แผ่น
    vref 68.8 x 51.9 mm สร้าง 1.65V ครั้ง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
    [rx2-B_Cu.gbr, rx2-B_Mask.gbr, rx2-Edge_Cuts.gbr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]
2026-08-31 เพิ่มการส่งออกเป็นไฟล์ KiCad เพื่อให้เครื่องมืออื่นตรวจการเชื่อมต่อได้
    Gerber มีแต่รูปร่างทองแดง ไม่มีชื่อเน็ต ไม่มีขา ไม่มีชิ้นส่วน โปรแกรมอื่น
    เปิดดูได้ว่าลายหน้าตายังไง แต่ตรวจไม่ได้ว่า 'ขานี้ควรต่อกับขานั้น'
    ไฟล์ .kicad_pcb พาข้อมูลเน็ตไปด้วย EasyEDA Pro นำเข้าไ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
    [rx2.kicad_pcb, tx3.kicad_pcb, vref.kicad_pcb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]
2026-09-01 เตรียมเก็บชุดข้อมูลรอบสอง: อาเรย์สี่เหลี่ยม + เก็บท่าทางอย่างเป็นระบบ
    ย้าย RX ไปมุมทั้งสี่ของ plate_mini แล้ว (TL=GPIO35 TR=GPIO34 BL=GPIO32
    BR=GPIO33 TX=GPIO18 ตรงกลาง) เดิม RX เรียงเป็นเส้นนอนบนบอร์ดทดลอง
    ซึ่งแยกบน-ล่างไม่ได้เลยในทางฟิสิกส์ ตอนนี้ได้ทิศแนวตั้งมาด้วย
    rig2.py เก็บรูปทรงอาเรย์ไ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
    [main8-unrouted.kicad_pcb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]
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2026-09-01 pcb: ใช้เบอร์ชิ้นส่วนที่สั่งซื้อได้จริง และเขียนหมายเหตุการประกอบลง BOM
    BOM เดิมเขียนชื่อกว้าง ๆ เอาไปสั่งซื้อตรง ๆ ไม่ได้
    74HCT04 -> SN74HCT04N
    MCP6024 -> MCP6024-I/P (ตัวถัง DIP ต้องเป็นรหัส -I/P)
    Blue Pill -> 1x20 female hdr (ของที่บัดกรีคือเฮดเดอร์ ไม่ใช่บอร์ด STM32)
    เพิ่มหมายเหตุที่ต้องรู้ตอนซื้อและต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
    [main8-unrouted.kicad_pcb]
2026-09-01 pcb: เพิ่มผังวงจร ทั้งแบบภาพและแบบไฟล์ที่ EasyEDA นำเข้าได้
    เดิมมีแต่ไฟล์บอร์ด ซึ่งบอกว่าลายทองแดงวิ่งยังไง แต่อ่านแล้วไม่รู้ว่า
    วงจรทำงานยังไง และบอร์ดใน EasyEDA ก็ไม่มีผังให้ดูเลย เพราะนำเข้าจาก
    .kicad_pcb ซึ่งพาไปแต่ทองแดง ไม่ได้พาผังไปด้วย
    schematic.py วาดผังจาก netlist.py โ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
    [main8.kicad_sch]
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2026-09-01 pcb: แก้ผังที่นำเข้าแล้วแตกเป็นเส้น เพิ่มกรอบตัวถังบนบอร์ด และแพ็คเป็นซิป
    **สาเหตุที่ผังเปิดใน EasyEDA แล้วเป็นเส้นลอย ๆ ไม่เป็นสัญลักษณ์**
    ตัวต้านทานแนวนอน แนวตั้ง และแบบสลับขา ถูกยัดให้ใช้นิยามสัญลักษณ์ตัวเดียวกัน
    ตัวที่บันทึกทีหลังทับตัวก่อนหน้า ขาข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
    [main8-unrouted.kicad_pcb, main8.kicad_sch]
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2026-09-01 pcb: แก้ชื่อนิยามสัญลักษณ์ ที่ทำให้ผังเข้ามาแต่สาย ไม่มีชิ้นส่วนเลย
    นำเข้าแล้วเห็นแต่เส้นเขียวลอย ๆ ไม่มีตัวต้านทาน ไม่มีชิป ไม่มีอะไรสักตัว
    สาเหตุ: นิยามสัญลักษณ์ตั้งชื่อว่า "C_L" แต่ชิ้นส่วนอ้างถึง "ultrasonic:C_L"
    รูปแบบ KiCad กำหนดให้ชื่อในนิยามต้องมีชื่อคลังน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
    [main8.kicad_sch]
2026-09-01 pcb: แก้เส้นขาดในผัง · ขนาดตัวสัญลักษณ์และความยาวขาไม่ได้อิงรูปทรงจริง
    นำเข้าแล้วสัญลักษณ์มาครบ แต่ยังเห็นเป็นเส้นขาดเป็นท่อน ๆ
    สาเหตุที่หนึ่ง: เขียนขนาดตัวสัญลักษณ์เป็นค่าคงที่ทั่ว ๆ ไป และตั้งความยาวขา
    ไว้ 2.54 มม. เท่ากันหมด แต่ระยะระหว่างขาจริงกว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
    [main8.kicad_sch]
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2026-10-29 docs: แอนิเมชันเส้นทางคลื่นถึงแผนที่ (ค่าจริงทุกชั้น) + บันทึกความผิดพลาด mistake.md
